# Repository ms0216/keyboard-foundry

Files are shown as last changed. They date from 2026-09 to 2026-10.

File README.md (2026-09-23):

# keyboard foundry

自作キーボードを**現物になる前に機械で確かめながら**作るための作業場。
KLE の配列 1 本から、プレート（STL）・キーマトリクスの基板（KiCad・JLCPCB の規則入り）・
ZMK のシールドを作り、それらが食い違わないことを検査する。

HHKB 分割機（`../2608042258_HHKB_devided`）の開発で積み上げた道具・検査・知識・作法を
抜き出したもの。**核の生成器は、HHKB の発注済みの基板を再現できる**
（キーまわりの全 140 部品の位置・向き・面・フットプリントと、全 244 パッドの結線が一致。
tests/test_regression_hhkb.py）。

## 構成

```
foundry/          共通の核（Python）
  layout.py         KLE → キーの実寸座標。島（分割の左右）に分ける
  matrix.py         キー → (row, col)。基板とファームが同じものを読む
  project.py        機種（projects/<機種>/spec.py + layout.json）を読む
  mech.py           MX・スタビ・ホットスワップの規格値
  plate.py          プレート（build123d）
  pcb.py            未配線の基板（KiCad の Python）。スイッチ・ダイオード・スタビ・穴・JLC 規則
  zmk.py            ZMK シールドの雛形と行列表
  fab_fields.py     発注道具（Fabrication Toolkit）が読む LCSC・面・除外を板に焼く
  drc.py            DRC を指紋つきで記録（警告を隠さない）
  render_pcb.py     基板を絵にする（変わっていなければ描かない・動いた部品を拡大）
  verify.py         寸法・水密・干渉（結果の記憶つき）・図
  inspect_mesh.py / slice_check.py   印刷できるか（近似と、OrcaSlicer で実際にスライス）
  gate.py           発注の門（open-gaps の「せき止めているもの」）
  parts.py          HHKB で確かめた部品と選定理由
  pinmap.py         ピン名 → パッド番号（データシートで裏付け）
  mutate.py         定数を壊して検査が気づくかを測る
  jlcpcb_lookup.py  JLCPCB の API（区分・在庫・単価）
firmware/ zephyr/ ZMK モジュール（乾電池の残量計・打ち止めで停止・状態 LED）
config/ build.yaml ZMK の設定（機種を作ると足される）
lib/              フットプリント（kiswitch の MX ホットスワップ・スタビ、XIAO）
projects/<機種>/  spec.py・layout.json・docs/（台帳）・pcb/
tests/            検査。fixtures/ に HHKB の配列と発注済みの基板から抜き出した事実
tools/kb          機種ごとの操作の入口 / tools/new_project.py
docs/method/      失敗から出た規則
docs/knowledge/   部品・電源・基板・筐体・ZMK・アンテナ・測り方
docs/templates/   台帳の雛形
.claude/          基板が変わったら絵を出して「見ろ」と言う hook
```

## 始め方

```sh
python3.13 -m venv .venv && .venv/bin/pip install -r requirements-dev.txt
.venv/bin/pytest tests -q                              # 全部緑であること

.venv/bin/python3 tools/new_project.py mykb path/to/kle.json
tools/kb mykb plate        # build/mykb/plate_*.stl / .png
tools/kb mykb pcb          # projects/mykb/pcb/unrouted/*.kicad_pcb（KiCad 10 が要る）
```

次にやることは CLAUDE.md の「新しい機種を始める」。

## 要るもの

| 道具 | 何に | 場所の指定 |
|---|---|---|
| Python 3.13 + requirements-dev.txt | 核・検査 | — |
| KiCad 10（同梱の Python と kicad-cli） | 基板の生成・DRC・絵 | `KICAD_PYTHON` `KICAD_CLI` `KICAD_FOOTPRINTS` |
| pdftoppm（poppler） | 基板の絵 | PATH |
| OrcaSlicer | スライスの確認 | `ORCA_SLICER` |
| GitHub Actions | ZMK のビルド（手元に SDK は要らない） | — |

## まだ核に入っていないもの（HHKB を参照実装として読む）

| もの | 理由 | HHKB の場所 |
|---|---|---|
| ケース・組み立て検査（留め方・挿入経路・干渉） | 機種の意匠そのもの。2 台目で共通部分を抜き出す | tools/gen_case.py・gen_assembly.py・envelopes.py |
| MCU 子基板・電源回路・回路図と ERC | 構成が機種ごとに違う（pcb_extra.py で足す） | tools/gen_daughterboard.py・circuit.py・gen_sch.py |
| 配線の仕上げ（GND ビア・手配線の再現） | 配線の品質は手作業から来ていた | tools/finalize_pcb.py・gnd_fanout.py・export_matrix_routing.py |
| .blend での確認 | ケースと一緒に | tools/export_assembly.py・blend_assembly.py |

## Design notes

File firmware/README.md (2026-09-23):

# ZMK モジュール（foundry）

リポジトリ自身が ZMK のモジュール（`zephyr/module.yml`）。ZMK 公式の再利用ワークフローが
`zephyr/module.yml` を見つけると自動で読み込む（別リポジトリは要らない）。

| 機能 | Kconfig | 使い方 |
|---|---|---|
| 乾電池の残量計 | `FOUNDRY_BATTERY_ALKALINE`（DT にノードがあれば自動で y） | シールドに `compatible = "foundry,battery-alkaline"` のノードを置き `chosen { zmk,battery = &vbatt; }` |
| 打ち止めで自分から止まる | `FOUNDRY_LOW_BATTERY_SOFT_OFF`（上と `ZMK_PM_SOFT_OFF` で自動） | `.conf` に `CONFIG_ZMK_PM_SOFT_OFF=y` |
| XIAO の RGB LED で状態表示 | `FOUNDRY_STATUS_LED`（既定 n） | `.conf` に `=y`。led0/1/2 のエイリアスが要る |

## 出どころ

HHKB 分割機（`../2608042258_HHKB_devided`・GitHub ms0216/hhkb-split）で書いて
CI でビルドしたもの。**foundry に移すにあたって名前だけ変えた**（`hhkb,` → `foundry,`・
`HHKB_` → `FOUNDRY_`）。**名前を変えてからはまだビルドしていない**——最初の機種の
シールドを build.yaml に足した push で CI がビルドする。そこまでは「未ビルド」。

ソースの注記にある `open-gaps #N`・`docs/hardware/…`・`tools/circuit.py`・`Task C4/C5`
は HHKB のリポジトリの記録を指す（経緯を消さないために残した）。

## 実機での確認状況（HHKB 時点）

- 残量計・打ち止め停止: CI でビルド成功・**実機での使い切り試験は未実施**（HHKB Task C4/C5）
- 状態 LED: CI でビルド成功・実機で点灯確認は利用者側の残タスク

## 乾電池 2 本・XIAO nRF52840 の場合のシールドの書き方（HHKB の実物）

```dts
/ {
	vbatt: vbatt {
		compatible = "foundry,battery-alkaline";
		io-channels = <&adc 0>;          /* D0/AIN0。分圧はスイッチの後ろ・ショットキーの手前 */
		output-ohms = <1000000>;
		full-ohms = <2000000>;
		empty-millivolts = <2400>;       /* 回路が動かなくなる電圧（機種ごとに計算する） */
		full-millivolts = <3300>;        /* 新品アルカリの開路電圧 1.65V × 2 */
		/delete-property/ power-gpios;   /* 板の vbatt と合体する。P0.14 を毎回叩いて 10ms 待っていた */
	};
	chosen { zmk,battery = &vbatt; };
};
```

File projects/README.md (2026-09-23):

# 機種

1 機種 1 ディレクトリ。`.venv/bin/python3 tools/new_project.py <名前> <KLE の JSON>` で作る。
中身は spec.py・layout.json・docs/（台帳）・pcb/。手順は CLAUDE.md「新しい機種を始める」。

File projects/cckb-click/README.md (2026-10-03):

# cckb-click

CCKB（HHKB 英語配列・62 キー・19.05 ピッチ・XIAO nRF52840）を、**薄い表面実装のタクトスイッチ**と
**枠の下から入れる軸の無いキーキャップ**で作り直す機種。目標の厚さは約 8.1 mm（CCKB は 14.2）。
方式は Salicylic_acid3 さんの ClickBoard（出どころと条件は [LICENSE](LICENSE)。**非営利に限る**）。

`projects/cckb/`（発注できる状態の CCKB）には手を入れない。だめなら CCKB に戻れる。

## いまの段: 基板・枠・キャップ・ファームまで設計した（独立した監査の前）

**いまの状態は [docs/status.md](docs/status.md)。**残っているものは [docs/open-gaps.md](docs/open-gaps.md) の冒頭。

```
tools/kb cckb-click pcb                                            # 未配線の板
"$KICAD_PYTHON" projects/cckb-click/tools/route_click.py           # 配線（Freerouting 2.3.0 と java が要る）
tools/kb cckb-click fab-fields && tools/kb cckb-click drc          # LCSC の番号・DRC
.venv/bin/python3 projects/cckb-click/click_case.py                # 枠・キャップの STL・断面図・.blend を build/cckb-click/ に
.venv/bin/python3 projects/cckb-click/tools/slice_main.py          # 刷る 4 枚をスライスして G-code を検査
.venv/bin/python3 projects/cckb-click/click_stiffness.py           # たわみの見積もり
.venv/bin/python3 projects/cckb-click/tools/parts_check.py         # 部品の在庫・単価（JLC の API）
.venv/bin/pytest tests/test_cckb_click.py tests/test_cckb_click_pcb.py tests/test_cckb_click_board.py tests/test_cckb_click_case.py -q
tools/kb cckb-click gate                                           # 発注の門（いまは閉）
```

| 読むもの | 何 |
|---|---|
| [docs/status.md](docs/status.md) | **いまの状態**・CCKB との比較・利用者が決めること |
| [docs/open-gaps.md](docs/open-gaps.md) | 発注を止めているもの・実物が来るまで分からないこと |
| [docs/decisions/](docs/decisions/) | 決定の記録（スイッチ・構造・刷り方・試し刷りの結果・基板と枠） |
| [docs/shopping-list.md](docs/shopping-list.md)・[docs/order-steps.md](docs/order-steps.md) | 買う物・基板の頼み方 |
| [docs/printing-guide.md](docs/printing-guide.md)・[docs/assembly-guide.md](docs/assembly-guide.md) | 刷り方・組み立て |
| [docs/coupon-test.md](docs/coupon-test.md) | 試し刷りの手順と結果（2026-10-03 に利用者が刷った） |
| print/ | 精度優先の刷り方のプリセット |
| [docs/provisional-values.md](docs/provisional-values.md) | まだ実測していない値（`[暫定]`） |
| spec.py | 寸法と部品。値ごとに出どころ |

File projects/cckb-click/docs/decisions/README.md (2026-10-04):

# 決定の記録

1 件 1 ファイル `YYYY-MM-DD-slug.md`。雛形は docs/templates/decision.md。
覆す前に読む。前提が動いたら読み直す。

| 日付 | 何 |
|---|---|
| 2026-10-03 | [スイッチは Alps SKRAAWE010](2026-10-03-switch.md) |
| 2026-10-03 | [構造: 積み上げ・キャップと枠の形・刷る向き](2026-10-03-structure.md) |
| 2026-10-03 | [ライセンス: 形は CC BY-NC 4.0・名前は借りない](2026-10-03-license.md) |
| 2026-10-03 | [刷り方: 精度を最優先にした設定・ノズル・最小の一式](2026-10-03-print-recipe.md) |
| 2026-10-03 | [試し刷りの結果: 案 B・穴 17.05・つばのキャップ・0.4 ノズル](2026-10-03-coupon-result.md) |
| 2026-10-03 | [基板と枠: 足跡・回路・留め方・枠の分け方・角・電池・底・たわみ](2026-10-03-board-and-case.md) |
| 2026-10-04 | [1 回目の監査の直し: 電池の位置・載せないコンデンサのランド・予備のねじ穴・ねじ穴を 0.1 外へ・戻りの道](2026-10-04-audit-1.md) |
| 2026-10-04 | [電源スイッチを内側へ・電池の蓋（差し込み式）・蓋のねじ穴を取っておく](2026-10-04-switch-cover.md)（**位置と蓋は、下の knob-out-pilot で置き換えた**） |
| 2026-10-04 | [試し刷り v2: ねじの下穴・電源スイッチの位置・蓋の留め方を刷って決め直す（何を試すことにしたか。結果は次の行）](2026-10-04-coupon-v2.md) |
| 2026-10-04 | [電源スイッチを 0.75 外へ（JLC の「2.5 mm」は満たさない）・下穴 φ1.6・蓋は考え直し](2026-10-04-knob-out-pilot.md)（**蓋は、下の cover-latch で決めた**） |
| 2026-10-04 | [電池の蓋は、基板の下から M2×4 のねじ 2 本で留める（基板は変えない）](2026-10-04-cover-screw.md)（**道具が要るので退けた。下の cover-latch で置き換えた**） |
| 2026-10-04 | [電池の蓋は、道具なしで上から落とし込む形にする（電池が押す向きと、外れる向きを分ける。基板は変えない）](2026-10-04-cover-latch.md) |

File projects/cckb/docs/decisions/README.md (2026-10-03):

# 決定の記録

1 件 1 ファイル `YYYY-MM-DD-slug.md`。雛形は docs/templates/decision.md。
覆す前に読む。前提が動いたら読み直す。

- 2026-09-23-choc-stabilizer.md — Choc スタビ（2u）の寸法は、製造図と Keebio の開口の 2 出典が一致した値を使う
- 2026-09-24-interface.md — 基板・プレート・ケースの境界を凍結する（角・ネジ・電源スイッチ・スタビの逃げ・継ぎ目・高さ）。電源スイッチの節は power-switch.md で置き換えた
- 2026-09-24-case.md — ケース・キーキャップ・試し刷りの小片を立体にする（ケースの段）。電源スイッチの切り欠き・窪みは power-switch.md で無くなった
- 2026-09-24-audit-fixes.md — 独立監査（A〜F）と 2 回目の監査の所見を発注前に基板・ケース・手順に入れる（裁定 R1〜R7・S1〜S3）
- 2026-09-24-power-switch.md — 電源スイッチを秋月の SS-12D00G3（表・レバーが上・右のふたの穴から爪で）に置き換えた
- 2026-09-25-choc-v2.md — Choc V2（静音）に替える枝 `cckb-v2`。核・プレート・基板・ケース・キャップ・スタビの穴（§10）
- 2026-09-26-plateless.md — スイッチのプレートを使わずに組む（`spec.PLATE = False`）。戻せるように形・コード・検査は残し、両方の形を毎回検査する
- 2026-09-28-keycap-skin.md — キャップの天板を場所ごとの厚さに（ステムの上は膜）。**2026-10-03 利用者の決定: 既定の膜 1.0・上面 14.2**（2026-09-28 の膜 0.6・13.8 は、見積りで縁を押すとつばの上の輪 0.2 が割れるので既定にしない）。coupon_skin で 0.8 が割れなければ 0.8（14.0）に下げてよい

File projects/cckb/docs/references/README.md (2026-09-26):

# 出典として保存したもの

| ファイル | 出所 | ライセンス |
|---|---|---|
| `kiswitch-SW_Kailh_Choc_V2.kicad_mod` | [kiswitch/kiswitch](https://github.com/kiswitch/kiswitch) `Switch_Keyboard_Kailh.pretty`（2026-09-25 取得・無改変。lib の `SW_Kailh_Choc_V2_Common` の元） | MIT ／ CC-BY-SA 4.0 |
| `Salicylic-Choc_v2_PCBMountStab_2u.kicad_mod`・`Salicylic-Stab_Hole_Choc_v2_PCBMount_2u.kicad_mod` | [Salicylic-acid3/KiCAD_FootPrint](https://github.com/Salicylic-acid3/KiCAD_FootPrint) commit 9ade20b（2026-09-25 取得・無改変。V2 のスタビの基板の穴とプレートの開口の出典の 1 つ） | MIT（Copyright 2020 Salicylic_acid3） |
| `Kailh-PG1350-Stab-Cutout.kicad_mod` | [keebio/Keebio-Parts.pretty](https://github.com/keebio/Keebio-Parts.pretty)（2026-09-23 取得・無改変） | MIT（Copyright Keebio） |

Kailh 系の Choc スタビの製造図（AliExpress の商品画像）は、再配布してよいか分からないため
ここには置かない。URL と読んだ値は `../decisions/2026-09-23-choc-stabilizer.md` にある。

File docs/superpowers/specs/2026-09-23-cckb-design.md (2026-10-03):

# CCKB（Completely Compact KeyBoard）設計書

2026-09-23 利用者と合意。**HHKB 英語配列に準拠し、出張先や会議室へ持ち運ぶための、薄く軽い一体型キーボード。**
HHKB（Professional HYBRID Type-S・294×120×40mm・540g）は机に据えて使い、CCKB は鞄に入れて持ち出す。
使うのは出張・会議のときだけ（毎日一日中ではない）。印刷は Bambu Lab A1 mini（D12）。

完了とは**発注できる状態**（下の §9）。発注・印刷・購入は利用者が判断する。

---

## 1. 要求

### 守るもの（検査にする。設計の都合で崩すと検査が落ちる）

| 項目 | 値 | 照合する外の事実 |
|---|---|---|
| キー配置 | HHKB 英語配列の全キーの中心位置（スペースを除く） | `../2608042258_HHKB_devided/layout/hhkb_original.json`（QMK と Wikimedia の KLE 図で裏付け済み。60 キー） |
| キーピッチ | 19.05mm | HHKB 公称 |
| 行ずれ | HHKB と同一 | 同上 |
| 最下段の空き | 左 1.5u・右 2.5u（左右非対称。KLE で確認） | 同上 |
| スペースの範囲 | 4.0〜10.0u を 3 キーで隙間なく覆う | 同上 |

### 妥協したもの（受け入れた差）

| 差 | 理由 |
|---|---|
| スペース 6u → **2.25u＋1.5u＋2.25u**。既定は 3 つともスペース、真ん中は後でキーマップで変えられる | 低背の 6u キャップ・スタビがどの系列にも無い（調査 2026-09-23）。キーキャップは自分で刷る（D14）。真ん中と右の境（7.75u）は右の親指の位置（N の下）に当たるので、まず全部スペースで使って癖を見る |
| 段ごとのキー高さ・打鍵面の傾き 7.3° を再現しない | 低背スイッチでは作れない。ほぼ平ら |
| 静電容量無接点 → Kailh Choc V1 | 薄さ |
| 単3×2 → CR1632 | 薄さ・軽さ。LiPo は利用者が不採用（発火・劣化） |
| ゴム足なし | 利用者の決定（コンパクト性）。代わりに底面と面一の滑り止め |

### 目標（検査で数値を出して報告する。上限を決めるのは利用者）

- 外形 約 292×100mm・厚さ 約 12mm（キーキャップ上面まで）
- 重さ 約 300〜430g（スイッチ・キャップの単重が未公表。部品が届いたら量る）

---

## 2. 決定と根拠

| # | 決めたこと | 根拠（外の事実） | 退けた案 |
|---|---|---|---|
| D1 | **一体型** | 分割の親側をボタン電池で動かすと、内部抵抗が 25Ω を超えたところで起動に 2.6〜2.7V が要る領域（HHKB task-c4-c5 ② 実測）に入り、復帰が確率的になる。CR2450 では容量の約 4 割（Energizer データシートの IR 曲線）。片側不在で 3.7mA（HHKB task-c3 §5-4 実測） | 分割＋合体（+20〜25g・親側の電池 約 6 ヶ月）。**この結論は「親側が走査し続ける ZMK の仕様」と「起動電圧の実測」に乗っている。どちらかが変われば読み直す** |
| D2 | **Kailh Choc V2（PG1353・静音 PG1353S も同じ足跡）・19.05mm ピッチ**（`cckb-v2` の枝。main は V1 のまま） | 利用者が会議・出張用に静音を買う見込みで、静音は V2 にしか無い。十字の軸で自作キーキャップの嵌め合いが作りやすい。決め方と差は decisions/2026-09-25-choc-v2.md（全高 8.6・プレート 1.2・位置決めは丸 φ2.1・スタビは基板にねじ留め） | Choc V1（main の枝）・Gateron KS-33。V1（PG1350）は全高 8.0 で薄いが静音が無い |
| D3 | **スイッチを直接はんだ付け** | どのみち手はんだ（Choc ソケットは JLCPCB・LCSC とも在庫 0、2026-09-23 API。持ち込み実装は $85＋通関＋送料）。直接なら 約 1.2mm 薄く・約 9g 軽く、ソケットの −10℃・2V・100 回の制約が消え、プレート・スイッチ・基板が一体になる | ホットスワップ（差額は部品代 約 ¥1,300） |
| D4 | **CR1632 を 1 個**（**発注前の起動試験 §10a に合格することが条件**） | φ16.0×3.2mm・1.8g・130mAh（Energizer データシート）。ホルダごと右の角（47.6×19.05mm）に前後 1.5mm ずつ余って収まり、手前の縁に制約を作らない。入手性は CR2032 と同等（ダイソー公式の商品ページに CR1632。コンビニ各社も扱う。二次情報）。使える時間は保守側（0.20mA）で 約 480 時間＝週 7.5 時間なら 約 1.2 年 | CR2450（手前に 5.45mm はみ出し 奥行 +5.8mm）、CR2032（はみ出し 0.95mm 奥行 +1.3mm・設計の制約が 1 つ増える）、2 個並列（どちらの在庫品ホルダも角の横幅に 2 個並ばない：1632 用 28.7×2、2032 用 25.1×2 > 47.6）。**CR1632 の内部抵抗は新品で約 25Ω（CR2032 は約 10Ω）なので起動の余裕を測ってから確定する。不合格なら CR2032 に戻す** |
| D5 | **XIAO nRF52840 ＋ 74LVC595 ×2** | HHKB で実機確認済みの構成。技適 211-220207 | — |
| D6 | **XIAO（左）と電池（右）は最下段の空いた角の表側に置く。電池は角の上面をまるごと 1 枚にしたふたから替える** | 角にはキーが無いので高さを使える。電池ホルダ（高さ 5.4mm 級）を基板の裏に付けると、裏の空き（約 1.5mm）を超えて本体が厚くなる。ゴム足が無いので出っ張りを隠せない。ふたの縁はキーキャップとの隙間とケース外周の角に重ね、新しい線を増やさない | 裏ぶた（厚くなる）、角の上面の小窓（継ぎ目が増える） |
| D7 | 名前 **CCKB**（シールド名 `cckb`） | 利用者の命名（Completely Compact KeyBoard）。HHKB へのリスペクト。他社の商標は刷らない | tabi |
| D8 | **JLCPCB の実装は裏の片面だけ。表側（XIAO・電池ホルダ）は利用者が手はんだ**。**電源スイッチも手はんだ**（2026-09-24 の監査で裏の MK-12C02-G025 を手はんだにした〔つまみが外形から出るので JLC の規則に合わない・audit-fixes.md §R2〕。同日、表のスルーホールの **SS-12D00G3**〔秋月・LCSC に無い〕に置き換え・projects/cckb/docs/decisions/2026-09-24-power-switch.md） | 両面実装は工程が 2 回で追加の段取り費。ホルダは 2 端子・大きいパッドで手はんだが容易 | 両面実装 |
| D9 | **電源スイッチはふたを開けずに爪で操作**（当時は側面から。2026-09-24 に利用者の決定で、表の右の角の SS-12D00G3 を右のふたの穴から爪で動かす形に置き換え・decisions/2026-09-24-power-switch.md） | 出張先で毎回切る。ふたを開けずに爪で動かせること | 側面から（前の MK-12C02-G025） |
| D10 | **底面は面一の滑り止め**（浅いくぼみに薄いシートを貼り、四隅の 4 点で当てる） | ゴム足なしで、滑り・傷・がたつきを防ぐ。厚さ 0 | 何も付けない |
| D11 | ~~**プレートは PLA 1.2mm を自分で刷る**~~ → **2026-09-26（`cckb-v2`）: プレートを使わない**（`spec.PLATE = False`・戻せるように形とコードと検査は残す） | **2026-09-26 の決定**: プレートが要ったのは V1 のスタビがプレート留めだったから。V2 のねじ留めのスタビ（遊舎工房 A050001-01-1）は基板に留まり、販売者は「構造的にスイッチプレートレスでも使用できます」。外すと約 19g・刷る時間 2h28m 減り、スペースの欠け・別に刷る枠・O15 が消える。打鍵感・傾きは未評価（open-gaps P16）・ナットの回り止めが無くなる（P15）。決定記録 projects/cckb/docs/decisions/2026-09-26-plateless.md。**以下は 2026-09-23 の理由**: 利用者の決定（直しやすさ・軽さ）。比重が FR4 の約 2/3 で約 13g 軽い見込み（計算）。厚さは層（0.2mm×6）で決まり揃いやすい。HHKB 分割機も PLA のプレートでスタビの開口を実測で決めた（HHKB #30）。スイッチを基板にはんだ付けするので、プレートは 62 か所で基板に留まる | FR4（JLCPCB。厚さ ±10%） |
| D12 | **印刷は A1 mini。印刷する部品はすべて平面で 168.4mm 角以内** | 利用者の決定。A1 mini は 180×180mm、スライサーの自動配置（CLI・検査で使う）の実効が約 168.4mm 角（HHKB の実測 2026-08-23）。手で端に置けば 177.6mm まで刷れた（同 08-24）が、検査で確かめられる側に揃える | 手置き前提の 177.6mm |
| D13 | **基板（1 枚）を背骨にし、印刷部品は分割してそれぞれ基板に留める** | 本体は約 288mm で A1 mini に入らない。基板は JLCPCB で 1 枚で作れる。プレートはキーの境目（スイッチ・スタビの穴を切らない所）で 2 つに分け、はんだ付けしたスイッチで基板に留まる（**2026-09-26 からプレートは使わない・D11**）。ケースは分割した部品をそれぞれ基板に留め、部品どうしの継ぎ目に力をかけない。**継ぎ目の位置は計画 2 で図を描いて利用者と決める** | 部品どうしを接着・嵌合で繋ぐ |
| D14 | **キーキャップは自分で刷る** | 利用者の決定。約 1mm 薄くできる見込み（未測定）。スタビの軸（Kailh の製造図で支点の間隔 24.0mm）を必ず設計に入れられる | Chosfox CFX（約 3.8mm・スタビ適合は二次情報 1 件のみ） |

---

## 3. 部品

| 部品 | 品番 | 数 | 入手・付け方 |
|---|---|---|---|
| スイッチ | Kailh Choc V2 PG1353（静音 PG1353S を買う見込み。軸色は利用者が選ぶ） | 62 | 共立電子（シリコンハウス）か遊舎工房・手はんだ |
| キーキャップ | 自分で刷る（無刻印。2.25u はスタビの軸を ±12.0mm に持つ） | 下 | 利用者が印刷（Choc の軸の嵌め合いは試し刷りで合わせる） |
| スタビライザー | Choc V2 用 2U スクリュータイプ（遊舎工房 A050001-01-1・基板にねじ留め）。2026-09-26 に利用者がこれに決めた（プレート留めの品には替えない。決定記録 2026-09-25-choc-v2 §10-9）。プレートに掛からないので、プレートを使わない（D11） | 4（Enter・左 Shift・スペース左右） | 遊舎工房 |
| マイコン | Seeed XIAO nRF52840 | 1 | 手はんだ（表側・左の角） |
| 電池 | CR1632 | 1 | コンビニ・100 円ショップ |
| 電池ホルダ | **BS-16-B4AK003**（MYOUNG） | 1 | 手はんだ（表側・右の角）。国内 eleshop ¥220／JLCPCB C964732（在庫 1,688・09-23）で同じ品番。寸法は図面 MY-CP-0085（全長 27・幅 16・高さ 5.5・ランド外外 28）。決定記録 2026-09-24 |
| JLCPCB 実装（裏の片面） | BAT46W（C54110）×62＋電源のショットキー 1（既定 BAT46W C54110・2026-09-24 の 2 回目の監査で B5819W から替えた。利用者が発注前に決める）・SN74LVC595APWR（C52287685）×2・分圧 1MΩ×2・パスコン | | 発注直前に `tools/kb cckb parts` で在庫を取り直す |
| 電源スイッチ | **SS-12D00G3**（秋月 115707。2026-09-24 に MK-12C02-G025 から置き換え・decisions/2026-09-24-power-switch.md） | 1 | 利用者が秋月で買って表面（レバーが上）に手はんだ |
| プレート | **2026-09-26 から使わない（D11）**。戻すなら PLA 1.2mm（静音 V2 の爪の隙 1.35 に入る厚さ。V1 の枝では Choc スタビが 1.2mm を要求）・2 枚＋スペースの枠 2 | 0（戻すなら 2＋枠 2） | 戻すなら利用者が印刷（D11・D13） |
| ケース | PLA（熱に強い樹脂にするかは計画 2 で比べる） | トレイ 2（継ぎ目 案 C）・角のふた 2。どれも 168.4mm 角以内（2026-09-24） | 利用者が A1 mini で印刷（D12・D13） |
| ネジ・ナット・インサート | M2×6 皿（DIN 965・頭 φ3.8）11・M2 六角ナット（ISO 4032）9・M2 熱圧入インサート（外径 3.2・長さ 3.0）2 | | 利用者が買う（decisions/2026-09-24-case.md） |
| 滑り止め | 薄いシリコンシート。厚さ 0.5（[暫定]）・16×8 を 4 枚（くぼみ 0.4。2026-09-24 に 16×10 から・`case_spec.ANTISLIP_PAD`） | 4 | 貼る |

キャップの内訳（62 キー）: 1u ×51・1.5u ×4（Tab・Del・Meta×2）＋スペース中央 1・1.75u ×2（Ctrl・右 Shift）・2.25u ×2（Enter・左 Shift）＋スペース左右 2。

---

## 4. 回路

```
CR1632 → 電源スイッチ → [分圧 1MΩ+1MΩ → XIAO の ADC] → ショットキー D_PWR（既定 BAT46W）→ XIAO 3V3
                                                             （BAT 端子には繋がない）
行 5 本 ── XIAO 直結（入力・プルダウン）
列 15 本 ── 74LVC595 ×2（SPI: SCK=D8・MOSI=D10・CS=D7。D9 は MISO に確保）
キーごとに BAT46W（col2row）
```

- GPIO は 11 本中 9 本（行 5・SPI 3・ADC 1）
- 行列は 5×15。キーの割り当ては `foundry/matrix.py`（physical）を初期値にする
- 電源スイッチは必須（鞄の中でキーが押されて起きるのを止める）
- ショットキーは USB 給電中に一次電池を充電しないため（Energizer: 逆充電は 1µA まで）。
  B5819W は低い逆電圧の逆漏れに保証が無く、USB を挿したままスイッチ ON だと電池へ数 µA が向かいうる（監査 A-1）。
  ~~替えられる品が無い~~（1 回目の比べ方は誤り）→ **既定を BAT46W に替えた**: 25℃ では逆漏れの保証値 0.3µA が分圧の吸う
  0.93µA より小さく電池へ入らない（決定記録 2026-09-24-audit-fixes §S2・open-gaps O12）。高温では保証が無いので
  「**USB を挿す前に電源スイッチを OFF**」は残す
- 直付けなのでソケットの「2V 以上」の制約は無い。打ち止めはマイコンの下限（レール 1.8V）と起動の実測で決める

## 5. 機構

> **2026-09-24 に境界を決めた（projects/cckb/docs/decisions/2026-09-24-interface.md）。**
> 下の「上枠」は**トレイ（底＋外壁）＋角のふた**に変えた（上枠の前後の辺を基板に留める場所が無い。
> 2026-09-24 に利用者がこのままと決めた・open-gaps O8）。基板は 1.6mm（O3）、取付 10（O4）、電源スイッチ SS-12D00G3（表・右の角・ふたの穴から爪で操作。
> 2026-09-24 に MK-12C02-G025 から置き換え・decisions/2026-09-24-power-switch.md）。
> 高さ・外形の数値は決定記録の §2-5 と spec.py が正本。

### 積み重ね（下から）

1. 底板（PLA）。四隅に面一の滑り止め
2. 基板（**1.2 か 1.6mm。§8 の検査で決める**。全体の背骨なので 1.6mm が有力）。裏の部品とスイッチの足で下に約 1.5mm
3. ~~プレート（PLA 1.2mm・2 分割）。基板上面からプレート上面まで 2.2mm（Choc 規格）~~ **2026-09-26（`cckb-v2`）: プレートは使わない**（D11）。
   スイッチは基板の穴（中心の突起・位置決めの突起）とはんだだけで立つ。戻すなら基板上面からプレート上面まで 2.2mm
4. スイッチ・キーキャップ

**高さ（机から・`interface.z()`。2026-10-03）**: 床 1.2 ＋ 基板の下の空き 1.8 ＋ 基板 1.6（上面 4.6）＋ Choc V2 のステム 8.6（13.2）
＋ キャップの膜 1.0 = **14.2**。V2 にして 14.4（天板 1.2）になったのを、キャップの天板を場所ごとの厚さにして
ステムの上を膜にした（2026-09-28 は膜 0.6 = 13.8。見積りでつばの上の輪 0.2 が縁の押しに割れるので、**2026-10-03 利用者の決定で既定を膜 1.0**。
projects/cckb/docs/decisions/2026-09-28-keycap-skin.md §8。試し刷り `coupon_skin` で 0.8 が割れなければ 14.0 に下げてよい・open-gaps P17）。
縁（トレイの壁・角のふたの上面）は 11.6、押し切ったキャップの上面は 11.15

~~**プレート・スイッチ・基板ははんだで一体になる。**これを上枠と底板で挟む。~~ **スイッチ・スタビ・基板がはんだとねじで一体になる。**
これをトレイ（底＋外壁）に上から落とし、下からのネジで基板の上面のナットへ留める（上枠と底板は 2026-09-24 にトレイ＋角のふたへ変えた）。

### 角（この設計の中心）

| | 左の角 | 右の角 |
|---|---|---|
| 大きさ（最下段の空き） | 1.5u×1u ＝ 28.6×19.05mm | 2.5u×1u ＝ 47.6×19.05mm |
| 置くもの（基板の表側） | XIAO（21×17.8mm）。USB-C は左側面へ | CR1632 とホルダ |
| 上面 | 上枠と同じ平らな面 | 角の上面をまるごと 1 枚のふた（ネジ 1 本か、落ちない爪） |

- 電源スイッチは側面（位置は作図で決める）
- 上枠は角を覆うので、プレートと基板の一体物は**下から入れる**（上枠 → 一体物 → 底板の順にネジで留める）
- XIAO のアンテナは USB と反対の端（内側を向く）。アンテナ直下の銅を抜く（docs/knowledge/rf-antenna.md）

## 6. ファーム（ZMK）

- シールド `cckb`・ボード `xiao_ble//zmk`・CI で .uf2 を作る
- キーマップ: HHKB の既定（ベース面・Fn 面）。スペース 3 つとも `&kp SPACE`。`&bootloader`・`&bt BT_CLR` を置く
- 電池残量: `firmware/` の残量計（foundry,battery-alkaline）をそのまま使う。中身は電圧の窓を % にする線形の写像で化学に依らないので、窓を CR1632 の値にするだけ
- 打ち止め: §10a の起動試験の結果から決める（`low_battery_off`）
- 設定は HHKB の定石（docs/knowledge/zmk-and-xiao.md）: スリープ 30 分・Apple §58.6 適合の接続間隔など

## 7. 核（foundry/）の改修

いまの核は MX 専用（mech.py の開口 14.0・SWITCH_FP・Cherry スタビ・pcb.py の Value "CPG151101S11-2"・DIODE_OFFSET）。

- spec.py に **`SWITCH = "mx_hotswap" | "choc_v1"`** を足し、スイッチの種類ごとの規格値（開口・フットプリント・スタビの形と間隔・ダイオード位置・部品番号）を mech.py の表にまとめる
- 既定値で埋めない（`REQUIRED` に入れる）。HHKB の fixture spec には `"mx_hotswap"` を書く
- Choc の直付けフットプリントは kiswitch（perigoso）の上流から取り、**端子の位置と向きを Kailh の図面 CPG135001D01 と突き合わせる検査**（kiswitch と Keebio は KiCad 座標で (0, −5.9)・(5, −3.8)、中心穴 φ3.45、ボス φ1.9 を ±5.5）を置く
- **HHKB の再現検査（tests/test_regression_hhkb.py）を通す**
- 生成器は寸法を持たない（寸法は spec.py と mech.py）

## 8. 決まっていないこと（作図・計算で決める。決まったら §2 に移す）

> **O1〜O6 は 2026-09-24 までに全部決着した**（projects/cckb/docs/open-gaps.md の「まだ決めていない判断」・決定記録 2026-09-24-interface.md）。下の表は当時の物。

| # | 何 | 決め方 | 変わったら利用者に相談する条件 |
|---|---|---|---|
| O1 | BS-16-B4AK003 の寸法と、右の角の断面（ホルダ＋電池＋ふた＋出し入れの経路） | データシートを取り直し、平面図と断面図を描く | ふたを付けると厚さが増えるとき |
| O2 | Choc スタビがプレートの下にどれだけ出るか（支点の間隔 24.0mm と開口の輪郭は、製造図と Keebio の 2 出典で確定） | 製造図を読み込み、組み立てモデルに入れる。部品が届いたら試し刷りの小片にはめて押す | 基板の下の空き 1.5mm を超えるとき（その場合はスタビの真下だけ底に穴。厚さは変えない） |
| O3 | 基板の厚さ 1.2 / 1.6mm | 打鍵荷重でのたわみを、ネジ位置を入れて見積もる | — |
| O4 | ネジの位置と数 | 5 条件（縁・開口・部品・コートヤード・配線）を同時に満たす | — |
| O5 | XIAO の USB-C に市販のケーブルが届くか・電源スイッチの位置 | 組み立てモデルにケーブルと指の届く範囲を入れて検査する | — |
| O6 | 滑り止めのくぼみの深さと、底板の残りの肉厚 | 断面図 | 底板が 1.2mm を割るとき |

## 9. 完了条件（発注できる状態）

1. **§10a の起動試験に合格**（不合格なら D4 を CR2032 に替えて作図をやり直す）
2. 基板の発注データ: 配線済み・**DRC の違反と警告を全部数えて記録**・LCSC 番号・実装面（裏のみ）・CPL（Fabrication Toolkit に通して出力を読む）
3. ケース（トレイ＋角のふた。当時は上枠・角のふた・底板）・キーキャップの STL（プレートは 2026-09-26 から使わない・D11）を **OrcaSlicer の A1 mini 設定で実際にスライス**したもの（`tools/kb cckb slice --printer a1mini`）
4. ファームの .uf2（GitHub Actions でビルド成功。実機は未確認と明記）
5. 利用者が買う部品の一覧（型番・店・数・概算）
6. 組み立て手順書（2026-09-26 からプレート無し: スタビ → スイッチを 1 個ずつ「足 1 本 → 平らか見る → 2 本目」。プレートを戻すときの順も書く）
7. 試作の試験手順（§10b）
8. `tools/kb cckb gate` が通る。`.venv/bin/pytest tests -q` が全部緑（KiCad の要る検査も `REQUIRE_KICAD=1` で）

## 10. 実機で測ること

### 10a. 発注前（基板の発注をせき止める）: CR1632 で起動できるか

> **2026-09-25 に置き換えた**（下の取り消し線が当初の案）: 分からないのは XIAO＋ZMK の起動に要る電圧なので、
> **可変電源＋直列抵抗（0〜100Ω）で V_boot(R) を直接測り**、電池（電圧と内部抵抗・温度）とダイオード（Vf の保証値）は
> データシートで紙の上に載せる。新品の CR1632 で 1 回だけ突き合わせる。冷蔵・ダイオード 2 種の実測はやめた。
> 手順と合否は projects/cckb/docs/task-10a-coin-cell-startup.md。

~~HHKB の試作で使った XIAO・CR1632（ダイソー 2 個 110 円）・抵抗で、ブレッドボードで測る。手順書にする。~~

- ~~一体型用のファーム（CI でビルド）を焼く~~
- ~~電池に直列抵抗 0・25・50・75Ω を入れ、末期と低温を模擬する~~
- ~~常温と、冷蔵庫で 2h 冷やした電池で、スリープからの復帰を各 10 回~~
- ~~合否の基準は手順書で先に決める（HHKB の「起動の限界」の測り方に倣う）~~

### 10b. 発注後（試作）

- 平均電流（接続中・打鍵中・スリープ）→ 電池寿命の見積もりを実測で置き換える
- 全キーの疎通とゴースト（同時押し）
- RSSI（XIAO 単体と組み込み後の差。docs/knowledge/rf-antenna.md の手順）
- 重さ・寸法を量り §1 の目標と比べる

## 11. 検査の計画（作るもの）

| 検査 | 見るもの | 故意に壊して落ちることを確かめる |
|---|---|---|
| 配列の不変条件 | 全キー中心が HHKB の KLE と一致（スペースは範囲を覆う）・ピッチ・最下段の空き | キーを 1 つずらす |
| Choc の規格 | フットプリントの端子・穴がデータシートと一致・プレート開口 13.8 | 値を 0.1 ずらす |
| 行列とファーム | 基板のネットとシールドの行列表が、**物理位置**と一致 | 2 キー入れ替える |
| 結線 | 宣言 → パッド → ネットを端から端まで。ネットの無いパッド 0 | 1 本外す |
| 実装面 | JLCPCB に出す部品がすべて裏面、表側は XIAO・ホルダ・電源スイッチ（手はんだ）だけ | 1 個を表に置く |
| 組み立て | 全部品（ケーブル・電池を含む）の干渉 0・電池をふたから入れて出せる・USB が挿さる・電源スイッチに指が届く・ネジにドライバーが届く | 電池を 1mm 大きくする |
| 印刷 | 肉厚 ≧1.2・水密・**全部品が平面で 168.4mm 角以内**・A1 mini 設定でスライス成功 | 壁を 0.8 にする・部品を 170mm にする |
| 発注の門 | open-gaps の「せき止めているもの」が 0 | 行を 1 つ足す |

## 12. 配線の方針

- キーの行列は**道具が決まった形で引く**（行＝裏面の横、列＝表面の縦。スイッチ → ダイオードの L 字）。道具は写すだけにし、配線を加工する判定を書かない
- XIAO・595・電源まわりは Freerouting 2.3.0（手元に jar あり。**Java（OpenJDK）を Homebrew で入れる**）
- 2 層・両面 GND ベタ。塗った後の面積で健全性を見る。アンテナ直下の禁止域は塗られた後のベタで確かめる
- DRC 0 は配線が良いことを意味しない。層ごとの長さ・ビア数・GND の島・遠回りの比を数字で出し、絵で見る

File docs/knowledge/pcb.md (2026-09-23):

# 基板（KiCad 10・JLCPCB）

foundry が自動でやるのは**キーマトリクスの未配線の板まで**（`tools/kb <機種> pcb`）。
そこから先（MCU・電源・配線・GND・発注）は機種ごとに違うので、HHKB の手順と罠を
ここに残す。参照実装は HHKB の `tools/{gen_pcb,finalize_pcb,gnd_fanout,autoroute,
gen_daughterboard,export_matrix_routing}.py` と `docs/hardware/pcb-routing-handover.md`。

## 流れ

```
spec.py + layout.json
   └ tools/kb x pcb          → projects/x/pcb/unrouted/x_<部品>.kicad_pcb（キー・ダイオード・スタビ・穴・規則）
       └ pcb_extra.py の place()  で MCU・コネクタ・電源を足す
   └ KiCad で配線（HHKB は最終的に手で引いた。自動配線は下の注意）
   └ 配線した板を projects/x/pcb/x_<部品>.kicad_pcb に置く（ここからは板が正本）
   └ GND のビア（fanout → fence → ring → stitch → islands の順）
   └ tools/kb x fab-fields   → LCSC・面・BOM 除外を焼く
   └ tools/kb x drc          → 記録（指紋つき）。警告も数える
   └ tools/kb x render       → **絵を見る**（hook が毎回出す）
   └ fab-checklist.md を上から
```

## 規則（foundry が板と .kicad_pro の両方に書く）

- **KiCad 既定の規則で DRC 0 でも JLC で作れるとは限らない。**線幅・間隔 0.127、
  ビア φ0.45/0.2 以上、アニュラ 0.13、穴間 0.45、外形まで 0.3、シルク 0.15
- **kicad-cli の DRC は隣の `.kicad_pro` から規則を読む。**板だけを別の場所で回すと
  別物に見える。規則を直したらプロジェクトファイルも同期する（pcb.py がやる）
- 自動配線器はネットクラスしか見ない。実際に引く寸法（0.2 / ビア 0.6/0.3）を明示する。
  **ネットクラスは Recompute しないと割り当てが効かない**
- 電源の太さ: 0.5mm ピッチの FFC はパッド幅 0.30・隙間 0.20。0.3mm の線は**隣のパッドの間を
  抜けられない**（パッドの幅と隙間を取り違えた）→ 0.2
- ビア φ0.5/0.3 はアニュラ 0.10 で規則割れ → φ0.6/0.3
- **NPTH の縁から外形まで 1.0mm 以上**（pcb.py が生成時に止める）。スペースのスタビを
  素の向きで置くと 0.381mm（外形公差 ±0.2 で 0.18mm の橋）→ ワイヤ奥（180°）で 2.14mm
- Kailh ホットスワップは内部の穴間が 0.4398（JLC 0.45）。キーの数だけ `hole_to_hole` 警告が出る。
  部品の寸法なので直せず、**穴は残す**（5 ピン用を 3 ピン用にはできるが逆はできない）。
  JLC は製造前に連絡してくる（HHKB #50）
- シルク最小 0.15（KiCad 標準 0.12 はかすれる）。**全部品を置いてから太らせる**。
  生成器が 2 本あると片方だけ直りがち
- 他社の商標を板に刷らない（HHKB は "SSKB"）。左右・機種の識別は必ず刷る

## 層と GND

- **層は実際の配線を数えてから決める。**HHKB は 4 層で始め、信号が 2 層に収まっていた
  （決定記録が実態に追いつかず、根拠として残った）→ 2 層・両面 GND ベタ
- 部品は片面（裏）に集める。JLC の片面実装は安く、Economic PCBA は片面限定
- GND ベタは**配線を載せたあとに塗り直す**（`ZONE_FILLER.Fill`）。「足した」と「塗られた」は別
- 健全性は**面積**で見る。KiCad は切り離された島を黙って消すので、多角形の数は 1 のまま
  面積だけ半分になる。浮いた GND の銅は 2.4GHz でアンテナになりうる → 繋ぐか消すかで 0 にする
- ビアの順: **fanout（全 GND パッド）→ fence（長い配線の脇・最も効く）→ ring（禁止域の縁）
  → stitch（格子）→ islands（離島を繋ぎ戻す）**。格子を先に打つとフェンスの場所を取られる
- SMD の GND パッドは**同じ層のスタブ→ビア**で繋ぐ。ベタが偶然被っているだけの接続に頼らない
- アンテナの下は [rf-antenna.md](rf-antenna.md)
- 取付穴は GND に繋がない（樹脂ケースでは意味が無い）

## 配置

- 部品は**段と段の間の帯**（9.25mm × 全幅）に置く。帯の中心はソケットの占有が非対称
  （−2.6〜+7.2mm）なぶんずらす
- 部品は原点ではなく**コートヤードの中心**で帯に合わせる（FFC は原点が 0.95mm ずれていた）
- 取付穴は **5 条件を同時に**: 縁から 1.0 以上・キーとプレート開口・部品・コートヤード・配線
  （別々に確かめて 3 往復した）。穴の目的関数に後で引く配線を入れる
- 名札（リファレンス）はキーの枠を避ける向きに回す（消さない）
- 板のテキスト（キー名）は部品を動かしても付いてこない
- 裏面にコネクタを置くとピンの並びが鏡像になる。**コネクタは面だけでなく口の向きと
  口から口までの経路を追う**（口の向きが `Flip()` の副作用で誰も決めないまま決まっていた）
- ケースの幅を変えると、内壁基準で置いたコネクタが動いて凍結した配線が切れる（9 ネット）

## 配線

- 決まりきった局所配線（スイッチ→ダイオードの L 字、行のバス）は自分で引いてよい。
  それ以外を手書きのルータでやらない（衝突判定が無く任意のネットを短絡させた）
- Freerouting（2.3.0・`-de dsn -do ses -mp N`・OpenJDK）: 決めた配線は `(type protect)` で渡す。
  **効くのは via_costs**（0 は逆効果・2 が良かった）。`autoroute_settings` を DSN に書くと
  壊れる。クリアランスの余裕 20µm（15 は丸めで違反・25 は未配線）。ログの違反数ではなく
  KiCad の DRC で判定。SES 取り込みは既存の配線を消す
- HHKB の最終形は**利用者が KiCad で手で引いたものを JSON に写して再現する**方式
  （`export_matrix_routing.py`）。**配線を加工する判定を書くと壊れる**——KiCad は端点どうしの
  接触しか数えないが、電気は線の途中でも繋がる。道具は写すだけにする
- CCKB（2026-09-24）で分かったこと（`projects/cckb/tools/route_pcb.py`・`docs/pcb-routing-handover.md`）:
  - Freerouting 2.3.0 は **`(autoroute_settings)` があるとネットを 1 本も見ない**ことがある（HHKB の子基板と
    CCKB の本体の 2 回）。ログの「0 unrouted items」「no SMD pins」が合図
  - 自分で引いた線を `fix` で渡しても接続と見ない。**線は protect、ネットは「駆動側」と「最寄りのパッド」
    の 2 ピンに絞る**と、最後の 1 本だけを引かせられる
  - DSN からパッドを消すと、そこを線が通る（短絡）。消すなら禁止域で覆う
  - 外形・切り抜きはネットクラスの間隔でしか避けない（JLC の 0.3 を割る）→ 縁に配線禁止の帯
  - 同じ入力なら同じ結果だが、小さな変化で未配線が 0 ↔ 2 に揺れる → 余裕を決まった順に試して記録
  - **KiCad 10 は読み込み時に線のネットを繋がりから付け直す**。「ネット名を書き換えて DRC が気づくか」
    という壊し方は効かない（線を太らせる・動かす）
  - ビアを置く自前の判定は、**穴の中（切り抜きの真ん中）・長いスタブ・同じネットのビアどうしの穴間**を
    落としやすい（3 つとも踏んだ）。外形は多角形の内外で、穴間はネットに関係なく見る
- **DRC 0 は配線が良いことを意味しない。**層ごとの本数と長さ・ビア数・GND の島・遠回りの比
  （> 3 に注意）を数字で出し、絵で見る

## 回路図と結線

- 順序は **回路図 → ERC → アートワーク → DRC**。そのうえで回路図と板の netlist を突き合わせる
- **ピン名とパッド番号は別物**（foundry/pinmap.py）。引けなければ落とす。握り潰すと
  ネットの無いパッドが DRC 0・未配線 0 のまま残る（HHKB で 595 が丸ごと消えていた）
- 回路図は宣言（データ）から生成し、電気的種別を付ける（無いと ERC は飾り）。
  kiutils 1.4.8 の書く回路図は KiCad 10 で読めない
- テストポイントは部品を足さず、既存ビアのテンティングを外すか配線上にマスクの窓を開ける。
  部品本体からこて先 0.6mm・隣の銅 0.5mm は除外。GND を隣に

## 発注（Fabrication Toolkit）

- 実際に発注する道具を本番の板に通して出力を読む（fab-checklist §0b）
- **実装面はパッドの層で決める**（`IsFlipped` は置いた面。ソケットは F.Cu に置いてパッドが B.Cu）。
  `pad.GetLayerName()` は裏のパッドでも F.Cu を返す → `IsOnLayer(B_Cu)`
- CPL の回転は KiCad と JLC で一致しない。`-t` を付けないと TSSOP の補正が入らない。
  配置プレビューの「+」は Pin 1 ではなく**アノード**（SOD-123）
- 2 層の板に内層のガーバーを混ぜると 4 層で作られる
- 子基板だけ先行発注すると $25〜35・2〜3 週。手戻りを小さな板に閉じ込めるなら界面を凍結して検査で守る

## KiCad の Python・ファイル

- pcbnew は KiCad 同梱の Python（3.9）にしか無い。数値は pcbnew に依存しないモジュールに置き、
  検査は venv から S 式のテキストとして読む（tests/test_meta.py が依存を見張る）
- `Flip()` は `board.Add` の後で（前だと segfault）
- `.kicad_pcb` は保存のたびに UUID と並び順が変わる → **バイト列の sha256 で比べない。**
  配置・結線・外形だけの指紋（foundry/boardhash.py）
- KiCad 10 はネットを `(net "COL0")` と名前で書く。番号前提の正規表現は 0 件でも黙って通る
- パッドを正規表現の窓で探すと、ネットの無いパッド（NPTH）から**隣のパッドのネットへ滑る**
  → 括弧の対応で切り出す（foundry/board_dump.py）
- KiCad は見つからない 3D モデルを**警告なしに飛ばす**。STEP に出た数を数える。
  モデルの在処は `KICAD10_3DMODEL_DIR` / `KICAD6_3RD_PARTY`。CI の KiCad は手元と同じ版に
  （9.0 は 10 の板を読めず終了コード 3。stderr を捨てていて気づかなかった）
- 1:1 印刷は `kicad-cli pcb export pdf --layers Edge.Cuts,...`。実寸は Edge.Cuts だけで測る
  （F.Fab の文字で外形が大きく見える）。画像化は pdf → `pdftoppm`（qlmanage は縦横比が壊れる）
- 裏面の極性は頭の中で鏡像変換しない。ネット名をシルクに焼いて同じ絵で読む

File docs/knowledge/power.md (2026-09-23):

# 電源と回路（乾電池・XIAO nRF52840）

HHKB 分割機で実測・データシートで確かめたこと。出典は HHKB の
`docs/hardware/electrical-design.md`・`decisions/2026-08-16-*.md`・`task-c4-c5-power.md`。

## 電源経路

```
電池 +  →  スライドスイッチ  →  [分圧 1MΩ+1MΩ → D0/AIN0]  →  ショットキー B5819W  →  XIAO 3V3
```

- **BAT 端子に繋がない**（LiPo 充電回路直結。USB を挿すと一次電池を充電・液漏れ・破裂）
- ショットキー 1 個で逆流防止と USB 接続時の自動切り離しを兼ねる。USB と電池を同時に
  繋いで +0.8µA（放電向き）。逆漏れの最悪は**消耗した電池**のとき
- 分圧は**スイッチの後ろ・ショットキーの手前**。USB 給電中も電池そのものが読める。
  3V3 側のコンデンサの電荷は分圧側へ流れない
- 理想ダイオード（P-MOSFET・LM66100）は**成立しなかった**: 「電位差ほぼ 0 でも逆流 0」は
  ショットキーにしかできない（LM66100 の遮断保証は逆流 0.5A から）。**この結論は
  「VBUS を渡せない」という構造に乗っていた——構造が変わったら読み直す**（#32 は前提が
  消えたのに 5 日間止めていた。再評価したら追加部品ゼロで成立した）
- 電池の + を基板へ往復させない（リード線なら直結）

## 打ち止め電圧

**打ち止め = max(動き続ける下限 + Vf, 起動できる限界 + 余裕)。**

| 下限 | 値 |
|---|---|
| nRF52840 | 1.7V（+ 余裕 0.1）＝ レール 1.80V（HHKB ではこれが律速） |
| 74LVC595 | 1.10V（74HC595 なら 2.0V で規格外） |
| マトリクス | BAT46W 0.30V ÷ 0.3（VIH = 0.7VDD）＝ 1.17V |
| ホットスワップソケット | 2.0V DC（**未検証の制約**） |

- **起動できる電圧は、動き続けられる電圧より高い。**維持 1.95V に対し起動は直列 10Ω で
  2.15〜2.25V、25Ω で 2.42〜2.70V（確率的）。**スリープ復帰も起動と同じ手順**
- 冷えるとアルカリの内部抵抗は 2〜3 倍になり「寒い朝だけ点かない」。冷蔵庫で 2h 冷やして測れる
- 打ち止め近くでは静かに止まらない: レール 1.86V で CPU は動くが無線がリンクを張れず、
  走査と広告で 2.7mA（6 倍）を食い続ける → **自分から soft off する**（firmware/）
- nRF52840 はレール 1.7V 未満でブラウンアウトを繰り返し、NVMC の書き込み（VDD ≧1.7V が
  条件）でペアリング情報が壊れうる
- リチウム一次（FR6/L91）2 本は 3.6V で nRF の推奨上限ちょうど → 禁止と説明書に書く

## バルクコンデンサ（要るかの判定順）

1. **まず C を考えずに I·R を計算する。**余裕に収まれば容量は 0 でよい
2. 収まらないときだけ C = バースト長 ÷ R を考える

実測: BLE の最大 10.22mA（広告＋スキャンが重なる分割セントラル。広告だけだと 8.02mA）×
打ち止め付近の内部抵抗 9.2Ω = 94mV（余裕 300mV）。1ns 分解能・60 万点で µs 級の尖り 0 個
→ **100µF は削除した。**載せていたときは深いスリープ（約 2µA）中に電荷が抜けず、
電源を切って入れてもリセットされない不具合（53 秒）を作っていた。バルクが効くのは
CR2032 のような高抵抗・低電流のときだけ。バルクとパスコンは兼ねられない
（100µF/1206 の自己共振は約 0.5MHz、0.1µF/0805 は約 19MHz）。

## パスコン

**効くのは直線距離ではなく、IC → パスコン → GND → IC と戻るループの配線長**（インダクタンス）。
電流は全供給元からループ L に反比例して分流する（直近の C_U1 と FFC 越しで 58:1）。
**負荷の直近にいないパスコンは誤差にしかならない**（HHKB で 2 個削除）。検査は配線後の
銅箔の経路長で行い、GND 側の戻り（ビアの数）も数える。モジュール（XIAO）は内部に
持っているので外付けは重複。LDO には出力容量の上限もある。

## キースキャン

- **行×列マトリクス＋キーごとに 1 ダイオード、行は MCU 直結の入力、列だけをシフトレジスタで**
  （ZMK 公式の推奨）。行が直結なら割り込みで起きられ、常時スキャンが要らない
- チャーリープレックスは**成り立たない**: VIH 0.7VDD・VIL 0.3VDD では本物のキーとゴーストの
  Vf の条件が両立しない（HHKB で基板発注前に破棄）
- 595 の MR（10 番）は VCC、OE（13 番）は GND。浮かせない。数珠つなぎは Q7'（9）→ DS（14）
- **595 を 1 個惜しんで論理配置を歪めない**（90mm の配線が 4 段を横断した。1 個約 30 円）
- 同時押しの逆漏れ: BAT46W で 60℃・同じ行 5 個以上は余裕を割る（25℃ なら 9 個でも可）
- 行列の目安: 押している間だけ 1 キー 0.14〜0.21mA（列 High → スイッチ → ダイオード →
  行のプルダウン）。待機 0

## 電流の目安（左＝分割セントラル・2000mAh 換算）

電流 ≒ 0.090 + 2.591 ÷ 分割間隔[ms] + 2.725 ÷ (ホスト間隔[ms] × (latency+1)) [mA]
（5 構成の予測がすべて実測と 0.01mA 以内）。スリープ中 2〜3µA。30 分でスリープなら
約 16 ヶ月、スリープ無しで約 5 ヶ月。**寿命を決めるのはセントラル側。**詳細は
[zmk-and-xiao.md](zmk-and-xiao.md)。

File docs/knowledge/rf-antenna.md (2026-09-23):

# アンテナ（XIAO nRF52840）

HHKB open-gaps #23（2026-08-23 決着）・`decisions/2026-08-16-*antenna*`・`task-c3-ble-split.md`。

## 事実

- XIAO のアンテナは **USB と反対の端**の 3.5×1.5mm のチップ（TX と印字された側の縁から 7.0mm・
  中心から 1.9mm ずれている）。USB を奥面に出すとアンテナは必ず内側を向く
- Seeed の量産設計は、アンテナの縁から 1.30mm（外形から 3.14mm）だけ 4 層とも銅を抜いている。
  一般論の「全層 5〜10mm」はそれより緩い側。整合は直列 4.7nH＋シャント 0.5pF
- **外付けの GND 面が覆いかぶさるのは別の物理。**測って決める
- ピンソケットで XIAO を浮かせると、アンテナと地板の距離が変わる（浮き 0 → 7.22mm / 2.0 → 5.24 /
  10.5 → 0.72mm）。**ソケット構成の数字でアンテナを判定しない**
- 単3電池の至近（1.0mm）は論外。実測では横 5mm でも RSSI は変わらなかった → 要件 5mm
- 送信電力で塞がれたアンテナは直らない（+4dB に対し 20〜30dB）
- 受信感度 −96dBm（保守値 −90）。0.3m で余裕 60dB、2m で 44dB

## 基板の作法

- 禁止域は**塗られた後のベタ**で確かめる（ルールエリアを置いただけでは足りない）
- アンテナ真下の配線は遠い方の層へ。0 本を目指す
- 禁止域の縁に φ0.6 の GND ビアを 1.2mm 間隔で**4 辺とも**（「2 辺以上」と緩く書いた前科）
- 禁止域の位置が本物と合うか検査する（3.9mm 外して 450mm² の銅を捨てていた）
- RF は銅の実外形で測る（保守側に太らせた箱で測って余裕を 3 分の 1 に見積もった）

## 発注前に ¥0 で測る方法（HHKB で実施）

**知りたいのが「差」なら、差を作る物（金属）で模擬できる。**アルミ箔（表皮深さ 1.5µm）と
厚紙のスペーサで地板を模し、nRF Connect の RSSI で比べる。わざと実物より悪く作れば上限になる。

1. 距離 30cm に印、向き・高さ固定、スマホは台に置く、周りの金属と USB ケーブルの取り回しを固定
2. **基準（XIAO 単体）を 2 分見て、ふらつき幅を物差しにする**（HHKB は 7dB）。
   直近 30 秒で最大も最小も更新されなければ打ち切る
3. **同じ日・同じ場所で 1 変数ずつ足す**（日を分けた比較は無効）
4. 判定: 差がふらつき以内 → 問題なし / 〜10dB → 進む / 10〜20dB → 検討 / **20dB 以上 → 改版**
5. 長さを半分・実物・倍にして共振を見る（2.4GHz の λ/4 ≒ 31mm）。GND に繋ぐリード線は
   前後で導通を確かめる

HHKB の結果: 単体 −66〜−73dBm / GND 線 40・80・160mm で +3/+3/+1dB（共振なし）/
アルミ箔を数 mm で −7dB・約 2cm で −4dB / 電池 +1dB / 全部で **−7dB** → 発注した。
手を鍵盤に乗せて試す（人体は 2.4GHz を吸う）。アルミ缶で包むと劣化する。
使用距離は設計側が仮定しない（利用者が決める）。

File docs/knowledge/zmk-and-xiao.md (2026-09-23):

# ZMK と XIAO nRF52840

HHKB の `docs/hardware/task-c1〜c4-c5*.md`・`xiao-flash-recovery.md`・`config/` で確かめたこと。

## ビルド

- **手元に Zephyr SDK は無くてよい。**push → GitHub Actions（ZMK 公式の再利用ワークフロー）→
  Artifacts の `firmware` から `.uf2`。`config/` と `build.yaml` はリポジトリ直下（入れ子は
  "no west workspace found"）。build.yml は `paths:` で文書だけの push を除く——**足りないと
  変えたのに焼かれない**（HHKB で 2 週間ビルドされないまま放置された）
- ボードは `xiao_ble//zmk`（Zephyr 4.1 以降。`seeeduino_xiao_ble` でつまずいた）
- `Kconfig.shield` の `shields_list_contains` の引数がシールド名と違うと**黙って無視される**
  （`python -m foundry.check_zmk_config` が見る）
- リポジトリ自身を ZMK モジュールにできる（`zephyr/module.yml`）。モジュールから ZMK の
  ヘッダを使うには `zephyr_include_directories(${CMAKE_SOURCE_DIR}/include)`
  （`ZEPHYR_ZMK_MODULE_DIR` は空になる）
- 成果物 `<shield>-xiao_ble__zmk-zmk.uf2`。**BLE が入っているかは大きさで分かる**
  （左 約 470KB・ログ入り 約 570KB・115KB 級なら BLE が抜けている）
- 「CI でビルド成功」と「実機で確認」を分けて書く

## 書き込み・復旧

- RESET を素早く 2 回 → `XIAO-SENSE` ドライブ（通常版でもこの名前）
- macOS のエラー -36・`cp: Device not configured`・「ディスクの不正な取り出し」は正常
- **書き込みツールの「成功」を信用しない。**`CURRENT.UF2` を読み返す（UF2 は 512B ブロック・
  マジック 0x0A324655）。SoftDevice S140 7.3.0 が 0x1000〜0x27000
- SoftDevice が消えた XIAO の復旧: Adafruit_nRF52_Bootloader 0.11.0 の zip から SoftDevice
  だけを `adafruit-nrfutil dfu genpkg --dev-type 82 --sd-req 0xFFFE` → `dfu serial`。
  **`--singlebank` は付けない**（8% しか書けないのに「programmed」と言う）
- `settings_reset` を build.yaml に常に入れる。「一覧に出るのに繋がらない」は片方だけが相手を
  覚えている状態。**左・右・ホストの 3 者を全部消す**。焼いたら本来のファームを焼き直す
- 両方に左用を焼くと 2 台ともセントラルになる。マスキングテープで印を付ける
- キーマップに `&bootloader` と `&bt BT_CLR`（`dt-bindings/zmk/bt.h` が要る）を必ず置く
  （ケースを開けずに復旧できる）

## 設定の定石（HHKB の .conf）

| 設定 | 理由 |
|---|---|
| `CONFIG_ZMK_SLEEP=y`・`IDLE_SLEEP_TIMEOUT=1800000` | 既定は n。スリープ 2〜3µA。30 分で約 16 ヶ月、無しで約 5 ヶ月 |
| デバウンス 押し 3 / 離し 5ms | 同じ文字の重複は機械的バウンス（ゴーストなら違う文字が出る） |
| `BT_PERIPHERAL_PREF_MIN/MAX_INT=12`・`LATENCY=30`・`TIMEOUT=600` | **ZMK 既定（min 7.5ms）は Apple §58.6 違反で、macOS は要求ごと捨てる。**適合させて 0.63 → 0.43mA、遅延は増えない（latency は無料、間隔は有料） |
| `SPLIT_BLE_CENTRAL_BATTERY_LEVEL_FETCHING/PROXY` | 右の残量も左から見える |
| 595 の `spi-max-frequency = <4000000>` | 200kHz では数珠つなぎで速い打鍵を取りこぼす報告がある。試験も本番と同じ周波数で |
| 残量計は `foundry,battery-alkaline`（firmware/） | ZMK 標準はリチウム曲線で 3.45V 以下が 0%。乾電池では常に 0% |
| `/delete-property/ power-gpios;` | 板の vbatt と合体し、XIAO 内蔵分圧の P0.14 を毎回叩いて 10ms 待っていた |

- `Apple §58.6`: latency ≤ 30・timeout 6〜18 秒・Min ≥ 15ms かつ 15ms の倍数・
  timeout ＞ Max × (lat+1) × 3。**規則違反で「通った」設定は採らない**（OS 更新で黙って戻る）
- ZMK の分割セントラルは、ペリフェラルが揃うまでスキャンをやめない（片側不在で 3.7mA）。
  Kconfig の入口は無い
- 分割間隔を伸ばすと右手だけ遅れる（左右差）。ホスト間隔は両手に等しく乗る
- 送信電力は既定の 0dBm が正解（+8dBm は +0.10mA、技適の 6.0mW を公称で超える可能性）
- `ZMK_BLE` は `select BT_PERIPHERAL` で、ホスト側 BLE だけを止めることはできない

## キーマップ・行列

- キーマップを解釈するのはセントラルだけ（右に焼いたキーマップは使われない）
- `&bootloader` は押された側で動く。`&bt` は常に左で動く
- conditional-layers は修飾キーを扱えない → Fn+Ctrl は FN 面の Ctrl の位置に `&mo SYS`
- 分割は transform を 1 つ共有し、右は overlay で `col-offset`。row-gpios は左右の overlay に置ける
  （左右で FFC の向きが違うなら行の並びも違ってよい。ファームで吸収し、配線をひねらない）
- ZMK の `gpio_595`: 最下位バイトが鎖の先頭・MSB first。`&shifter 0` が QA、`&shifter 8` は 2 個目の QA。
  待機中は全列 High（何も押さず QA が 3.3V なら 595 まで届いている）。STCP が外れていても
  `spi_write_dt()` は成功を返す
- 押した直後の 1 回目の走査だけ全列 High になる（ISR から SPI を使えず -EWOULDBLOCK が捨てられる）。
  デバウンスが吸収する。症状が出たら `CONFIG_ZMK_KSCAN_MATRIX_POLLING=y`

## XIAO のピン

- ピン間隔 0.6 インチ（15.24mm）。ブレッドボードでは d 行と h 行（外形 17.8 とは違う）
- USB を奥に向けて上から: 左列 D0〜D6、右列 5V・GND・3V3・D10・D9・D8・D7（**D7 が最下端**）。
  ピン番号のシルクは裏面だけ
- SPI: SCK=D8（P1.13）/ MOSI=D10（P1.15）/ **D9 は pinctrl が MISO に確保**。CS は D7
  （ZMK 公式サンプルの D9 は pinctrl と衝突しうる）
- ADC は D0〜D5 だけ（P0.02/03/28/29/04/05）
- UART ログ: `chosen { zephyr,console = &uart0; }`・`&uart0 { status = "okay"; }`・
  `CONFIG_ZMK_LOG_LEVEL_DBG=y`。**overlay に `&uart0` を置くだけで +0.46mA。**
  `CONFIG_BT_CONN_LOG_LEVEL_DBG` は禁止（ログが溢れて BLE 接続まで壊れた）
- `CONFIG_ZMK_USB=y` のファームは USB を抜いても掴んだまま → 電流を測る前に電池を入れ直す
- macOS: `ioreg -p IOUSB -w0` で `!registered` なら「アクセサリの接続を許可」。
  長押しのアクセント候補は `defaults write -g ApplePressAndHoldEnabled -bool false`

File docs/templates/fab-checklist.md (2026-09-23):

# 発注の直前に見るもの（$NAME）

**ここに記録が無いと発注しない。書いたら消さない**（次の発注で同じ穴を踏まないため）。
`tools/kb $NAME gate` が open-gaps の「発注をせき止めているもの」を見る。
ここに書くのは、それ以外に**機械では確かめられず人が見るもの**。

## 発注履歴

| 日付 | 対象 | 実装枚数 | 表面処理 | 備考 |
|---|---|---|---|---|

## §0 発注フォームで選ぶもの（JLCPCB）

| 項目 | 値 | 根拠 |
|---|---|---|
| 層 / 厚さ / 銅 | 2 層 / 1.6mm / 1oz | 2 層で足りた（HHKB） |
| 表面処理 | 有鉛 HASL | ¥0（無鉛は +¥222） |
| Remove Order Number | Yes | |
| PCBA | Economic・実装面は裏 | Standard は部品から板端 2.5mm 以上・70×70 以上が条件 |
| Confirm Parts Placement | Yes | §1 を見るため |

## §0b 実際に発注する道具を本番の板に通した結果

自前の出力で直したつもりの誤りが、発注道具（Fabrication Toolkit）の出力では
直っていなかった（HHKB）。**実際に使う道具で出して、出力を読む。**

    tools/kb $NAME fab-fields
    "$KICAD_PYTHON" -m com_github_bennymeg_JLC-Plugin-for-KiCad.cli -p <板> -t -nI

| 見たもの | 期待 | 結果（日付） |
|---|---|---|
| BOM の LCSC Part # | 全行に番号 | |
| CPL の Layer | 裏実装の部品が bottom | |
| 手で挿す部品（XIAO など） | BOM・CPL に無い | |
| TSSOP の回転 | `-t` で補正が入っている | |

## §1 配置プレビューで向きを見る

KiCad と JLC ライブラリの回転は一致しない。プレビューの Bottom 表示は X だけ裏返る。
**「+」は Pin 1 ではなくアノード**だった（SOD-123・HHKB で確認）。判定は 3D 本体の
帯（カソード）で。同じフットプリントなら 1 個読めれば全部に同じ結論が使える。

| 部品 | 面 | KiCad の板 | JLC のプレビュー | 判定（日付） |
|---|---|---|---|---|

## §2 在庫（発注の直前に API で取り直す）

    tools/kb $NAME parts

| 確認日 | 結果 | 薄い部品と代替 |
|---|---|---|

## §3 ピン配置を独立した視点で確かめる（**3 つ済むまで「確認した」と書かない**）

同じ人が同じ表を読んだ 1 視点では、読み違いは全視点で同じ方向に外れる。
IC・MCU・基板間コネクタのピン誤りは 0Ω では救えない。コネクタは「面」だけでなく
**口の向きと口から口までの経路**を追う。

| 部品 | A データシート ↔ pinmap | B 商品写真の 1 番 ↔ 描画 | C KiCad GUI でクリック | D 1:1 印刷に実物を載せる |
|---|---|---|---|---|

## §4 リスクを承知して発注する記録

open-gaps の `### 承知して発注する #N` と対応させる。

## §5 通電前の導通試験（基板が届いたら）

GND↔GND・電源↔電源が導通、電源↔GND が非導通。**通るまで電源を入れない。**

## §6 独立監査（電気 / DFM / 機械 / 外部の事実）

| 見つかったもの | 基板に効くか | どうした |
|---|---|---|

**問題なしを確認したもの（母数）:** / **見ていないもの:**

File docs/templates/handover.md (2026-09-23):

# 引き継ぎ（$NAME）

> **YYYY-MM-DD 時点の要約。**（ここを最初に読む人が 30 秒で状況をつかめるように）

## いまの状態

| 板 / 部品 | 状態 | 何で確かめたか |
|---|---|---|

## 現行の手順

    tools/kb $NAME plate
    tools/kb $NAME pcb
    tools/kb $NAME zmk
    .venv/bin/pytest tests -q

## 機械で守っていること

| 検査 | 守るもの |
|---|---|

## やめた方式とその理由

## やってはいけないこと

## 次にやること（済んだものは取り消し線で残す）

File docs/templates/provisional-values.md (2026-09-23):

# まだ実測していない値（$NAME）

`spec.py` で `[暫定]` を付けた値の一覧。**tests/test_meta.py が名前と数値をコードと
突き合わせる**（文書を見て部品を買うので、ずれていると入らない物を買う。HHKB で
倍以上ずれていたことがある）。確定したら行を消し、コードのタグも外す（残ると落ちる）。

| 定数 | 現在値 | 何の値か | どうやって確かめるか | 外したときの影響 |
|---|---|---|---|---|
| `PLATE_MARGIN_X` | 4.125 | キー領域から外形まで（左右） | 実機・既製ケースの外形から | ケースの幅 |
| `PLATE_MARGIN_Y` | 6.375 | 同（前後） | 同上 | ケースの奥行・ネジの置き場 |

## 確定させる順番

1. 買う・刷る前に決まるもの（データシート・API で閉じるもの）
2. 部品が届いたら測るもの（ノギス。**定義と測定対象を一致させる**——「箱」と書いて
   測ったのが電極だった）
3. 組んでから測るもの

## 確定させたときの手順

1. spec.py の値を直し、`[暫定]` を外す
2. この表から行を消す（残ると検査が落ちる）
3. 根拠（測り方・日付・値）を docs/ のどこかに残す
4. `.venv/bin/pytest tests` と、形に関わるなら `tools/kb <機種> plate` / `pcb` を回す

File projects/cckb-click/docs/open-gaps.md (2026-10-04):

# 要求とまだ違うところ・まだ分からないこと（cckb-click）

**差があること自体は悪くない。悪いのは、差があるのに気づけないこと。**

`tools/kb cckb-click gate`（発注の門）が「★ 発注をせき止めているもの」の表を読み、取り消し線の無い行が残っていれば止める。
書き方の約束は docs/templates/open-gaps.md。

---

## いま残っているもの（2026-10-04 に棚卸し。**利用者が試し刷り v2 を刷って試した後**: 下穴 φ1.6・電源スイッチを 0.75 外へ（基板を直した）・**蓋は、道具なしで上から落とし込む形にした（まだ刷っていない。ねじで留める形は、道具が要るので退けた）**）

> **いちばん大事な 1 つ（P23）: 電源スイッチの本体は基板の縁から 1.75 mm で、JLC の実装の規約の「部品の本体と基板の縁は 2.5 mm 以上」を満たさない。**
> 利用者の決定（2026-10-04）: 規約より使いやすさ。JLC が載せないと言ったら、その 1 個だけ手はんだにする（7 か所・基板は変わらない）。
> 画面での確かめ方と、断られたときの手順は docs/order-steps.md の冒頭。

### 決まったこと（記録は docs/decisions/）

| 何 | 決定 |
|---|---|
| 機種 | `cckb-click`。projects/cckb/ とは別。CCKB には手を入れない（戻り先） |
| スイッチ | Alps SKRAAWE010（JLC C202383）。ランドは SKRACAE010 と同じ |
| 1 マスの形（2026-10-03 の試し刷り） | 案 B・穴 17.05 角（隙 0.20）・つばのキャップ F・0.4 ノズルの精度優先の刷り方 |
| 基板・枠・留め方・角・電池・底 | 決定記録 2026-10-03-board-and-case。いまの状態は docs/status.md |
| 1 回目の監査（2026-10-04・5 視点・致命 0）の直し | 決定記録 2026-10-04-audit-1: 電池の座る位置・載せないコンデンサのランド 2 つ・予備のねじ穴 2 つ・ねじ穴を 0.1 外へ・戻りの道ほか |
| 電源スイッチ・電池の蓋（2026-10-04・利用者） | 決定記録 2026-10-04-switch-cover: つまみを枠の外へ出さない（枠の切り欠きの中）・蓋のねじ穴 2 つを基板に取っておく（使わない）・電池は CR1632 のまま。~~本体を基板の縁から 2.5 内側へ・蓋は差し込み式~~（下の行で置き換えた） |
| 試し刷り v2 の結果（2026-10-04・利用者） | 決定記録 2026-10-04-knob-out-pilot: **電源スイッチは 0.75 外へ**（本体は縁から 1.75・つまみの先は基板の縁の 0.30 内・枠の外面の 0.60 内。**JLC の「2.5 mm 以上」は満たさない = 規約より使いやすさ**）・**下穴は φ1.6**・**蓋は 3 つとも使えない → 利用者が考え直す**（刷る物から外した） |
| 電池の蓋（2026-10-04・利用者） | ~~決定記録 2026-10-04-cover-screw: ねじで留める（基板の穴 H30・H31）~~ → 同じ日に置き換えた: 決定記録 2026-10-04-cover-latch: **道具なし・しっかり留まる・押しても振っても電池が出ない**。上から落とし込む蓋（電池の力は耳と溝で受ける・上へは棒の先と枠の歯で留める・開けるのは「押し込む ＋ 持ち上げる」）。基板は変えない（穴 H30・H31 は使わない）。枠の口は幅 19.0。蓋の試し刷りは docs/coupon-test.md 10 章 |
| ライセンス | 形は CC BY-NC 4.0・出どころと変えた所を LICENSE に・販売者の製品名を部品に付けない |

### ★ 発注をせき止めているもの

| # | 何 | 次の一手 |
|---|---|---|
| ~~#1~~ | ~~基板がまだ無い~~ ✅ 2026-10-03 設計した（板 `pcb/cckb-click_main.kicad_pcb`・DRC 違反 0・未配線 0・警告 0。外の事実 = kicad-cli の DRC と発注道具の出力。壊すと落ちる検査は tests/test_cckb_click_board.py） | 無し |
| ~~#30~~ | ~~直した板を、独立に見直していない~~ ✅ 2026-10-04 2 回目の監査（A+F+D と B+C+E・HEAD 8f90c8e・板 4dc68901…）に出した: **致命 0・重要 0・「これらの視点では発注してよい」**。指摘の軽微は下の「軽微・承知しているもの」と docs/order-steps.md・assembly-guide.md に記録 | 無し |
| #31 | **利用者が決める・見る**: (1) JLC への頼み方 = Economic か Standard か・表面処理（勧めは ENIG）。(2) **電源スイッチを JLC が載せるか**（本体が縁から 1.75 = 規約の 2.5 を満たさない: P23）を注文画面で見る。載せないと言われたら、BOM と CPL から SW_PWR を外して手はんだ（利用者が決めてある）。(3) 注文画面の配置プレビュー（部品の向き 5 か所）と、払った後の製造データの確認（位置決めの穴） | docs/order-steps.md の冒頭と §2-1・§3 |
| #32 | **CR1632 で起動できるか**（電気の設計は CCKB と同じなので、CCKB の #1 と同じ試験）。まだ測っていない。新品 3.0 V でも、レールは約 2.35 V の見積もり（内部抵抗 25 Ω・BAT46W。1 回目の監査 A 重要 1） | projects/cckb/docs/task-10a-coin-cell-startup.md を上から（買う物なし・約 1.5 時間）。結果は両方の機種に効く。**足りなければ、載せないコンデンサのランド C_BAT・C_3V3 に容量を足す**（板は変えずに済む） |
| ~~#33~~ | ~~**ねじ**: 樹脂に直に切る M2×4 が効くか（基板の穴の位置は発注後に直せない）~~ ✅ 2026-10-04 利用者が試し刷り v2 の A を刷って締めた: **下穴 φ1.5／1.6／1.7 は 3 つとも止まる（空回りしない）。φ1.6 は薄い壁でも問題なし**（φ1.5 は入れ始めにかなり力が要った・φ1.8 は空回りした）。→ **本番の下穴を φ1.6 にした。基板の穴の位置は変えなくてよい**（閉じる理由はここ: 樹脂に直に切る留め方が成り立つ）。本番の枠の下穴は、線で ふつうの壁 1.54・薄い壁 1.49〜1.50 = 利用者が締めた切れ端と同じ径（G-code で測った）。**分かっていないこと: 締め直した回数は聞いていない**（5 回もつ、とは言えない → P1 に残した） | 無し（残りは P1） |
| ~~#34~~ | ~~**電源スイッチのつまみ**の位置（基板で決まり、発注後に直せない）~~ ✅ 2026-10-04 利用者が試し刷り v2 の B を触って **(ii) 0.75 外**を選んだ → 基板を直した（本体は縁から 1.75・つまみの先は基板の縁の 0.30 内・枠の外面の 0.60 内。決定記録 2026-10-04-knob-out-pilot）。**代わりに JLC の「2.5 mm 以上」を満たさなくなった**（P23・#31）。直した板の見直しは #36。同じ試し刷りの**蓋は別の行（#34b）に分けた** | 無し |
| #34b | **電池の蓋: 利用者が「道具なしで開け閉めできて、しっかり留まる蓋。電池は、人が蓋をわざと外したときだけ出せる」と決めた（2026-10-04）。**上からまっすぐ落とし込む蓋を作り、独立の見直しを受けて直した（v2・決定記録 2026-10-04-cover-latch・絵 build/cckb-click/cover_latch.png）: 電池が手前へ押す力は、蓋の左右の耳（45° のくさび）が枠の溝で受ける（ばねを通らない）。上へは、蓋の手前の面の 2 本の棒の先が、枠の歯の下に直角の面で当たる。**立体と G-code で測った限り: 蓋を付けると電池は 10 の向きのどれにも出ない・蓋は棒を 2 本とも押し込まないと抜けない・棒 1 本を押しても片側が 1.1 浮くまで・基板は変えない。まだ刷っていない。****満たせていないこと: 爪 1 つ（2 本の棒にまたがる細い物）で、押しながら上へ擦れば開く・押す力は 2.2 N と小さい** = 「わざとでないと開かない」は、形だけでは言えていない | 利用者が蓋の試し刷り（`build/cckb-click/coupon_corner_plate_n04.gcode.3mf`・docs/coupon-test.md 10 章・蓋 3 つ）を刷って、擦る・片方だけ押す・振る・電池を押す・落とす・開け閉めを試す。**利用者が「この蓋でよい（3 つのうちどれか）」と言えば閉じる。**足りなければ、決定記録の「利用者の選べる道」（磁石か金属のばねを買う・硬貨で回す留め・形から考え直す）。細かい事実は P21 |
| ~~#36~~ | ~~**2026-10-04 に直した板（b442b865…）を、独立に見直していない。**前の板（fe90b1e6…・3 回目の監査で致命 0・重要 0）との違い: 電源スイッチを 0.75 外へ（部品で動いたのはこれだけ）・角の中の線 8 本とGND のビア（6 個消えて 7 個足した）・角の外は VBAT_SW の長い線の右の端が 0.75 延びただけ・ベタの塗りの違いは角の外で 0。枠は切り欠きの形・入の印の場所・下穴 φ1.6。DRC は違反 0・未配線 0・警告 0~~ ✅ 2026-10-04 4 回目の監査（前の板 fe90b1e6… との差分・HEAD 5f8cf06・板 b442b865…）に出した: **致命 0・重要 1・軽微 5・「差分については発注してよい」**。重要 1 件は記録の誤り（つまみの出の公差 ± 0.1 → 図面の未注の公差 ± 0.2。直した: P23・D4・決定記録 2026-10-04-knob-out-pilot・docs/order-steps.md の冒頭）。軽微は下の「軽微・承知しているもの（4 回目の監査）」。**線 9 本が変わった（角の中 8 本＋長い VBAT_SW。その右の端が x 288.125 → 288.875 に動いた）。差は x ≥ 287.6・y 127.9〜143.2 に収まる**（「角の外は 1 本だけ」は正確でなかった）。 | 無し |
| ~~#35~~ | ~~2026-10-04 に直した板（fe90b1e6…）を、独立に見直していない~~ ✅ 2026-10-04 3 回目の監査（前の板 4dc68901… との差分）に出した: **基板は致命 0・重要 0**。変えたのは右手前の角だけ: 電源スイッチを 1.75 内側へ・C_BAT を 1.0 左へ・蓋のねじ穴 2 つ・電池の＋（VBAT_IN）を決まった形に・VBAT_SW の右の端・電池クリップのコートヤード。**角の中では GND の縫いのビアを置き直した**（8 個消えて 9 個足した。新しい 1 個は (261.7, 144.815)）。**角の外には、無視できる違いが 2 つ**（ビア 1 個が 1 nm 動いた・ベタの塗りの差 2.6e-5 mm² 以下）。線・部品は前の板と同じ。重要 1 件は刷る蓋のばね（ひずみの式が効いていない長さを使っていた）→ 直した（決定記録 2026-10-04-switch-cover「3 回目の監査と直し」・板は変えていない）。軽微は下の「軽微・承知しているもの（3 回目の監査）」 | 無し |

### 物を買う・刷るまで進まないもの

**本番の枠とキャップを刷ると分かること（基板が無くても刷れる）**

| # | 何 | 要るもの |
|---|---|---|
| #10b | 押す面の高さ（浮き 0.2 は触っていない）・幅の広いキーのぐらつき・長い枠の反り・62 個のキャップが全部自分の重さで動くか | 枠 2 枚とキャップ 62 個を刷る（docs/printing-guide.md） |
| P1 | **枠の下穴 φ1.6 で、何回締め直せるか。**径は試し刷り v2 で決めた（#33 済み。壁の外の肉 1.6・内 0.8・幅の広いキーの脇の H16・H17・H18 は斜め内向きに 0.59。ねじの外径の外に残る壁は 0.6／0.39）。**利用者が締め直した回数を聞いていない。**試したのは、ふつうの M2×4 の小ねじ（買う物の表のスリムヘッドではない。ねじ山は同じ） | **利用者に聞く**（v2 の A で何回締め直したか）。本番の枠でも、ねじを 1 本入れて確かめる。分解のたびに締め直すので、5 回は試す（docs/coupon-test.md 6 章の見方）。きつければ φ1.6〜1.7 のドリル |
| P2 | **電池を指で引き出せるか**（蓋を外した状態。電池は止めに当たる所に座る: 手前の縁が枠の外面から 1.71 奥。切り欠き〔奥行き 4.5〕から電池の上面が 2.79 見える）。**2026-10-04 の角の試し刷りでは楽に出し入れできた。ただし試し刷りには電池を押さえるクリップのばねが無い**（利用者の指摘）= 本物の固さは分かっていない | **基板が来たら、本物のクリップでもう一度。**出せなければ電池の口（奥行き `FINGER_NOTCH_DEPTH`）を広げて右の枠と蓋を刷り直す（基板は変わらない）。**蓋を付けているときは、先に裏のねじ 2 本と蓋を外す** |
| P21 | **電池の蓋は、道具なしの落とし込み式（v2・2026-10-05・刷る物: `cover_battery.stl` = 予備を含めて 2 個。まだ刷っていない）。**形: 手前の板（下の帯・上の帯・その間に棒 2 本）＋ 上の板 ＋ 左右の足 ＋ 耳の付け根の柱 ＋ 左右の耳（奥の面につぶれる筋）。枠の口は幅 19.0・左右に溝・手前の角に歯 2 つ。**分かっていないこと・弱い所**: (1) **爪 1 つで開く**（2 本の棒にまたがって 0.43 押し込み、上へ。2.2 N）。端を 1 つずつ、2 回に分けても開く（棒 1 本を押すと、その側が 1.1 浮いて、そのままになりうる）。形では防げなかった理由は決定記録。(2) **落下で棒が一瞬引っ込むか**: 1500 G・半波 0.5 ms（仮定）で、棒の揺れ 0.51 に対して外れ始め 0.96 = 余裕 1.9 倍（蓋が奥へ寄り切っていれば 1.5 倍・棒が 0.15 薄く刷れれば 1.4／1.1 倍）。(3) **蓋の胴の強さ**: 同じ仮定で電池が押す 26.5 N に、手前の縁の引っ張り 23.7 MPa（強さ 35）= 余裕 1.5 倍。上の板を 0.7 より厚くできない（クリップの上の隙 0.2）。(4) 歯と棒の上下の隙（0.2／0.3／0.4 を振った）が、1 層目の太りでどう出るか・つぶれる筋の固さ（0.40／0.50／0.60）。(5) 本物のクリップ・電池で、足と電池の隙 0.2・上の板とクリップの隙 0.2 が足りるか（**試し刷りの当て板にはクリップの板の代わりが無い**）。(6) 枠の歯（右は高さ 2.6・左は 1.2）が、こじる力で折れないか。(7) 蓋は外れる小さな部品（0.2 g）= 無くしうる（つなぎ留める穴は作れなかった。予備を一緒に刷る）。履歴: 差し込み式の v1 と v2 の 3 つは、刷って 4 つとも使えなかった。ねじで留める蓋は、刷る前に退けた（道具が要る）。落とし込み式の最初の形（e4b7cdd）は、独立の見直しで 6 つの指摘を受けて直した | 蓋の試し刷り（docs/coupon-test.md 10 章）で (1)〜(4)(6) を見る。(5) は基板が届いてから本物で見る（当たるなら蓋だけ刷り直す） |
| P3b | **予備のねじ 2 本**（手前の継ぎ目の両側 H28・H29。基板の穴と枠の下穴はある）を締めるか | 組んで、継ぎ目が浮く・段が付くなら締める（M2×4 を 2 本足す） |
| P3 | **左右の枠の継ぎ目**: 継ぎ目の列（8・U・J/H・N・真ん中と右のスペース）のキャップは、左の枠のリブと右の枠の穴の両方に触る。枠は基板のねじ（穴の遊び 片側 0.1）でしか位置が決まらない → 最悪 0.2 ずれて、隙 0.2 を食う | 刷って組む。挟まるなら `FRAME_SEAM_GAP` を広げるか、継ぎ目の列だけ穴を 0.1 広げる（枠は刷り直せる） |
| P5 | 継ぎ目の溝（幅 2.0）の真下に物がある所が 26 か所。刷る向きで溝をまたぐ小さな橋になる: 柱 17 本（奥行き 0.3。試し刷りにもあった形）・**奥の壁のねじの所 9 か所（奥行き 0.5。試し刷りには無かった）** | 刷って、垂れが柱の先（基板に着く面）に出ていないか見る |
| P6 | 中の押さえ（基板の穴 8 個・枠の足）は**既定では使わない**。枠の真ん中が基板から浮く（がたが増える）かは刷らないと分からない | 浮くなら `HOLDDOWN_FEET = True` で刷り直す（支え材が要る。掛かりは 1.4 しか無い） |
| ~~P8~~ | ~~電源スイッチのつまみの出（枠の外面から 0.4）で、爪で動かせるか・鞄で引っ掛からないか~~ ✅ 2026-10-04 前提が消えた: つまみは枠の外へ出さない（決定記録 2026-10-04-switch-cover）。爪で動かせるかは #34 と P22 | 無し |

**基板が届くまで分からないこと**

| # | 何 | なぜ今は分からないか | 基板が来たらすること |
|---|---|---|---|
| #2 | リフローのあと、スイッチがキャップに押し込まれていないか | はんだの厚さ・スイッチの浮き・ステムの高さの個体差（3.4 ± 0.2）は実物にしか無い | 62 個のステムの高さを測る。キャップを載せて全キーが OFF か。足りなければキャップを刷り直す |
| #3 | 音と感触 | 仕様書に操作音の規格値が無い | 実物で。合わなければ SKRACAE010（同じランド。ステムが 0.1 高い → #15） |
| #4 | 枠・基板のたわみによる誤入力 | **計算した**（決定記録 2026-10-03-board-and-case §2-2: 柱の間でリブを 10 N で押して 0.086・余裕 0.1。打鍵の 3 N なら 0.026。**10 N の余裕は 0.014 しか無い**）。**0.086 は、リブの両端が柱で固く止まっている場合の値。**端が回る（柱が浮いている・ねじが効いていない）場合は 4 倍の約 0.34（1 回目の監査 E 軽微 3: 端の条件で 0.086〜0.34）。材料の値は一般値・枠の反りと柱の当たりは実物にしか無い | 全キーを強く押して、隣が反応しないか。枠のリブを指で押して反応しないか |
| #5 | 幅の広いキーの端を押したときの反応 | クリックの出方は実物 | 端を押す。だめなら左右の空きランドにスイッチを手はんだ（C202383 を余分に買う） |
| #6 | チャタリング | 仕様書は跳ね 10 ms 以下。販売者は「打鍵方法によっては出る」 | ZMK のデバウンス（いま 押す 5・離す 10 ms）を実機で決め直す。2 度打ちが出たら離す側を上げる・遅く感じたら押す側を下げる |
| #7 | 低い電圧・小さい電流での接触 | 定格の下限 1 V・10 µA に対して、計算では打ち止め 2.0 V でも約 109 µA（検査に入れた）。**走査は短いパルス**で、定格は直流の値 | 電池が減った状態（可変電源 2.0 V）で全キーが入るか |
| #8 | 長押し（修飾キー）。仕様書 C8「長時間 ON にしない」 | 寿命・戻りの話 | Shift / Ctrl / Fn を数時間押したあとの戻り |
| #15 | SKRACAE010 に替える場合、ステムが 0.1 高い | 品番の違い | 替えるときに押す面を上げて刷り直す（基板は同じ） |
| P22 | **本物の電源スイッチを、枠の切り欠きから指で動かせるか**（動かす力 150 ± 100 gf・行程 1.6 ± 0.2。試し刷りのつまみは樹脂の小片で、固さが違う。位置と切り欠きは、利用者が試し刷り v2 の (ii) で触って選んだ物） | 本物の部品は基板にしか無い | 組んで、上からと横から動かす。固くて動かせなければ切り欠きを広げて右の枠を刷り直す（基板は変わらない）。**鞄の中で勝手に切り替わらないかも見る**（先は枠の外面の 0.60 内。前の位置は 1.35 内だった） |
| P7 | 電源スイッチの入の向き（つまみを奥 = 入、は図面の回路図の読み） | 図面に「どちらが入」の表は無い | テスターで。逆なら枠の印の側を変えて右の枠を刷り直す（基板は変わらない） |
| P9 | 電波（アンテナのまわり）。禁止域は CCKB と同じ決め方だが、すぐ上に枠の屋根（PLA）・右に Alt のスイッチ（金属）・左下に何も無い。**厚さ 8.1 mm の機種なので、アンテナは机の 2.1 mm 上**（底のシート 0.5 ＋ 基板 1.6） | 実機か、アルミ箔の模擬（docs/knowledge/rf-antenna.md） | 接続が切れないか・RSSI。**同じ日に 1 つずつ変えて比べる**（1 回目の監査 D 軽微 5）: 木の机 → **金属の机（スチールの天板）** → 机との間に**アルミ箔**を敷く（金属の机の模擬）。底のシートに金属・カーボン・アルミ蒸着の物を使わない（docs/shopping-list.md） |
| P10 | 電池の −が裸の銅（HASL か ENIG）に当たって、接触が安定するか | 実物 | 電池を入れて電圧を測る。揺すって切れないか |
| P17 | **スリープの電流**。SPI の MISO（D9・基板では空き）にプルダウンを付けた（overlay の末尾。1 回目の監査 A 軽微 1）。浮いた入力が電流を食っていたかは、測らないと分からない | 実機 | スリープに入れて電流を測る（docs/knowledge/measurement.md の順。HHKB の実測は 2〜3 µA）。プルダウンを外した overlay と比べる |
| P18 | **USB を挿している間、電池へ逆に流れないか**（1 回目の監査 D 軽微 6）。USB で動くと XIAO が 3V3 を 3.3 V にする。電池（3.0 V 以下）との間は D_PWR（BAT46W）が逆向きに止める。**逆方向の漏れの大きさは、この作業ではデータシートで確かめていない**（ショットキーは漏れが大きく、温度で増える部類） | 実物 | USB を挿し、電源スイッチ入・電池を入れた状態で、TP_VSW と GND の間の電圧が電池の電圧のまま上がらないこと。電池の +の線に電流計を入れて、流れ込む向きの電流を測って控える（一次電池は充電してはいけない） |

**設計に残っている差**

| # | 何 | 状態 |
|---|---|---|
| #9 | 1u の縁を押して遠い側のつばだけで回ると、押す面の傾きが 3.2°（スイッチの仕様は 3° 以内） | 設計では消していない。検査が数字を見張る。実物で #5 と一緒に見る |
| P4 | **595 のまわりの GND**（1 回目の監査 D 軽微 1 で直した）。(1) 表: 595 の本体の下の帯に線を通さず、ビア 4 本を先に打つ → ビアから銅の上でいちばん遠い所は 13.3 mm（前は 17.2。**板の全部を同じ上限 15 で見張るようにした**）。(2) 裏: パスコンの GND から 595 の GND（8 番）までを GND の線で引いた。道のりは U1 19.7・U2 22.3 mm（前は 23.7・31.6）。**まっすぐなら 11.1 mm で、2 倍は残っている**: 595 の Q0（15 番）の線が、VCC（16 番）と GND（8 番）の間で裏のベタを切る（ピンの並びで決まる） | 検査が上限 25 で見張る。SPI・595 どうし・電源の枝は、**監査した板（4dc68901…）で Freerouting が引いた線を置き直す**ようにした（pcb/freerouted.json・2026-10-04。板を直すたびに形が変わらない。検査 `frozen_problems`）。もっと詰めるなら、595 のまわりを全部決まった形で引く |
| P11 | アンテナの禁止域の縁の GND のビア: 奥 4/7・右 10/11・**手前 0/7・左 0/11**（手前は基板の縁・左は XIAO の下で、打てない） | CCKB と同じ並び。記録だけ |
| P12 | 行（XIAO → バス）は裏の左の縁を最大 80 mm 上がる。隣どうし 0.6 おきに 3 本並ぶ | 走査の遅い信号。記録だけ |
| P23 | **電源スイッチの本体は基板の縁から 1.75 mm = JLC の実装の規約「部品の本体と基板の縁は 2.5 mm 以上」を満たさない**（利用者の決定 2026-10-04: 規約より使いやすさ。試し刷り v2 で (ii) を選んだ）。Economic の注意書き「線と部品は縁から 0.3 mm 以上」は、**名目でちょうど 0.30 = 「以上」の下限で、余裕は無い**（ランドは 1.70）。**図面はつまみの出に個別の公差を書いていない。未注の公差は ± 0.2**（前の記録の ± 0.1 は誤り。図面を自分で読んだ）。最悪の場合は、基板の縁に対して 0.30 − 0.20 − 0.075（突起 φ0.75 の穴での遊び）= +0.025（細い突起 φ0.65 なら −0.025）= 先は実質、基板の名目の縁に届きうる。枠の外面に対しては ≒ +0.10〜+0.13 で、枠の外へは出ない。置くずれ・外形の公差 ± 0.2 は見ていない。**JLC が載せるかどうかは、注文してみるまで分からない** | **JLC に載せてもらう形のまま頼む。**注文画面と、注文の後の確認で断られたら、BOM と CPL から SW_PWR の行を消して頼み直し、届いてから手はんだ（端子 3 ＋ 枠 4 = 7 か所・C431540 を 1 個買う・**基板は変わらない**）。手順は docs/order-steps.md の冒頭。内へ戻す（2.5）と規約は満たすが、利用者が「奥すぎる」と言った位置に戻る。**選択肢（まだ決めていない）: 0.2 だけ内へ戻す（つまみの先は基板の縁の 0.50 内）と余裕は戻るが、触って選んだ位置から離れる**。**届いたら、つまみの先の傷と動きを見る**（JLC のルーターが触れた跡がないか） |
| P24 | **蓋のねじ穴 H30・H31 は、いまは使っていない**（基板の穴だけ。蓋を落とし込み式に変えた: 2026-10-04）。基板は発注用に固めてあるので、穴は残る。電池を抜き差しする道の下にあり、電池クリップのコートヤードの口の側の両脇を欠いて置いてある。蓋の足が穴の上に載るだけで、穴には何も入れない。底のシートは、ここに穴を開けずに塞ぐ。裏は「頭の下の銅の禁止」のまま。**欠いたコートヤードの所は、KiCad がもう重なりを言わない**（そこにある物: クリップの板の口の側の端と、電池の道と、蓋の足） | **欠いた所に将来、基板の部品を置くなら、自分で検査を書く**（蓋の足が来る）。穴にねじを入れない（入れると電池の道を塞ぎ、蓋の足にも当たる） |
| P25 | **電池を手前へ止める物は、蓋だけ。**クリップ MY-1632-03-R は電池を上からばねの指 2 本で押さえるだけで、図面 MY-CP-0247 に手前の止めも保持力の値も無い（図面を読んだ 2026-10-04・利用者の指摘）。これまでの記録の「蓋は無くても使える（電池はクリップが持つ）」は、**振る・落とすで電池が抜けないことを確かめずに書いていた**。蓋は飾りではなく電池の止め = **必須の部品**。**いまの蓋（落とし込み式）は、この力を、ばねを通さずに枠の樹脂で受ける形にした**（決定記録 2026-10-04-cover-latch）: 蓋を付けると、電池は手前へ 0.23 で蓋の足に当たって止まる（−の裸の銅 φ7 からは外れない）。1500 G（仮定）で電池 1.8 g が押す力は 26.5 N。この力で蓋の胴は横向きの梁として曲がり、手前の縁の引っ張りは 23.7 MPa（強さ 35 = 余裕 1.5 倍。計算） | 蓋を必須の部品として扱う（刷る物・組み立ての手順）。蓋の試し刷りで、電池の代わりを蓋の方へ強く押して見る。基板が届いたら、蓋なし・蓋ありで振って電池が動くか・途切れるかを見る。電池と金具を替える検討（CR2032）でも同じ条件を入れる |
| P13 | 底のシートを貼ると、基板の裏のシルク（キーの名前）は見えなくなる | 貼る前に写真を撮る |

**検査が見ていない値**

| # | 残っているもの | なぜ残すか |
|---|---|---|
| #18 | `CAP_TOP_CHAMFER`・`CAP_BOTTOM_CHAMFER`・`TAB_LEN`・`POST_W`・`POST_L`・`FOOT_REACH`・`COUPON_BASE_T`・`COUPON_MARK_CHAMFER` | 触って決める値・試し刷りだけの値（2026-10-03 に定数を 10% ずらして測った） |
| P14 | **基板と枠の段で足した定数は、定数を壊す検査（foundry.mutate）にかけていない**（1 回目の監査の直し・電源スイッチと蓋で足した定数も同じ） | 時間。壊すと落ちる検査は検査ごとに書いた（足跡・CPL・禁止域・ビア・干渉・電池・USB・電池の縁から銅まで・シルクの図形・戻りの道・ねじの肉）。次の監査の前に mutate を回すとよい |

**道具に残っている差**

| # | 何 | 状態 |
|---|---|---|
| #22 | `foundry/slice_check.py`（`tools/kb <機種> slice`）は設定の継承をたどらない | cckb-click は tools/slice_precise.py・tools/slice_main.py を使う。foundry は直していない |
| P15 | 配線の道具は CCKB の projects/cckb/tools/route_pcb.py を読み込んで使う（ベタ・縫いのビア・置けるかの判定）。核（foundry/）へは移していない | CCKB の側を変えない約束のため。2 機種で共通になった部分なので、CCKB を触ってよくなったら foundry へ移す |
| P16 | tests/test_cckb_click_case.py は約 8 分かかる（62 個 × 5 通りの干渉を立体で見る） | `-m "not slow"` で飛ぶ。発注前と CI では回す |
| P19 | **ファームは CI でビルドしていない**（push していない。1 回目の監査 A 軽微 3）。overlay に足した SPI の pinctrl の上書きは、手元ではビルドで確かめられない（`foundry.check_zmk_config` と、ボードの pinctrl の写しとの突き合わせだけ） | push すると GitHub Actions が `cckb_click` をビルドする。**赤なら overlay の末尾の節を見る** |
| P20 | **config/west.yml は ZMK の main を追う**（版を固定していない。1 回目の監査 A 軽微 2）。CCKB と共用のファイルなので、ここでは固定しなかった | 電池電圧の式（ドライバ・overlay・基板の分圧）は検査が突き合わせる。ZMK が Zephyr を上げたら、写し（foundry/upstream/）を取り直す。固定するかは 2 機種まとめて決める |

### まだ決めていない判断（利用者）

| # | 決めること | いつ決まるか |
|---|---|---|
| D1 | **底のシートの材料**（厚さ 0.5 を仮定）。候補と注意は docs/shopping-list.md | 買う前 |
| D2 | **基板の表面処理**（HASL か ENIG か）。**勧めは ENIG**（電池の −が当たる裸の銅。1 回目の監査 C 重要 3）。Economic で選べる色は画面で見る | 発注のとき（docs/order-steps.md §2-1） |
| ~~D5~~ | ~~**電源スイッチの位置**: (i) 本体は縁から 2.5 か、(ii) 0.75 外か~~ ✅ 2026-10-04 利用者が **(ii)** を選んだ（JLC の「2.5 以上」より使いやすさ）。基板を直した（#36 で見直す） | 済み |
| D4 | **JLC の実装を Economic にするか Standard にするか**（リフローの温度の余裕と費用。差は 約 ＋$20〜$28。利用者は安い側に傾いている・まだ決めていない）。**電源スイッチは、まず JLC に載せてもらう形で頼み、断られたら手はんだ**（決めてある: P23）。Standard なら 2.5 mm を割っていても載るのかは**確かめていない**。**JLC の実装の FAQ（その 2）Q14（原文を読んだ 2026-10-04）: Economic は基板を「面付けして一度に流すので、実装の後に切り離す」（ルーターの公差は約 0.2 mm）。だから「縁から 0.3 mm を超える」。これは面付けする場合の話で、この板（286 × 96・面付けの上限 250 × 250 を超える）が 1 枚で流れて外形を実装の前に切るのか、実装の後に切るのかは、FAQ に書かれていない = 未確認（利用者の指摘: 普通は外形は実装の前に切る）。実装の後に切る場合に限り、つまみの先は名目でちょうど 0.300 なので、最悪の場合はルーターがつまみに触れうる。届いたら、つまみの先の傷と動きを見る** | 発注のとき（docs/order-steps.md §2-1 の表） |
| ~~D6~~ | ~~**電池の蓋をどうするか**（付けない／作り直す／ねじで留める）~~ ✅ 2026-10-04 利用者が「ねじで留める」と決め（決定記録 2026-10-04-cover-screw）、そのあと同じ日に「道具が要るのは使えない → 道具なしで、しっかり留まる蓋」と決め直した（決定記録 2026-10-04-cover-latch）。残るのは、試し刷りを触って「この蓋でよい」を利用者が言うこと（#34b） | — |
| ~~O15~~ | ~~**蓋のねじ穴（H30・H31）を使うか**~~ ✅ 2026-10-04 一度「使う」と決めたが、蓋を道具なしの形に変えたので**使わない**（穴は基板に残る。P24） | — |
| O11 | **595 の末端を XIAO に戻すか**（CCKB の O11 と同じ。U2 の QH'〔9 番〕と XIAO の D9 はどちらも空き。繋げば、数珠つなぎが生きているかを自分で検査できる）。**足していない**（合意の外。足すと D9 のプルダウン〔P17〕は要らなくなる） | 利用者が決める。足すなら回路・配線・overlay を直す（**発注前にしか足せない**）。要らなければ何もしない |
| O14 | **載せないコンデンサのランド C_BAT・C_3V3 に部品を載せるか**（CCKB の O14 に当たる。こちらはランドを置いた）。C_BAT は背 2.8 まで（1206 でも可）・C_3V3 は**背 1.45 まで**（キャップの下。0805 の 22〜47 µF） | #32 の結果で。載せるのが正しいとは限らない（docs/knowledge/power.md: HHKB では 100 µF で 53 秒リセットできなかった）。品番は載せると決めたときに |
| D3 | 予備のスイッチを何個買うか（空きランドに足すなら最大 22 個） | 発注のとき |
| #17 | 幅の広いキーの空きランドにスイッチを足すか | #5 の結果 |

### 見直してもらった所（#36・2026-10-04 に 0.75 外へ動かした板 b442b865…。4 回目の監査で済み: 致命 0・重要 1〔記録の誤り・直した〕）

| 視点 | 何を |
|---|---|
| 基板（発注） | 電源スイッチの本体と縁 1.75・つまみの先が縁の 0.30 内・ランドが縁から 1.70（JLC の「2.5 mm」を満たさないこと・Economic の「0.3 mm」）・CPL の SW_PWR の位置と向き・手はんだに替えるときに消す行。足跡のコートヤードの右の端は基板の縁の 0.005 内（ほぼ同じ線。つまみの先 ＋ 余裕） |
| 基板（電気） | VBAT_IN の最後の区間・VBAT_SW の縦の区間（x 138.875）と C_BAT の枝・スイッチの枠のランド 4 つの GND のビア・角の GND の縫いのビア（6 個消えて 7 個足した）・ビアと基板の縁の間 |
| 前の板との違い | 変わったのは線 9 本（角の中 8 本＋長い VBAT_SW の右の端 0.75）で、差は x ≥ 287.6・y 127.9〜143.2 に収まる、という突き合わせ（線・ビア・部品・ルール領域・ベタ）が正しいか。pcb/freerouted.json は変えていない |
| 枠 | 切り欠きの新しい形（外へ広がる・内側の上の縁を斜めに）の強さの見積もり（厳しい見方で 20.4 MPa・上限 38。断面を立体から測る式）・入の印の場所・下穴 φ1.6 と薄い壁（線で 1.50）を補正しない判断・つまみの先と枠の外面 0.60 |
| 記録 | 「JLC の 2.5 mm を満たさない」が、発注の手順・状態・決定記録に同じ数で書いてあるか。締め直しの回数を「分かっていない」と書いているか。蓋を刷る物から外したのに、古い蓋の記述が生きた文として残っていないか |

### 見直してもらった所（#35・2026-10-04 に直した角 = **前の板 fe90b1e6…**。3 回目の監査で済み: 基板は致命 0・重要 0／枠・蓋は重要 1 → 直した）

| 視点 | 何を |
|---|---|
| 基板（発注） | 電源スイッチの本体と縁 2.50・つまみが縁の内側・CPL の位置と向き（SW_PWR）・蓋のねじ穴 2 つ（非めっき・縁から 1.0・電池クリップのコートヤードを欠いたこと）・JLC が穴を嫌わないか |
| 基板（電気） | VBAT_IN の決まった形（裏を電池の下・ビア 2 個）・VBAT_SW の右の端と C_BAT の枝・右の角の GND のビア（スイッチの枠のランド 4 つ・C_BAT）・蓋のねじ穴の頭の円と裏の線 |
| 配線の置き直し | pcb/freerouted.json（線 100・ビア 17）が、前の板の SPI・595 どうし・電源の枝と同じか。`route_click.py --freeroute` の道（引き直して書き直す）は、**書き足しただけで回していない** |
| 枠・蓋 | 切り欠きのまわりの強さ（式で置いた断面）・蓋の腕のひずみの式と許容 1.0 % の出どころ・蓋を刷る向き・ひさしと溝が、上面を下にして刷れるか → **ひずみの式が腕の全長を使っていた（正しくは 1.64 %）。直した** |
| 試し刷り | 角の試し刷りが、本物と同じ所に物を置いているか・手順で見落としている所 |

### 軽微・承知しているもの（2 回目の監査 2026-10-04）

| 何 | 扱い |
|---|---|
| シルクが、テントしたビアの上を 46 か所またぐ | 見た目だけ。直さない |
| 厚くした壁が下穴の壁と面一（キャップの胴との隙 0.20） | ねじの試し刷りと本番の枠で、キャップが擦れないか見る |
| アンテナの空けた所のビアの柵が 2 辺だけ | 任意で GND ビアを 3〜4 個足せる（y≈147.3・x 27.5〜31）。RF の測定 P9 に任せる |
| パッドの無い小さな GND の島 2 つ・XIAO の裏の列のパッドの間の幅 0.34 の GND の指 3 本 | 害は無い |
| C_3V3 は高さ制限 1.45 のため実質 0805 だけ。C_BAT と C_3V3 は電源を切ったあとゆっくり放電する（HHKB の「53 秒リセットできない」と同じ型） | 部品を選ぶ前に O14 を読む |

### 軽微・承知しているもの（4 回目の監査 2026-10-04・差分。基板は変えない）

| 何 | 扱い |
|---|---|
| 「角の外は 1 本だけ」は正確でない: 変わった線は 9 本（角の中 8 本＋長い VBAT_SW。右の端が x 288.125 → 288.875）。差は x ≥ 287.6・y 127.9〜143.2 に収まる | 記録を直した（#36・状態・決定記録） |
| ねじの先と下穴の底: 名目で掛かり 2.4・底まで 0.4。ねじが +0.24 長く・基板が 1.44 厚いと 0.00（底に当たる） | P1「本番の枠で 1 本締めて見る」のまま |
| GND のビア (294.375, 141.625) が、スイッチの枠のランドの端から 0.20（同じ網・マスクで覆う）。手はんだのときに、はんだがそこへ吸われうる | 承知。手はんだは少なめのはんだで |
| 手はんだのこて先: MSK12C02 の図面 7.1 は 350 ℃以下・3 秒以内 | order-steps の手はんだの手順に書いた |
| つまみの出の公差は ± 0.2（± 0.1 ではない）。最悪の場合の余裕・ルーター切りのこと | P23・D4・order-steps の冒頭 |

### 軽微・承知しているもの（3 回目の監査 2026-10-04・差分。基板は変えない）

| 何 | 扱い |
|---|---|
| 角の中の GND の縫いのビアは置き直してある（8 個消えて 9 個足した）。角の外にも無視できる違いが 2 つ（ビア 1 個が 1 nm・ベタの塗りの差 2.6e-5 mm² 以下） | 「角のほかは前の板と同じ」は、線と部品の話。#35 の行に書き直した |
| 電池クリップのコートヤードを欠いた所は、KiCad がもう重なりを見ない（そこにある物: クリップの板の口の側の丸い端〔基板の 3.75 上〕・電池の道・**蓋の足**〔基板の上面から上の板まで。クリップの板の手前で終わる〕） | 将来そこに基板の部品を置くなら、自分で検査を書く（P24） |
| 蓋のねじ穴 H30・H31 は使っていない（蓋は道具なしの落とし込み式。穴は基板に残り、底のシートが塞ぐ） | ねじを入れない（電池の道を塞ぐ・蓋の足に当たる）。P24 |
| ~~蓋に 45.7° の下向きの面（山の斜面。直す前 1.68 mm²・いま 0.89 mm²）~~（前の差し込み式の蓋の話。その形はもう無い） | — |
| ~~電源スイッチの本体から縁まで名目でちょうど 2.500・つまみの先は縁の 1.05 内側~~（前の板の話。**いまは 1.75・0.30**: P23） | JLC に断られたら手はんだ（docs/order-steps.md の冒頭・§3） |

### 閉じたもの（試し刷りの段）

| # | 何 |
|---|---|
| ~~#10~~ | ~~この方式が刷れるか~~ ✅ 2026-10-03 利用者が刷った（docs/coupon-test.md の記入表） |
| ~~#11~~ | ~~角の部品の外形を置いた試し刷り~~ ✅ 組み立てのモデルで干渉を見た（tests/test_cckb_click_case.py）。実物の嵌め合いは P2・P22（2026-10-04 に、右手前の角の試し刷りと v2 を利用者が刷った） |
| ~~#12~~ ~~#13~~ ~~#14~~ ~~#20~~ ~~#21~~ ~~#23~~ | ✅ 2026-10-03 試し刷りの結果で閉じた（決定記録 2026-10-03-coupon-result） |
| ~~#16~~ | ~~枠を何枚に分けるか・基板との留め方・底~~ ✅ 決定記録 2026-10-03-board-and-case |
| ~~#19~~ | ~~`PLATE_MARGIN_X` ほか基板の段で決める値~~ ✅ 決めた（spec.py） |

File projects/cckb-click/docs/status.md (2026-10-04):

# cckb-click のいまの状態（2026-10-04）

**結論: 2026-10-04 に利用者が試し刷り v2 を刷って試し、3 つ決まった（決定記録 2026-10-04-knob-out-pilot）。
(1) ねじの下穴は φ1.6（基板の穴は変えない）。(2) 電源スイッチは 0.75 外へ = 基板を直した。(3) 電池の蓋は 3 つとも使えず → ねじで留める蓋を作ったが、利用者が「道具が要る蓋は使えない」と退けた → **道具なしで上から落とし込む蓋を作り、独立の見直しを受けて直した（v2・2026-10-05）。基板は変えていない**（決定記録 2026-10-04-cover-latch・絵 build/cckb-click/cover_latch.png。電池が押す力は耳と溝が受け、上へは 2 本の棒の先と枠の歯が留める。立体と G-code では成り立つ・**まだ刷っていない。計算は前の 4 つの蓋で外れた** → 蓋 3 つを並べた試し刷りで決める）。**この蓋は爪 1 つで開き、押す力も 2.2 N と小さい = 利用者の条件「わざと外したときだけ」は、形だけでは満たし切れていない**（open-gaps #34b）。
基板は右手前の角だけ引き直した（変わった線は 9 本 = 角の中 8 本＋長い VBAT_SW の右の端 0.75。差は x ≥ 287.6・y 127.9〜143.2 に収まる）。DRC は違反 0・未配線 0・警告 0。発注はまだ止めている。**

**正直に書いておくこと: 電源スイッチの本体は基板の縁から 1.75 mm で、JLC の実装の規約「部品の本体と基板の縁は 2.5 mm 以上」を満たさない**
（利用者の決定: 規約より使いやすさ）。JLC が載せないと言ったら、その 1 個だけ手はんだにする（7 か所・基板は変わらない。docs/order-steps.md の冒頭）。

止めているのは 3 つ: 頼み方を決めて画面で確かめる（#31。電源スイッチを JLC が載せるかも）・CR1632 での起動の試験（#32）・電池の蓋（#34b。道具なしの落とし込み式 v2。基板は変えない。蓋の試し刷り〔蓋 3 つ〕を刷って、擦る・振る・落とすを試し、利用者が「この蓋でよい」と言えば閉じる。足りなければ、ばねを樹脂でなくする道を選ぶ）。
ねじ（#33）・つまみの位置（#34）・直した板（b442b865…）の独立した見直し（#36）は閉じた。

**4 回目の監査（2026-10-04・前の板 fe90b1e6… との差分・HEAD 5f8cf06）の結果: 致命 0・重要 1・軽微 5・「差分については発注してよい」。**重要 1 件は記録の誤り: つまみの出の公差は ± 0.1 ではなく、図面の未注の公差の ± 0.2（図面を自分で読んだ）。最悪の場合、つまみの先は基板の名目の縁に届きうる（余裕 +0.025〜−0.025）。枠の外面には出ない（≒ +0.10〜+0.13）。JLC の FAQ Q14 は「面付けした基板は実装の後にルーターで切り離す（公差約 0.2）」と書く。この板は面付けの上限を超えるので当てはまるかは未確認（普通は外形は実装の前に切る）。当てはまる場合に限り、最悪はルーターがつまみに触れうる。**届いたら、つまみの先の傷と動きを見る。**軽微 5 件は open-gaps「軽微・承知しているもの（4 回目の監査）」。
`projects/cckb/`（発注できる状態の CCKB）には手を入れていない。

**2026-10-04 の 2 回目の直し（試し刷り v2 の結果）**（絵は build/cckb-click/knob075_before_F／B.png と knob075_after_F／B.png・main_corner.png・assembly_main/corner_top／front.png）

| 何 | 前（板 fe90b1e6…・3 回目の監査の板） | いま（板 b442b865…） |
|---|---|---|
| 電源スイッチの本体の縁から基板の縁まで | 2.50（JLC の規約 2.5 以上を満たす） | **1.75（満たさない）** |
| つまみの先 | 基板の縁の 1.05 内・枠の外面の 1.35 内（利用者: 奥すぎる） | **基板の縁の 0.30 内・枠の外面の 0.60 内**（入・切とも。外へ出る物は無い） |
| つまみの切り欠き | 幅 10・外の角を 1.0 落とす | **内側で幅 10・外面で 14.8（片側 2.4 ずつ広がる）・内側の上の縁を 2.0 斜めに**（利用者が v2 の (ii) で触った形） |
| 指先の代わりの球（半径 7.5・仮定）が、つまみの先より奥へ入る量 | −0.22（新しい切り欠きでも −0.03） | **+0.16** |
| 切り欠きの内側の縁を 10 N で押したときの応力（厳しい見方・上限 38 MPa） | 7.3 MPa | **20.4 MPa**（厚い屋根の全幅で見ると 3.5） |
| 入の向き・枠の入の印 | つまみを奥 = 入 | **同じ**（印は斜面のすぐ内の平らな上面へ。高さ y は同じ） |
| ねじの下穴 | φ1.8（空回りした） | **φ1.6**（22 個とも。線が空ける径: ふつうの壁 1.54・薄い壁 1.49〜1.50 = 利用者が締めた切れ端と同じ） |
| 電池の蓋 | 差し込み式（刷る物） | 差し込み式は使えなかった → ねじ 2 本で留める蓋（道具が要るので退けた）→ **道具なしで上から落とし込む蓋**（基板は同じ b442b865…・穴 H30・H31 は使わない・枠の口を幅 19.0 に。下の §2・§4） |
| JLC の頼み方 | Economic／Standard | 同じ ＋ **電源スイッチを断られたら手はんだ** |
| 配線（角の外） | — | 変わった線は 9 本（角の中 8 本＋長い VBAT_SW の右の端 0.75）。差は x ≥ 287.6・y 127.9〜143.2 に収まる（線・ビア・部品・ルール領域・ベタを前の板と突き合わせた） |
| 厚さ・外形 | 8.1・291.75 × 101.25 | 同じ |

以下の「3 回目の監査」「2026-10-04 に角で変えたこと」は、**前の板（fe90b1e6…）までの経緯**。

**3 回目の監査（2026-10-04・前の板との差分）の結果**

| 何 | 結果 |
|---|---|
| 基板（板 fe90b1e6…） | **致命 0・重要 0。板は変えていない**（sha256 は同じ）。発注の門の #35 は済み |
| 電池の蓋（刷る物） | **重要 1 → 直した**: ばねのひずみの式が腕の全長 5.5 を使っていたが、壁の下面が最後まで当たるのは山の付け根の側の端（付け根から 4.0）で、正しくは 1.64 %（許容 1.0 %）。山を腕の先の 0.8 に縮め、腕を 6.3 に延ばして、効く長さ 5.5・ひずみ 0.87 %・引き抜く力 約 1.6 N（腕 1 本 0.43 N）。ひずみは枠と蓋の立体から測って出すようにした。**（この蓋は刷って使えず、ねじで留める形に変えた。ばねの計算・検査・絵 cover_spring.png は消した）** |
| 軽微（記録だけ） | 角の中の GND のビアの置き直し・欠いたコートヤードの所は KiCad が見ない・蓋のねじ穴のねじは電池の道を塞ぐ・蓋の 45.7° の面・スイッチの縁 2.500（open-gaps「軽微・承知しているもの（3 回目の監査）」） |

**2026-10-04 の 1 回目の直しで角で変えたこと**（絵は build/cckb-click/switchcover_before_*.png と switchcover_after_*.png。**「直した後」の列は板 fe90b1e6… の値。スイッチの位置と蓋は、上の 2 回目の直しで変わった**）

| 何 | 前（板 4dc68901…） | 直した後（板 fe90b1e6…） |
|---|---|---|
| 電源スイッチの本体の縁から基板の縁まで | 0.75 | **2.50**（JLC の規約 2.5 以上） |
| つまみの先 | 枠の外面から 0.40 外・基板の縁から 0.70 外 | **枠の外面の 1.35 内側・基板の縁の 1.05 内側**（入・切とも） |
| つまみの動かし方 | 外へ出た先を押す | 枠の右の壁の切り欠き（幅 10・上まで抜き）に爪を入れる |
| 電池の口 | 開いたまま | 差し込み式の蓋（枠だけで留まる・道具なし・無くても使える） |
| 蓋のねじ穴 | 無い | 2 つ（H30・H31。使わない。取っておく） |
| 電池の＋の線（VBAT_IN） | Freerouting が引いた | 決まった形（直角の 8 区間・ビア 2 個） |
| SPI・595 どうし・電源の枝 | Freerouting が引いた（引くたびに変わる） | 監査した板の線を置き直す（線 100・ビア 17。変わらない） |
| JLC の頼み方の選択肢 | Economic／電源スイッチだけ手はんだ／Standard | Economic／Standard（手はんだの案は要らなくなった） |
| 厚さ・外形 | 8.1・291.75 × 101.25 | 同じ |

**1 回目の監査で直したこと**（決定記録 2026-10-04-audit-1。絵は build/cckb-click/audit/ の before_* と after_*）。そのあと 2 回目の監査（板 4dc68901…）は致命 0・重要 0 だった

| 何 | 前 | いま |
|---|---|---|
| 止めに当てた電池の缶の縁から、表の銅まで | 0（真上） | 0.72（表の銅を置かない範囲を奥へ 1.26 広げた） |
| 電池の側・レールの側に容量を足す場所 | 無い | 載せないコンデンサのランド 2 つ（C_BAT・C_3V3。JLC は載せない） |
| 手前の継ぎ目のそばのねじ | 14.3・21.4 mm 先 | 予備の穴 2 つ（継ぎ目から 6.5） |
| ねじの下穴のまわりの樹脂のいちばん薄い所 | 0.49 | 0.70（幅の広いキーの脇の 3 本は 0.49 のまま） |
| パスコンから 595 の GND までの戻り | 31.6 mm（U2） | 22.3 mm（GND の線で引いた。まっすぐなら 11.1） |
| 表の GND でビアからいちばん遠い所 | 17.2 mm | 13.3 mm |
| 電池電圧の線と行の線の間 | 0.76 mm | 1.8 mm |
| ねじが割れないかを先に見る手段 | 無い | ねじの試し刷り `coupon_screw_plate.stl` |

## 1. CCKB と比べて

| | cckb-click | CCKB（cckb-v2・プレート無し） |
|---|---|---|
| 厚さ（机からキャップの上面） | **8.1 mm**（底のシート 0.5・基板 1.6・枠の上面まで 5.0・キャップの出 1.0） | 14.2 mm |
| 重さ | **約 192 g**（下の表） | 刷る物だけで約 95 g（基板・スイッチ・ねじを足した合計は CCKB の側に記録が無い。**比べられるのは刷る物だけ**） |
| 刷る物 | 4 枚（枠 2・キャップ 2）＋ 電池の蓋 2 個・約 73 g・約 7h58m | 13 個・約 95 g・約 12h13m |
| キー | 62（配列は同じ layout.json） | 62 |
| 回路 | 同じ（XIAO nRF52840・74LVC595 ×2・BAT46W・CR1632） | — |

**重さの内訳（click_case.py の計算。量っていない）**

| 物 | 重さ | 出どころ |
|---|---|---|
| 枠 2 枚 | 28.5 g | スライスした材料の量 × 1.24 |
| キャップ 62 個 | 44.4 g | 同じ |
| 基板 | 86.4 g | 体積 × FR-4 の比重 1.85（銅・はんだ・穴は入れていない） |
| スイッチ 62 個 | 7.4 g | 1 個 0.12 g と**置いた**（仕様書に重さが無い） |
| XIAO・電池・クリップ・ダイオードほか | 6.0 g | XIAO 3.0・CR1632 1.8（Energizer のデータシート）・ほか |
| ねじ 20 本 | 1.8 g | 1 本 0.09 g と**置いた** |
| 電池の蓋 | 0.2 g | 立体の体積 × 1.24（刷る板は、予備を含めて 2 個で 0.40 cm³ = 約 0.5 g） |
| 底のシート | 17.1 g | 厚さ 0.5・比重 1.2 と**置いた**（材料は利用者がまだ決めていない） |
| **合計** | **約 192 g** | |

## 2. 出来た物

| 何 | どこ | 何で確かめたか |
|---|---|---|
| 基板 | `projects/cckb-click/pcb/cckb-click_main.kicad_pcb`（291.15 × 100.65・2 層）。sha256 は下の §3 | kicad-cli の DRC **違反 0・未配線 0・警告 0**（下限をこの板のビア φ0.6・穴 0.3 に上げた上で）。発注道具（Fabrication Toolkit）の出力: BOM 7 行・CPL 133 行（全部表）。JLC の部品データで置き直して板のパッドと合う（電池クリップは外形で向きも見る） |
| 足跡 | lib/keyswitch.pretty/SW_Alps_SKRA_6.2x6.2・lib/cckb-click.pretty/（電池クリップ・電源スイッチ・M2 の穴・載せないコンデンサのランド） | Alps の図面・各データシートの寸法と、EasyEDA の部品データ（tests/fixtures/easyeda/footprints_click.json） |
| 枠 2 枚・キャップ 62 個 | `projects/cckb-click/click_case.py` → build/cckb-click/*.stl | 組み立ての立体で干渉 0（置く・押し切る・傾ける）・下から入れられる・サポート無しで刷れる・A1 mini に置ける。4 枚をスライスし、枠の下穴 22 個の径を G-code で測った（docs/printing-guide.md） |
| 電池の蓋 | `click_case.cover_solid` → build/cckb-click/cover_battery.stl（予備を含めて 2 個）・絵 **cover_latch.png** | **道具なし・上から落とし込む（v2）**（決定記録 2026-10-04-cover-latch）。電池が手前へ押す力は、蓋の左右の耳（45° のくさび）が枠の溝で受ける。上へは、手前の面の 2 本の棒の先が枠の歯の下に直角の面で当たる。耳の裏のつぶれる筋が、がたつきを取る。開けるには、棒を 2 本とも爪で押し込みながら持ち上げる。立体: 当たらない・面一・蓋を付けると電池は 10 の向きのどれにも出ない・棒 1 本を押しても片側が上がるのは 1.13（上限 1.5）・掛かりを立体で測る・蓋の胴の応力を立体の断面から。G-code: 切れ目と、棒の先の下の隙に線が通っていない。**刷っていない。爪 1 つで開く・押す力 2.2 N・落下の余裕 1.9 倍・胴の強さの余裕 1.5 倍**（open-gaps P21）。前の差し込み式（v1 と v2 の 3 つ）は使えなかった・ねじで留める形は退けた |
| ねじの試し刷り | 同じ → build/cckb-click/coupon_screw_plate.stl・絵 coupon_screw.png | **済み**（2026-10-04: φ1.8 では空回り）。いま出る STL は、本番の枠と同じ下穴 φ1.6 |
| 角の試し刷り = **蓋の試し刷り** | 同じ → build/cckb-click/coupon_corner_plate.stl・**coupon_corner_plate_n04.gcode.3mf**・絵 coupon_corner.png・**coupon_cover_howto.png**・slice_cover.png | 前の形は**済み**（2026-10-04: つまみは奥すぎる・蓋は留まらない）。**いま出るのは、新しい口と、落とし込み式の蓋 3 つ**（歯との上下の隙 0.2／0.3／0.4・つぶれる筋 0.40／0.50／0.60。docs/coupon-test.md 10 章・約 41 分・**まだ刷っていない**）。スライスして、蓋の切れ目に線が通っていないことを見た（`tools/slice_cover.py`） |
| 試し刷り v2 | `projects/cckb-click/click_coupon_v2.py` → build/cckb-click/coupon_v2_plate.stl・絵 coupon_v2_howto.png | **済み**（2026-10-04 に利用者が刷った: 下穴は φ1.6・スイッチは (ii)・蓋は 3 つとも使えない。docs/coupon-test.md 8 章「結果」）。**いま出るのは A（ねじ）と B（つまみ）の 8 個だけ**: 蓋 3 つ（C）の形は、蓋をねじで留める形に変えたときに消した。刷った板の G-code は build/cckb-click/coupon_v2_plate_n04.gcode.3mf に残っている（`tools/slice_v2.py` を回すと上書きされる） |
| 組み立ての絵 | build/cckb-click/main_sections.png（断面 6 枚）・main_top.png・main_tilt.png・**main_corner.png（右手前の角）**・assembly_main/cckb-click.blend（Blender で回せる。蓋も入っている）・`_assembled.png`・`_exploded.png`・**corner_top.png・corner_front.png（角を上と手前から）**・基板の角の前と後 **knob075_before／after_F・B.png**・**cover_latch.png（電池の蓋のしくみ・開け方・閉め方・電池の替え方）** | 自分で見た |
| たわみ | `projects/cckb-click/click_stiffness.py` → build/cckb-click/main_stiffness.png | 断面は作った枠を切って測る（検査）。材料の値は一般値 |
| ファーム | config/boards/shields/cckb_click/・build.yaml | `foundry.check_zmk_config` が「問題なし」。overlay に SPI の MISO のプルダウンを足した（ボードの pinctrl の写しと突き合わせ）。**CI でのビルドは push していないので未確認**（open-gaps P19） |
| 文書 | docs/shopping-list.md・order-steps.md・assembly-guide.md・printing-guide.md・coupon-test.md・decisions/2026-10-03-board-and-case.md・2026-10-04-audit-1.md・2026-10-04-switch-cover.md・2026-10-04-knob-out-pilot.md・**2026-10-04-cover-latch.md** | — |

build/ は git に入れていない。無ければ `click_case.py`・`click_stiffness.py`・`tools/kb cckb-click render` で出る。

## 3. 基板

| | |
|---|---|
| スイッチ | Alps SKRAAWE010 ×62（表）。幅の広いキー 11 個には左右に空きランド 22 個（並列。載せない） |
| 行列 | CCKB と同じ（行 5 = XIAO・列 15 = 595 ×2）。ダイオードは表・キーごと |
| 配線 | 行（表）・列（裏）・595 からの束・電池からの電源・**電池の＋**・電池電圧の線・パスコンの GND の戻り・C_3V3 への線は**決まった形**で引く（click_routes.py）。残り（SPI・595 どうし・電源の枝）は、**監査した板（4dc68901…）で Freerouting 2.3.0 が引いた線を置き直す**（pcb/freerouted.json。板を直しても形が変わらない。検査が板と突き合わせる） |
| GND | 両面ベタ。GND のビア 812 本。ビアから銅の上でいちばん遠い所: 表 13.3 mm・裏 14.2 mm（595 のいるキーの中も同じ上限 15 の内） |
| 載せないランド | C_BAT（VBAT_SW–GND・右の角・電源スイッチの左・背 2.8 まで）・C_3V3（V3V3–GND・Z のキーの中・背 1.45 まで）。1206 と 0805 の両方が載る。JLC は実装しない |
| 電池 | CR1632。クリップ MY-1632-03-R（背 4.0）を右手前の角に。−は基板の裸の銅 |
| 電源スイッチ | MSK12C02。右手前の角・**本体は基板の縁から 1.75**（JLC の規約の 2.5 を満たさない）・つまみは右向きで、先は基板の縁の 0.30 内側（枠の切り欠きの中・枠の外面の 0.60 内）。JLC に載せてもらう形で頼み、断られたら手はんだ |
| 留め穴 | 外周 20（M2・枠に下からねじ。基板の縁から 2.1）＋ 手前の継ぎ目の両側の予備 2 ＋ 中 8（既定では使わない）＋ **電池の口の中の 2（H30・H31。使っていない: 蓋をねじで留める形のために開けた穴）** |
| sha256 | `b442b865a9694e513339d6b2835cdb42e41a503cb5e2302871f9a265e981ad3e`（2026-10-04 に電源スイッチを 0.75 外へ動かした後。**4 回目の監査で見た板**〔致命 0・重要 1・直した〕。3 回目の監査の板は fe90b1e6…・2 回目は 4dc68901…・1 回目は f44c5825…） |

## 4. 枠とキャップ

- **枠**は 291.75 × 101.25 × 5.0。A1 mini に入らないので左（156.4）と右（140.0）に分ける。継ぎ目はキーの縁に沿った階段。継ぎ目のリブは左が持つ
- **留め方**: 基板の下から M2×4 の低頭ねじ 20 本を、枠の壁の下穴 **φ1.6** に直にねじ込む。ナットもインサートも無い。左右の枠は基板が繋ぐ。
  下穴のまわりの樹脂は内側 0.8・外側 1.6（幅の広いキーの脇の 3 本は斜めに 0.59）。**利用者が試し刷り v2 で締めて、空回りしないことを見た径**（ふつうの M2×4 の小ねじで。
  締め直せる回数は分かっていない: open-gaps P1）
- **キャップ**は枠の下から入れ、基板をかぶせる（試し刷りで決めた形: 穴 17.05 角・つば・隙 0.20）
- **電池の交換**: 枠は分解しない・道具は要らない。**蓋を開ける**（手前の面の 2 本の棒を、爪で 2 本いっしょに押し込みながら、上へ持ち上げる）→ 右手前の壁の口から、爪を掛けて電池を手前へ滑らせて出す。入れるときは口から押し込み、蓋を上から押して閉める。
  電池は止めに当たる所に座る（手前の縁が枠の外面から 1.71 奥。切り欠きから上面が 2.79 見える）
- **電池の蓋**: **道具なし・上から落とし込む（v2）**。蓋の左右の耳（45° のくさび）が、口の左右の壁の溝に入り、電池が手前へ押す力を受ける。蓋の手前の面の 2 本の棒の先が、
  口の手前の角の歯（枠）の下に入って、上へ抜けない。上面は枠と面一・手前の面は外面の 0.25 内。枠の口は幅 19.0（歯の間 17.0）。**基板は変えない**（穴 H30・H31 は使わない）
  （決定記録 2026-10-04-cover-latch）。**電池を手前へ止める物は蓋だけ = 蓋は必ず付ける**（open-gaps P25）。**爪 1 つで開く造り**（形では防げなかった: open-gaps P21）。まだ刷っていない
- **電源スイッチ**: つまみは枠の外へ出ない（先は枠の外面の 0.60 内）。右の壁の切り欠き（内側で幅 10・外面で 14.8・上まで抜き・内側の上の縁は斜め）から、
  指か爪で奥（入）・手前（切）へ 1.6 mm 動かす。切り欠きの内側は、屋根を厚くして塞いである（斜めに落とした後、内側の面で厚さ 1.2）。枠の上面の丸い印が入の側
- **USB**: **左手前の角**（口は左の縁を向く）。XIAO の上は枠の屋根（下面 3.7）。プラグの形を立体で当てて干渉 0
- **底**: 基板の下面に厚さ 0.5 のシートを貼る（ねじの頭の所は穴。使っていない穴 H30・H31 の所は塞ぐ）。材料は利用者が決める
- **たわみ**: 柱の間でリブを打鍵の力（3 N）で押して 0.026 mm・強く 10 N で 0.086 mm（誤入力までの余裕 0.1）。10 N の余裕は薄い。
  **0.086 は両端が固く止まっている場合。**端が回る場合は 4 倍の約 0.34（端の条件で 0.086〜0.34。実物でしか分からない: open-gaps #4）

## 5. 機械で確かめたこと／確かめていないこと

**確かめた**（それぞれ、故意に壊すと落ちることを見た）

- 足跡のパッドが図面・JLC の部品データと合う。CPL の向きと位置（133 個）
- DRC・未配線・JLC の最小の寸法・アンテナとねじの頭と電池の禁止域・GND のビアまでの距離
- 回路が CCKB と同じ網になっている・最小の電流（打ち止め 2.0 V で約 109 µA ＞ 定格 10 µA）
- 枠・キャップ・部品・スイッチ・ねじ・電池・USB プラグの干渉（62 キー × 置く／押し切る／傾ける）。載せないコンデンサのランドは、載せてよいいちばん大きな部品で
- 電源スイッチ: つまみの先が基板の縁の 0.30 以上内側（名目。**図面の公差 ± 0.2 を入れると最悪で +0.025〜−0.025**）・枠の外面から出ない・本体と縁が記録の 1.75（板の突起の穴から。**最初の位置〔つまみが枠の外へ 0.40〕・0.1 外・前の位置、のどれでも落ちる**）・
  入の向き（端子の網）・爪の入る場所（つまみの脇 3.0 幅・上と横へ開いた立体）に枠も部品も無い・指先の代わりの球がつまみの先より奥へ入る（+0.16）・
  切り欠きの内側の縁の強さ（断面を枠の立体から測る）・入の印が平らな上面にある
- ねじの下穴: 22 個とも φ1.6（枠の立体）・刷る線が空ける径が、利用者が締めた切れ端と同じ（本番の枠の G-code）
- 電池の蓋（落とし込み式 v2）: 枠・電池・クリップ（図面から作った形）・基板・部品・シート・ねじ・近くのキャップに当たらない・面一・足が基板に着く・
  電池は手前へ 0.23 で蓋の足に止まる（棒を切り取った蓋でも）・蓋を付けると電池は 10 の向きのどれにも出ない・棒を押し込まない蓋は平行にも回しても出てこない・
  棒を 2 本とも 0.85 押し込むと上へ抜ける・**棒 1 本だけでは抜けず、片側が上がるのは 1.5 まで**・掛かりと胴の応力を立体で測る・ベッドの面の縁の面取り・つぶれる筋・手前の面をベッドにサポート無し。壊すと落ちることも見た。蓋の切れ目は G-code で見た
- 蓋のねじ穴（H30・H31。使っていない）: 板にある・頭の円に裏の銅が無い・表は電池の道の中。SPI・電源の枝が、監査した板の線と同じ
- 電池の缶の縁から表の銅まで・シルクの図形とマスクの開口・パスコンの戻りの道のり・電池電圧の線と行の線の間・ねじの下穴のまわりの肉・電池クリップの向き（CPL）
- キャップを下から入れられる・電池を出せる・サポート無しで刷れる・ねじの周りの肉
- ZMK の設定の整合（check_zmk_config）

**全検査（2026-10-04・電源スイッチを 0.75 外へ・下穴 φ1.6 の後・`REQUIRE_KICAD=1 .venv/bin/pytest tests -q`）**: **701 passed・failed 0・飛ばし 0**（23 分 19 秒）。
CCKB と HHKB の検査もこの中で緑。警告 54 件は前からある CCKB のケースの物（数は同じ）。`foundry.check_zmk_config` は「問題なし」（ファームは触っていない）。
1 回目に回した全検査は 700 passed・failed 1（自分で足した検査の、体積の見積もりの上限が外れていた: 切り欠きのまわりの枠の体積 308 mm³ に「200 未満」と書いた。直して回し直したのが上の数）。
**蓋を落とし込み式 v2 にした後（2026-10-05）に回したのは、全検査ではない**: `.venv/bin/pytest tests -q -k click`（遅い検査も）**241 passed**・`tests/test_meta.py tests/test_gate.py tests/test_regression_hhkb.py` **114 passed**。基板は触っていない（sha256 b442b865… のまま）。
本番の 4 枚のスライス（`tools/slice_main.py`。右の枠の口を変えた後にもう一度）は「OK 問題 0 件」（下穴 22 個の径も）。蓋と蓋の試し刷りのスライス（`tools/slice_cover.py`）も「OK 問題 0 件」。発注の門は「閉 — #31・#32・#34b」（#36 は 4 回目の監査で閉じた）（`tools/kb cckb-click gate`）。

**確かめていない**

- 定数を壊す検査（foundry.mutate）は、基板と枠の段で足した定数には回していない（open-gaps P14）
- **JLC が電源スイッチを載せるか**（本体と縁 1.75。注文してみるまで分からない）
- ねじを何回締め直せるか（利用者が締め直した回数を聞いていない）・スリムヘッドのねじでの手応え・本番の枠に実際にねじを入れること
- **電池の蓋を刷っていない**: 押し下げるだけで留まるか・擦る／振る／落とすで外れないか・爪で開けられるか・棒が何回もつか・枠の歯が折れないか・筋の固さ。**爪 1 つで開く造りが、利用者の条件に足りるか**。落下の計算は、棒を 1 本の振り子と見た近似。本物のクリップ・電池との隙は、基板が届いてから
- `route_click.py --freeroute`（Freerouting で引き直して freerouted.json を書き直す道）は、書き足しただけで回していない
- ZMK の実際のビルド（push していない）
- Bambu Studio の画面・JLC の注文画面
- 実物でしか分からないこと全部（下の §7）

## 6. 利用者が決めること

| # | 何 | いつ |
|---|---|---|
| D1 | 底のシートの材料（厚さ 0.5 を仮定。docs/shopping-list.md に候補） | 買う前 |
| D2 | 基板の表面処理: HASL か ENIG か（電池の −が当たる面・スイッチの座り）。**勧めは ENIG** | 発注のとき |
| D4 | **JLC の実装を Economic にするか Standard にするか**（docs/order-steps.md §2-1 の表。リフローの温度の余裕と費用。差は 約 ＋$20〜$28） | 発注のとき |
| #34b | **電池の蓋: 蓋の試し刷り（docs/coupon-test.md 10 章・約 41 分・蓋 3 つ）を刷って、擦る・片方だけ押す・振る・電池を押す・落とす・開け閉めを試し、「この蓋でよい（3 つのうちどれか）」か「この留め方では足りない」を言う。**基板は変えない。足りなければ、磁石か金属のばねを買う・硬貨で回す留め・形から考え直す、のどれかを選ぶ | **発注の前** |
| P1 | **試し刷り v2 で、ねじを何回締め直したか**を教えてください（記録が無い） | いつでも |
| #31 | **注文画面で、電源スイッチ（SW_PWR）が載るかを見る。**断られたら BOM と CPL から外して手はんだ（決めてある。docs/order-steps.md の冒頭） | 発注のとき |
| ~~O15~~ | ~~蓋のねじ穴を使うか~~ ✅ 使う（2026-10-04） | — |
| O14 | 載せないコンデンサのランドに部品を足すか | #32 の結果で |
| D3 | 予備のスイッチを何個買うか（空きランドに足すなら最大 22 個） | 発注のとき |
| — | M2×4 の低頭ねじ（頭 φ4.0 × 0.5 以下）を買う。**頭の厚い普通のねじは底から出る** | 組む前 |
| — | 本番の枠とキャップを刷るか（基板が無くても刷れる。docs/printing-guide.md） | いつでも |
| — | CR1632 の起動の試験（#32。買う物なし・約 1.5 時間。CCKB と共通） | 発注の前 |

## 7. 基板が届くまで分からないこと（主な物。全部は open-gaps.md）

- リフローのあと、スイッチのステムの高さ（3.4 ± 0.2）のばらつきで、キャップに押されっぱなしのキーが出ないか（#2）
- 音と感触（#3）・チャタリング（#6。いま 押す 5 ms・離す 10 ms）・幅の広いキーの端を押したときの反応（#5）
- 枠の下穴（φ1.6）で、ねじを何回締め直せるか（P1）・左右の枠の継ぎ目で、キャップが挟まらないか（P3）
- 電池を指で出せるか（P2）・電池の −が裸の銅で安定して触れるか（P10）・**蓋が本物の電池クリップ・電池に当たらずに入るか**（P21）
- 電源スイッチの入の向き（P7）・本物のつまみを切り欠きから指で動かせるか・鞄の中で勝手に切り替わらないか（P22）
- 電波（P9。アンテナのすぐ上に枠の屋根がある）
- スリープの電流（P17）・USB を挿している間の電池への逆流（P18）・金属の机の上での電波（P9）

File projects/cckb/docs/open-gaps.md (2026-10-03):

# 実機・要求とまだ違うところ（cckb）

**差があること自体は悪くない。悪いのは、差があるのに気づけないこと。**

ここは「まだ解けていないもの」「受け入れた差」の台帳。`python -m foundry.gate cckb`
（発注の門）が下の「★ 発注をせき止めているもの」の表を読み、取り消し線の無い行が
残っていれば止める。

**書き方の約束**（HHKB で実際に起きたことが理由）:

- 節を直したら**同じ変更で一覧も直す**。一覧を見る人と節を書く人は別人になる
  （解決済みが 4 日間「未解決」で残った）。行の頭だけ「済」にして次の一手を古いまま
  残さない（2 週間残った）
- 閉じるときは**行を消さずに取り消し線**を引き、何で確かめたか（外の事実か・自分の
  生成物か）と「故意に壊して検査が落ちることを確かめた」を書く。次の一手は「無し」
- 見出しは目次のアンカーなので書き換えない。決着は見出しの直下に `> **✅ 日付 …**`
- 番号は発見順。衝突したら改番して、その旨を書く
- 「構造上できない」で閉じるときは、**その構造**を書く（前提が動いたら再評価できるように。
  HHKB #32 は前提が消えたのに 5 日間「不成立」として人を止めた）
- 解けないと結論したあとで先へ進むなら `### 承知して発注する #N` を立て、誰が・いつ・
  駄目だったとき何を作り直すかを書く。**最初に書くものではない**

---

## いま残っているもの（2026-09-24 に棚卸し）

### ★ 発注をせき止めているもの

| # | 何 | 次の一手 |
|---|---|---|
| #1 | CR1632 で起動・スリープ復帰できるか（設計書 D4。新品で内部抵抗 約 26Ω） | 利用者が task-10a-coin-cell-startup.md を実施（2026-09-25 に作り直した: 可変電源＋直列抵抗で XIAO の起動に要る電圧 V_boot(R) を測り、電池とダイオードはデータシートで紙の上に載せる。新品の電池で 1 回だけ突き合わせる。買う物なし・約 1.5 時間）。合格は手順書 §6 の (a) 21℃ の新品と (b) −10℃ の新品。不合格なら D4 を CR2032 に替える |
| ~~#2~~ | ~~右の角の断面（ホルダ BS-16-B4AK003＋電池＋ふた）と左の角（XIAO・USB）~~ | 無し。2026-09-24 に境界を決めた（decisions/2026-09-24-interface.md）。平面図・断面図 `build/cckb/interface_corner_left.png`・`interface_corner_right.png` を描いて見た。外の事実: ホルダ・電源スイッチはデータシート、XIAO は公式 STEP を検査が毎回測る。`tests/test_cckb_interface.py::test_the_corner_parts_fit_their_corners` が角の部品・壁・ふた・隣のキャップ・USB の口を見る（故意に壊す 10 通りで落ちることを確認: `test_the_corner_check_notices_a_break`） |
| ~~#3~~ | ~~ケース（**トレイ**・角のふた 2・滑り止め）と組み立て検査・スライス~~ | 無し。2026-09-24 ケースの段（decisions/2026-09-24-case.md）: 全 17 STL を A1 mini の設定でスライス 17/17 成功（統合の後に出し直して再確認）。組み立て（**発注する配線済みの板 pcb/cckb_main.kicad_pcb**〔外形と逃げ穴は Edge.Cuts・穴はパッド・XIAO／ホルダ／電源スイッチは板のフットプリントの位置〕＋買う物＋USB プラグ・机）で B-rep の干渉 0・入れる経路・留め方・肉厚・継ぎ目を tests/test_cckb_case.py が見る（各々を故意に壊して落ちることを確認）。統合で出た 2 つの赤（トレイの柱と裏の部品・電源スイッチの二重）は組み立てモデルの誤り（穴 H_LID を部品に数えた・電源スイッチをコートヤードの箱と図面の形で二重に置いた）で、ケースも基板も動かしていない（.superpowers/sdd/cckb-autonomy/integration-report.md）。嵌め合いの実物での確かめは P8 |
| #4 | 基板の完成（XIAO・595・電源の配置、配線、GND、発注データ） | **2026-09-24 配線・独立監査（A〜F）・監査の直し（裁定 R1〜R7）まで済み。発注前の人の確認が残る。**板 `pcb/cckb_main.kicad_pcb`（`projects/cckb/tools/route_pcb.py` が未配線の板から作る）: DRC 違反 0・未配線 0・警告 5（当時。silk_edge_clearance 3・npth_inside_courtyard 2 は理由つき。いまは下の置き換えで警告 3）。監査の直し（決定記録 `decisions/2026-09-24-audit-fixes.md`）: パッドの中の縫いのビアを根本から無くした（R1）・**電源スイッチは手はんだ**に（R2。BOM 5 行・CPL 69 行）・XIAO の裏の露出パッド 8 個の下の表の銅を 0 に（R3）・H3 のインサートの下の表の銅を 0 に（R6）。**2 回目の監査（裁定 S1〜S3）**: 金属が当たる 10 か所（ナット 9・H3 のインサート）全部に禁止域 `METAL_KEEPOUT`（CS を H5・H6 のナットの下から外した。配線は CS の 1 本だけを置き直し、ほかの網は前の板と同じ）・D_PWR の既定を BAT46W に（S2・**O12 の利用者の判断**）・手はんだの部品のパッドからペーストを外した・XIAO のパッド内ビア φ0.8。Fabrication Toolkit（`-t`）の CPL を JLC の部品データで置き直して板のパッドと比べる検査（69 個・0.09mm 以内）。**2026-09-24 電源スイッチを SS-12D00G3（表・スルーホール）に置き換え**（決定記録 `decisions/2026-09-24-power-switch.md`）: SW_PWR と BT1 を動かし、網 VBAT_IN・VBAT_SW の右の角だけ引き直した（ほかの 88 網は前の板と同じ）。位置決めの穴が無くなり npth_inside_courtyard を下げるのをやめた → DRC 違反 0・未配線 0・**警告 3**（silk_edge_clearance 3）。BOM 4 行・CPL 69 行は同じ。**残り**: fab-checklist §1（JLC の配置プレビューで U1/U2 の 1 番・ダイオードの帯）と §3（ピン配置を独立した 3 視点で）。判断は O11（A-4 を足すか）と O12（D_PWR の品番）——どちらも既定があり、門ではない（order-steps・status と同じ閉じ方）。引き継ぎ `docs/pcb-routing-handover.md` |
| ~~#5~~ | ~~ファームを CI でビルドできない（GitHub のリモートが未設定）~~ | 無し。2026-09-23 に公開リポジトリ ms0216/keyboard-foundry を作り、CI で cckb の .uf2（423KB）のビルドに成功（外の事実: GitHub Actions の実行結果） |
| ~~#6~~ | ~~**Choc V2（`cckb-v2` の枝）の見本で、基板に効く所を確かめる**（決定記録 2026-09-25-choc-v2 §10-5・§10-9）: 静音・標準の下面の突起が位置決めの丸穴 φ2.1 に入るか（V13）・スタビの箱が箱の穴（6.0 × 8.0・x の隙は片側 0.1）に入り、爪が基板 1.6（最大 1.76）に掛かるか（V3）・スタビのナットの胴がねじの穴 φ3.0 に、爪が φ4.0 に入るか（**きつい側に開けた。入らなければ手でリーマ・やすりで広げる。穴の中心から 2.6 は GND のベタのほかに銅が無い**）。スタビのねじ・爪の長円 16 個が JLC の長円の比を満たさない（V2 監査 C 重要 1）・スタビに関わる監査の所見（C 軽微 1・2・E 重要 1〜3・E 軽微 2・C 軽微 4 のスタビのコートヤード） → **2026-09-26 閉じた**: 利用者がいまのねじ留め（遊舎工房 A050001-01-1）に決め、販売者の足跡（実物の実測）を正にして丸 φ3.0 / φ4.0 を支点 ±11.9 に（§10-9。板 5f02d2b0・DRC 違反 0・未配線 0・警告 0）。外の事実: 販売者の足跡のファイル（docs/references/）と販売者の回答（足跡は実測・図は参考程度）。発注する板を決めた数と比べる検査 `tests/test_cckb_pcb.py::test_the_stab_holes_are_what_we_decided`、壊す 7 通りで落ちることを確認（`test_the_stab_hole_check_notices_a_break`）。例外 `HELD_STAB_SLOTS` を消し、長円は板・ドリルのファイルとも 0（前の長円に戻すと 16 件で落ちる）~~ | **2026-09-26 取り下げた（利用者の決定）**: 見本を基板の発注の前に買う理由が無くなった。スタビの穴は販売者の足跡（実物の実測・§10-9）、スイッチの穴は Kailh の推奨の足跡（図面 CPG135301D01・静音 CPG1353S01D0x）で決まっていて、どちらも外の事実。見本が役に立つのは刷る物（キャップの受け口・小片）を合わせることだけで、**基板の後に買ってよい**。測る項目（下面の突起が φ2.1 に入るか V13・スタビの箱と爪が穴に入るか V3・ナットの胴と爪の輪の径）は **P13** に移した。穴はきつい側に開けてあり、入らなければ手で広げる（手順書 手順 5）。門は `tools/kb cckb gate` で #1・#4 だけになったことを確かめた。取り下げる前の次の一手: スイッチ・スタビの見本（本番の品番）を基板を頼む前に買って測る |

### 物を買う・刷るまで進まないもの

（P8〜P10 はケースの段が P5〜P7 として提案した物。基板の段が先に P5〜P7 を使っていたので統合で改番した。.superpowers/sdd/cckb-autonomy/stage4-report.md の P5〜P7 はここの P8〜P10）

| # | 何 | 要るもの |
|---|---|---|
| P1 | **（V1 のスタビ。`cckb-v2` の枝ではスタビがねじ留めに替わり、この行は P13 に置き換わる）** Choc スタビの開口の嵌め合い（試し刷りの小片ではめて押す）。あわせてプレートの下に出る量（O2 の前提「ハウジングの上面はプレートの上面より下がらない」）を測る。プレートは Keebio の輪郭（幅の隙間 0）を片側 0.15（`STAB_KERF`・Cherry で測った値）広げて開けている。Choc では未実測 | Choc スタビの実物と、スタビ 1 組ぶんの試し刷りの小片 |
| P2 | 利用者の USB-C ケーブルが挿しきれるか（`USB_SHELL_EXPOSED`・`USB_PLUG_BODY_*` は HHKB の実測を借りた [暫定]） | 使うケーブルをノギスで測る（樹脂の幅・厚さ、挿しきったときに見える金属） |
| P3 | アンテナの禁止域（外 5.0・幅 ±6.0 は [暫定]）と、左のふたのネジ H3（チップから 6.6） | 試作で RSSI（rf-antenna.md の手順） |
| P4 | 電源スイッチ SS-12D00G3 のレバーに**右のふたの穴（6.4 × 2.4）から爪がかかるか**、レバーが両端まで穴の縁に擦れずに動くか（2026-09-24 に置き換え。穴の両端の爪の場所 `PSW_SLOT_NAIL` 1.0・爪のかかり `PSW_NAIL_REACH` 0.5・`NAIL_T` 1.0 は [暫定]。検査は爪を厚さ 1.0 の箱として見ていて、爪の先の曲がりは入っていない）。刻印「ON ↑」（深さ 0.4・`PSW_MARK_SIZE` 5.0）が 1 層目で潰れず読めるか。前の P4（MK-12C02-G025 の指の窪み）は部品ごと無くなった | 部品を付けた基板とケースの試し刷り（`lid_R` は約 16 分） |
| P5 | 電源スイッチ SS-12D00G3 の入の向き。図面の側面図はレバーを片側に描き、回路図は共通と**同じ側**の足を繋いで描く → レバーの側の足が繋がると読み、奥の足（パッド 1）を VBAT_SW にして**レバーを奥へ押すと入**・右のふたに「ON ↑」を彫った（`spec.PSW_ON`）。図の読みで実物は未確認。前の P5（MK-12C02-G025 の ③ の側）は部品ごと置き換えた（2026-09-24） | 部品が届いたらテスターで（order-steps §1 の 3・assembly-guide 手順 4）。逆なら `PSW_ON` を反対にしてふたを刷り直す（**板は変わらない**。足が対称で、レバーの側の足が繋がる性質は付ける向きによらない） |
| P6 | XIAO の手前の列 D0〜D6 のパッド内ビア（2026-09-24 に φ0.6/0.3 → φ0.7/0.3 → **φ0.8/0.3**。アニュラ 0.15 は JLC の部品の穴の下限 0.18 を割っていた・監査 C 軽微 3。2 回目の監査 C 軽微 2 で JLC の推奨 0.25 まで広げた。段階 1 の「穴なし」から変えた。手前は基板の縁で、XIAO の下は表の銅を禁止しているので表で外へ出る道が無い）。はんだがビアに吸われて痩せないか（監査 B-3） | 試作の手はんだで見る。付け方は assembly-guide.md 手順 2（キャステレーションの側からこてを当て、先にビアの上にはんだを少し流す）。痩せたら足す |
| P7 | アンテナの禁止域の縁の GND ビアは右 9/11・手前 4/7・奥 1/7・左 0/11（2 回目の監査 D 軽微 1 でも同じ数・同じ勧め。2 回目の直しでも変わっていない。rf-antenna.md の「4 辺とも」を満たさない。2026-09-24 の直しで奥 2 → 1・右 10 → 9: XIAO の裏の露出パッド NFC の禁止域と H3 のインサートの禁止域が奥の辺の置き場を塞いだ）。左の辺は XIAO 自身の下（表の銅を禁止）、奥と手前は XIAO のパッドの列が塞ぐ。監査 D 軽微 3 は「**発注前に ¥0 のアルミ箔の測定**（rf-antenna.md。M2 ネジ 1 本と奥・左に GND の無い状態を作る）」を強く勧める。SPI の CS・SCK が禁止域の奥の辺に沿って約 12mm 走る（監査 D 軽微 2）のも同じ測定で「走査中」と「放置中」を比べる。**4 回目の監査 D 軽微 1**: 奥の辺の 5.0mm は H3（φ2.2・中心がアンテナのチップから 9.3mm）が塞ぎ、穴は禁止域に 0.8 入る。鋼の M2 ネジと真鍮のインサートが基板に垂直に立つので、**M2 ネジとインサート 1 組を H3 に付けた状態**も 1 つの条件として測る（ネジ 6.5 前後は λ/4 = 31mm より十分短いが、測っていない）。20dB 以上悪くなったら H3 を +x へ 1〜2mm ずらすことを考える。**V2 監査 D 軽微 1（2026-09-26）**: VBAT_SW の裏の線が禁止域の奥の辺から 2.45mm の所を並走する。測る条件に「**左 Shift のスタビをねじで留めた状態**」（金属のねじ・ナットが禁止域の近く）と「**走査中**（キーを押し続ける）と**放置中**」を足す | **発注前に利用者がアルミ箔で 1 回測る**（20dB 以上悪ければ改版）。試作で RSSI（P3 と同じ手順） |
| P8 | 嵌め合い: キャップの脚（`STEM_POST_FIT`）・スイッチの開口・スタビの開口・ナットの六角の穴（**この 3 つはプレートの物。2026-09-26 からプレートを使わないので、戻すときだけ**）・インサートの下穴（`INSERT_HOLE_D`）・インサートの外径（`INSERT_OD`〔暫定〕。基板の H3 の禁止域 半径 1.9 がこれに乗る。**買うインサートは外径 3.8 以下**・3 回目の監査 軽微 4）・電池のふたのネジを捕まえる膜（`CAPTIVE_HOLE_D`）。値は provisional-values-case.md | 小片（build/cckb/coupon_*.stl。プレートの小片 3 つは build/cckb/plate_optional/）を刷り実物をはめる（docs/printing-and-assembly.md §1） |
| P9 | 電池がホルダの中で座る高さ（`CELL_Z_IN_HOLDER` 1.3 [暫定]。ふたとの隙 1.3）と、Choc スタビの軸がキャップの脚（Choc の穴 2 つ）を受ける形か | ホルダ・電池・スタビが届いたら |
| P10 | 長いトレイ（154mm・床 1.2。2026-09-24 に 1.6 から）の反りと、底を指で押したときのたわみ（梁の見積もりで 10N で 1.95mm。1.6 のとき 0.82。決定記録 2026-09-24-interface.md §2-5-1） | トレイを刷って定規を当てる。柱の間の床を指で押して、柔らかすぎないか |
| P11 | **（V1 のスタビ。`cckb-v2` の枝ではスタビがねじ留めに替わり、この行は P13 に置き換わる）** Choc スタビのワイヤがプレートの上か下か（監査 E 軽微 2）。組み立てモデルにワイヤが無い（母数の外）。下なら基板とプレートの隙 1.0 を通り、基板の逃げ穴（ハウジング＋0.5）にワイヤの通り道が無い | P1 と同じ実物で見る。下なら逃げ穴を広げる（**基板の変更なので発注前**。スタビの実物が発注前に届かなければ、上と読んで発注する——Choc のスタビはワイヤがプレートの上に出る形と理解しているが一次資料で未確認） |
| P12 | 届いた基板の外形（幅・奥行き）。JLC の外形公差 ±0.2 に対し、トレイの壁との隙を片側 0.5 にした（2026-09-24・裁定 R5） | 基板が届いたらノギスで測る（printing-and-assembly.md §2） |
| P13 | **V2（`cckb-v2`）の見本と試し刷りで測ること**（決定記録 §10-5 の V2・V4・V6・V9〜V12。**2026-09-26 に #6 の項目〔V3・V13・ナットの胴 φ2.78・爪の輪 φ3.5 が穴に入るか〕をここへ移した。基板の後でよい**。**プレートを使わない〔2026-09-26・decisions/2026-09-26-plateless.md〕ので、V4〔爪の隙とプレート 1.2〕・V9〔羽の奥の縁〕・V10〔枠の留まり方〕はプレートを戻すときだけ**）: スタビの支点 23.8（足跡の実測。24.0 は図の参照・§10-9）・静音の爪の隙 1.35 とプレート 1.2・下面の 0.30 の突起・スタビの羽の奥の縁 10.72 と爪の隙・静音の爪が ±x の辺か（別に刷るスペースの枠の留まり方）・キャップの筒（腕の先 0.675・窪みの深さ・つば φ7.9）・スタビの受け口（2026-09-26 に台 φ5.1 で 2.0 掴む形に。`coupon_stab_return` で軸がキャップと一緒に戻るか・台が箱の口 5.5〔縮尺の読み〕に当たらないか。**戻らなければまず十字の穴の幅を締める**: `coupon_stem` のスタビの板 3 枚〔幅 1.31 / 1.36 / 1.41〕・2 回目の V2 監査 E-3）・スタビのねじの頭（**読みが 2 つ: φ3.7 × 1.5〔監査 E 重要 2〕と φ3.85 × 1.6〔2 回目の V2 監査 E-6〕**。大きい方で床の止まり穴を φ4.85 に。ノギスで測って `spec.STAB_SCREW_HEAD_D`・`_H` を直す）・位置決めの丸穴 φ2.1 に下面の突起が入るか（V13） | 見本・`coupon_switch`・`coupon_stab`・`coupon_stem`・`coupon_stab_return`（printing-and-assembly §1） |
| P14 | **GND のベタの細い帯の先が GND のビアから遠い**（2026-09-26 の 2 回目の V2 監査 D-1・D-2。決定記録 2026-09-25-choc-v2 §10-10）。D-1（裏・ROW4 と手前の縁の間）はビア 5 本で道のり 33.3 → 3.1 に直した。**D-2（表・左 Shift の左の箱の穴を VBAT_SW が U 字に囲む所）は 12.3 → 10.3 までしか縮まない**: U の左の腕（VBAT_SW と箱の穴の間 1.006）と上の腕（0.8）にビアが入らず、腕の中の塗り（幅 0.25〜0.46・長さ 約 9 と 7）が棒で残る。**監査の外で測った物**: 裏の本土の中の信号の束の間の帯（CAD で x 約 +86・y 約 −10 が 26.6、x 約 +63・y 約 −12 が 17.0、x 約 +52・y 約 −10 の島が 12.9）。どれも 2.4GHz の λ/4（FR4 で約 17）に近い長さの物がある。**V1 の板（`main`）にも D-1 と同じ帯がある**（道のり 33.2・触っていない） | 腕・帯の塗りを消す（ベタに「塗らない」領域を置く。**基板の変更なので発注前**・利用者が決める）か、そのまま試作で RSSI を測る（P3・P7 と同じ手順）。V1 で発注するなら D-1 と同じビアを `main` にも |
| P15 | **プレートを使わないので、キーの下の M2 ナット 9 個に回り止めが無い**（2026-09-26・decisions/2026-09-26-plateless.md。前はプレートの六角の穴が回り止め）。下からネジを締める・緩めるとき、上からピンセットかナット回し（4mm）で押さえる。空きは組み立てモデルで測った: ナットの中心からスイッチの胴まで 3.79〜6.62・つば（基板の上 2.2〜）まで 3.26〜6.09・スタビの箱まで 7.33 以上（外接円 2.31。`assembly.nut_access`・検査 `test_the_nuts_can_be_held_from_above_without_the_plate`、取付を 1.5 寄せると落ちる）。外すときはナットの上のキャップ 7 個（Tab・左 Ctrl・左 Meta・スペースの真ん中・右のスペース・右 Shift・Del）を抜く | **利用者の決定（2026-09-26）: このまま（上から押さえる）**。ナットを外すのは分解（スイッチの交換・掃除・修理）のときだけで、電池の交換（右のふたのネジ）・ファームの書き換え（Fn+Ctrl+6）・左のふたでは外さないため。組み立てで（手順書 手順 8 の 4）押さえられない・締めても回るなら Claude に言う（ナットを基板に接着する・小さな六角の座を刷る・プレートを戻す） |
| P16 | **[暫定] プレート無しで、はんだ付けした Choc V2 が傾かず・ぐらつかず、打鍵感が許せるか**（2026-09-26・decisions/2026-09-26-plateless.md。評価していない。スイッチを基板に留めるのは足 2 本のはんだと中心の突起 φ4.80〔穴 φ5.05〕・位置決めの突起〔丸穴 φ2.1〕だけ） | 組み立ての後（手順 7 のキーの試験のとき）: (1) 各キーのキャップの四隅・両端を押して、傾く・カタつくキーが無いか。スペース・Enter・左 Shift（スタビのキー）は両端も (2) 上から見てキャップの列が揃っているか (3) **刷ったプレートを 1 枚（`plate_optional/plate_main_L.stl` の一部でよい）と比べる**: 同じスイッチを挿して、縁を押したときの揺れ・音を比べる。許せなければプレートを戻す（手順書「プレートを戻すとき」） |
| P17 | **[暫定] キャップの膜を 1.0 から 0.8 に下げられるか**（2026-09-28・**2026-10-03 利用者の決定で既定を 1.0 に**・decisions/2026-09-28-keycap-skin.md §8）。天板は場所ごとの厚さで、ステムの上は膜。押し切りでつばに 0.1 以上残すため、つばの上の輪は膜より 0.4 薄い: 膜 0.6 → 輪 **1 層 0.2**・0.8 → 0.4・**1.0（いま・上面 14.2）→ 0.6**。**見積り（§4-2・円板の有限要素）では縁の真ん中に 3 N で輪に 118 / 43 / 22 MPa**（PLA の引張強さ 約 39。前の天板 1.2 は 10）。縁に爪をかけてこじって抜くのも同じ形。だから既定は 1.0。**1.0 も刷って確かめてはいない**（見積りだけ） | **`coupon_skin`**（本番の 1u を膜 0.6 / 0.8 / 1.0 で 3 個・切り欠き 1〜3 本・A1 mini で 12 分）: 静音のスイッチに挿して、縁に爪をかけて 10 回抜き差し・縁の真ん中を強く押す（10 回）。**1.0（3 本）が割れない・白くならないことを見る。0.8（2 本）も割れなければ `spec.KEYCAP_TOP_T` を 0.8 に下げてよい**（上面 14.0。1 つの定数。`tests/test_cckb_case.py` の場所ごとの厚さの期待値も直す）。**利用者が決める**: 下げるか |

### まだ決めていない判断

| # | 決めること | いつ決まるか |
|---|---|---|
| ~~O2~~ | ~~Choc スタビがプレートの下にどれだけ出るか~~ | 2026-09-24 決着: 下端は最も低くて床の上 1.3（ハウジング 4.30 の上面がプレートの上面より下がらない）。二次資料の最大でも 0.9。床に穴は要らない。基板の逃げ穴は輪郭＋0.5（`STAB_RELIEF_MARGIN`）。検査 `test_the_stab_relief_contains_the_housing`（余裕 0.1 に壊すと落ちる）・`test_the_z_stack_holds`。実物での確かめは P1 |
| ~~O3~~ | ~~基板の厚さ 1.2 / 1.6mm~~ | 2026-09-24 決着: **1.6**。全体の厚さは同じ（足で決まる）、たわみ 10N で 0.136 対 0.322（決定記録 §2-4）。`test_the_pcb_thickness_is_stiff_enough` |
| ~~O4~~ | ~~ネジの位置と数~~ | 2026-09-24 決着: 10 か所（`spec.MOUNTS`）。5 条件を**いま生成した基板**のパッド・コートヤードと突き合わせる `test_every_mount_meets_the_five_conditions`（8 通りの置き間違いで落ちることを確認） |
| ~~O5~~ | ~~XIAO の USB-C に市販のケーブルが届くか・電源スイッチの位置~~ | 2026-09-24 決着: 口は外面から 0.3 内（HHKB 実測の見える金属 1.0 以内）・プラグの樹脂の下端は机から 4.37。電源スイッチは右の側面、つまみの先は外面と面一で深さ 1.0 の窪み（[暫定]）**→ 2026-09-24 に SS-12D00G3（表・右のふたの穴から爪で）へ置き換え（decisions/2026-09-24-power-switch.md）。窪みは無くなった**。実物のケーブルでの確かめは P2 |
| ~~O6~~ | ~~滑り止めのくぼみの深さと、底板の残りの肉厚~~ | 2026-09-24 決着: 床 1.6・くぼみ 0.4・残り 1.2・シート 0.5（[暫定]・型番を決めて測る）。**同日 O10 で置き換え**: 床 1.2・くぼみの所だけ上面 1.6 の島（くぼみの下 1.2）・くぼみ 16×8 を裏に出る物の下から外した位置へ |
| ~~O7~~ | ~~スタビのキー（Enter・左 Shift・左右のスペース 2.25u の 4 つ）のダイオード位置~~。**2026-09-24 決着**: spec.DIODE_OVERRIDE で中心穴の下へ横置き（逃げ穴から 0.405）。検査 `test_the_stab_relief_clears_the_diodes`（0.3 以上・生成した板で。前の位置に戻すと落ちる `test_the_relief_check_notices_the_old_diode_place`）。以下は当時の記録: **2026-09-24: 逃げ穴（輪郭＋0.5）の内縁は x 8.35 で、いまのダイオードのコートヤード 8.75 と重なる**（`test_the_stab_relief_clears_the_diodes` が strict xfail で見張る。直ったら XPASS で落ちるので印を外す）。いまの (7.6, −1.0) は逃げ穴の無い基板で DRC 0 を取っただけで、パッドが x 8.2・コートヤードが 8.75 まで来て、逃げ穴の始まる x 8.85 まで約 0.65mm しかない。列 0 と列 14 の配線も逃げ穴を避けて回す必要がある（左 Shift の左の逃げ穴 x −133.44 が列 0 のキー x −133.35〜−126.21 の並びに、Enter の右 x 133.44 が列 14 の 128.59〜133.35 に重なる。キー領域の中心が原点） | 計画 3 で逃げ穴を入れて DRC をやり直す。必要ならスタビのキーだけ別の位置にする |
| ~~O8~~ | ~~**ケースの形（利用者に確認）**: 設計書の「上枠＋底板」を「トレイ＋角のふた」に変えた（上枠の前後の辺を基板に留める場所が無い）。戻すなら前後に 5〜6mm 深くなる~~ | 無し。**2026-09-24 利用者が決めた: トレイ＋角のふた（案 A）のまま**（決定記録 2026-09-24-interface.md §5-1）。プレートの縁を隠したくなったら、あとで案 C（トレイの壁に嵌める飾りの縁。基板にネジで留めない）を足せる——壁の上に載るだけなので**基板は変わらない** |
| O9 | **トレイの継ぎ目（利用者に確認）**: 案 C（奥 7|8・手前スペースの隙間）を既定に。A・B も図にある。決まったら spec.py の `CASE_SEAM` のコメント「案 C・利用者に確認中」を決着に書き換える（最終レビュー M11） | `build/cckb/interface_seams.png` |
| O11 | **595 の末端を XIAO に戻すか（利用者に確認・発注前にしか足せない）**: U2 の QH'（9 番）と XIAO の D9（MISO に確保済み）はどちらも空き。繋げば SPI で送った値が戻ってくるかを読んで、数珠つなぎが生きているかを自分で検査できる（監査 A-4）。回路と板（1 本の配線）とファームの足し算で、合意の外なので足していない | 利用者が決める。足すなら circuit.py（U2 の Q7S → "MISO"・XIAO の D9）・配線し直し・overlay の miso。**要らなければ何もしない**（HHKB と同じ構成） |
| ~~O12~~ | ~~**電源のショットキー D_PWR の品番（利用者に確認・発注前に）**: 既定は **BAT46W C54110**（キーと同じ品。USB 給電中にスイッチ ON でも 25℃ では保証値で電池へ逆流しない・Vf の保証値 ≦0.45V）。戻すなら **B5819W C8598**（Basic。低い電流の Vf・低い逆電圧の IR とも保証が無く、典型で 25℃ でも電池へ約 +3〜4µA）。板は同じ D_SOD-123 で変わらない（2 回目の監査 A2-1・裁定 S2。比べた表は決定記録 2026-09-24-audit-fixes §S2）~~ | 無し。**2026-09-25 決着: BAT46W（C54110）のまま**（利用者の指示）。保証値で決まる: Vf ≦0.45V@10mA（B5819W は 1A の 0.6V しか保証が無く、低い電流の値が無い）・逆漏れ ≦0.3µA@1.5V（25℃）。外の事実: JSCJ のデータシートの保証値（出典は task-10a の出典）。起動の余裕は task-10a §6 がこの保証値で紙の上に載せる。**前の「task-10a を両方のダイオードで測る」は置き換えた**（実物を測っても典型値しか分からない。shopping-list §4）。板・BOM は変わらない |
| O13 | **電源スイッチのレバーの先がふたの上面から出うる（公差の最悪で +0.36）**（2026-09-24・電源スイッチの置き換えで分かった。2026-09-24 の監査 audit-psw.md 重要 1 で最悪値に基板の厚さの公差が抜けていたと判明・0.2 → 0.36 に訂正）。依頼の積み上げ（先 11.1）は、台座の下へ折り返した枠の爪（図面に寸法が無い。図の縮尺と写真で 0.30〜0.39・`spec.PSW_TAB` 0.4 [暫定]）で本体が浮く分を見ていなかった。名目では先 11.5・ふたの上面 11.6 の **0.1 下**。本体 ±0.1・レバー ±0.2 に加え、**基板は床のボスに下面で載り、ふたは名目の厚さ 1.6 で刷った固定の立体なので、基板が厚いほどレバーの先はふたに対して相対的に上がる**（JLC の 1.6mm 板の公差 ±10% = ±0.16・<https://jlcpcb.com/capabilities/pcb-capabilities>）。3 つを積むと最悪 11.04〜11.96（ふたの上面 11.6 から −0.56〜+0.36）。選択肢: (a) このまま（名目で 0.1 下・最悪 0.36 出る。爪は楽）(b) 縁 `RIM_ABOVE_PCB` を 7.0 → 7.5（全体の厚さ 13.8 はキャップで決まるので変わらない。キャップが縁から出る量が 2.2 → 1.7・トレイとふたの刷り直し）(c) 届いたレバーの先をニッパーで 0.3〜0.5 切る（手間・部品の改造）(d) ふたの穴のまわりに土手（ふたは上面をベッドにして刷るので、土手があると平らに置けない） | 利用者が決める。**まず届いた 1 個と基板の厚さを測る**（order-steps §1 の 3。板に押し付けて**基板の上面からレバーの先まで 7.0 −（測った基板の厚さ − 1.6）未満なら出ない**。基板厚が公称 1.6 どおりなら 7.0 未満）。基板は変わらない（ケースか部品の話） |
| O14 | **電池の側にバルクコンデンサを後から足す場所（未実装の 1206 のフットプリント）を板に置くか（利用者の判断・発注前にしか足せない）**（4 回目の監査 D 軽微 4）。板の上の電源の容量は C_U1・C_U2（0.1µF）と XIAO の中だけで、#1（CR1632 で起動・スリープから戻れるか）が「ぎりぎり」だったとき板に打てる手が無い。置くなら VBAT_SW–GND（D_PWR の手前）。ただし載せるのが正しいとは限らない（docs/knowledge/power.md: HHKB では 100µF で 53 秒リセットできなかった） | **利用者が task-10a の結果を見て決める**。「短い」の定義は task-10a §6: 21℃ で起動が成り立つ使った量 q_max が **96mAh 未満**（設計書 D4 の「保守側 0.20mA で約 480 時間」＝ 96mAh を起動が削る）。96mAh 以上なら何もしない。短ければ発注の前にフットプリントを足すか決める（板の変更＝配置・配線・DRC・再現検査のやり直し）。合意の外の追加なので、決まるまで実装しない |
| O15 | **（2026-09-26 からプレートを使わないので、前半〔スペースの枠〕はプレートを戻すときだけ決める。後半〔キャップの天板 0.8〕はいまも決められる）** **V2 のスペースの枠（別に刷る 2 つ）をやめて一枚のプレートにするか**（`cckb-v2`）。一枚にするにはケースの手前の面を約 1.0〜1.1 前へ出す（奥行き 99.45 → 約 100.5・キャップと壁の隙が手前だけ 1.3 → 2.4）。~~**キャップの天板を 0.8 にするか**（全体 −0.4・約 −11.5g・押し切りと縁の差 0.25 → 0.65。刷ったたわみは未確認）~~ **→ 2026-09-28 利用者が決めた: 天板は場所ごとの厚さ・ステムの上だけ膜 0.6（上面 13.8）→ 2026-10-03 利用者が決めた: 既定の膜は 1.0（上面 14.2。0.6 は見積りで輪が割れる）。`coupon_skin` で 0.8 が割れなければ 0.8（14.0）に下げてよい。P17・decisions/2026-09-28-keycap-skin.md §8** | 利用者（見た目・大きさ）。何も言わなければ枠のまま（決定記録 2026-09-25-choc-v2 §10-6・§10-7） |
| ~~O10~~ | ~~**厚さ 14.2mm（目標 約 12）**: 床 1.6＋下の空き 1.8＋基板 1.6＋スイッチ 8.0＋キャップ 1.2~~ | 無し。**2026-09-24 利用者が決めた: 足は切らない（手間）。床を 1.6 → 1.2 にし、滑り止めの所だけ 1.6 の島 → 13.8mm**。基板は不変（sha256 05c75c25…9d20）。ネジの沈めは先の出から導くようにした（`SCREW_PAST_NUT`）。床のたわみは 2.37 倍（決定記録 2026-09-24-interface.md §2-5-1。机の上では机が受けるので打鍵には効かない。底を指で押すと柔らかい → P10）。検査: `test_the_z_stack_holds`（厚さ 13.8 以下・床 1.2・島・ネジ。床 1.6 に戻すと落ちる）・`test_the_floor_is_1_2_with_1_6_islands_at_the_pads`（島を消すと落ちる）・`test_the_antislip_islands_keep_clear_of_the_back_of_the_board`（前の四隅に戻すと落ちる） |

### 受け入れた差（塞がない。忘れないために残す）

| # | 何 | なぜ |
|---|---|---|
| A1 | **USB を挿したままスイッチ ON だと、ショットキー D_PWR の逆漏れが電池の側へ流れる**（監査 A-1・2 回目 A2-1）。逆電圧 3.3 − Vbat ＝ 0.1〜1.4V。電池に入る正味 ＝ 逆漏れ − 分圧が吸う電流（Vbat/2.04MΩ ＝ 0.93〜1.57µA）。**BAT46W（C54110・O12 で決定）**: 25℃ の保証値 0.3µA@1.5V で正味 0（電池へ入らない）。40℃ 以上は保証が無い（Diodes の同品の Tj 60℃ の保証値 5µA では正味 +4µA まで）。B5819W（C8598）に戻した場合: 保証が無く、典型で 25℃ でも +3〜4µA（Energizer の逆充電の上限 1µA） | ~~JLC に在庫があるダイオード 8 品番をデータシートで比べ、IR が最悪でも 1µA 未満（25℃・40℃）で Vf が B5819W 以下の品は無かった~~ **← この比べ方は誤り（分圧の電流を引いていない・最大値と典型値を比べた）。正しい表は決定記録 2026-09-24-audit-fixes §S2、品番は O12 で利用者が決める。**高温では BAT46W でも保証が無いので手順は残す: スイッチは電池と回路の間にあり、**OFF なら電池は完全に切り離される**ので、手順で避ける: 「**USB を挿す前に電源スイッチを OFF**」を手順書・説明書に太字（assembly-guide.md「使い方」・task-10a）。~~task-10a で「USB を挿してスイッチ ON のときの電池の電流の向きと大きさ」を 1 回測る~~ **← 置き換えた（2026-09-25）**: 起動試験はダイオードを使わなくなった。逆漏れは試作で基板の D_PWR で 1 回測る（BAT46W は 25℃ なら保証値で電池へ入らない） |
| A2 | スイッチ OFF で USB を挿すと、ショットキー D_PWR の逆漏れが分圧（2MΩ）に入って VBAT_SW が数 V まで浮き、電池が「ある」ように表示される（監査 A-3・F-3） | 害は無い（電池は切り離されている。USB 給電中はファームが打ち止めの判定を飛ばす）。手順書に一言（assembly-guide.md「使い方」）。firmware/src/low_battery_off.c のコメントを直した |
| A3 | パスコン C_U1/C_U2 の GND の戻りが 595 の 8 番まで 13.8mm で、裏の GND ベタでは別の島（表のベタを回る）（監査 D 軽微 1・2 回目の監査 D 軽微 2 でも同じ所見。板は変えていない） | 595 の VCC（16 番）と GND（8 番）は TSSOP の対角にあり、C の 1 個では両方に近づけない。裏で直接結ぶ線はコレクタの扇（列 8 本）を横切る。4MHz の SPI で列 1 本（数十 pF）を切り替える程度の電流で、監査 D も「動かなくなるほどではない」。試作で列の波形を見るときに一緒に見る。**4 回目の監査 D 軽微 2 で測り直した**: C_U1 の GND は表の主な島へ、U1 の 8 番は表の別の島（300mm²）と裏の小さい島を経由し、戻りは約 25mm（V3V3 の側は 2.2mm）。次に板を作り直すなら、C_U1.2 のビアと U1.8 のビアを同じ表の島に落とすか、U1.8 のそばに主な島へのビアを 1 本足す。**V2 監査 D 軽微 2・3（2026-09-26・板 dae52e33。いまの板 6b886491 は信号の配線を同じまま持ってきた）**: U1 の戻りは約 25mm ではなく **30.1mm**（U2 は 13.5mm に良くなった）。SPI_SCK と U1_U2（U1 の QH' → U2 の SER）が約 117mm 並走する（V1 は 4.5〜7mm。手元の数え方〔同じ層・平行・中心線の間 1.0 以下〕で 110.7mm）。クロストークの見積もり約 10mV で動作には効かない見込み。**試作で列の波形と一緒に U2 の 14 番（SER）の波形も見る** |
| A4 | 74LVC595 の C52287685 は LCSC にデータシートの登録が無い（監査 B-2） | ピン名・1 番の位置は EasyEDA の記号とフットプリントで TI SN74LVC595A と一致（監査 B）。在庫が減ったら代替 C426713（Nexperia・1 番の位置とパッドの並びが同じ・`tests/fixtures/easyeda` に入れた）に BOM だけ替える |
| A5 | 電池ホルダ BT1 の ＋／− のシルクがホルダの本体の縁の下に半分隠れる（監査 B-5） | 付ける前には見えるので向きの確認に使える。＋（パッド 1）が +x は図面と一致 |
| A6 | DRC の警告 silk_edge_clearance 3 件（D15・D55 の名札が外形に、H9 の名札が逃げ穴に近い・監査 C 軽微 4） | 刷っても欠けるだけ。キーのダイオードの名札は核（foundry.pcb）が置くので、1 機種のために核の置き方を変えない。**数を固定して検査する**（2 回目の監査 C 軽微 3: silk_edge_clearance ＝ 3・silk_overlap/silk_over_copper ＝ 0。写しで縁に文字を足すと落ちる `test_the_warning_count_notices_a_label_on_the_edge`） |
| A8 | 「USB を挿す前に電源スイッチを OFF」は利用者の記憶だけに頼る（見張りが無い・2 回目の監査 A2-3） | スイッチ OFF でも逆漏れで VBAT_SW が浮くので、ファームで ON/OFF を見分けるのは難しい。BAT46W（O12 で決定）なら 25℃ で守らなくても電池へ入らない。~~B5819W に戻す（O12）なら、ケースの USB の口の近くに「OFF」の刻印を足すかを一緒に決める~~（O12 は 2026-09-25 に BAT46W で決まったので要らない） |
| A9 | XIAO の D7（CS）のランドの奥の端と、XIAO の裏の NFC2 のランドの間は 0.43（置くずれで縮む・2 回目の監査 D 軽微 3） | 表の銅は無い（D7 のランドは XIAO の外形の中にも入る）。手順書（assembly-guide.md 手順 2）に「奥の列のランドの内側の端には、はんだを先に盛らない」。触れても CS が NFC の端子に繋がるだけで、F4（NFC のピンを GPIO に）が次の手 |
| A7 | 595 の GND（8・13 番）はベタへ直結（サーマルにしたのは 0805 の 3 個と手はんだの BT1・XIAO だけ・spec.THERMAL_PADS） | TSSOP の足は 2 端子の部品のように立ち上がらない。GND の戻りを細くしない（監査 C 軽微 2 のうち 595 の分） |
| A13 | 電池の電圧を読む VBAT_SENSE（1MΩ＋1MΩ の真ん中・約 500kΩ）の線が 23.7mm あり、19.9mm は下に板の GND が無い（XIAO の下を裏で通る。4 回目の監査 D 軽微 3）。高インピーダンスの区間が長い側にある | 並んで走る線は無い（一番近い別の網は VBAT_SW で 1.09mm）。読みの誤差は 1% の桁と見込む（測っていない）。手はんだの D0 のフラックスが 500kΩ の点の近くに残らないよう、組み立て手順 2 に「IPA で拭く」を足した。試作でテスターの値とファームの値を 1 回比べる。**V2 の板（2026-09-26 に測り直した）**: 長さ 23.6mm・下（反対の層）に GND の塗りが無い 18.3mm（V1 と同じ）。ADC の取り込み 40µs で 800kΩ まで許す（Nordic の nRF52840 の仕様書の SAADC）ので約 500kΩ は範囲内（V2 監査 D 軽微 4）。次に板を作り直すなら R_HI/R_LO を D0 の近く（XIAO の下の裏）へ |
| A14 | XIAO のフットプリントの説明文（`lib/xiao.pretty/XIAO_nRF52840_SMD.kicad_mod` の descr と、板に焼かれた同じ文）のビア径が古い: 「φ0.7/0.3（アニュラ 0.2）」。実物は φ0.8/0.3・アニュラ 0.25（板を KiCad で読んだ・ドリルのファイルも T2 0.300 ×7。lib/README.md:126 は正しい。4 回目の監査 B 軽微 1） | 製造には効かない（銅・穴は正しい）。lib の descr を直すと未配線の板と配線済みの板の文字列が変わり、`route.json` の鮮度も取り直しになる。**発注する板のファイルを変えない**ため、**次に板を作り直すときに直す** |
| A15 | **KiCad の規則が JLC より緩い所が 2 つ**（V2 監査 C 軽微 4・2026-09-26）: (1) `.kicad_pro` の min_hole_clearance 0.25 は、JLC の PTH と線 0.28 より緩い（KiCad の規則は 1 つの値で NPTH〔JLC 0.2〕も見るので 0.28 にするとベタまで違反になる・foundry/pcb_rules.py のコメント）。(2) missing_courtyard を ignore にしているので、コートヤードの無いスタビの足跡（`Stab_Kailh_Choc_V2_Screw_2u`）が重なりの検査から外れている | (1) 監査が板を KiCad で読んで PTH と線の最短 0.65 を確かめた（いまの板 6b886491 は信号の配線を前の板から持ってきた）。(2) **2026-09-26 スタビの足跡にコートヤードを付けた**（本体の全長 18.75 ＋ 0.25・§10-9。DRC 違反 0）。missing_courtyard の ignore は残る（ほかの足跡） |
| A10 | 2 回目の直しで配置を作り直したとき、SW30・SW42・SW43・SW54・SW58・SW60 とそのダイオードが前の板から 49〜50nm 動き、前の板から写した線の端がパッドの中心から 50nm 外れている（3 回目の監査 軽微 3）。`route_pcb.py --reroute` の「89 網は同じ」の確かめは線とビアしか比べず、部品の位置を見ていない | 50nm（0.00005mm）は DRC（違反 0・未配線 0）にも製造（JLC の最小の線幅 0.1mm の 1/2000）にも効かない。直すのは検査の道具（route_pcb の同一性の確かめに部品の位置か「線の端がパッドの中心に乗る」を足す）で、文書・検査の直しではなく、足すと板を作り直すことになる。**次に route_pcb を触るときに足す**（丸めの揺らぎがあることを知っておく）。3 回目の監査は「任意」とした **2026-09-24 の電源スイッチの置き換えで原因が分かった**: Freerouting の SES を取り込むと部品が丸めの分（1〜50nm）動く。`route_pcb.py` が取り込みの後で部品を元の位置に戻すようにした（126 個を戻した）ので、配線済みの板の部品の位置は未配線の板と同じ（`test_the_committed_geometry_is_what_the_generator_makes_now` が見る）。前の板から写した線の端の 50nm はそのまま（DRC にも製造にも効かない） |
| A11 | 電源スイッチの枠の爪の平面位置が、パッド 1（VBAT_SW）・3（切のとき VBAT_IN）の φ1.6 の銅から名目 0.35（本体の公差 ±0.2 で 0.15 まで減る）しか離れていない（監査 audit-psw.md 軽微 2）。`PSW_TAB_KEEPOUT` は F.Cu のベタと線だけを止めていて、パッドの銅は範囲に入っている | 金属の枠が爪 2 つでパッド 1・3 の両方に触れると、切のときに VBAT_IN と VBAT_SW が繋がり**OFF が効かなくなる**（短絡・発熱にはならない。レジストの上に立つので起きる見込みは低い）。組み立ての確かめ（手順 5「切で鳴らない」・手順 12）に「切で奥の足と真ん中の足も鳴らない」を含めることで足りるとみなす。**板は変えない**（パッドを長円にする直しは任意・次に板を作り直すときの候補） |
| A12 | 電源スイッチ周りの引き直しで、GND の縫いビアが 0.75 間隔の対で 3 か所（計 6 本）増えた（監査 audit-psw.md 軽微 3。CAD (121.189 / 126.189 / 131.189, −27.642・−29.142)、前からある (120.442 / 125.442 / 130.442) の隣） | 穴と穴の縁の間 0.447 は同じ網なので DRC・JLC の規則に触れない。害は無い（余計な穴が増えただけ）。**次に配線を引き直すとき、縫いの間隔を見直すなら**直す。板は変えない |

### ファーム（CI でビルド成功・実機未確認）

| # | 何 | 状態 |
|---|---|---|
| F1 | USB を挿しているあいだは、キーで BLE に戻せない（sys 層に `&out OUT_BLE` が無い。ZMK は USB が使えるときは USB を優先。HHKB 分割機から持ってきた性質・監査 F-1） | 未。キー配置は利用者の好みなので足していない。足すなら sys 層の空き（Fn+Ctrl+9 など）に `&out OUT_BLE` か `&out OUT_TOG`。ファームだけの変更で発注の後でよい |
| F2 | 打ち止め `empty-millivolts = 2400` は仮の値で、回路（レールの下限 ＋ D_PWR の Vf。O12 で品番が決まる）と突き合わせる検査が無い（監査 F-2） | 未。task-10a §8（任意・発注を止めない）で、§6 の表の使える量 q_max の V_rest から値を決め、同じ配線で止まるかを確かめたあと、tests/test_cckb.py に HHKB の tools/test_firmware.py と同じ形の検査を足す |
| F4 | NFC のピン（P0.09/P0.10）を GPIO にする `&uicr { nfct-pins-as-gpios; };`（監査 D 重要 1 の「保険」の提案。Zephyr の xiao_ble は設定していない） | 足していない: 裁定 R3 で XIAO の裏の NFC1/NFC2 の下の表の銅を 0 にしたので、触れる相手が無い（`test_nothing_on_top_under_the_xiao`）。UICR の書き換えは UF2 のブートローダー越しに効くかを確かめていない。NFC を使わないと決めたままなら、試作で CS の波形に異常があったときの次の手 |
| ~~F5~~ | ~~打ち止めの判定がアイドル中に**古い 1 回の測定を 2 回と数える**（4 回目の監査 F 重要 1）。ZMK はアイドル・スリープで電池の測定を止める（ZMK app/src/battery.c の battery_event_listener が `ZMK_ACTIVITY_IDLE`・`SLEEP` で `k_timer_stop`。main af96766 で確認）のに、`low_battery_off.c` はドライバのキャッシュを読むだけだった。task-10a（キーが無い）では起動の瞬間の 1 回を 65 秒後と 125 秒後に 2 回数えていた~~ | 無し。2026-09-25 に直した: 判定のたびに `sensor_sample_fetch_chan` で測ってから読む（ZMK の測定と同じ低優先の work queue なので取り合わない）。検査 `tests/test_firmware.py::test_low_battery_off_counts_only_fresh_samples` は `low_battery_off.c` を**ホストの代役の Zephyr/ZMK**（`tests/fixtures/zmk_host`）でコンパイルして場面ごとに回す（古い低い読み 1 回では止まらない・本当に尽きたら 2 回目で止まる・USB 中は数えない）。直す前のファイルでは「古い低い読み」の場面で soft off し、測り直しの行を消すと落ちる（`test_the_fresh_sample_check_notices_the_cached_read`）。代役は自分の生成物なので、ZMK 側の事実（アイドルで測定が止まる・同じ work queue）は上の ZMK のソースで確かめた。実機での確かめは task-10a。**HHKB 分割機（`../2608042258_HHKB_devided`）は自分の写し `firmware/src/low_battery_off.c` を持っていて同じ誤りがある**（このリポジトリの直しは HHKB のビルドに入らない）。HHKB に持ち帰るのは HHKB の作業 |
| F6 | ZMK が固定されていない（`config/west.yml` の `revision: main`・`.github/workflows/build.yml` の再利用ワークフロー `@main`。4 回目の監査 F 軽微 2）。task-10a で確かめたファームと、あとで push して焼くファームで ZMK の中身が違いうる。F5 のように ZMK の内部の動き（battery.c のタイマー）に頼るコードがある | 未。**task-10a に焼くファームを CI で作ったら、その実行が取った ZMK のコミットを控え、`revision:` をそのコミットにする**（更新は意図して行う）。いま固定しないのは、固定したコミットでビルドが通ることを CI で見てからにするため。HHKB も同じなので核の方針として記録する |
| F7 | 電池の % は CR1632 では使っている間ずっと 6〜7 割に見える見込み（`cckb.overlay` の full 3200・線形の写像。二酸化マンガンリチウムは平らな電圧で過ごし終わりに急に落ちる。図の読みで測っていない・4 回目の監査 F 軽微 3） | 表示だけ（打ち止めは mV で判定）。assembly-guide「使い方」に「% は目安にならない」と書いた。task-10a の実電池の突き合わせで新品の開路電圧を記録したら、full-millivolts を寄せるかを決める（休んでいる電圧はデータシートで 2.94V・task-10a §6） |
| F8 | **状態の LED は使わない**（`CONFIG_FOUNDRY_STATUS_LED` は既定 n のまま。XIAO は左のふたの下で見えない。4 回目の監査 F 軽微 5） | 決定として記録。電池の前触れはホストの % だけで、打ち止めでは黙って止まる（assembly-guide「使い方」） |
| F3 | sys 層の Fn+Ctrl+6 = `&bootloader`・Fn+Ctrl+7 = `&sys_reset` は分割機の左右の名残（監査 F-4） | 残す（Esc・5 と同じ動きで害は無い。HHKB 分割機の keymap と同じ並びを保つ）。理由を cckb.keymap のコメントに書いた |

---

<!-- 項目の雛形（コピーして使う）

## #N (YYYY-MM-DD) 題

**きっかけ**（誰の指摘・どの検査・どの測定）

### 事実（測った）

| | 値 | 出所（実測 / データシート / API / 二次） |
|---|---|---|

### 原因 ／ なぜ検査が気づけなかったか

### 選択肢（決めるのは利用者）

| 案 | 中身 | 代償 |
|---|---|---|

### 決めたこと（誰が・いつ）／やったこと

### 確かめたこと（故意に壊して落ちることを確認: 検査名）

### 触った先（コード / 検査 / 生成物 / 記録 — 消した名前で grep 0 件）

### この節を消してよいのは

-->

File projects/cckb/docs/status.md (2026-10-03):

# CCKB のいまの状態（2026-09-25）

**結論: 基板・ケース・ファームは「発注できる状態」まで出来た。発注を止めているのは利用者にしか出来ない 2 つ
——CR1632 の起動試験（#1）と、人の目での確認（#4）——と、決めてほしい 2 つ（O11・O13。決めなければ既定で進む）。
2026-09-25 に起動試験を作り直した（可変電源で XIAO の起動に要る電圧を測り、電池とダイオードはデータシートで。買う物なし）。
2026-09-24 に電源スイッチを秋月の SS-12D00G3（表・レバーが上・右のふたの穴から爪で）に替えた（決定記録
[decisions/2026-09-24-power-switch.md](decisions/2026-09-24-power-switch.md)。絵 `build/cckb/psw_section.png`・`psw_corner_iso.png`）。**

## 0. `cckb-v2` の枝（Choc V2 静音）の状態（2026-09-26）

**結論: 核・基板（DRC 違反 0・未配線 0）・ケース・キャップ・小片まで V2 にした。2026-09-26 夜に**スイッチのプレートを使わない**ことにした
（ねじ留めのスタビは基板に留まる・約 19g 軽い・戻せるように全部残す・[decisions/2026-09-26-plateless.md](decisions/2026-09-26-plateless.md)）。
発注を止めているのは V1 と同じ #1・#4 だけ**（V2 の見本の #6 は取り下げた: 穴は販売者の実測と Kailh の推奨の足跡で決まっていて、見本は基板の後でよい）。
main は V1 の完成した設計のまま（利用者が比べて選ぶ）。
決定記録 [decisions/2026-09-25-choc-v2.md](decisions/2026-09-25-choc-v2.md) §10。

| 何 | 結果 | 証拠 |
|---|---|---|
| **プレートを使わない（2026-09-26 夜・利用者の決定）** | `spec.PLATE = False`。プレート 2 枚・枠・プレートの小片 3 つは `build/cckb/plate_optional/` に出る（刷る物の外）。**組み立ての干渉・押し切り・経路・留め方を、プレート無しとプレートありの両方で毎回検査**（両方とも干渉 0・経路 0）。刷る 13 個を A1 mini でスライス 13/13（本番 12h53m・81.6 cm³・約 101g。プレートありより −19.0g・−2h28m）。`plate_optional/` の 6 個も 6/6。**基板は変わらない**（sha256 abcd20ff… を前後で比べた）。ナットの回り止めが無くなった（上から押さえる・P15）。打鍵感・傾きは未評価（P16） | 決定記録 2026-09-26-plateless・`build/cckb/section_mount_h0.png`・`assembly_exploded.png` |
| 全検査 | **461 passed・飛ばし 0**（`REQUIRE_KICAD=1`・7 分 14 秒。組み立ての検査をプレート無し・ありの両方で回すようにした後） | 2026-09-26 夜（プレートを使わない変更の後） |
| **2 回目の V2 監査（5 視点・致命 0・重要 0）の軽微の直し（2026-09-26 夜）** | 基板は GND のビア 6・R_LO の名札・スタビの裏のコートヤード・穴と銅 0.28 だけ（網の差は GND のビアだけ）: **板 abcd20ff・DRC 違反 0・未配線 0・警告 0**。裏の GND の帯の先からビアまで 33.3 → 3.1、表の島 12.3 → 10.3（3 以下はビアでは届かない・open-gaps P14）。**同じ帯が V1（main）の板にもある**。ねじの頭の止まり穴 φ4.85・支え 4 本・`coupon_stem` のスタビの板を幅 3 通りに・手順書・order-steps を V2 に・ZMK の検査に xiao_serial。19 STL を A1 mini・K1 Max でスライス 19/19 | 決定記録 §10-10・`build/cckb/pcb_gnd_strip_D1_before_after.png`・`pcb_gnd_island_D2_before_after.png`・`pcb_silk_R_LO_before_after.png` |
| **スタビの穴（2026-09-26 夕・利用者と決めた）** | 販売者の足跡（実物の実測）を正に: 支点 ±11.9・**ねじ 丸 φ3.0・爪 丸 φ4.0**・箱の穴 6.0 × 8.0。きつい側に開け、穴の中心から 2.6 は GND のベタのほかに銅なし（後から広げられる）。長円 0・例外 `HELD_STAB_SLOTS` を消した。**板 5f02d2b0・DRC 違反 0・未配線 0・警告 0**。行のバスは禁止域の下（キー中心の 8.95 下）。左 Shift の左で塞がった 3 本と COL14 を決まった形で。プレートは販売者の値に戻した（+0.1 を消した）。キャップの受け口を 2.0 掴む形に・`coupon_stab_return`・ねじの頭の止まり穴 | 決定記録 §10-9・`build/cckb/pcb_stab_holes_*_before_after.png` |
| V2 監査（5 視点）の直し | 位置決めの長円 62 を丸 φ2.1 に（JLC の「長円の長さ ≧ 幅 × 2」。板 6b886491・DRC 違反 0・未配線 0・警告 0）・名札・I2C を切る（ecc3ca9）・手順書。スタビに関わる所見は 2026-09-26 夕に直した（上の行） | 決定記録 §10-8・`build/cckb/pcb_v2_locator_round_*.png` |
| プレートの欠け（**プレートを戻すときだけ**） | スペース 2 キーのスイッチの周りの枠を**別に刷る**（`plate_frames_main.stl`）。羽の奥の端 10.85 → 10.72（1 段奥の開口との帯 1.075 → 1.205）。幅 1.2 未満の帯 0・板の無いスイッチ 0 | `tests/test_cckb.py`（直す前の板で落ちることを確認）・`build/cckb/v2_plate_bites.png`（前）・`v2_plate_bites_after.png`（後） |
| ケース | 床の止まり穴 256（足・突起・スタビの箱）。滑り止め 12×6 に・支え 6 本を動かした。**18 個の STL を A1 mini でスライス 18/18 成功**（2026-09-26 午後にトレイ 2 枚を出し直して 2/2） | 組み立ての干渉 0・経路 0（`projects/cckb/assembly.py`） |
| キャップ | 静音の十字に挿す筒（φ5.5・十字の穴 4.15 × 1.40）・スタビの受け口。**2026-10-03 利用者の決定: ステムの上の膜は既定 1.0 → 厚さ 14.2**（天板 1.2 のときは 14.4。つばの上の輪 0.6〔3 層〕・ほかは一様に 1.0。押し切りでハウジング・つばに 0.25・スタビの箱に 0.55 残る・62 個で約 37g・A1 mini で 5h04m）。2026-09-28 の膜 0.6（13.8）は、見積りで縁を押すと輪 0.2 が割れる（3 N で 118 MPa。膜 1.0 は 22）ので既定にしない。**`coupon_skin`（膜 0.6 / 0.8 / 1.0）で 0.8 が割れなければ 0.8（14.0）に下げてよい（P17）**。組み立ての干渉 0（プレート無し・ありの両方）・A1 mini でスライス 14/14 | `build/cckb/keycap_skin_before_after.png`・`section_keycap_socket*.png`・`section_keycap_rim_pressed.png`・`section_stab_across*.png`・決定記録 2026-09-28-keycap-skin |
| 発注の門 | **閉 — #1・#4**（#6 は 2026-09-26 夜に取り下げた） | `tools/kb cckb gate`（2026-09-26 夜） |

**利用者にしか決められないこと**: スイッチの種類（静音タクタイル Whale / 静音リニア Islet。[shopping-list.md](shopping-list.md)）。
キャップの膜を既定の 1.0（14.2）から 0.8（14.0）に下げるか（P17。`coupon_skin` を刷って 0.8 が割れなければ下げられる。2026-10-03 に既定を 1.0 に決めた）。
見本は基板の後でよい。O15 のスペースの枠はプレートを戻すときだけ。組んだら打鍵感・傾きを見て、プレートを戻すかを決める（P16）。
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

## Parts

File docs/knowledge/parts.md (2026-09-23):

# 部品（HHKB 分割機で確かめたもの）

**使う前に「効いた条件」が自分の機種でも同じかを読む。**HHKB の前提は
「乾電池（アルカリ）2 本・打ち止めでレール 1.8V・XIAO nRF52840・MX ホットスワップ」。
在庫と単価は 2026-08 時点——**発注前に `tools/kb <機種> parts` で取り直す。**
番号と選定理由の正本は [foundry/parts.py](../../foundry/parts.py)。

凡例: 【一般】キーボード一般 / 【XIAO】XIAO・ZMK / 【電池】乾電池駆動に効く

## 選び方（全部の部品に共通）

1. **効く条件を先に全部並べる。**動作電圧の下限・動作点での保証値・フットプリントが
   帯に入るか・在庫と代替・段取り費。1 軸（Basic か・安いか）で選ばない
2. **データシートの数字は最悪条件の値**（1A・40V など）で、動作点の値ではない。
   動作点で保証しているかを見る。曲線の外を推定して断定しない
3. JLCPCB は **Extended 1 種類につき段取り費 $3**（Preferred は $0）。HHKB では部品代の
   4 割がこれだった。**効くのは段取り費で、単価ではない。**基板は 5 枚単位
4. 実験用に別品番を買わない。**本番の品番を決めてから買う**
5. 型番で買う（「単3×2 の箱」と書いて横並び型を買った）

## 半導体

| 部品 | 番号 | 効いた条件 | 罠 |
|---|---|---|---|
| シフトレジスタ SN74LVC595APWR（TSSOP-16）【電池】 | C52287685（代替 C426713 Nexperia） | 1.1〜3.6V。1.8V で ±4mA・104MHz | **74HC595 は下限 2.0V で打ち止めに規格外。**SOIC-16（Basic の C5947）はコートヤード 10.49 で段の間の帯 9.25 に入らない |
| マトリクスのダイオード BAT46W（SOD-123）【一般】 | C54110 | VF ≦0.25V@0.1mA と IR ≦0.3µA@1.5V を**動作点で両方保証**する唯一の品（29 件＋系列を比較） | 1N4148W（Basic・C81598）は 1mA 未満の VF が無規定。BAT48ZFILM-FS は中身が SD103AW。60℃ で 5 個以上の同時押しは余裕を割る |
| 電源経路のショットキー B5819W（SOD-123）【電池】 | C8598（Basic） | Vf が打ち止めを決める（BATT_V_MIN = 1.7 + 0.1 + Vf）。候補を Vf で比べた | 低電流の Vf は無規定 → 保守値 0.4。ブレッドボードは同定格の 1N5819（SB240LES は Vf が低く出て楽観的） |

## 受動部品・機構

| 部品 | 番号 | メモ |
|---|---|---|
| パスコン 0.1µF X7R 0805 | C49678（Basic） | IC の直近にだけ。効くのは往復ループの配線長（[power.md](power.md)） |
| 分圧 1MΩ 1% 0805 | C17514（Basic） | 1MΩ+1MΩ で 1.5µA |
| MX ホットスワップ Kailh CPG151101S11-2 | C49352235 | **最低使用電圧 2V DC（錫めっき）——レールの下限を決めていたのはマイコンではなくソケット。**最初に書いた C5184526 は在庫 0。板の下へ 1.80mm。金めっき品は JLC に無い |
| FFC コネクタ Hirose FH12-12S-0.5SH(55) | C88360 | 下接点。**在庫が最も薄く代替なし**（1 日 48 個ずつ減った）。(54) は製造中止。安価品はランドが違う |
| FFC ケーブル 12 芯 0.5mm | uxcell 等 | **A タイプ（同面）/ B タイプ（逆面）は経路の接点面で決める。ねじっても代わりにならない。幅方向に曲げられない** |
| スライドスイッチ SS12D01G4-G | 秋月 112723（¥30） | ツマミ 4.0mm・30mΩ。銀めっき（金は特注）。微小電流では硫化膜が溜まる → **リード線で繋いで交換可能に** |
| 電池箱 単3×2 **たて一列** BH-325-1A150 | 秋月 110201（¥60） | 109×16.6×16.8。リード線は**両端**から 1 本ずつ。検索語は「たて一列」 |
| M2 熱圧入インサート | 外径 3.2・長さ ≦5.0 | ボスの肉が薄いと割れる（[case-and-print.md](case-and-print.md)） |

## スイッチ・スタビ・キーキャップ【一般】

- **MX の見分けは高さ**（MX 約 14mm・低背約 8.8mm）。「MX 互換」はステム形状と端子位置の
  別々の意味で使われる（Choc V2 は十字ステムだが刺さらない）。3 ピンも 5 ピンも可
- スタビ（Cherry・PCB マウント）: **2 / 2.25 / 2.5 / 2.75u は同じ 2u 部品**（支点 ±11.938、
  穴 φ3.048 / φ3.988）。**3u は国内で買えなかった**（遊舎・TALP・Amazon・海外 4 店）→
  配列を決める前に入手性を確かめる。スペースのスタビは**ワイヤ奥（180°）**
- キーキャップの高さは**プロファイル名ではなく SKU に書かれた高さ**で判断する
  （TALP の「XDA」は約 8.5mm で通説と 0.6mm 違った）。SP 直販で 1 個単位の実測サンプル可

## XIAO nRF52840【XIAO】

- 技適 211-220207。GPIO は D0〜D10 の 11 本、**ADC は D0〜D5 だけ**
- **BAT 端子に乾電池を繋がない**（LiPo 充電回路直結。USB を挿すと一次電池を充電する）。
  電池は **スイッチ → ショットキー → 3V3 ピン**
- 基板上の RGB LED は 1 パッケージ（赤 P0.26 / 緑 P0.30 / 青 P0.06・共通アノード）。
  赤＋緑で橙に見える
- 3V3 に 2.2µF×5 を内蔵（Seeed の KiCad ソースを機械で数えた）。LDO の C_OUT 規定は 0.1〜10µF
- 2022-09 以降ヘッダは付属しない。ピンソケットで浮かせるとアンテナが地板に近づく（[rf-antenna.md](rf-antenna.md)）
- 60% 配列の本体基板には置く場所が無く、子基板＋FFC にして USB-C を奥へ出した（HHKB の構成）

## 秋月で買えないもの

FFC 12 芯 0.5mm・M2 熱圧入インサート・MX キーキャップ・スイッチ・スタビ・2mm 厚のゴム足。

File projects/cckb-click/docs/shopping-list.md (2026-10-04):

# 買う物（cckb-click）

**結論: 基板と一緒に JLC に載せてもらう部品は約 $45（部品 $30 ＋ 段取り $15）。自分で買うのは XIAO・電池・ねじ 20 本・底のシート。**
基板そのものの値段と送料は、注文画面で出る（ここには書いていない。推測で書かない）。

在庫・区分・単価は 2026-10-03 に JLC の API で取った。**発注の直前に取り直す**:

    .venv/bin/python3 projects/cckb-click/tools/parts_check.py     # 在庫・単価・Economic で載るか

## 1. JLC が基板に載せる部品（注文画面で BOM と CPL を上げる。自分では買わない）

実装は最小 2 枚。下の数は 2 枚ぶん。

| 部品 | 品番（LCSC） | 区分 | 1 枚 | 2 枚ぶんの値段 | 在庫 | 載る種類 |
|---|---|---|---|---|---|---|
| スイッチ Alps SKRAAWE010 | C202383 | Extended | 62 | $0.1997 × 124 = $24.76 | 2,832 | Economic and Standard |
| ダイオード BAT46W（キー 62 ＋ 電源 1） | C54110 | Extended | 63 | $0.0291 × 126 = $3.67 | 41,293 | 同じ |
| シフトレジスタ SN74LVC595APWR | C52287685 | Extended | 2 | $0.2488 × 4 = $1.00 | **787（薄い）** | 同じ |
| 電池クリップ MY-1632-03-R | C20606805 | Extended | 1 | $0.1893 × 2 = $0.38 | 3,072 | 同じ |
| 電源スイッチ MSK12C02 | C431540 | Extended | 1 | $0.0566 × 2 = $0.11 | 193,097 | 同じ |
| コンデンサ 0.1 µF 0805 | C49678 | Basic | 2 | $0.08 | 多い | 同じ |
| 抵抗 1 MΩ 0805 | C17514 | Basic | 2 | $0.02 | 多い | 同じ |
| 部品の合計 | | | 133 個 | **$30.02** | | |
| 段取り（Extended 5 種 × $3） | | | | **$15.00** | | |

実装の費用（setup・ステンシル・はんだ付け）は別に掛かる。**Economic か Standard かで 約 $26〜$46 ＋ α**
（docs/order-steps.md §2-1 の表。利用者が決める）。**電源スイッチは JLC に載せてもらう形で頼むが、本体が基板の縁から 1.75 mm で、JLC の「2.5 mm 以上」を
満たさない**（利用者の決定 2026-10-04）。**断られたら**、MSK12C02（LCSC C431540）を 1〜2 個、自分で買って手はんだする（docs/order-steps.md の冒頭。断られてから買えばよい）。

- スイッチは在庫 2,832。124 個使う。**空きランド（22 か所）に足すぶんを一緒に買うかは利用者の判断**（open-gaps D3。あとから LCSC でも買える）
- 595 の在庫が 10 を割ったら、CCKB と同じ代わりの品（projects/cckb/docs/order-steps.md）を見る

## 2. 自分で買う物

| 物 | 型番・寸法 | 数 | どこに使う | 値段 |
|---|---|---|---|---|
| Seeed Studio XIAO nRF52840 | 102010448（技適 211-220207。**Sense ではない方**でよい） | 1 | 左の角。表に平らにはんだ付け | 調べていない（CCKB の買い物リストと同じ品） |
| コイン電池 CR1632 | 3 V・φ16.0 × 3.2 | 1〜 | 右の角。手前の口から入れる | 同上 |
| **スリムヘッド小ねじ M2 × 4**（超極低頭） | 頭 φ4.0・頭の高さ 0.5（MISUMI の規格表の値）。鉄でもステンレスでも | **20**（予備のねじ穴 2 つと、蓋の試し刷りの 1 本と、無くす分を足して 30） | 枠と基板（20）。基板の下から。**電池の蓋は道具なしの形に変えたので、ねじは要らない**（決定記録 2026-10-04-cover-latch）。ねじの試し刷り（open-gaps #33・済み）は、**ふつうの M2×4 の小ねじ**で試した（下穴 φ1.6 で止まる）。スリムヘッドでの手応えは、本番の枠で確かめる（P1） | 調べていない |
| 底のシート | **厚さ 0.5**・290 × 100 以上・片面が粘着 | 1 | 基板の下面に貼る | 調べていない |

**ねじは型番で買う。**「M2 × 4 の低頭」には頭の高さ 0.8〜1.3 の物もある。頭が 0.5 を超えると、シートから出て机に当たる。

### 底のシート（利用者が決める。open-gaps D1）

基板の下面は部品が無く平らで、出るのはねじの頭 0.5 だけ。シートは (1) 机を傷つけない (2) 滑らない (3) 基板の裏の銅を守る、のために貼る。

| 候補 | 良い所 | 気をつける所 |
|---|---|---|
| 塩ビ・PET の粘着シート 0.5 ＋ 四隅に薄い滑り止め | ガスを出しにくい | 滑り止めの厚さだけ厚くなる |
| ウレタン・EVA の薄いシート 0.5 | 滑らない・やわらかい | 厚さがつぶれる |
| ゴム（天然・合成）のシート | 滑らない | **Alps の仕様書 D3**: 「硫化ガス・酸化ガスを出す材料（ゴム・接着剤など）と一緒に使わない。接点が腐食・接触抵抗が上がる」。硫黄で加硫したゴムは避ける |
| シリコーンゴム | 滑らない | 仕様書 B1 は接触不良の原因に「シロキサン」を挙げている。避けた方が無難 |
| **金属の板・カーボン・アルミを蒸着したシート** | — | **使わない。**アンテナ（XIAO の右）が机の 2.1 mm 上にあり、すぐ下に電気を通す面があると電波が届かなくなる（1 回目の監査 D 軽微 5）。裏の銅にも触れうる |

シートには、ねじの頭の所（20 か所。予備のねじを使うなら手前の真ん中の 2 か所も）に φ5 の穴を開ける。位置は build/cckb-click/main_top.png の下の図の黄色（ねじ）。**右手前の電池の左右にある基板の穴 2 つ（使っていない）の所には開けない**（シートで塞ぐ）。 **厚さが 0.5 でなければ、全体の厚さがその分変わる**（8.1 = 0.5 ＋ 1.6 ＋ 6.0）。

## 3. 刷る物（フィラメント）

Bambu PLA Basic。量と時間は docs/printing-guide.md。電池の蓋も同じフィラメントで刷る（約 0.2 g。予備を 1 つ）。買う物は無い。

## 4. いまは買わない物（要ると決まったら品番を決める）

| 物 | いつ要るか | 条件 |
|---|---|---|
| 電池の側のコンデンサ（C_BAT のランドに手はんだ） | CR1632 の起動の試験（open-gaps #32）で足りなかったとき | 1206 か 0805・**背 2.8 mm まで**・耐圧 6.3 V 以上 |
| レールの側のコンデンサ（C_3V3 のランドに手はんだ） | 同じ | 1206 か 0805・**背 1.45 mm まで**（キャップの下。0805 の 22〜47 µF。背 1.6 の 1206 は当たる）・耐圧 6.3 V 以上 |

品番は、載せると決めたときに `.venv/bin/python3 -m foundry.jlcpcb_lookup` で在庫と背を見て決める（先に買わない）。

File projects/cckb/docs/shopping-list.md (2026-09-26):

# 買う物の一覧（CCKB・`cckb-v2` の枝・Choc V2 静音・プレート無し・1 台ぶん）

**結論: Amazon の 1 つのカート・遊舎工房 1 箱（スタビ）・大阪日本橋のシリコンハウス（電池ホルダ・電源スイッチ）の 3 か所で揃う。
スイッチは静音タクタイル（Whale）に決めた（2026-09-26・利用者。HHKB の打鍵感に近い「押し始めの山」と 45g。合計 ¥16,748）。
静音リニアは比べた記録として残す:**

| スイッチ | どこで | 合計（送料込み・PLA を除く） |
|---|---|---|
| **静音タクタイル**（遊舎工房の「Kailh Choc V2 Silent Tactile 45gf」＝Deep Sea Silent Mini **Whale**。図面 CPG1353S01D02-01 と同じ値） | **Amazon**（出荷元 Amazon・販売元 遊舎工房）でカートに入る | **¥16,748** |
| **静音リニア**（Kailh Deep Sea Silent mini **Islet**・43gf。図面 CPG1353S01D01-01 と同じ値） | **遊舎工房**だけ（Amazon の同じページのもう 1 つの品は「Silent Pink Linear 35gf」で、Islet ではない） | **¥16,118** |

値段と在庫は **2026-09-26 に各店の商品ページで見た値**（遊舎工房は `/products/<id>.js`、Amazon は商品ページの価格・在庫・出荷元・お届け日、
共立エレショップは商品ページ）。在庫は日々動くので、買う直前にページを見る（日本橋の店頭の在庫は電話で聞く）。

**スイッチのプレートは使わない**（2026-09-26・[decisions/2026-09-26-plateless.md](decisions/2026-09-26-plateless.md)）ので、プレートに関わる物は買わない
（プレートの小片 `coupon_switch`・`coupon_nut` に使っていたスイッチ・ナットも要らない）。PLA も約 19g 減る。

**見本を先に買わなくてよい**（2026-09-26 に open-gaps #6 を取り下げた）。スイッチとスタビの穴は販売者の実測と Kailh の推奨の足跡で決まっていて、
見本は刷る物（キャップの受け口・小片）を合わせるためにしか要らない。**本番の品を 1 度に買い、届いた物で小片を合わせればよい**。

**起動試験（#1）には何も買わない**（[task-10a-coin-cell-startup.md](task-10a-coin-cell-startup.md) §3）。

**買う順番**: 日本橋（電源スイッチ）を先に。届いたら電源スイッチの入の向きと高さ（P5・O13）を確かめてから JLCPCB に基板を頼む
（[order-steps.md](order-steps.md)）。Amazon と遊舎工房はいつ頼んでもよい（基板の変更に効く物は無い）。

---

## まとめ（どこで何を買うか・送料の合計）

| 店 | 買う物 | 静音タクタイル（Whale）なら | 静音リニア（Islet）なら | 送料 | 届き方 |
|---|---|---|---|---|---|
| **Amazon.co.jp**（1 つのカート） | XIAO nRF52840・CR1632 ×5・M2 ナット・滑り止めシート・M2 皿ネジ・M2 インサート（＋ Whale 35 個入 ×2） | **¥14,030**（Whale ¥6,930 を含む） | **¥7,100** | **¥0** | 出荷元 Amazon の 6 品は 1 箱（9/28〜9/30）。インサートだけ出品者の別の箱（10/5 ごろ） |
| **遊舎工房**（<https://shop.yushakobo.jp/>） | スタビ ×5（＋ Islet 35 個入 ×2） | ¥1,650 | ¥7,950（Islet ¥6,300 を含む） | ¥550（均一） | 1 箱（入金から 7 日以内に発送） |
| **日本橋 シリコンハウス**（共立電子） | 電池ホルダ BS-16-B4AK003 ×2・電源スイッチ SS12D00G3 ×3 | ¥518 | ¥518 | なし（店頭） | 店頭の在庫は電話で聞く |
| **合計** | | **¥16,748** | **¥16,118** | 込み | |
| （手持ちが無ければ）PLA | Amazon のカートに足す | ＋¥1,676 | ＋¥1,676 | ¥0 | Amazon の箱 |
| JLCPCB（基板＋裏の部品の実装） | 下の §6 | 見積もり画面で | | | |

- **Amazon を最優先にした**: 遊舎工房の Whale は Amazon でも同じ値段 ¥3,465（出荷元 Amazon・販売元 遊舎工房・残り 16 点）で、送料 ¥0 のカートに入る。
  **スタビ（A050001-01-1）は Amazon に見つからなかった**ので遊舎工房は避けられない。Islet も遊舎工房だけ
- 静音タクタイルでも、Whale を遊舎工房でスタビと一緒に買ってよい（同じ ¥3,465・送料は同じ ¥550 のまま）。そのときの合計も ¥16,748
- 電池ホルダ・電源スイッチは Amazon に同じ物が見つからない（前の調べ・下の表）。店頭に無ければ共立エレショップの通販
  （ネコポス全国一律 ¥310・¥7,500 以上で無料）

---

## 1. Amazon.co.jp（1 つのカートに入れる）

URL は `https://www.amazon.co.jp/dp/<ASIN>`。**出荷元 Amazon の品は 1 つの箱**で、ページの表示「Amazon が発送する注文で ¥3,500 以上なら無料配送」を超える。

| 物 | 商品名・ASIN | 単価（税込） | 数 | 小計 | 在庫（2026-09-26） | 出荷元 ／ 販売元 | お届け（ページの表示） |
|---|---|---|---|---|---|---|---|
| **（静音タクタイルにするなら）スイッチ** | **Kailh Choc V2 35個入り ロープロファイルスイッチ (Silent Tactile 45gf)**・[B0F6K9DGX6](https://www.amazon.co.jp/dp/B0F6K9DGX6)（**バリエーション「Silent Tactile 45gf」を選ぶ**。もう 1 つの「Silent Pink Linear 35gf」〔B0F6K71YK5〕は Islet ではない） | ¥3,465 | **2**（70 個） | ¥6,930 | 残り 16 点 | Amazon ／ 遊舎工房 | 9/28 |
| マイコン | **Seeed Studio XIAO nRF52840**・[B09T9VVQG7](https://www.amazon.co.jp/dp/B09T9VVQG7)。**サイズは「BLE」を選ぶ**（同じページに Sense がある） | ¥2,480 | 1 | ¥2,480 | 在庫あり | Amazon ／ Leverage- | |
| コイン電池 | **パナソニック CR1632 5 個**（ブリスター）・[B0836FPZ8V](https://www.amazon.co.jp/dp/B0836FPZ8V) | ¥878 | 1（5 個） | ¥878 | 在庫あり | Amazon ／ スグツク通販 | |
| 六角ナット | **winova M2 六角ナット 304 ステンレス 20 個**（ピッチ 0.4・高さ 1.6・二面幅 4）・[B0FLDVH4QQ](https://www.amazon.co.jp/dp/B0FLDVH4QQ) | ¥429 | 1（20 個） | ¥429 | 在庫あり | Amazon ／ winova | |
| 滑り止め | **透明シリコーンゴムシート 500×500×0.5mm**・[B09X6DY2VP](https://www.amazon.co.jp/dp/B09X6DY2VP)（**サイズ「500X500x0.5mm」を選ぶ**） | ¥540 | 1 | ¥540 | 残り 11 点 | Amazon ／ 小春日和子 | 9/28 |
| 皿ネジ | **TRUSCO 皿頭小ねじ ステンレス 全ネジ M2×6 20 本入 Y826-0206**・[B0BSL94DFP](https://www.amazon.co.jp/dp/B0BSL94DFP) | ¥610 | 1（20 本） | ¥610 | 残り 3 点 | **Amazon** ／ BT TOOL STORE（09-25 は出品者の発送だった） | 9/30 |
| 熱圧入インサート | **TULDYS 真鍮インサート M2・長さ 3mm・外径 3.2mm 50 個**・[B0FKGYVZSJ](https://www.amazon.co.jp/dp/B0FKGYVZSJ)（**バリエーション「Length 3mm, M2(OD3.2mm) 50Pcs」を選ぶ**） | ¥2,163 | 1（50 個） | ¥2,163 | 在庫あり | 出品者（Waleni）**別の箱**・送料無料 | 10/5 |
| PLA（手持ちが無ければ） | **ELEGOO PLA 1.75mm 1kg**・[B0BM4DQHQH](https://www.amazon.co.jp/dp/B0BM4DQHQH)（色は自由） | ¥1,676 | 1 | （¥1,676） | 在庫あり | Amazon ／ ELEGOO | |
| **計** | | | | **¥14,030**（Islet にするなら Whale を外して **¥7,100**。PLA は別） | | | |

要る数と使う所:

| 物 | 要る数 | 買う数 | 使う所 |
|---|---|---|---|
| スイッチ | 62 | 70 | 62 ＋ 試し刷りの小片 `coupon_stem`・`coupon_stab_return` に 2 個（挿すだけで壊さない。後で本番に使える）・残りは予備 |
| XIAO | 1 | 1 | 起動試験は HHKB で使った XIAO を使う |
| CR1632 | 1 | 5 | 残りは予備 |
| M2 ナット | 9 | 20 | キーの下の取付 9 か所（プレートが無いので、締めるときに上から押さえる・手順書 手順 8） |
| 滑り止め | 12×6mm を 4 枚 | 1 枚 | 底の四隅のくぼみ（深さ 0.4） |
| M2×6 皿 | 11 | 20 | 下から 10 本（ナット 9・左のふたのインサート 1）、上から 1 本（右のふた＝電池のふた） |
| インサート | 2 | 50 | 右の柱 1・左のふた 1。試し刷り `coupon_insert` に 3 個 |

確かめたこと（ページの記載。**実物は届いたらノギスで測る**）:

- **静音タクタイル（Amazon）**: ページの題「Kailh Choc V2 35個入り ロープロファイルスイッチ (Silent Tactile 45gf)」・ブランド／メーカー 遊舎工房・
  「ピン数: 3 ピン」「ファクトリールブ: 有り」。**ページに Whale の名前・型番（A0200ED・CPG…）は無い**。遊舎工房の Whale の商品ページ
  （[10520](https://shop.yushakobo.jp/products/10520)・A0200ED-01-35・¥3,465・押下 45±10gf・触感 55±10gf・全行程 2.8±0.25・3pin）と、
  販売元・値段・荷重・入数が同じなので同じ品と読んだ（**未確認**。届いたら袋の表示を見る）。
  利用者が決めた図面 **CPG1353S01D02-01**（静音 茶・45 / 55gf・2.8±0.25）と Whale のページの値は同じ
- **XIAO**: 型番 **102010448-FA**。**Plus・Sense・Sense Plus を買わない**（基板は無印の裏の露出パッド 8 個に合わせて、その下の表の銅を抜いてある）。
  ピンヘッダは使わない（平らに直付けする）
- **皿ネジ**: ページの仕様は「頭部径 4・頭部厚さ 1.2」。設計は DIN 965 の頭 φ3.8 で、座ぐり φ4.2 の内側に収まる（沈みが少し浅くなるだけ。
  `coupon_insert` で 1 本締めて見る）
- **インサート**: 設計値は外径 3.2・長さ 3.0（[暫定]）。**外径は 3.8 を超えないこと**（左のふたの下の基板の銅の抜きが半径 1.9・open-gaps P8）
- **ナット**: ページの寸法（高さ 1.6・二面幅 4）は ISO 4032 の M2 と同じ
- **滑り止め**: 厚さ 0.5 は [暫定]。届いたら厚さを測る

## 2. 日本橋の回り方（送料なし）

### 2-1. シリコンハウス（共立電子産業）

- 住所 大阪市浪速区日本橋 5-8-26・**TEL 06-6644-4446**・月〜土 10:30〜19:30／日・祝 10:00〜19:00
  （[店舗・事業所案内](https://silicon.kyohritsu.com/storeoffice.html)）
- 電話では「共立エレショップの商品コード **N77312**・**M8J31N** は店頭にありますか」と聞く。
  共立エレショップの会員なら、通販で注文して**シリコンハウスで受け取れば送料 ¥0**（[店頭受け取り](https://eleshop.jp/shop/pages/StorePickup.aspx)）

| 物 | 商品名・コード | 単価（税込・通販の値） | 数 | 小計 | 通販の在庫（2026-09-26） |
|---|---|---|---|---|---|
| 電池ホルダ | **コイン形電池 CR1632 用電池ホルダー 表面実装タイプ BS-16-B4AK003**・[N77312](https://eleshop.jp/shop/g/gN77312/) | ¥220 | **2**（1 個は予備） | ¥440 | 19 |
| 電源スイッチ | **基板用小型スライドスイッチ SS12D00G3**・[M8J31N](https://eleshop.jp/shop/g/gM8J31N/) | ¥26 | **3**（予備 2。はんだ付けの失敗と、届いたら 1 個を測る〔爪の出 O13・入の向き P5〕のに使う） | ¥78 | 234 |
| **計** | | | | **¥518** | |

- **電源スイッチは基板を設計した品（秋月電子 115707・XIAMEN JINBEILI 製）とメーカーが違う**（共立のページは「中国製」）。共立のページの図面で
  本体 8.5×3.7×3.5・レバー 1.5 角×3.0・足 2.5 間隔を読み、秋月の図面と同じ値だった（2026-09-25）。**買ったら 1 個をノギスで測る**。
  違ったら秋月の [115707](https://akizukidenshi.com/catalog/g/g115707/)
- 千石電商 大阪日本橋店（日本橋 4-6-13・TEL 06-6649-2001）に XIAO（[EEHD-5X8K](https://www.sengoku.co.jp/mod/sgk_cart/detail.php?code=EEHD-5X8K)・¥1,800）が
  店頭にあれば Amazon より ¥680 安い（大阪の在庫は電話で聞く）。あれば Amazon のカートから XIAO を外す

## 3. 遊舎工房（<https://shop.yushakobo.jp/>・送料 ¥550 均一）

送料は「特定商取引法に基づく表記」の「【日本国内発送】送料 550 円」（2026-09-26 に見た）。

| 物 | 商品名・SKU | 単価（税込） | 数 | 小計 | 在庫（2026-09-26） |
|---|---|---|---|---|---|
| **スタビ** | **Choc v2用スタビライザー 2U（スクリュータイプ）**・SKU **A050001-01-1**・[13985](https://shop.yushakobo.jp/products/13985) | ¥330 | **5**（4 ＋ 予備 1） | ¥1,650 | あり（数は非公開） |
| **（静音リニアにするなら）スイッチ** | **Kailh Deep Sea Silent mini Islet**（43±10gf・2.8±0.25）・SKU **A0200F6-01-35**（35 個入）・[11937](https://shop.yushakobo.jp/products/11937) | ¥3,150 | **2**（70 個） | ¥6,300 | あり |
| （参考）静音タクタイル Whale | Kailh Deep Sea Mini Whale・SKU A0200ED-01-35・[10520](https://shop.yushakobo.jp/products/10520) | ¥3,465 | — | — | あり（Amazon で買うならここでは買わない） |
| 送料 | | | | ¥550 | |
| **計** | | | | **¥2,200**（Islet なら **¥8,500**） | |

- **スタビは 5 本**: 4 本（Enter・左 Shift・スペースの左と右）＋予備 1。予備の理由: ねじと爪で基板に留める作りで、爪の穴・ねじの穴はきつい側に開けてあり
  （手で広げることがある）、試し刷りの小片 `coupon_stab_return` にも 1 本留める（外せば本番に使える）。¥330 で、壊したときに送料 ¥550 をもう 1 回払わなくて済む
- **Islet のページに型番（CPG…）は無い**。値（43gf・2.8±0.25）が静音 赤の図 CPG1353S01D01-01 と同じ。**同じ品かは確かめていない**（届いたら測る・決定記録 2026-09-25-choc-v2 §10-5）
- 静音タクタイルとリニアで基板・ケース・キャップは同じ（同じ足跡・全行程 2.8）。選ぶのは好み（打鍵感）だけ

---

## 4. 起動試験のダイオード: 足つきの BAT46・1N5819 で代えられるか → 代えられない（置き換えた・記録として残す）

> **2026-09-25 に置き換えた**: 起動試験はダイオードを使わなくなった（task-10a §2）。下の比べ方は「実物を 1 個測っても
> 典型値しか分からない」ことの記録として残す。D_PWR の品番（BAT46W）は保証値で決めた（open-gaps O12）。

足つき（ブレッドボードにそのまま挿せる）の BAT46（DO-35）と 1N5819（DO-41）で、基板の BAT46W・B5819W（JSCJ・SOD-123）の
代わりになるなら、LCSC の注文も変換基板も要らなくなる。起動試験が測るのは**順電圧（0.2〜10mA）と、低い逆電圧の漏れ電流**なので、
その範囲のデータシートの値を比べた。**どちらも代わりにならない**（当時は LCSC の SOD-123 を買うことにした。上の §3-2 で置き換えた）。

| 比べるもの | 基板の品（JSCJ） | 足つき | 同じか |
|---|---|---|---|
| **BAT46W ↔ BAT46**: 順電圧の保証値 | ≦0.25V @0.1mA・≦0.45V @10mA・≦1V @250mA | ST BAT46: 同じ 3 点で同じ値 | 同じ |
| 逆電流の保証値（1.5V・25℃） | ≦0.3µA | ≦0.5µA | 違う（足つきが緩い） |
| **順電圧の典型（25℃）** | 1mA 約 0.21V・**10mA 約 0.30V**（JSCJ の Forward Characteristics） | 1mA 約 0.26V・**10mA 約 0.40V**（ST Fig. 1-1） | **10mA で約 0.1V 違う** |
| 逆電流の典型（25℃・10V） | 約 0.4µA | 約 0.3µA（ST Fig. 2） | 近い |
| **B5819W ↔ 1N5819**: 保証値 | ≦0.6V @1A・≦1mA @40V だけ | Vishay 1N5819: ≦0.6V @1A・≦1mA @40V だけ | 同じ（ただし 1A の値で、試験の範囲は保証なし） |
| 順電圧の典型（25℃） | 曲線は 0.1A（約 0.3V）から上しか描いていない | 10mA 約 0.2V まで描いてある | **比べられない**（基板の品の低い電流の値が無い） |
| 接合容量の典型（4V・ダイの大きさの目安） | 約 60pF（JSCJ の曲線） | 約 100pF（Vishay Fig. 6。表の典型は 110pF） | **約 2 倍違う ＝ ダイが違う** |

- BAT46 はメーカーが違い（ST と JSCJ）、順電圧の典型が 10mA で約 0.1V 違う。起動の余裕はこの 0.1V で変わるので、足つきで測った
  結果を基板の品に当てはめられない
- 1N5819 はダイの大きさが約 2 倍違い（容量から）、基板の品は試験の電流の範囲の値がそもそも無い。低い電流の順電圧と漏れ電流は
  ダイの大きさで変わるので、足つきで測っても基板の品の値にはならない。**店で売っている 1N5819 のメーカーも分からない**
- 出典（2026-09-25 に取得・pdftotext と、描いた曲線を目で読んだ）: JSCJ BAT46W <https://datasheet.lcsc.com/datasheet/pdf/f97c8b3ccdb24c5ba21cb2c31ad9c922.pdf>・
  JSCJ B5819W <https://datasheet.lcsc.com/datasheet/pdf/4ac2c059be7c462694ab0715ce987a85.pdf>・
  ST BAT46（DO-35・Ed. 2B） <https://datasheet.octopart.com/BAT46-STMicroelectronics-datasheet-7839727.pdf>・
  Vishay 1N5817/18/19（DO-41・Rev. 01-Jul-2020） <https://www.vishay.com/docs/88525/1n5817.pdf>

**このため当時の task-10a の「1N5819 で B5819W の代わりにしてよい」を取り消した**（その task-10a も 2026-09-25 に作り直した）。

（この節は main の V1 の一覧から写した記録。いまの起動試験はダイオードを使わない。）

---

## 5. PLA フィラメント

スライサー（OrcaSlicer・A1 mini 0.4・Generic PLA・0.20mm Standard）の見積もり（2026-09-26 にプレート無しで出し直した。
`tools/kb cckb slice --printer a1mini` の `filament used [cm3]` を足した。重さは PLA の比重 1.24 で換算）:

| 刷る物 | 体積 | 重さ（換算） | 時間 |
|---|---|---|---|
| 本番 6 個（トレイ 2・キャップ 2 枚・ふた 2） | 81.6 cm³ | 約 101g | 約 12h53m |
| 試し刷りの小片 3 個（`coupon_stem`・`coupon_stab_return`・`coupon_insert`） | 7.6 cm³ | 約 9g | 約 1h22m |
| **合計** | **89.1 cm³** | **約 110g** | 約 14h15m |
| （プレートを戻すなら）プレート 2 枚＋枠・プレートの小片 3 個 | ＋15.3・＋2.9 cm³ | ＋約 19g・＋約 3.5g | ＋2h28m・＋29 分 |

**PLA は 1kg のリール 1 本で足りる**。手持ちがあれば買わない。色は自由（キャップだけ別の色にしてもよい）。

## 6. JLCPCB に頼む物（基板＋裏の部品の実装）

JLCPCB が**基板を作り、裏に 4 種 69 個の部品を付けて**送ってくる。利用者は部品を別に買わない。

| 部品 | LCSC | 区分 | 1 枚に付く数 | 在庫（2026-09-25・API） | 単価（2 枚実装で買う数の段） |
|---|---|---|---|---|---|
| BAT46W（キーのダイオード 62 ＋ 電源の D_PWR 1） | C54110 | Extended | 63 | 45,751 | $0.0291（1〜199 個） |
| SN74LVC595APWR（列を動かす IC） | C52287685 | Extended | 2 | **1,446**（薄い。代替 C426713 在庫 3,534・$0.4165） | $0.2486（1〜49 個。50 個以上は $0.1964） |
| 0.1µF 0805 | C49678 | Basic | 2 | 18,218,286 | $0.0192（1〜199 個） |
| 1MΩ 0805 1% | C17514 | Basic | 2 | 2,498,583 | $0.0043（1〜999 個） |

- **代金は JLCPCB の見積もり画面でしか正確に出ない**（基板の大きさ 286.35×95.85mm で、100×100 の安い枠に入らない。
  組立費・ステンシル・送料は公開の表から自分では出していない）。出し方は [order-steps.md](order-steps.md) §2
- 自分で出せるのは部品代の下限だけ: 1 枚あたり 約 $2.38（上の単価×数。前は 595 を 50 個以上の段 $0.1967 で数えて $2.28 と
  書いていた・4 回目の監査 B 軽微 2）。**2 枚実装すると 約 $4.8 ＋ Extended の段取り費 $3×2 種 ＝ 約 $10.8**。JLCPCB は部品を余分に買わせることがあるので、これより高くなる
- D_PWR は BAT46W に決まった（O12・2026-09-25。B5819W C8598 に替えても段取り費・部品代はほぼ同じだったので、値段は決め手でない）

キーキャップは刷るので買わない（62 個・無刻印）。

---

## 買わなくなったもの（`cckb-v2`・プレート無し）

| 前の一覧 | いま | 理由 |
|---|---|---|
| Choc V1 のスイッチ（A0200KL-*）・Choc V1 のスタビ（A0500ST-00-1・プレート留め） | 買わない | この枝は Choc V2（静音）とねじ留めのスタビ。V1 の一覧は main の同じファイル |
| スイッチ・スタビの見本（1pcs ×3・スタビ 1）を基板の前に | 買わない（本番の品を 1 度に買う） | open-gaps #6 を 2026-09-26 に取り下げた。見本は刷る物を合わせるだけで、本番の品でできる |
| プレートの小片 `coupon_switch` に使うスイッチ・`coupon_nut` に使うナット | 要らない | プレートを使わない（2026-09-26） |
| PLA のプレートの分（約 19g） | 要らない | 同上 |

## 未確認の一覧（買うとき・届いたときに見る）

| 何が | どう確かめる |
|---|---|
| Amazon の「Silent Tactile 45gf」が遊舎工房の Whale（A0200ED）と同じ品か | 届いたら袋の表示・荷重。違えば遊舎工房の Whale を買う |
| Whale・Islet が図面 CPG1353S01D02-01 / D01-01 と同じ品か（ページに型番が無い） | 届いたらノギスで（決定記録 2026-09-25-choc-v2 §10-5・open-gaps P13） |
| シリコンハウスの店頭に N77312（電池ホルダ）・M8J31N（電源スイッチ）があるか | 電話 06-6644-4446。無ければ共立エレショップの通販 |
| 共立の SS12D00G3（M8J31N）の実物の寸法 | 買ったら 1 個をノギスで。違ったら秋月 115707 |
| TRUSCO 皿ネジの頭が φ4.0 でも座ぐりに収まるか | 試し刷り `coupon_insert` で 1 本締める |
| 滑り止めシート・インサートの実際の寸法（[暫定]） | 届いたらノギス（[provisional-values-case.md](provisional-values-case.md)） |
| Amazon の皿ネジ（残り 3 点）・Whale（残り 16 点）の在庫 | 注文の直前にページで |

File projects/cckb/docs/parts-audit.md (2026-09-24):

# 部品ごとの「効く条件」と、何で確かめたか（cckb）

**外** = データシート・API・実測で確かめた / **未** = まだ。「たぶん大丈夫」は未。
**自分の生成物（コード・コメント）どうしの一致は「外」ではない。**

選ぶ前に効く条件を全部並べてから候補を比べる。1 つの軸（Basic か・安いか）だけで
選ばない（HHKB でショットキーとシフトレジスタを選び直した）。foundry/parts.py に
HHKB で確かめた部品と理由がある——**理由の前提が自分の機種でも成り立つか**を読む。

## 結論（2026-09-24・基板の段）

JLC が裏に実装するのは 4 種 69 個（BAT46W 63〔キー 62・電源の D_PWR 1〕・74LVC595 2・0.1µF 2・1MΩ 2）。**D_PWR は 2026-09-24 の 2 回目の監査で既定を B5819W から BAT46W に替えた**（§3。2026-09-25 に BAT46W で決まった・open-gaps O12）。
**Extended は 2 種（74LVC595・BAT46W）で段取り費 $6。**表の XIAO とホルダ、スイッチ 62 個、
**表の電源スイッチ SS-12D00G3（秋月電子・スルーホール・2026-09-24 に置き換え・§4）**は利用者が手はんだ（BOM・CPL から外してある。
`tools/kb cckb fab-fields` が焼き、tests/test_cckb_pcb.py::test_jlc_parts_are_all_on_the_bottom が見る）。
CPL の座標と回転は、JLC の部品データ（EasyEDA の原点とパッド）で置き直して板のパッドと比べる
（`test_jlc_places_every_part_of_the_cpl_on_its_pads`・69 個とも 0.09mm 以内）。

在庫と単価（JLCPCB API・`tools/kb cckb parts`・2026-09-24 00:5x 取得）:

| 種類 | LCSC | 区分 | 在庫 | 単価 | 5 枚に要る数 |
|---|---|---|---|---|---|
| SN74LVC595APWR | C52287685 | Extended | 1,446 | $0.1967（50 個以上の段。10 個なら 1〜49 個の段 $0.2486・2026-09-25） | 10 |
| BAT46W | C54110 | Extended | 45,963 | $0.0292 | 310 |
| B5819W（D_PWR の候補だった・O12 で退けた） | C8598 | Basic | 471,222（2026-09-24） | $0.028 | 5 |
| 0.1µF 0805 X7R | C49678 | Basic | 18,425,015 | $0.0192 | 10 |
| 1MΩ 0805 1% | C17514 | Basic | 2,518,356 | $0.0043 | 10 |
| BS-16-B4AK003（手はんだ・利用者が買う） | C964732 | Extended | 1,688（2026-09-25 に 1,588） | $0.2278（70 個以上の段。1〜9 個は $0.4078・2026-09-25） | 1〜5 |

**薄いもの:** 74LVC595 の 1,446（要 10）。代替 **C426713**（Nexperia 74LVC595APW,118・在庫 3,534・
$0.4165・同じ TSSOP-16・同じピン配置〔74LVC595A 系の共通〕）。C548834 は在庫 0。
電源スイッチは LCSC に無い秋月電子の品（§4）。**発注の直前に取り直す。**

## 1. 74LVC595（SN74LVC595APWR / C52287685）

| 効く条件 | 確かめたか | 値 |
|---|---|---|
| 動作電圧の下限（電池の打ち止めで動くか） | HHKB で外（foundry/parts.py: 1.1〜3.6V）。**この段では TI の表を読み直していない** | CR1632 → D_PWR の後ろのレールは 3.2−0.4 = 2.8V から打ち止め（overlay の仮 2.4V → 約 2.0V）まで。下限が 1.1 でも 1.65 でも内側。74HC595（2.0V〜）は下限ぎりぎりで採らない |
| 動作点での保証値 | HHKB で外（1.8V で ±4mA） | 列は行のプルダウンへ 0.2mA 級を流すだけ |
| フットプリントと帯 | 外（KiCad 標準 TSSOP-16_4.4x5mm・板の上で） | コートヤード 7.7×5.5 が段 2|3 の帯の空き 7.05（行 2 のバスと段 3 の端子 1 の間）に入る。板で DRC 0 |
| ピン配置 | 外（SCASE93A Table 4-1）↔ pinmap.py | QA=15・QB..QH=1..7・QH'=9・SRCLR=10・SRCLK=11・RCLK=12・OE=13・SER=14。tests/test_cckb_pcb.py が overlay の &shifter n と板の Q を突き合わせる |
| 在庫・代替 | 外（API） | 上の表 |

選んだ理由: HHKB で実機確認済み（D5）。比べた: 74HC595（下限 2.0V）・Nexperia C426713（倍の単価・予備）。

## 2. BAT46W（C54110）

| 効く条件 | 確かめたか | 値 |
|---|---|---|
| 行が High と読めるか（VF ≦ 0.3×レール − 列の降下） | 外（CJ データシート: VF ≦0.25V @0.1mA） | レール ≧ (0.25＋0.2)/0.3 = 1.5V。CR1632 の打ち止めレールより低い |
| ゴースト（IR） | 外（IR ≦0.3µA @1.5V） | HHKB の比較（29 件＋系列）で両方を動作点で保証する唯一 |
| 高さ（裏・床まで 1.8） | 外（SOD-123 A 最大 1.25） | 決定記録 §2-5 |
| 在庫 | 外（API） | 45,963 |

## 3. 電源のショットキー D_PWR: BAT46W（C54110・2026-09-25 に決定）／ B5819W（C8598・退けた）

> **2026-09-24 の 2 回目の監査 A2-1**: 下の表の「JLC の 8 品番を比べて…両方満たす品は無かった」は、分圧が吸う電流を
> 引かず、BAT46W の最大値と B5819W の典型値を比べた誤り。正しい物差し（電池に入る正味 ＝ 逆漏れ − Vbat/2.04MΩ、
> Vf は保証値どうし）の表は決定記録 2026-09-24-audit-fixes §S2。**既定を BAT46W C54110 に替えた**（25℃ の保証値で
> 電池へ入らない・Vf の保証値 ≦0.45V@10mA は B5819W の ≦0.6V@1A より低い）。**2026-09-25 に BAT46W で決まった**（open-gaps O12）。
> 下の表は B5819W の記録として残す。

| 効く条件 | 確かめたか | 値 |
|---|---|---|
| 逆流ゼロ（USB 給電中に一次電池を充電しない） | 外（ショットキーの構造・HHKB 実測 +0.8µA は放電向き・**アルカリ新品**） | 理想ダイオード（LM66100 等）は電位差ほぼ 0 で逆流を止められない（power.md）。**消耗した CR1632 ＋ USB ＋ スイッチ ON では逆電圧 1.4V で典型 約 5µA（25℃）が電池へ向かいうる**（監査 A-1）。JLC の 8 品番を比べて、IR（最悪 1µA 未満・25/40℃）と Vf（B5819W 以下）を両方満たす品は無かった → 部品は替えず「USB を挿す前に OFF」（決定記録 2026-09-24-audit-fixes §R4・open-gaps 受け入れた差 A1） |
| Vf（打ち止めを決める） | 外（BAT46W は ≦0.45V@10mA の保証値。B5819W は低電流の Vf が無規定） | 起動試験 task-10a §6 が**保証値 0.45V（−10℃ は推定 0.49V）**で紙の上に載せる（~~両方のダイオードで実測~~ ← 2026-09-25 に置き換えた。実物を測っても典型値しか分からない） |
| 区分 | 外（API） | Basic（段取り費 0） |
| 極性 | 外（KiCad D_SOD-123: パッド 1 = カソード）↔ 板 | tests/test_cckb_pcb.py::test_the_power_path_has_the_right_polarity（カソード = XIAO の 3V3、壊すと落ちる） |

## 4. 電源スイッチ SS-12D00G3（秋月電子 115707・LCSC に無い）

> **2026-09-24: 利用者の決定で MK-12C02-G025（LCSC C778186・裏・横向きのつまみ）から置き換えた。**
> 表・スルーホール・レバーが上で、右のふたの穴から爪で動かす。選んだ理由は決定記録
> [decisions/2026-09-24-power-switch.md](decisions/2026-09-24-power-switch.md)。利用者が手はんだ（BOM・CPL に無い）。

図面は秋月の PDF（<https://akizukidenshi.com/goodsaffix/AKIZUKI-SS-12D00G3.pdf>）の 5 ページ目
（DRWG. NO SS12D00GXX-A03・2020-06-15）、1〜4 ページ目が仕様書 JBL-SS/SK-2010。

| 効く条件 | 図面・仕様書（外） | 板・ケース | 確かめ |
|---|---|---|---|
| 定格・寿命 | DC 30V 0.3A・接触抵抗 100mΩ 以下・10,000 回・ノンショーティング・1P2T | 電池 3V・数 mA | 外 |
| 使う温度 | 図面 −20〜+70℃、仕様書 6.9 は −20〜+60℃（**狭い方の 60℃ を採る**） | 室内・鞄 | 外 |
| 足と穴 | 足 0.5×0.3 を 2.5 間隔で 3 本・台座の下面から 3.9±0.2。推奨 3-φ0.8 | 穴 φ0.8・ランド φ1.6・パッド 2 が真ん中 | `test_the_power_switch_pads_hold_the_terminals_of_the_drawing`（パッドを 0.5 ずらすと落ちる） |
| 共通の足 | 回路図で真ん中 | 真ん中 = VBAT_IN（ホルダの＋から真っすぐ） | `test_the_power_path_has_the_right_polarity` |
| 入の向き | 側面図はレバーを片側に描き、回路図は共通と**同じ側**の足を繋ぐ | 奥の足（パッド 1）= VBAT_SW → **レバーを奥へ押すと入**・ふたに「ON ↑」 | 図の読み（**未**: 実物をテスターで。assembly-guide 手順 4）。板の上の向きは `test_the_on_side_of_the_power_switch_is_the_marked_side`（入れ替えると落ちる） |
| 高さ | 本体 3.5±0.1・レバー X = 3.0（一般公差 ±0.2）。**台座の下へ折り返した枠の爪 4 つが下に出る**（寸法の記載なし。図面の縮尺で 0.30〜0.39〔2026-09-24 の監査 audit-psw.md 軽微 1 で 0.37 は読み違いと訂正〕・秋月の写真で 0.36）→ 本体は爪で浮く | `spec.PSW_TAB` 0.4 [暫定]。レバーの先は名目 11.5（ふたの上面 11.6 の 0.1 下）、公差（本体 ±0.1・レバー ±0.2・基板の厚さ ±0.16）で 11.04〜11.96＝ふたの上面から −0.56〜+0.36（`interface.psw_tip_range`） | 未（届いたらノギス。open-gaps O13） |
| 足の出 | 3.9 − 0.4 − 1.6 = 基板の下に 1.9（最悪 2.3） | 下の空き 1.8 → **はんだの後で 1.0 に切る** | 組み立ての干渉（切らない足は床に当たる・`test_the_power_switch_pins_must_be_trimmed`） |
| 手はんだ | 仕様書 6.3: 320±5℃・2±1 秒 | assembly-guide 手順 4 | — |
| 枠（金属） | 端子と枠の間は 100MΩ 以上（仕様書 4.2） | 爪の下（本体の両端）に表の銅を置かない（`PSW_TAB_KEEPOUT`） | `test_nothing_on_top_under_the_power_switch_frame_tabs` |
| 買える所・在庫 | 秋月 ¥20・通販在庫 38,944（2026-09-24 に商品ページで見た）。**2026-09-25: 共立（シリコンハウス・M8J31N ¥26）の同じ型番をメーカー違いで使う**——共立のページの図面で本体 8.5×3.7×3.5・レバー 1.5 角×3.0・足 0.5×0.3 の 2.5 間隔を読み、秋月の図面と同じ（全体の高さは図がかすれて読めない）。実物を測って違えば秋月で買う（shopping-list §2-1） | 3 個買う | 外（図面どうし。実物は未） |

## 5. 電池ホルダ BS-16-B4AK003（C964732）

ランド 3.75×4.5 外外 28.0 は図面 MY-CP-0085 と EasyEDA（BAT-SMD_BS-16-B4AK005、同じ形の兄弟品番）で一致。
**＋はパッド 1**（図面の＋の印の側・EasyEDA のシルクの＋）。板では＋が外側（x 136.8）で、右隣の電源スイッチの
真ん中の足へ表で真っすぐ 4.4。検査 `test_the_holder_pads_are_the_drawing_land`。

## 6. XIAO nRF52840（表・平ら・手はんだ）

公式 STEP（lib/xiao.3dshapes・無改変）を測った: 裏のパッド 14 個は幅 1.524・縁から内へ 2.03＋半円 0.762、
キャステレーション φ0.635 は縁の上、ピン中心は長手で基板の中心から USB 側へ −0.064（spec.XIAO_PIN_SHIFT）。
裏にはほかに**露出パッドが 8 つ**（SWDIO・SWCLK・EN・GND・VBAT・GND・NFC1・NFC2。名前と位置は Seeed 公式の
KiCad ライブラリ XIAO-nRF52840-SMD のパッド 15〜22 と記号のピン名、形は STEP の下面の面。`spec.XIAO_BOTTOM_PADS`）。
**前は 6 つと数えていて**、アンテナ側の NFC の 2 つが抜け、NFC2 の真下に D7 のパッド・GND のビア・GND ベタがあった
（監査 D 重要 1）→ **8 つそれぞれ＋0.3 の下は表の銅を禁止**（ルール領域 XIAO_UNDERSIDE）。露出した金属はほかに **USB-C のシールドの足のめっきの長穴 4 個**（GND・はんだ付き。Seeed の裏面の図面 Dimensioning.dxf の LONGP100・`spec.XIAO_BOTTOM_SLOTS`。2 回目の監査 D 軽微 4）があり、検査は 8＋4 ＝ 12 個を名指しで見る。
フットプリント lib/xiao.pretty/XIAO_nRF52840_SMD はパッドを縁から内 **2.2**（Seeed 公式のランド 2.18 に揃えた。
前は 2.85）・外 0.6。検査 `test_the_xiao_pads_cover_the_castellations_of_the_official_step`（STEP を毎回測る）・
`test_the_xiao_bottom_pads_are_the_official_ones`（STEP の面を毎回数えて 8・Seeed のパッドと 1 対 1）・
`test_nothing_on_top_under_the_xiao`（8 つを名指し）。
**手前の列 D0〜D6 はパッドの外寄りに φ0.8/0.3 のパッド内ビア**（段階 1 の「穴なし」から変えた。2026-09-24 に
φ0.6 → 0.7 → 0.8〔2 回目の監査 C 軽微 2・アニュラ 0.25 ＝ JLC の推奨〕。φ0.6 → 0.7 の理由: アニュラ 0.15 は JLC の部品の穴の下限 0.18 を割る・監査 C 軽微 3。手前は基板の縁で、XIAO の下は
表の銅が禁止なので、表では外へ出る道が無い）。はんだが少しビアへ吸われる（付け方は assembly-guide.md 手順 2）。

## 7. 0.1µF（C49678）・1MΩ（C17514）

Basic・在庫十分。パスコンは各 595 の VCC（16 番）の隣（パッドの端どうし 0.95）。分圧 1MΩ+1MΩ は
スイッチの後ろ・ショットキーの手前（1.5µA）。

## まだ確かめていないもの

- ~~D_PWR の低電流 Vf（起動試験 task-10a で BAT46W・B5819W の両方を測る）~~ 置き換えた（2026-09-25）: 保証値で見る。基板の実物の値は試作で測る
- 電源スイッチ SS-12D00G3 の入の向き（実物・テスター）と爪の出 `PSW_TAB`（ノギス・open-gaps O13）
- XIAO のパッド内ビアではんだが痩せないか（試作で見る。痩せたら足す）

## 閉じ方の内訳

| 項目 | どう閉じたか |
|---|---|
| 74LVC595 のピン | 外（TI 表）↔ pinmap ↔ overlay ↔ 板（検査） |
| ホルダ・スイッチのパッド | 外（図面・LCSC のフットプリント）↔ 板（検査） |
| XIAO のパッド | 外（公式 STEP を毎回測る）↔ 板（検査） |
| 在庫 | 外（API・2026-09-24） |

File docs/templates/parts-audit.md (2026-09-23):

# 部品ごとの「効く条件」と、何で確かめたか（$NAME）

**外** = データシート・API・実測で確かめた / **未** = まだ。「たぶん大丈夫」は未。
**自分の生成物（コード・コメント）どうしの一致は「外」ではない。**

選ぶ前に効く条件を全部並べてから候補を比べる。1 つの軸（Basic か・安いか）だけで
選ばない（HHKB でショットキーとシフトレジスタを選び直した）。foundry/parts.py に
HHKB で確かめた部品と理由がある——**理由の前提が自分の機種でも成り立つか**を読む。

## 1. 品名（LCSC 番号 / 店の番号）

| 効く条件 | 確かめたか | 値 |
|---|---|---|
| 動作電圧の下限（電池の打ち止めで動くか） | | |
| 動作点での保証値（最悪条件の値ではなく） | | |
| フットプリントと帯の幅 | | |
| 在庫・代替 | | |

選んだ理由 / 比べた候補 / 予備（戻すときに変える定数）:

## まだ確かめていないもの

## 閉じ方の内訳

| 項目 | どう閉じたか |
|---|---|

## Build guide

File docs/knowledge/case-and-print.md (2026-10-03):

# 筐体と 3D プリント

foundry が自動で作るのは**プレートまで**（`tools/kb <機種> plate`）。ケースは機種ごとの
意匠そのものなので、HHKB の `tools/{gen_case,gen_assembly,envelopes,interface}.py` を
参照実装として読む（2 台目を作るときに共通部分を foundry へ抜き出す）。

## プリンタ

| | K1 Max | A1 mini |
|---|---|---|
| ベッド | 300³ | 180³（**CLI の自動配置は実効 168.4mm 角**。GUI で端に置けば 177.6 を実機で完走） |
| 前提 | PLA・0.4 ノズル・0.2 層・耐熱約 60℃・オーバーハング 45° | 同左・印刷時間は K1 Max の 2.4〜4.3 倍 |

- **スライサーに通したものだけを「刷れる」と言う**（`tools/kb <機種> slice`）。
  生成器より古い STL は刷れると言わない（廃止した部品の STL を 8 か月「刷れます」と言い続けた）
- 印刷を渡すときは**回した検査／回していない検査**を書き、刷るかの判断を返す
- 試し刷りは変わった帯だけを切り出す。検査用の出力は `_` 始まりにして本番と混ぜない
- 入らない部品の打ち手: 大きいプリンタ / 分割して接合 / 外注 / 余白を詰める（実機に無い分割面だけ）

## スライサーを CLI で回すとき（cckb-click で分かったこと・2026-10-03）

- **CLI は設定の継承（inherits）をたどらない。**Bambu の設定をそのまま渡すと OrcaSlicer の既定値（外周 60 mm/s・ノズル 200℃・
  ベッド 35℃）で切られる。親をたどって 1 枚にしてから渡し、**G-code の末尾の設定の欄と突き合わせる**
  （projects/cckb-click/tools/slice_precise.py。foundry/slice_check.py はまだ直していない）
- CLI の自動配置は物を**回すことがある**（180°）。向きで決まる設定（継ぎ目を奥に）を見るときは、自分で真ん中へ動かして自動配置を切る
- Bambu Studio の CLI も同じ引数で動く。利用者が刷るスライサーで確かめる
- **継ぎ目（外周の線の始まり）は、角の丸い形ではスライサーの設定だけでは置き場所を選べない**（丸みの始まりに出る）。
  滑る面にこぶを出したくない形には、辺の真ん中に小さな溝（幅 2.0・深さ 0.5）を掘り、継ぎ目を「そろえる」にすると溝の入隅に出る。
  1.2 × 0.3 の溝は 0.4 ノズルでは選ばれなかった
- 精度が要る小物: 層 0.1・外周の順は内→外→内（3 本以上）・ブリム無し・1 層目の太りは形の面取りで逃がす・測る所（外寸 10 と内寸 10）を一緒に刷る

## 寸法の作法

- **肉厚はノズル径の倍数**（1.2 / 2.4）。**0.4 未満は「無い」と同じ。**.blend や STL は厚さ 0 に
  近い膜も面として描くので、**見える＝刷れるではない**。「ある」と言う前に、部品を名指しして
  断面を描き厚みを測る（0.2 の膜を壁と誤認し上シェルを無駄に刷らせた）
- 嵌合の隙間: 印刷どうし 0.2（両側合計）、プレートの切り欠き 0.1（片側）。**未実測なら先に公差の
  クーポン**（丸穴と角穴の両方。角は隅に材料が寄ってきつくなる）
- **傾けて載せる板は、平面図の奥行が cos(傾き) 倍に縮む**（＋板厚×sin）。平らな寸法と平面図の
  寸法を別の名前で持つ（取り違えを 3 度踏んだ）
- MX: プレート厚 1.5・プレート上面からソケット下端まで 9.8mm（Topre より 5mm 以上厚い）
- スタビの開口は swillkb のパスを多角形オフセットで広げる。**スイッチの開口は広げない**（プレート保持）
- M2 熱圧入インサート（外径 3.2）: ボス φ5.6 だと肉 0.46 で割れる → 壁と一体の角柱に。
  下穴はインサートより 1.0〜1.5 深く。外面に露出させない。PLA に M2 を直接ねじ込むと舐める
- ネジはキャップの縁より外に置き、**ドライバーが届くか**を検査する（キャップ 18mm 角は開口より 4mm 大きい）
- ホットスワップ基板は**固定が要る**（スイッチを抜く力がソケットのはんだに剥離力としてかかる）
- ゴム足は座ぐりより厚くないと接地しない。0.6mm 違うと傾きが 0.41° ずれる
- フィレットは「通った」のに体積が黙って欠けることがある → 前後で体積と max Z を比べる。面取りが安定
- USB メスは壁のすぐ内側に（奥にあるとプラグが届かない）。**穴を広げずにメスを壁へ寄せる**
- 樹脂のケースは電波を妨げない。導電性フィラメントでは刷らない

## 組み立ての検査（HHKB の gen_assembly が参照実装）

- **全部品（利用者が挿すケーブルも）を組み立てモデルに入れる。**入っていない部品は検査していない
- 部品ごとに**留め方（HELD_BY）と入れる経路（INSERT_PATH）を宣言**し、実形状でたどる。
  **留まるかと入れられるか・外せるかを同じ検査で見る**（電池蓋を 3 回作り直した）
- **面の取り合いは体積では見えない**（窪みと座ぐり）。矩形の重なりで別に数える
- 予約の箱と実形状は別の質問。箱×実物の組を外すなら「箱 ⊇ 実物」の検査を必ず置く
- 許容値が要るように見えたら、モデルが実物と違う（HHKB は 6 件とも許容 0 で解いた）
- 干渉は B-rep の総当たり＋結果の記憶（鍵は 2 立体の形のハッシュ・foundry/verify.py）
- 水平に噛む機構（庇・舌・溝）は、外形を共有する落とし込み蓋には原理的に入らない
- 組んだ瞬間だけでなく、持ち上げる・裏返す・打鍵するときも見る（ナットが落ちた）
- 利用者は文章より **.blend と断面図**で設計を理解した。生成したら自分でも断面を見る

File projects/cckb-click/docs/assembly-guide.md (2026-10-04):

# 組み立て（cckb-click）

**結論: はんだ付けは XIAO の 14 か所だけ（JLC が電源スイッチを載せなかったときは、それも 7 か所）。あとは、枠を裏返してキャップ 62 個を落とし、
基板をかぶせて、ねじ 20 本。最後に電池を入れて、蓋を上から押し込む（道具は要らない。**蓋は必ず付ける**: 電池を手前へ止める物は蓋だけ）。**
絵: build/cckb-click/assembly_main/cckb-click_exploded.png（分解図）・main_sections.png（断面）・main_top.png（上から）・
main_corner.png（右手前の角: 電源スイッチの切り欠きと電池の口と蓋）・**cover_latch.png（電池の蓋のしくみ・開け方・閉め方・電池の替え方）**・
assembly_main/corner_top.png・corner_front.png（角を上と手前から）。
回して見るなら build/cckb-click/assembly_main/cckb-click.blend（「分解」は目のアイコンで出す）。

## 要る物

基板（JLC が部品を載せた物）・XIAO nRF52840・CR1632・枠 2 枚（左・右）・キャップ 62 個（1u 51・1.5u 5・1.75u 2・2.25u 4）・電池の蓋・
スリムヘッド M2×4 ×20・底のシート・はんだごて・精密ドライバー（＋ No.0〜1）・テスター。
**JLC が電源スイッチを載せなかったとき**（基板の縁に近いので、ありうる: docs/order-steps.md の冒頭）は、MSK12C02（LCSC C431540）を 1 個。

## 手順

### 1. 基板だけで確かめる（枠を付ける前）

1. 目で見る: スイッチ 62 個が浮いていない・傾いていない。ダイオードの帯が全部左。電池クリップの口が手前。**右の縁に電源スイッチが載っているか。**
   **載っていなければ手ではんだ付けする**: MSK12C02 の裏の突起 2 つを基板の穴に落とす（つまみが**基板の外向き = 右**）。ランドには、はんだがもう載っている。
   枠の金具のランド 4 か所（四隅）を先に 1 か所ずつ溶かして押さえ、それから左の端子 3 か所。足すはんだは少しでよい。つまみの樹脂にこてを当てない。
2. テスターで、電池クリップ（＋）と真ん中の裸の銅（−）の間が**繋がっていない**こと（電源スイッチのどちらの位置でも）。
3. **XIAO をはんだ付けする。**左手前の角。USB の口が左の縁。パッド 14 個の上に XIAO を平らに置き、ずれないようにテープで仮留めして、
   対角の 2 か所 → 残り。こて先はパッドの外へ出た所（0.6）に当てる。**XIAO の下にはんだを流し込まない**（裏に露出したパッドがある）。
4. USB を挿して、ファームを書く（`.uf2` をドラッグ。GitHub Actions の `cckb_click`）。
5. **キーを 1 個ずつ指で直に押して、全部入るか**（ステムを爪で押す）。入らないキーはランドのはんだを見る。
6. 電源スイッチの向きを確かめる（open-gaps P7）: USB を抜き、電池を入れ（手順 4-1 の向き）、つまみを**奥**へ寄せて、試験用のランド TP_VSW
   （左 Shift の手前・XIAO の右上にある φ1.0 の丸い銅）と GND の間が約 3 V。手前へ寄せて 0 V。逆なら Claude に言う（枠の印を直す）。
7. 62 個のステムの高さをノギスの段で測って、いちばん高い物と低い物を控える（open-gaps #2。3.2〜3.6 のはず）。

### 2. 枠を裏返してキャップを入れる

1. 左右の枠を、上面を下にして机に並べる（柱が上）。継ぎ目を合わせる（左の枠が継ぎ目のリブを持っている）。
2. キャップを**上面を下にして**穴に落とす。キャップの奥の縁の小さな溝と、穴の奥の壁の溝を同じ側に。幅の広いキーは穴の幅で分かる。
   継ぎ目の列（右の枠の左端の穴）は、左の枠を寄せてから入れる。
3. 全部が穴の底（四隅のくぼみ）まで落ちているか、指でなでる。

### 3. 基板をかぶせて、ねじを締める

1. 基板を、部品を下にして枠にかぶせる。XIAO は左手前（裏返しているので、見た目は右手前）。USB の口・電源スイッチのつまみ・電池の口が、枠の切り欠きに来る。
2. **ねじ 20 本を、基板の側から、外周の穴に。**まず四隅と継ぎ目の両側を軽く、それから全部を軽く、最後に本締め。
   **締めすぎない**——樹脂に直に切っている（下穴 φ1.6・掛かり 2.4 mm）。止まったら、そこから 1/8 回転まで。空回りしたら、その穴はもう効かない（open-gaps P1）。
   **入れ始めは少し固い**（試し刷りで利用者が確かめた径。φ1.5 ほど固くはない）。まっすぐ立てて、押しながら回す。左右の壁の 3 本（幅の広いキーの脇）は、刷る線の径が 0.04 小さいので、ほかより少しきつい見込み（試し刷りでは問題なかった）。
   **締め始めに、枠が基板から少し浮くことがある**（ねじが樹脂に山を切りながら入る）。**基板を枠へ強く押し付けながら締めない**
   （1 回目の監査 E 軽微 4）。枠は机に置いたまま、基板を載せただけで回す。浮いた所は、全部のねじを軽く入れてから順に本締めすると座る。
   **この書き方は実物で確かめていない**——ねじの試し刷り（docs/coupon-test.md）で、当て板が浮くか・締めると座るかを先に見る。
   キー領域の中の穴 8 個（柱の脇）には**ねじを入れない**（既定では枠に受けが無い）。
   **手前の真ん中の 2 つ（継ぎ目の両側）は予備の穴**（枠に下穴はある）。まず入れずに組み、継ぎ目が浮く・段が付くなら 2 本足す（open-gaps P3b）。
   **右手前の電池の口の中の 2 つ（電池の左右）には、ねじを入れない**（使っていない穴。前に、蓋をねじで留める形のために開けた。入れると電池の道を塞ぐ）。
3. 表に返して、全部のキーが、押すと沈んで離すと戻るか。引っ掛かるキーは、枠を外してキャップの縁のバリを見る。

### 4. 電池・底のシート

1. **電池を入れる。**右手前の、手前の壁の口から。**＋（平らで広い面・刻印のある側）を上**にして、クリップの下へ滑り込ませ、奥の止めに当たるまで。
2. **蓋を付ける**（絵: build/cckb-click/cover_latch.png）。蓋を、上の板（広い平らな面）を上・細い棒 2 本のある面を手前にして、口の真上に置き、
   **まっすぐ下へ押す**（少し固い: 耳の裏の細い筋が、がたつきを取る）。上面が枠と揃って、パチッと 2 回（左右）鳴れば入っている。
   上の縁を、左の端と右の端で、爪で上へこじって、どちらも浮かないことを確かめる。
   **蓋は必ず付ける**（クリップは電池を上から押さえているだけで、手前への止めが無い。蓋が無いと、振る・落とすで電池が口から抜けうる: open-gaps P25）。
   **初めて本物の基板で付けるときに見る**: 蓋が途中で引っ掛からないか・上の板がクリップに当たって浮かないか（立体では、足と電池の隙 0.2・上の板とクリップの隙 0.2。
   本物では見ていない: open-gaps P21）。引っ掛かったら無理に押し込まず、知らせる（蓋だけ刷り直す）。
3. 底のシートを基板の下面に貼る（ねじの頭の所に φ5 の穴。**電池の左右の、使っていない穴 2 つの所には開けない** = シートで塞ぐ）。**貼る前に、基板の裏の写真を撮る**（キーの名前のシルクが隠れる）。
   シートを貼ると、ねじを外すにはシートの穴から。

## 電源スイッチ

右の縁の、枠の切り欠きの中（つまみは枠の外へ出ていない: 先は枠の外面の 0.6 mm 内）。切り欠きは外へ広がっていて、内側の上の縁は斜め。
**指の腹か爪を、切り欠きに上か横から入れて、つまみを奥へ寄せると入・手前へ寄せると切**（枠の上面の小さな丸い印が、入の側。印は斜めの面のすぐ内側）。動く幅は 1.6 mm。
切り欠きの内側の縁（斜面の下の薄い所）を、指で強く押し込まない。

## 電池を替える（枠は分解しない・道具は要らない）

絵: build/cckb-click/cover_latch.png。

1. 電源スイッチを切る（つまみを手前へ）。
2. **蓋を開ける**: 右手前の角の、手前の面に、細い棒が 2 本、上下に並んでいる。**爪の先で、2 本いっしょに**押し込む（真ん中で 0.4 mm ほど・軽い力）。
   **押したまま、爪を上へずらす** → 蓋が上へ出てくる。つまんで抜く。（1 本だけ押しても開かない: 片側が 1 mm ほど浮くだけ。浮いたら、上から押して戻す。）
3. 口から、電池の上面（見えている 3 mm ほど）を爪で**押し下げながら手前へ**引く。出にくければ、つまようじを電池の縁に掛けて手前へ。
4. 新しい電池を ＋を上にして、止めに当たるまで押し込む。
5. **蓋を閉める**: 上の板を上・棒を手前にして、まっすぐ下へ押す。上面が枠と揃い、上へ引いても抜けないことを確かめる。

蓋の棒は樹脂のばねで、開けるたびに少し撓む（何回もつかは、蓋の試し刷りで 20 回まで見る: docs/coupon-test.md 10 章）。戻りが悪くなったら・折れたら・
がたつくようになったら（耳の裏の筋は、抜き差しでつぶれていく）、蓋だけ刷り直す（枠も基板も触らない）。**蓋は小さい（0.2 g）。予備が 1 つ、一緒に刷ってある。**
**持ち運ぶ前に、蓋の左右の端が浮いていないかを見る**（この蓋は、角のある物が手前の面を下から上へ強く擦ると、開きうる: open-gaps P21）。

**出せなかったら**（open-gaps P2）: 知らせる。右の枠の口を広げて刷り直す（基板は変わらない）。

## 分解する

底のシートの穴からねじ 20 本を外す → 全体を裏返して（枠を下に）基板を持ち上げる → キャップは枠に残る。
USB のケーブルは先に抜く。**蓋と電池も先に外す**（蓋は枠の歯に掛かっている。付けたままだと、基板を持ち上げるときに蓋が枠に残り、電池が落ちる）。

**キャップを 1 個だけ替えるときも、この全部の分解が要る**（キャップは枠の下からしか入らない。上へは抜けない造り）。
ねじを樹脂に切り直す回数には限りがある（**何回もつかは、まだ分かっていない**: 試し刷りで締め直した回数を聞いていない。open-gaps P1）。替えたいキャップはまとめて替える。
ねじを戻すときは、最初の 1〜2 回転を**手で逆に回して、山が落ちる所を探してから**締める（新しい山を切り直さない）。

## コンデンサを足す（CR1632 で起動しない・電池が早く減るとき・open-gaps #32・O14）

基板に、部品の載っていないランドが 2 つある（はんだも載っていない）。**足すかは起動の試験の結果で決める。**

| ランド | 場所 | 何に効くか | 載せてよい部品 |
|---|---|---|---|
| C_BAT | 右手前の角・電源スイッチの左 2 mm（シルクに名前） | 電池の側（スイッチを切ると電池から外れる） | 1206 か 0805・**背 2.8 mm まで** |
| C_3V3 | Z のキーの中・スイッチの左（シルクに名前が縦書き） | XIAO と 595 のレール | 1206 か 0805・**背 1.45 mm まで**（キャップの下。背の高い物はキャップに当たる） |

向きは無い（積層セラミック）。ランドに少しはんだを盛り、部品を置いて片側ずつ溶かす。GND の側（ベタに繋がる側）は熱が逃げるので長めに当てる。

## 幅の広いキーにスイッチを足す（端を押して反応しないとき・open-gaps #5）

真ん中のスイッチの左右に、同じランドが空いている（11 個のキーに 2 つずつ）。SKRAAWE010（C202383）を手はんだする。4 つのランドに少しはんだを盛り、
スイッチを置いて 1 か所ずつ溶かす。こては 350℃ 以下・3 秒以内（仕様書 10.1）。足したら、真ん中を押す力は 3 個ぶん（約 1.8 N）になる。
**ねじ H16〜H18 の隣（SWA16・SWA43・SWB29）に足すときは、はんだをランドの外の端まで盛らない。**枠の壁がランドの端から 0.11 mm しか離れていない。

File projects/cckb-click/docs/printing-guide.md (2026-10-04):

# 刷り方（cckb-click の本番: 枠 2 枚・キャップ 62 個・電池の蓋）

**結論: 本番は 5 枚のプレート（枠 2・キャップ 2・電池の蓋 2 個）で約 7 時間 58 分・PLA 約 73 g。設定は試し刷りと同じ（0.4 ノズル・層 0.1・精度優先）。サポートもブリムも要らない。
電池の蓋は、道具なしで上から落とし込む形に変えた（2026-10-04）。先に、蓋の試し刷り（約 41 分・蓋 3 つ・下の 0 章）を刷って、留まるか・擦っても振っても外れないか・開けられるかを見る。**
基板が無くても刷れる。刷ると open-gaps の #10b・P1・P3・P5・P6 が分かる。

**2026-10-04 に形が変わった**（利用者が試し刷り v2 を刷って決めた。決定記録 2026-10-04-knob-out-pilot）: ねじの下穴 φ1.8 → **φ1.6**（22 個とも）・
電源スイッチのつまみの切り欠きが、**0.75 外へ寄った位置で、外へ広がる形**（利用者が (ii) で触った形）。**前に刷った枠があれば、右も左も刷り直す**（下穴が違う）。
**同じ日にもう 1 つ変わった**（決定記録 2026-10-04-cover-latch）: **右の枠の電池の口**が、幅 19.0 で上から下まで抜いた溝・左右に溝（蓋の耳が入る）・手前の左右の角に小さな歯（蓋の棒の先が下に入る）になった。左の枠は変わらない。

## 0. 試し刷り

**これから刷る物（蓋の試し刷り）**

| ファイル（build/cckb-click/） | 何 | 時間・材料 |
|---|---|---|
| **`coupon_corner_plate_n04.gcode.3mf`**（docs/coupon-test.md 10 章） | 本番の枠の右手前の角 ＋ 当て板 ＋ **落とし込み式の蓋 3 つ**（歯との上下の隙と、つぶれる筋の違い）＋ 電池とつまみの代わり。7 個 | 造形 34 分 59 秒（準備込み 41 分 27 秒）・4.26 cm³（約 5.3 g）・56 層 |

しくみは `build/cckb-click/cover_latch.png`・組み方と手で見る所は `build/cckb-click/coupon_cover_howto.png`。要る物は M2×4 のねじ 1 本と、つまようじと、ペンか USB の端子（擦る）。

**済んだ物（刷り直さなくてよい）**

| ファイル（build/cckb-click/） | 何 | 結果（2026-10-04・利用者） |
|---|---|---|
| `coupon_screw_plate.stl`（6 章） | 本番の枠から切り出した壁 2 つ ＋ 当て板 2 枚 | φ1.8 の下穴は空回りした |
| 前の `coupon_corner_plate.stl`（7 章） | 前の口の形の角 ＋ 差し込み式の蓋 | つまみは奥すぎ・蓋は留まらない・電池の代わりは楽に出し入れできる |
| `coupon_v2_plate_n04.gcode.3mf`（8 章） | 下穴 3 通り・電源スイッチの位置 2 つ・蓋 3 通り | **下穴は φ1.6・スイッチは (ii) 0.75 外・蓋は 3 つとも使えない** |
| （9 章: ねじで留める蓋の試し刷り） | — | **刷らなかった**（道具が要るので、蓋の形ごと退けた） |

結果の全文は docs/coupon-test.md の 6〜8 章。**STL はいまも出る**（本番の枠から切り出して作るので、いまの下穴・いまの切り欠き・いまの口の形で出る）。
v2 は、A（ねじ）と B（つまみ）だけが出る（蓋 3 つの形は消した）。

## 1. 刷る物（2026-10-05 に Bambu Studio 2.8.2 で実際にスライスした値。下穴 φ1.6・新しい切り欠きの形・新しい電池の口と蓋）

    .venv/bin/python3 projects/cckb-click/click_case.py              # STL と絵と .blend を build/cckb-click/ に
    .venv/bin/python3 projects/cckb-click/tools/slice_main.py         # 4 枚をスライスして G-code を検査（枠は下穴 22 個の径も測る）
    .venv/bin/python3 projects/cckb-click/tools/slice_cover.py        # 蓋の試し刷りと蓋をスライスして検査（蓋の切れ目に線が通っていないかも見る）→ .gcode.3mf

| ファイル（build/cckb-click/） | 何 | 大きさ | 造形（準備込み） | 材料 | 層 |
|---|---|---|---|---|---|
| `frame_left.stl` | 左の枠（継ぎ目のリブを持つ側） | 156.4 × 101.3 × 5.0 | 2h04m（2h10m） | 11.95 cm³・約 14.8 g | 49 |
| `frame_right.stl` | 右の枠（電池の口・電源スイッチのつまみの切り欠き） | 140.0 × 101.3 × 5.0 | 1h55m（2h01m） | 11.00 cm³・約 13.6 g | 49 |
| `caps_1u.stl` | 1u のキャップ 51 個 | 158.7 × 138.6 × 2.4 | 2h27m（2h34m） | 25.43 cm³・約 31.5 g | 23 |
| `caps_wide.stl` | 幅の広いキャップ 11 個（1.5u 5・1.75u 2・2.25u 4） | 140.0 × 58.0 × 2.4 | 52m（59m） | 10.43 cm³・約 12.9 g | 23 |
| `cover_battery.stl`（スライス済み: `cover_battery_n04.gcode.3mf`） | **電池の蓋 2 個**（道具なし・落とし込み式。**手前の面が下**。1 個は予備） | 22.1 × 14.0 × 4.4 | 7m（13m） | 0.40 cm³・約 0.5 g | 42 |
| **合計** | | | **約 7h58m（準備込み）** | **59.2 cm³・約 73 g** | |

`cap_1_0u.stl`・`cap_1_5u.stl`・`cap_1_75u.stl`・`cap_2_25u.stl` は 1 個ずつ（刷り直し用）。
**`cover_battery.stl`（電池の蓋）の形は、蓋の試し刷りの結果で決め直す**（いまは蓋 2 = 歯との隙 0.3・筋 0.50。`spec.COVER_MAIN`）。**無くしやすい小さな部品なので、予備を含めて 2 個並べてある**（`spec.COVER_SPARE`）。
蓋は小さいので、枠かキャップと同じプレートに置いて一緒に刷ってもよい（**向きは変えない**: 手前の面を下にしないと、棒が宙に浮く）。

**下穴の径（スライスした G-code で測った。線が空けている径）**

| 壁 | 個数 | 設計 | 線が空ける径 | 利用者が試し刷り v2 で締めた切れ端 |
|---|---|---|---|---|
| ふつうの壁（奥・手前・1u の脇） | 19 | φ1.6 | 1.54（1.537〜1.543） | 1.54（止まる） |
| 薄い壁（幅の広いキーの脇: H16・H17・H18） | 3 | φ1.6 | 1.49〜1.50 | 1.50（止まる・問題なし） |

薄い壁は 0.04〜0.05 きつい側に出るが、利用者が確かめた径と同じなので、径は変えていない。入れ始めが固かった φ1.5 は、線で 1.44／1.40。

## 2. 設定（試し刷りで利用者が確かめた物と同じ）

プリセットは `projects/cckb-click/print/cckb-click_precise_n04.json`。読み込み方は docs/coupon-test.md の「刷り方」と同じ
（ファイル → インポート → 設定をインポート → プロセスの一覧から `cckb-click precise 0.10 @A1M 0.4`）。

| 項目 | 値 |
|---|---|
| プリンタ・ノズル | A1 mini・0.4 |
| フィラメント | Bambu PLA Basic（乾かしてから） |
| プレート | Textured PEI・65℃ |
| 層の高さ／1 層目 | 0.1／0.2 |
| 線の幅（外周／1 層目） | 0.42／0.5 |
| 外周 | 3 本・内→外→内・Arachne |
| 外周の速さ・加速度 | 60 mm/s・2000 |
| 継ぎ目 | そろえる（Aligned）。形の側の溝（幅 2.0・深さ 0.5）に入る |
| 象の足の補正・X-Y 補正 | 0・0（試し刷りの 10 mm の塊がほぼ 10 mm だったので入れない） |
| 上・下の層／中 | 7・5／15% |
| ブリム・サポート・スカート | 無し |
| 刷る順 | 層ごと（全部一緒） |
| 置き方 | **回さない。**枠は上面が下（柱と壁が上を向く）。キャップは押す面が下。**蓋は手前の面が下**（細い棒 2 本がベッドに寝る）。STL がその向き |
| 送る画面 | 「ベッドレベリング」と「流量ダイナミクスのキャリブレーション」を入れる |

なぜこの値かは決定記録 2026-10-03-print-recipe。スライスのたびに、この表のうち 25 個を G-code の設定の欄と突き合わせている（tools/slice_main.py）。

## 3. 刷ったら見る所

| 見る所 | 何を | だめなら |
|---|---|---|
| キャップ 62 個 | 枠の下から入れて、自分の重さで動くか。引っ掛かる物は縁のバリを爪で取る | その 1 個だけ刷り直す（`cap_*.stl`） |
| 枠の継ぎ目 | 左右を突き合わせて、継ぎ目の列のキャップが挟まらないか（P3） | `FRAME_SEAM_GAP` を広げて刷り直す |
| 柱の先・奥の壁のねじの所 | 継ぎ目の溝をまたぐ小さな橋（26 か所）が垂れていないか（P5）。垂れは基板に着く面に出る | やすりで平らにする |
| ねじの下穴（φ1.6） | M2 のねじを 1 本入れてみる（P1。径は試し刷り v2 で利用者が決めた）。外周 20 ＋ 手前の真ん中の予備 2。**5 回締め直して、止まる手応えが残るか**（回数はまだ分かっていない） | きつくて入れ始められない → φ1.6〜1.7 のドリルを手で通す。空回り → Claude に言う（v2 では空回りしなかった径） |
| 枠の反り | 平らな所に置いて、角が浮かないか | ベッドの温度・置く向きを変えて刷り直す |
| 電池の口 | CR1632 が口を通るか（基板が無くても電池だけで試せる。口の幅は 19.0・手前の角の歯の間は 17.0）・**歯が欠けていないか** | 口の奥行き `FINGER_NOTCH_DEPTH`・歯の出 `COVER_TOOTH` を直して右の枠と蓋を刷り直す |
| 電池の蓋 | 棒 2 本が、まわりから離れているか（切れ目が埋まっていないか）・押し下げるだけで留まるか・上へこじって抜けないか（蓋の試し刷りで先に見る: docs/coupon-test.md 10 章） | 試し刷りで選んだ組に `COVER_MAIN` を合わせて、蓋だけ刷り直す（約 11 分） |
| 電源スイッチの切り欠き（右の壁） | 外へ広がった角が欠けていないか・内側の斜めの面が垂れていないか・切り欠きの中に糸が残っていないか。**内側の縁（斜面の下の、厚さ 1.2 の所）を指で強く押さない**（厳しい見方で、10 N で上限の半分強・20 N で上限を超える見積もり） | 糸はピンセットで取る。割れたら Claude に言う（斜めに落とす量を減らす） |

## 4. 回した検査／回していない検査

**回した**

- 形の検査（tests/test_cckb_click_case.py）: 1 マスの断面が試し刷りの枠と同じ・サポート無しで刷れる・左右とも A1 mini に置ける・
  置いたとき／押し切ったとき／傾けたときの干渉 0・キャップを下から入れられる・電池を出せる・USB を挿せる・ねじの周りの肉（22 か所を 10° おきに測る）・
  角の部品のパッドと枠の隙・ねじの試し刷りと角の試し刷りが本番の枠と同じ形・電源スイッチのつまみの先が基板の縁の 0.30 内／枠の外面の 0.60 内で、
  爪の入る場所が空いている・指先の代わりの球がつまみの先より奥へ入る・切り欠きの内側の縁の強さ（断面を立体から測る）・下穴が 22 個とも φ1.6。
  **電池の蓋**（落とし込み式 v2）: 枠・電池・クリップ（図面から作った形）・基板・部品・キャップに当たらない・面一・電池は手前へ 0.23 で蓋の足に止まる・
  蓋を付けると電池は 10 の向きのどれにも出ない・蓋は棒を 2 本とも押し込まないと上へ抜けない・棒 1 本を押しても片側が上がるのは 1.5 まで・回しても出ない・
  ベッドの面の縁の面取り・蓋の胴の応力（立体から測った断面）・手前の面をベッドにサポート無し。それぞれ故意に壊すと落ちる
- **本番の 4 枚を Bambu Studio 2.8.2 のコマンドでスライス**（2026-10-05・電池の口を落とし込み式の蓋の形に変えた後にもう一度。警告 0・設定 25 個が G-code と一致・**下穴 22 個の径を G-code で測った**: 上の表。
  測り方は、穴の中心を 0.1 ずらす・φ1.5 の幅で見る、で NG になることを見た）
- **蓋と、蓋の試し刷りを同じコマンドでスライス**（`tools/slice_cover.py`。警告 0・設定 25 個が一致・蓋の切れ目 3 本と、棒の先の下の隙 0.2 に、線が通っていない・棒の所に線がある・棒の厚さより上に棒が無い。見る点を 0.6 ずらすと NG になることを、回すたびに見ている。絵 slice_cover.png）

**回していない**

- Bambu Studio の**画面**からのスライス（確かめたのはコマンドから）
- OrcaSlicer での本番のスライス（試し刷りでは両方を回した。`tools/slice_main.py orca` で回せる）
- 形を変えた後の、ねじの試し刷り・v2 のスライスのやり直し（どれも済んだ試し刷り。STL は出し直した。v2 の STL は、A と B の 8 個だけになった）
- **蓋を実際に刷っていない**（留まるか・擦る／振る／落とすで外れないか・爪で開けられるか・棒が何回もつか: 蓋の試し刷りで見る）。**この蓋は爪 1 つで開く = 「わざとでないと開かない」は形だけでは言えていない**（open-gaps #34b）。本物の電池クリップ・電池との隙（基板が届いてから）
- **本番の枠に、実際にねじを入れていない**（径は試し刷りの切れ端で確かめた物と同じ、まで）
- 0.2 ノズル（`tools/slice_main.py n02`）
- 継ぎ目が滑る面に出ていないかの数え直し（試し刷りの 1 マスでは 0。本番の 62 マスでは数えていない。形は同じ関数で作っている）
- 実物の寸法・反り・糸引き（刷らないと分からない）

**刷るかどうかは利用者の判断。**

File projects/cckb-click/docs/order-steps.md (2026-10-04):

# 基板を JLCPCB に頼む手順（cckb-click）

**結論: 基板のデータは出来ている（DRC 違反 0・未配線 0・警告 0）。ただし発注の門は閉じている。残っているのは 4 つ:
頼み方を決めて画面で確かめる（#31）・CR1632 の起動試験（#32）・電池の蓋（#34b。道具なしで上から落とし込む形にした。基板は変えない → 蓋の試し刷りを触って、利用者が言う）・
2026-10-04 に直した板（電源スイッチを 0.75 外へ）の見直し（#36）。
ねじ（#33）と電源スイッチの位置（#34）は、利用者が試し刷り v2 を刷って決めた（下穴 φ1.6・スイッチは 0.75 外）。
全部閉じてから、ZIP・BOM・CPL を上げ、下の表のとおりに選び、配置のプレビューで部品の向きを見てから払う。**

    tools/kb cckb-click gate        # いまは「閉 — #31・#32・#34b・#36」

## ★ 先に読む: 電源スイッチは、JLC の「縁から 2.5 mm」を満たしていない

**利用者の決定（2026-10-04）: 規約より使いやすさ。**電源スイッチ MSK12C02（SW_PWR）を、指で届くように 0.75 外へ動かした
（試し刷り v2 で触って選んだ位置。決定記録 2026-10-04-knob-out-pilot）。

| 何 | いまの板 | JLC の決まり（2026-10-04 に読んだ） | 満たすか |
|---|---|---|---|
| 本体の縁 → 基板の縁 | **1.75 mm** | 実装の規約: 「部品の本体と基板の縁は 2.5 mm 以上」 | **満たさない** |
| つまみの先 → 基板の縁 | 0.30 mm 内側（名目でちょうど。入でも切でも同じ） | Economic の注意書き: 「線と部品は縁から 0.3 mm 以上」 | **名目で下限ちょうど。最悪の場合は割る**（下の「つまみの先の余裕」） |
| ランドの外の端 → 基板の縁 | 1.70 mm | 同上 | 満たす |
| 縁から外へ出る物 | 無い（つまみの先は枠の外面の 0.60 内） | — | — |

**つまみの先の余裕（4 回目の監査 2026-10-04）**

- 図面（MSK12C02・LCSC C431540・2024-12-14。自分で開いて読んだ）は、つまみの出 1.45・中心から先まで 2.85 に**個別の公差を書いていない**。表題欄の未注の公差は X.xx = ± 0.2（± 0.1 はつまみの幅 1.3・本体の幅 2.8・突起 φ0.75 だけ）。**前の記録の「± 0.1」は誤り**。
- 最悪の場合、基板の縁に対して 0.30 − 0.20 − 0.075（突起 φ0.75 と穴 φ0.9 の遊び）= **+0.025**（細い突起 φ0.65 なら −0.025）= 先は実質、基板の名目の縁まで届きうる。枠の外面に対しては ≒ +0.10〜+0.13（0.60 − 0.20 − 0.075〜0.125 − 0.1〔ねじ穴の遊び〕− 0.1〔刷りの誤差〕）で、枠の外へは出ない。
- JLC の実装の FAQ（その 2）Q14（原文を読んだ 2026-10-04）: Economic は基板を**面付けして一度に流すので、実装の後に**ルーターで切り離す（公差は約 0.2 mm）。だから「縁から 0.3 mm **を超える**」。**これは面付けする場合の話。**この板（286 × 96）は面付けの上限 250 × 250 を超えるので 1 枚で流れる見込みだが、1 枚の板の外形を実装の前に切るのか後に切るのかは FAQ に書かれていない = **未確認**（普通は外形は実装の前に切る）。実装の後に切る場合に限り、つまみの先は名目でちょうど 0.300 なので、最悪の場合、ルーターがつまみに触れうる。
- **届いたら、つまみの先の傷と動きを見る。**
- 利用者の選択肢（まだ決めていない）: スイッチを 0.2 内へ戻す（先は基板の縁の 0.50 内）と余裕は戻るが、触って選んだ位置から離れる。

**だから、JLC が「このスイッチは載せられない」と言うことがありうる。**そのときの手は決めてある（利用者）: **その 1 個だけ手はんだ**。基板は変わらない。

**どう進めるか**

1. **そのまま頼む**（BOM と CPL に SW_PWR を入れたまま。いまのファイルはこの形）。
2. **注文画面で見る**（JLC がどの段で言うかは、この作業では確かめられていない。見る所は 3 つ）:
   - BOM を上げた後の部品の一覧で、C431540（MSK12C02）が**選ばれた状態**か（外されている・警告の印が付いていないか）
   - 配置のプレビューで、SW_PWR が右の縁の近くに**置かれている**か（赤い印や「board edge」の注意が出ていないか）
   - 「Confirm Parts Placement」を **Yes** にしておく（§2 の表）。払った後、JLC の担当が「縁に近くて載せられない」と**メールか注文の頁で言ってくる**ことがある
3. **載せないと言われたら**（画面でも、後の連絡でも）: 下のとおりに SW_PWR を外して頼み直す（または、その 1 個を外すことに同意する）。

**SW_PWR を外すやり方（基板のデータは触らない）**

| ファイル | すること | 外した後の数 |
|---|---|---|
| `production/bom.csv` | `SW_PWR,SW_MSK12C02,1,MSK12C02,C431540` の行を消す | 6 行（7 → 6） |
| `production/positions.csv` | `SW_PWR,291.875,-138.1,90.0,top` の行を消す | 132 行（133 → 132） |
| ガーバー（ZIP） | **変えない**（ランドとペーストの穴はそのまま。ステンシルではんだだけ載って、リフローで平らに固まる） | — |

届いてから、MSK12C02（LCSC C431540）を 1 個、手ではんだ付けする: **端子 3 か所 ＋ 枠のランド 4 か所 = 7 か所**。本体の裏の突起 2 つを基板の穴に落とすと位置が決まる。
つまみは**基板の外向き（右）**。先に載っているはんだを溶かしながら押さえる（足すはんだは少しでよい）。**こて先は 350 ℃以下・1 回 3 秒以内**（MSK12C02 の図面 7.1）。部品は別に買う（docs/shopping-list.md。**断られてから**でよい: 安く、在庫も多い）。

**確かめていないこと**: Standard なら 2.5 mm を割っていても載るのか・JLC の画面のどこに何が出るのか・載せないと言われる確率。どれも注文してみるまで分からない。

## §1 頼む前に閉じるもの

| 順 | 何 | どうやって閉じるか |
|---|---|---|
| 1 | **独立した監査（#36）** | 2026-10-04 に電源スイッチを 0.75 外へ動かした板（b442b865…）は、**まだ見直していない**。前の板（fe90b1e6…）は 3 回目の監査で致命 0・重要 0 だった。違いは右手前の角だけ（open-gaps「見直してもらう所（#36）」）。差分の監査に出す |
| 2 | CR1632 で起動できるか（#32） | projects/cckb/docs/task-10a-coin-cell-startup.md（CCKB と同じ回路なので同じ試験。買う物なし）。結果で、載せないコンデンサのランド（C_BAT・C_3V3）に部品を足すかが決まる |
| 3 | **電池の蓋（#34b）** | 利用者が「道具なしで、しっかり留まる蓋」と決めた（2026-10-04・決定記録 2026-10-04-cover-latch。ねじで留める形は退けた）。上から落とし込む蓋を作った。**立体と G-code で測った限り、基板は変えなくてよい**（穴 H30・H31 は使わないが、残っていて害は無い）。蓋の試し刷り（docs/coupon-test.md 10 章・蓋 3 つ）を刷って触り、**利用者が「この蓋でよい」と言えば閉じる** |
| ~~3b~~ | ~~角の試し刷り（#34）~~ ✅ 済み | 2026-10-04 に利用者が刷った（v1 と v2）。つまみは (ii) 0.75 外に決めた → 基板を直した |
| ~~3c~~ | ~~ねじの試し刷り（#33）~~ ✅ 済み | 2026-10-04 に利用者が刷って締めた（v1 と v2）。下穴 φ1.6 に決めた（**基板の穴は変えない**）。締め直しの回数は聞いていない（open-gaps P1） |
| 4 | 在庫 | `.venv/bin/python3 projects/cckb-click/tools/parts_check.py` が「OK 問題 0 件」 |
| 5 | 利用者の決定 | §2-1 の表（実装の種類・表面処理）・予備のスイッチの数 |
| 6 | 人の確認（#31） | 上の「★ 先に読む」（電源スイッチを JLC が載せるか）と、下の §3 |

## §2 発注ファイルを出す

    tools/kb cckb-click pcb                                              # 未配線の板
    "$KICAD_PYTHON" projects/cckb-click/tools/route_click.py             # 配線（SPI・電源の枝は、監査した板の線 pcb/freerouted.json を置き直す。Freerouting は回さない）
    tools/kb cckb-click fab-fields                                       # LCSC の番号を板に焼く
    tools/kb cckb-click drc                                              # 違反 0・未配線 0・警告 0
    REQUIRE_KICAD=1 .venv/bin/pytest tests/test_cckb_click_board.py -q   # 板の検査（発注道具の出力まで）
    cd ~/Documents/KiCad/10.0/3rdparty/plugins
    "$KICAD_PYTHON" -m com_github_bennymeg_JLC-Plugin-for-KiCad.cli \
      -p "<リポジトリの絶対パス>/projects/cckb-click/pcb/cckb-click_main.kicad_pcb" -t -nI -nB

`$KICAD_PYTHON` は /Applications/KiCad/KiCad.app/Contents/Frameworks/Python.framework/Versions/3.9/bin/python3.9。
ファイルは `projects/cckb-click/pcb/production/` に出る（git に入れない。頼む直前に出し直す）。

| 上げるファイル | 中身（検査が毎回確かめる） |
|---|---|
| `production/cckb-click_main.zip` | ガーバー（銅 2 層・マスク・ペースト・シルク・外形・ドリル） |
| `production/bom.csv` | 7 行: C202383 ×62・C54110 ×63・C52287685 ×2・C49678 ×2・C17514 ×2・C20606805 ×1・C431540 ×1（電源スイッチを手はんだにするなら、最後の 1 行を消して 6 行） |
| `production/positions.csv` | **133 行・全部 top**。SW_PWR は (291.875, −138.1)・90°（手はんだにするなら消して 132 行） |

**入っていないのが正しい物**: XIAO（手はんだ）・幅の広いキーの空きランド 22 個（SWA*・SWB*）・試験用のランド TP_VSW・
載せないコンデンサのランド 2 個（C_BAT・C_3V3）・ねじの穴 32 個（外周 20・中 8・予備 2・蓋 2）。

### JLCPCB の注文画面で選ぶもの

| 項目 | 選ぶ値 | なぜ |
|---|---|---|
| Layers | 2 | |
| Dimensions | 自動で 291.15 × 100.65 mm と出るはず | 違ったら ZIP の外形を疑う |
| PCB Thickness | **1.6** | 高さの積み上げ（8.1）と、ねじ M2×4 の掛かりがこの厚さ |
| Surface Finish | **利用者が決める。勧めは ENIG**（平らで金。電池の −が当たる裸の銅が、錆びにくい面になる）。HASL は安いが、当たる面がはんだめっきの丸い山になる | open-gaps D2・P10。§2-1 |
| PCB Color | ENIG を選ぶなら、Economic で選べる色を画面で見る（監査は「1.6 mm の ENIG は Economic では緑だけ」と読んだ。**この作業では JLC の頁で確かめられなかった**: 能力の表は「Limited options」としか書いていない） | 色は機能に効かない |
| Outer Copper Weight | 1 oz | |
| Via Covering | Tented（既定） | |
| Remove Order Number | Yes | 番号を刷らせない |
| **PCB Assembly** | オン・**Top Side**・数量 2。**Economic か Standard かは利用者が決める（§2-1）** | 部品は全部表 |
| Tooling holes | Added by JLCPCB | 位置は JLC が決める。見られるのは**払った後**の製造データの確認（§3） |
| Confirm Production file / Confirm Parts Placement | **Yes**（両方） | §3 のため。Yes にしておくと、JLC の作った製造データ・配置をこちらが承認するまで製造が始まらない |
| 基板の洗浄 | **頼まない**（何も足さない） | JLC は洗わないはんだ（no-clean）を使い、既定では洗わない（規約）。タクトスイッチは洗浄液が中に入る |

### §2-1 利用者が決めること: 実装の種類（2026-10-04 に JLC の頁で調べた）

**何が問題か**（1 回目の監査 B 重要 1・2 / C 重要 1・2）

1. **電源スイッチ MSK12C02 が基板の縁に近い。**いまの板: 本体は縁から **1.75**・つまみの先は縁の 0.30 内側（検査 `psw_edge_problems` が板で見る）。
   JLC の規約「部品の本体と基板の縁は 2.5 mm 以上」は**満たさない**。Economic の注意書き「線と部品は縁から 0.3 mm 以上」は満たす（つまみの先で名目ちょうど）。
   **利用者の決定（2026-10-04）: 使いやすさを取る。断られたら手はんだ**（冒頭の「★ 先に読む」）。
   履歴: 最初の板は本体 0.75・つまみが縁から 0.70 外 → 2.50 内側へ直した（3 回目の監査の板）→ 刷って触ると奥すぎたので 1.75。
2. **Economic のリフローは 255 ± 5 ℃で、変えられない。**Standard は 240 ± 5 ℃。Alps の SKRAAWE010 の仕様書（p.6/12・10.2・10.3。
   <https://tech.alpsalpine.com/cms.media/SKRAAW_KRA_709_JA_83058db522.pdf>・2026-10-04 に読み直した）は、部品の表面温度の最高 260 ℃（3 秒以内）・230 ℃以上の時間 40 秒以内・全体で 3〜4 分以内・
   リフローは 2 回まで・「極力低温短時間で」・はんだ付けのあとに洗わない・クリームはんだの厚さ 0.15 mm と定める（余裕は Economic で 0〜10 ℃）。

**選べる組み合わせ**（値段は 2 枚ぶん・部品代 $30.02 は別・どちらも同じ）。**どちらの列でも、電源スイッチを JLC が断ったら「その 1 個だけ手はんだ」になる**
（冒頭の「★ 先に読む」。そのとき Extended の種類が 1 つ減る = A で −$3.07・はんだ付け 7 か所ぶん −$0.01。部品 $0.11 は自分で買う）

| | A: Economic | C: Standard |
|---|---|---|
| 電源スイッチ | JLC に載せてもらう形で頼む。**本体は縁から 1.75 = 規約の 2.5 を満たさない。断られたら手はんだ** | 同じ（Standard なら載るのかは**確かめていない**） |
| リフローの温度 | 255 ± 5 ℃（固定） | **240 ± 5 ℃** |
| 段取りの費用（setup） | $8.18 | $25.56（片面） |
| ステンシル | $1.53 | $8.21（片面） |
| 部品の種類ごとの費用 | Extended 5 種 × $3.07 = $15.35（Basic は無料） | 7 種（Basic も）× $1.53 = $10.71 |
| はんだ付け（1 か所 $0.0016） | 846 か所 = $1.35 | $1.35 |
| 梱包 | 無料 | $0.50 ＋ 面積ぶん |
| **実装の費用の小計** | **約 $26.4** | **約 $46.3 ＋ α** |
| A との差 | — | **約 ＋$20**。捨て基板（Edge Rails）を JLC が足す費用が別に掛かれば、さらに ＋$8.21（Panel fee。**掛かるかは未確認**） |
| 捨て基板・位置合わせの印（Edge Rails・Fiducials） | 要らない | **要る**（幅 5 mm 以上の捨て基板・φ1 の印を 3〜4 個）。この板には入れていない → 注文画面で JLC に足してもらう設定があるか、**画面で確かめる** |
| 最小の数 | 2 枚 | 2 枚 |
| 基板の大きさ・厚さ | 10×10〜470×500・0.8〜1.6 mm（この板は 291×101・1.6: 入る） | 70×70〜460×500・制限なし（入る） |
| 表面処理・色 | 「選べる物が限られる」 | 制限なし |
| 納期（実装） | 1〜3 日 | 4 日以上 |
| はんだの検査（SPI） | 無し | 有り |
| 仕様書の「230 ℃以上 40 秒以内」 | **未確認**（JLC の頁に 230 ℃以上の時間は載っていない） | 同じ |
| 捨て基板の取り外し | 要らない（付かない） | **既定では付いたまま届く。**外してもらうには注文のときに頼む・**追加費用**（額は注文画面にだけ出る） |

**Standard を選ぶときの注意**（2026-10-04 に JLC の頁で確かめた）

- **捨て基板（Edge Rails）は、既定では付いたまま届く。**外してもらうには注文のときに頼む必要があり、**追加の費用が掛かる**（額は注文画面にだけ出る。
  <https://jlcpcb.com/help/article/how-to-add-edge-rails-fiducials-for-pcb-assembly-order>）。手で折り取ると基板がたわむ。Alps の仕様書 E1-9 は、
  はんだ付けのあとの基板の割り工程でスイッチが変形するおそれを警告している。**Standard にするなら、JLC に捨て基板を外してもらう。**
- Panel fee $8.21 の条件は「panelized designs > 1」（<https://jlcpcb.com/help/article/pcb-assembly-price>）。捨て基板に掛かるとは書かれていない。
- 位置合わせの印（Fiducials）は、基板の縁から 3.35 mm 以上離す（上の捨て基板の頁）。
- 「基板 1 枚あたりの最小の実装費 $0.48（下回れば差額）」は、この板では約 $0.68 / 枚なので**掛からない**。

**決めるのは利用者**（2026-10-04 の時点で、利用者は安い側 = A に傾いている。**まだ決めていない**）。違いはリフローの温度の余裕と費用:
温度の余裕を取るなら C（約 ＋$20〜$28）・費用を抑えるなら A（Alps の仕様書の上限 260 ℃に対して 255 ± 5 ℃。余裕 0〜10 ℃）。

**出どころ**（2026-10-04 に読んだ。値段はドル）

- 能力の表（Economic と Standard の違い・温度・大きさ・数・納期）: <https://jlcpcb.com/capabilities/pcb-assembly-capabilities>
- 値段（setup・ステンシル・部品ごと・はんだ付け・梱包・Panel fee）: <https://jlcpcb.com/help/article/pcb-assembly-price>
- 「縁から 0.3 mm」: <https://jlcpcb.com/help/article/pcb-assembly-faqs-part-2>
- 「本体と縁 2.5 mm」「洗わない」: <https://jlcpcb.com/help/article/Terms-and-Conditions-of-JLCPCB-Assembly-Service>
- 捨て基板と印の寸法: <https://jlcpcb.com/help/article/how-to-add-edge-rails-fiducials-for-pcb-assembly-order>

**注文画面を開かないと分からなかったこと**

- Standard で、捨て基板と印を JLC に足してもらえるか・その費用・基板そのものの値段が変わるか（板が 10 mm 太る）
- Economic で選べる表面処理と色の一覧（頁は「Limited options」だけ）
- 基板そのものの値段・送料・合計（推測で書かない）
- はんだ付けの「か所」の数え方が、こちらの数（ペーストの載るパッド 423 個／枚）と同じか

## §3 人が見ること（#31）

機械で確かめたのは「発注道具が出した CPL の位置と回転で、JLC の部品データのパッドが板の同じ番号のパッドに 0.15 以内で載る」こと（133 個）。
**JLC の画面で実際にそう置かれるかは、人が見る。**

**見る時が 2 回ある。**(1) 払う前: 注文の途中の配置のプレビュー（部品の向き。下の表の 1〜5 行目）。(2) **払った後・製造の前**: JLC が足した
位置決めの穴は、JLC の作った製造データに入る。Confirm Production file を Yes にしておくと、その確認が来る（表の 6 行目）。
前の版はこれも「払う前」と書いていた（1 回目の監査 C 軽微 3）。**確認が来る順番そのものは、JLC の頁では確かめられなかった**（注文して分かる）。

| 見る所 | 正しい姿 | 違ったら |
|---|---|---|
| ダイオード 63 個の帯（カソードの印） | キーの 62 個は帯が**左**（スイッチの手前・横向き）。D_PWR（左 Shift の左上）も帯が左 | 払わずに Claude に言う |
| 595 ×2（左 Shift の中） | 1 番ピンの丸が**右上**（奥の列の右端） | 同上 |
| 電源スイッチ（右の縁の近く） | つまみが**基板の外向き（右）**。本体は基板の縁から 1.75 内側・**つまみの先も縁の内側**（縁まで 0.30。ほとんど縁に届いて見える）。**そもそも置かれているか**（冒頭の「★ 先に読む」） | 向きが違う → 払わずに Claude に言う。置かれていない・断られた → 冒頭の手順で SW_PWR を外す |
| 電池クリップ（右の手前） | 口（丸くえぐれた側）が**手前**・折り返しの止めが奥 | 同上 |
| スイッチ 62 個 | ランド 4 つの真ん中に、回っていない | 同上 |
| **（払った後）** JLC が足した位置決めの穴（隅に 2〜3 個） | 銅・部品・ねじの穴（32 個）に掛かっていない | 承認せずに、位置を変えてもらう |

**JLC に聞かれうること・断られうること**

| 何 | こうする |
|---|---|
| 電源スイッチ MSK12C02 が「基板の縁に近い」と言われたら | **そのとおり**（本体は縁から 1.75。規約の 2.5 を満たさないのは承知している）。縁から出る物は無い（つまみの先は縁の 0.30 内側）、載せられるなら載せてほしい、と答える。断られたら、その 1 個を実装から外して（BOM と CPL の SW_PWR の行を消す）、届いてから手はんだ（7 か所。C431540 を 1 個買う）。**基板は変わらない**（冒頭の「★ 先に読む」） |
| 基板の手前の縁の、電池の所の穴 2 つ（H30・H31。部品の無い φ2.2 の穴）を聞かれたら | そのとおり（何も載せない穴。いまは使っていない） |
| 「部品の無いランドがある」（C_BAT・C_3V3）と言われたら | そのとおり（載せない。あとから手で足す場所） |
| 電池クリップ MY-1632-03-R（背 4.0）を Economic で載せられないと言われたら | Standard にするか、手はんだ（＋のランド 2 か所） |
| スイッチのはんだの量（Alps の仕様書 10.3(8) はペーストの厚さ 0.15 を勧める。**JLC のステンシルの厚さは調べていない**） | 届いたら、スイッチの端子にはんだが上がっているかをルーペで見る。足りなければランドにはんだを足す |
| 空きランド（はんだの載らない 22 か所 × 4 パッド）と TP_VSW に「部品が無い」と言われたら | そのとおり（載せない） |

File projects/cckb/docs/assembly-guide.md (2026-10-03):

# 組み立て手順書（CCKB）

**結論: 刷る → 基板を確かめる → 表の XIAO・電池ホルダ・電源スイッチ（この順）をはんだ付け → スタビを基板にねじ留め →
スイッチ 62 個を 1 個ずつ「足 1 本 → 平らか見る → 2 本目」ではんだ付け → ファームを焼いてキーを全部試す → ケースに入れる、の順。
**スイッチのプレートは使わない**（2026-09-26・[decisions/2026-09-26-plateless.md](decisions/2026-09-26-plateless.md)。戻し方は末尾の「プレートを戻すとき」）。
いちばん大事な決まりは「USB を挿す前に電源スイッチを OFF」と「ナットを入れたら裏返さない」。**

- 刷り方（スライサーの設定・小片の選び方・刷る順）の正本は [printing-and-assembly.md](printing-and-assembly.md) §1〜§4。ここでは繰り返さない
- 買う物は [shopping-list.md](shopping-list.md)、基板の頼み方は [order-steps.md](order-steps.md)
- 絵は `build/` にある（git に入れていない。無ければ `.venv/bin/python3 projects/cckb/case.py`〔STL・プレートの絵〕、
  `.venv/bin/python3 projects/cckb/assembly.py`〔断面図・分解図〕、`tools/kb cckb render`〔基板の絵〕、
  `.venv/bin/python3 projects/cckb/tools/draw_psw.py`〔`psw_section.png`・`psw_corner_iso.png`〕で出る）。
  全体の分解図は `build/cckb/assembly_exploded.png`、回して見られる模型は `build/cckb/assembly/cckb.blend`（Blender）

**道具**: はんだごて（細い先と、インサート用に太い先）・はんだ・フラックス・はんだ吸い取り線・テスター（導通と µA）・
ノギス・精密ドライバー（**軸の太さ 3.0 以下**。下の座ぐり φ4.2 に入る）・マスキングテープ・ニッパー。

---

## 手順 0. 刷る（基板を待つあいだに）

1. **小片を先に刷る**（4 個・約 1 時間 28 分。V2 の `coupon_stem` は十字の穴の格子と筒の外径・スタビの受け口、`coupon_stab_return`・
   `coupon_skin`〔キャップの膜 0.6 / 0.8 / 1.0。縁に爪をかけて 10 回抜き差し・縁を強く押して割れないか。**本番の既定は 1.0（2026-10-03）**。0.8 が割れなければ 0.8 に下げてよい。見積りでは 0.6 は割れる・open-gaps P17〕・`coupon_insert`）。実物（スイッチ・スタビ・インサート・M2 ネジ）をはめて値を選び、
   `case_spec.py`／`spec.py` を直して `case.py` で出し直す → [printing-and-assembly.md](printing-and-assembly.md) §1
   - **確かめ**: どの値を選んだかを台帳 [provisional-values-case.md](provisional-values-case.md) に書き、選んだ定数の `[暫定]` を外す
   - **インサートの外径**を測る。3.2 と違えば `INSERT_OD` も直す（3.8 を超える品は使わない。基板の銅に触れる・open-gaps P8）
2. **キーキャップ → ふた**を刷る（§2 の順。プレートは刷らない）。**キャップ一式は膜 1.0（`spec.KEYCAP_TOP_T` の既定）。`coupon_skin` で 0.8 が割れなければ 0.8 に下げて出し直してから刷ってよい**
3. **トレイは基板が届いて外形を測ってから**刷る（1 枚 約 3 時間半〔3h29m・3h12m・2026-09-26 のスライス〕。幅 286.35・奥行き 95.85 から +0.2 を超えたら
   `CASE_PCB_GAP` を上げて出し直す・open-gaps P12）

## 手順 1. 届いた基板を確かめる（はんだ付けの前）

1. **見る**: 裏に JLC が付けた部品が 69 個（ダイオード 63・IC 2・コンデンサ 2・抵抗 2）。ダイオードの帯の向きが
   全部そろっているか。**基板を左右に裏返して**（手前の縁は手前のまま）裏を見て: キーのダイオード **62 個とも縦で帯が手前**、
   D_PWR（横）だけ帯が左（板のカソード〔パッド 1〕の位置を KiCad で読んだ・2026-09-26。V2 ではスタビのキーも他と同じ
   位置・向き〔V1 の横 4 個は無くなった〕。上下に裏返すと 62 個が奥に見える・V2 監査 E 軽微 1）
2. **導通を見る**（テスター。電池も XIAO もまだ無い状態で）:

   | 当てる所 | 期待 |
   |---|---|
   | GND どうし（電池ホルダの − のパッドと、XIAO の GND のパッド） | 鳴る |
   | 電池ホルダの ＋ のパッド と GND | **鳴らない** |
   | XIAO の 3V3 のパッド と GND | **鳴らない** |
   | 電源スイッチの真ん中の穴（パッド 2） と 電池ホルダの ＋ | 鳴る |

   「鳴らない」の所で一瞬鳴って止まるのは、コンデンサが充電される音で正常。鳴り続けたらショート。
   **通るまで先へ進まない**（[fab-checklist.md](fab-checklist.md) §5）。XIAO を付けた後（手順 2）にも 3V3 と GND をもう一度見る
3. **外形をノギスで**（手順 0 の 3）

## 手順 2. XIAO を表の左の角に平らに付ける（スイッチより先）

**スイッチより先**なのは、隣のキーのスイッチが無い方がこてが入るから（ケースに入れた後も、左のふたを外せばこては届く）。
プレートを戻すときは、奥の列のパッドの外端がプレートの開口の縁とほぼ同じ位置（0.035 内）なので、なおさらプレートより先。

絵: `build/pcb_view/cckb.pcb.cckb_main__U_MCU.png`（基板）・`build/cckb/section_left_corner_usb.png`（断面）

1. **手前の列 D0〜D6 のパッドには穴（パッド内ビア φ0.8/0.3）がある**。先にビアの上にはんだを少し流して穴を埋め、
   **はんだ吸い取り線で平らにする**（山のまま載せると手前の縁だけ浮く）
2. **奥の列（D7〜5V）のランドの内側の端には、はんだを先に盛らない**。D7 のランドの奥の端から 0.43 先に XIAO の裏の
   NFC2 のパッドがあり、触れると CS が NFC の端子に繋がる（open-gaps A9）
3. XIAO を載せる。**USB 側の端を基板の縁より外に出さない**（壁の内面まで 0.53）。キャステレーション（縁の半円の穴）の
   側からこてを当てて、四隅 → 残りの順に付ける
4. **フラックスを IPA（イソプロピルアルコール）で拭く**。特に D0 のまわり: D0 は電池の電圧を測る分圧（1MΩ＋1MΩ）の
   真ん中に繋がっていて、残ったフラックスの漏れが読みを狂わせうる（4 回目の監査 D 軽微 3）
5. **確かめ**: 横から見て浮いていない。隣どうしのパッドがはんだで繋がっていない（ルーペ）。XIAO の裏の露出パッド 8 個と
   USB のシールドの長穴 4 個の下には表の銅が無い（設計で確かめた）ので、はんだが回り込まなければショートしない

## 手順 3. 電池ホルダを表の右の角に付ける（電源スイッチより先）

絵: `build/pcb_view/cckb.pcb.cckb_main__BT1.png`・`build/cckb/section_right_corner_cell.png`

**電源スイッチより先**なのは、ホルダの ＋ のパッドの右端と電源スイッチの本体の間が 0.5 しかなく、スイッチを付けた後は
＋ のパッドの外側にこてを当てにくいから（2026-09-24 に電源スイッチをホルダの右へ置いた）。

1. **＋ の向き**: ホルダの ＋ のクリップが**外側（右・電源スイッチの側）**。基板のシルクの ＋ に合わせる（シルクはホルダの縁に
   半分隠れる・open-gaps A5。載せる前にシルクを見ておく）
2. 端子 2 つをはんだ付け（パッドが大きいので、こてを長めに当てる）。＋ のはんだは右の電源スイッチの 3 つの穴に流さない
3. **確かめ**: 電池はまだ入れない

## 手順 4. 電源スイッチ SS-12D00G3 を表の右の縁に差して、裏からはんだ付け → 足を切る

絵: `build/cckb/psw_section.png`（断面: スイッチ・基板・ふたの穴と高さ）・`build/cckb/psw_corner_iso.png`（右の角を斜めから）・
`build/pcb_view/cckb.pcb.cckb_main__SW_PWR.png`（基板）

1. **付ける前にテスターで入の向きを確かめる**: レバーを片側へ寄せ、真ん中の足と**レバーを寄せた側の端の足**が導通する
   こと（図面の側面図と回路図の読み。基板は「レバーを奥へ押すと入」で、ふたに ON ↑ を刻んである）。逆に繋がる
   （レバーと反対側の足が導通する）なら、**付けずに Claude に言う**（ふたの刻印の向き spec.PSW_ON を反対にして刷り直す）
2. 表から 3 本の足を穴（φ0.8）に差す（向きはどちらでもよい——足は対称で、「レバーの側の足が繋がる」のは向きによらない）。
   本体を指で基板に押し付け、**本体の下の爪 4 つが基板に当たるまで**差し込む（本体はその分 0.4 浮くのが正しい）
3. 裏返して 3 本をはんだ付け（仕様書 JBL-SS/SK-2010 の手はんだ: 320±5℃・2±1 秒。長く当てない）。1 本付けたら表から見て
   傾いていないか確かめ、傾いていたらその 1 本を温め直して押す
4. **足を切る**: ニッパーで、はんだの山の上から**基板の下面から 1.0 以下**に切る（足は切らないと基板の下に約 1.9〜2.3 出て、
   床まで 1.8 しかないので床に当たる・`spec.PSW_PIN_TRIM`）。**キーのスイッチの足（手順 6）は切らない**のと違うので注意
5. **確かめ（電池を入れる前に）**: 電池ホルダの ＋ と D_PWR の帯の無い側（アノード）の導通 → レバーが奥（入）で鳴る・
   手前（切）で鳴らない。表から見て、レバーの先が基板の上面から 6.9 前後（名目。ふたの上面より 0.1 下になる高さ）。
   **ノギスで基板の厚さと、基板の上面からレバーの先までを測り、7.0 − (測った基板の厚さ − 1.6) 未満ならふたの上面から
   出ない**（ケースに入れた後は右のふたが基板を覆うので、ここで測る。公差の最悪では 0.36 出うる・open-gaps O13）。
   **切のとき、電源スイッチの奥の足（パッド 1）と真ん中の足（パッド 2）も鳴らないこと**を確かめる（open-gaps A11。
   枠の爪が両方のパッドに触れると OFF が効かなくなる。触れていたら爪の下にレジストか薄いテープを挟む）

## 手順 5. スタビを基板にねじで留める（Choc V2・`cckb-v2` の枝）

絵: `build/cckb/section_stab_pivot.png`・`section_stab_across.png`・`section_stab_across_pressed.png`（押し切り）・`section_stab_space.png`（どれも `assembly.py` が毎回出す）

スタビは遊舎工房の「Choc v2用スタビライザー 2U（スクリュータイプ）」A050001-01-1 ×4（Enter・左 Shift・スペースの左と右）。
**プレートには掛からない**（販売者「構造的にスイッチプレートレスでも使用できます」）。基板（1.6）に裏からねじで留める（販売者の図の断面 A-A: 箱の中にナット）。

1. **スタビ 4 組を先に基板に差して仮留めする**（スイッチより先: スタビの箱は基板の表から差し、爪は基板の裏で開く。スイッチが載ると箱の周りに指が入らない）。**ねじは裏から回すので、基板をトレイに入れた後（手順 8）は回せない**——本締めは手順 6 の 8（スイッチをはんだ付けした後・トレイに入れる前）。基板の**表**から:
   - 箱（5.80 × 7.30）を大きな四角い穴（6.0 × 8.0）に、爪（φ3.5）を奥の丸い穴（φ4.0）に差す。**ワイヤは奥側**（4 組とも。スペースも）
   - 爪が基板の裏でパチンと開くまで押す（爪の隙は 1.65。基板は 1.6 だが JLC の公差で最大 1.76 → きつければ無理に押さない・§10-5 の V3）
   - **穴がきつくて入らないとき**: ねじの穴（φ3.0）・爪の穴（φ4.0）はわざと小さめ（きつい側）に開けてある。丸やすりか 3.2 / 4.2 のドリル・リーマで
     少しずつ広げる（穴の中心から 2.6 の中には信号の線が無いので、削っても切れない）。箱の穴（片側 0.1）がきつければ、縁を平やすりで 0.1〜0.2 削る
   - **箱の穴の四隅**: 基板の加工（ルータの刃 φ1.0）で内の角に R0.5 の丸みが残る。箱（5.80 × 7.30）の尖った角は、名目では丸みの中に 0.073 の隙で入るが、外形の公差で穴が小さめだと角が当たって箱が沈まない。**当たったら四隅を細い丸やすりで少しずつ削る**（角の銅は縁から 0.3 引いてあり、削っても信号に当たらない）
   - 裏返して、手前の小さい穴から付属のねじを**仮留め**する（軽く当たるまで。頭 φ3.7〜3.85 は基板の下面に着き 1.5〜1.6 出る。床には頭の下に止まり穴 φ4.85 がある）。
     **板の置き方**: 表を上にして、留めるスタビの所を机の縁から外へ出し、スタビの箱を指で押さえて下からドライバーを入れる
     （表を下にして置くなら、XIAO 4.47・ホルダ 5.5・スタビの軸 8.6 より高い台〔高さ 9 以上〕を 2 つ、スタビの左右の基板の下に置く）
   - **本締めはまだしない**: 締める前のスタビは、ナットの胴 φ2.78 とねじの穴 φ3.0 の隙で **±0.11**（箱と箱の穴で x ±0.1）動く。
     キャップのスタビの十字の穴の隙は片側 0.05〜0.075 しか無いので、手順 6 の後で 2.25u のキャップを挿してから締める
2. **確かめ**: 軸（十字）を指で押して、左右が一緒に沈み、戻る。ワイヤが基板に擦れない

## 手順 6. スイッチ 62 個を、1 個ずつ平らに座らせてはんだ付け（プレート無し）

プレートが無いので、**スイッチの向きと傾きを決めるのは基板の穴だけ**（中心の突起 φ4.80 が穴 φ5.05 に、位置決めの突起が丸穴 φ2.1 に入る。
足 2 本は穴 φ1.2）。はんだの 1 本目で傾きが固まるので、**1 本目の後に必ず見る**。

1. **1 個を基板の表から差す**。中心の突起・位置決めの突起・足 2 本が 4 つとも穴に入る向きは 1 つだけ（入らなければ向きが違う。押し込まない）。
   **スイッチの下面が基板に全面で着くまで**押す（ハウジングの下面と基板の間に隙が見えない）
2. **スイッチの上からマスキングテープを 1 本渡して基板に押さえ**（テープの両端を基板の表に貼る）、基板を立てるか裏返す。
   足が抜けず、下面が基板から浮かないように（テープが緩いと 1 本目のはんだで浮いたまま固まる）
3. **足を 1 本だけ**はんだ付けする。**足の先にはんだの玉を作らない**（下の 6）
4. **表に返して見る**: スイッチが基板に浮かずに座っているか（横から見て、ハウジングの下面の四隅に隙が無い）・
   **隣のスイッチと辺が平行か**（真上から見て、キーの列に沿って揃っているか。定規を列に当てるとよい）。
   傾いていたら、1 本目のはんだを温めながらスイッチを指で基板に押し付けて直す（押したままこてを離し、固まるまで 2〜3 秒待つ）
5. **2 本目の足**をはんだ付けし、テープをはがす。これで傾きが固まる。以後、1〜5 を 62 個くり返す
   （列ごとに全部差してテープで押さえ、1 本目だけを先に付けて列を見てから 2 本目、でもよい）
6. 足をはんだ付けするとき: **足の先にはんだの玉を作らない**（フィレットは足に沿わせる）: 足は基板の下に最大 1.76 出る。
   トレイの床の内側には、足・中心の突起・スタビの箱とねじの頭の真下に**深さ 0.4 の止まり穴**（264 個。位置決めの足の下は丸 φ2.9・ねじの頭の下は φ4.85）があり、最悪の足でも穴の底まで 0.44 残る。
   玉があると穴の縁に乗って基板が浮き、がたつく。**足は切らなくてよい**（`spec.UNDER_PCB`・`FLOOR_POCKET_DEPTH`）。
   **切りそろえない**（2026-09-24 利用者の決定・open-gaps O10。厚さは床を 1.2 にして縮めた。切ると下の空きの前提が変わる）
7. **確かめ**: 表から見て、どのスイッチも基板に浮かずに座っていて、列が揃っている。裏の足の先がとがっていない。
   **キャップを挿したら（手順 7）、各キーの四隅・両端を押して傾く・カタつくキーが無いかを見る**（プレート無しの打鍵感は評価していない・open-gaps P16）
8. **スタビのねじを本締めする**（まだ裏返せるうちに・トレイに入れる前）: 2.25u のキャップ（または `coupon_stab_return` のキャップ）を
   **挿す前に、スタビの両端の軸（十字）を指でいちばん上まで引き上げておく**（軸にはばねが無く、下がったままだとキャップの受け口が軸の途中までしか掛からない）。
   スイッチとスタビの両端の軸に挿し、キャップを軽く押さえたまま、裏から各スタビのねじを締める（キャップがスタビの位置を決める。裏返した板ならキャップが机に載って押さえになる）。
   **締めすぎない**: ねじの穴と箱の穴の間の基板の橋は 0.7（公差の最悪で約 0.45）しか無い。頭が基板に着いてから軽く 1/8 回転まで。
   締めたらキャップを外し、押して左右が一緒に沈み戻るかを見る

スイッチの端子 2 のはんだは**盛りすぎない**: 端子 2 のランドと、隣のダイオードのアノードのパッドの間は 0.555 しか無い
（同じネットなので繋がっても電気は同じだが、玉がダイオードに乗ると後で外せない・V2 監査 B 軽微 3）。

## 手順 7. ファームを焼いて、キーを全部試す（ケースに入れる前に）

**USB を挿す前に電源スイッチを OFF。**（理由は下の「使い方」）

1. ファーム `cckb-xiao_ble__zmk-zmk.uf2` を GitHub の Actions（Build ZMK firmware の最新の成功した実行 → Artifacts の
   `firmware`）から取る。**どのコミットの物かを控える**
2. 電源 OFF のまま USB-C を挿し、XIAO のリセットボタンを**2 回すばやく**押す → ドライブが見えたら .uf2 をコピー
   （書き込みの「成功」を信用しない。ドライブの `CURRENT.UF2` の大きさを見る・[docs/knowledge/zmk-and-xiao.md](../../../docs/knowledge/zmk-and-xiao.md)）
3. USB のまま、メモ帳などで**62 キーを 1 つずつ**押し、全部が 1 回ずつ出るか見る。キー配置は HHKB の既定
   （`config/boards/shields/cckb/cckb.keymap`）。スペース 3 つは全部スペース
4. **同時押し**: 行列の四角の 3 つの角のキー（例 W・E・S）を同時に押して、4 つ目の角（D）が出ないか（ゴースト。キーごとのダイオードで防いでいる）。
   組は行列から選んだ: W＝行 1・列 3、E＝行 1・列 4、S＝行 2・列 3、D＝行 2・列 4（`cckb-transform.dtsi` の RC）。
   **見た目で四角でも行列で四角とは限らない**（例えば A・S・W の 4 つ目の角は行 1・列 2 で、そこにキーが無い。
   ダイオードが逆でも何も出ないので試験にならない・4 回目の文書の監査 重要 1）。`tests/test_cckb.py` が組を行列と突き合わせる
5. USB を抜き、**電池（CR1632・＋が上）を入れて電源 ON**。パソコン／スマホの Bluetooth に `CCKB` が出てつながるか。
   数キー打つ
6. **確かめ**: 出ないキーがあれば、そのキーのはんだ（手順 6）と、同じ行／列の他のキーが効くかで原因を分ける。
   列 1 本がまとめて効かなければ 595（JLC が付けた IC）の周り、行 1 本なら XIAO のはんだ（手順 2）を疑う

## 手順 8. ケースに入れる

絵: `build/cckb/section_mount_h0.png`（ネジ・ナット・ボス）・`section_left_corner_h3.png`（左のふた）・
`section_right_corner_cell.png`（右のふた）・`section_seam_*.png`（継ぎ目）

1. 電池を外し、電源 OFF
2. **インサートを熱圧入**: `tray_R` のふたの柱の上から 1 個、`lid_L` のボスの下面から 1 個（こてで押し込み、面一で止める）。
   `lid_L` のインサートの下の基板には表の銅が無い（H3 の禁止域）
3. **右のふたのネジを先に通す**: `lid_R` の天板の側から M2×6 をねじ込み、ボスの下の膜を抜けるまで回す。以後このネジは
   ふたから落ちない
4. **ナット 9 個**を基板の上の 9 か所の穴（キーの下の取付。左の角の H3 はナットではなくふたのインサート）に載せ、
   **穴の上にマスキングテープを貼って押さえる**。テープは**要る**: 下からネジをかけ始めるとナット（約 0.15g）が押し上げられて浮き、
   ネジ山が掛からない。キャップの下に隠れるので貼ったままでよい。**プレートが無いのでナットの回り止めが無い**
   （前はプレートの六角の穴が回り止め）: 7 で締めるとき、**上からピンセットでナットの平らな面 2 つを挟む**か、4mm のナット回しを被せて押さえる
   （ナットの中心からスイッチの胴まで 3.79 以上・つばまで 3.26 以上。ナット回しは外径 6.5 以下が入る。open-gaps P15）。
   **ここから先は裏返さない**——ナットが落ちる
5. **トレイ**（左右）を机に並べ、基板の塊を**上から**まっすぐ落とす。XIAO の USB-C が、壁の上に開いた切り欠きに入る
6. **左のふた**を載せる（舌が USB-C の口の上を塞ぐ）
7. 机の端から少し出して持ち上げ（裏返さない）、**下から M2×6 皿 10 本**を締める（9 本はナットへ、H3 は左のふたの
   インサートへ）。ナットは**上から押さえながら**（4）。ネジが回ってもナットが一緒に回るなら押さえが足りない。
   **締めすぎない**（PLA の座が潰れる）。外すときも同じくナットを上から押さえる（ナットの上のキャップ 7 個——Tab・左 Ctrl・左 Meta・
   スペースの真ん中・右のスペース・右 Shift・Del——を先に抜く）
8. **電池**（CR1632・＋が上）をホルダの ＋ のクリップの下へ斜めに入れ、反対側を押し下げる
9. **右のふた**を真上から載せる。電源スイッチのレバーが、ふたの右端の四角い穴（6.4 × 2.4）に下から入る（レバーはどちらの端でも
   穴の中）。上からネジ（3 で通した物）を柱のインサートへ締める
10. **キーキャップ**を挿す。十字の筒をスイッチの十字に真上から（静音の V2 の窪み φ5.7 に入る）。2.25u はスタビの軸にも天板の下の細い台（φ5.1）の十字の穴が入る（軸を 2.0 掴む。押し切ると台はスタビの箱の上面の口に入る）。
    **斜めにこじらない**（筒の腕の先の肉は 0.675。抜くときは真上へ・§10-5 の V11）。**天板の縁に爪をかけて片側から抜かない**:
    ステムのまわりの輪（つばの上）は天板のいちばん薄い所（膜 1.0 で 0.6。2026-10-03）で、片側からこじるとその輪に曲げが集まる
    （決定記録 2026-09-28-keycap-skin §4・§8）。キーキャップ引き抜き工具（2 本の爪で両側から）でまっすぐ上へ
11. 底の 4 つのくぼみ（**12×6**。奥の 2 つは角から少し内側・最上段と 2 段目の間）に**滑り止め**を貼る
12. **確かめ**: ふたの穴に上から爪を差し込んで、電源スイッチのレバーを両端まで擦れずに動かせるか。レバーの先がふたの上面から
    出ていないか（**ふたの上面に定規を渡すか、ノギスのデプスを当てる**。基板の上面からの高さは手順 4 の 5 で測った・
    公差の最悪では 0.36 出うる・open-gaps O13）（open-gaps P4）。USB-C のケーブルが奥まで挿さるか（P2）。
    机の上でがたつかないか。重さと厚さを量って記録する（設計書 §10b）

**電池を替えるとき**: 電源スイッチを OFF → 右のふたのネジを緩める（ネジはふたに残る）→ ふたを真上に外す（レバーは穴の中を
縦に抜ける）→ 電池をクリップと反対の縁から起こして出す。

---

## 使い方（説明書に書くこと）

- **USB を挿す前に電源スイッチを OFF にする。**USB を挿したまま ON にすると、USB の 3.3V からショットキー（D_PWR）の
  逆向きの漏れ電流が電池の側へ流れる。D_PWR の BAT46W（C54110）なら 25℃ ではデータシートの保証値でも分圧が吸う方が多く
  電池には入らないが、40℃ を超えると保証が無い
  （Energizer の上限 1µA。決定記録 2026-09-24-audit-fixes §S2・open-gaps 受け入れた差 A1）。**OFF なら電池は回路から
  完全に切り離される**。ファームの書き込み・USB での打鍵も OFF のまま行う
- OFF で USB を挿しているあいだは、電池の残量が実際と違って表示されることがある（ショットキーの漏れが電池の電圧を測る
  分圧に入るため。害は無い・open-gaps A2）
- 電源スイッチは右のふたの穴のレバーを爪で**奥へ押すと入**（ふたの「ON ↑」の向き。部品が届いたら手順 4 の 1 で確かめる）
- **OFF にしたら数秒待ってから ON にする。**すぐに入れ直すと、XIAO の中のコンデンサに電気が残っていてリセットされず、
  「入れ直したのに点かない」に見える（HHKB 分割機で起きた・HHKB open-gaps #44。待つ時間は基板が届いたら測る）。
  電池が尽きて自分から止まったとき（打ち止め）と、スリープから戻らないときは、どちらも電源の入れ直しで戻す
- パソコンに出る電池の % は目安にならない。CR1632 は使っている間の大半を平らな電圧で過ごし、終わり近くで急に落ちるので、
  ほぼずっと 6〜7 割に見える見込み（放電曲線の図の読み・測っていない。4 回目の監査 F 軽微 3）。電池が尽きる前触れは
  ほかに無く（状態の LED は使っていない・open-gaps F8）、尽きると黙って止まる
- 鞄に入れるときは OFF（キーが押されて起きるのを止める）
- USB を挿しているあいだは、キーで Bluetooth に戻せない（USB を抜く。open-gaps F1）

---

## プレートを戻すとき

プレート（PLA 1.2・左右 2 枚＋スペースの枠 2 つ）は 2026-09-26 に使わないと決めた（ねじ留めのスタビは基板に留まる・
[decisions/2026-09-26-plateless.md](decisions/2026-09-26-plateless.md)）。**傾き・打鍵感が許せなければ（open-gaps P16）戻す。基板は同じ**。

1. `projects/cckb/spec.py` の **`PLATE = False` を `True`** にする
2. `.venv/bin/python3 projects/cckb/case.py` → `build/cckb/` に `plate_main_L.stl`・`plate_main_R.stl`・`plate_frames_main.stl` と
   プレートの小片 3 つ（`coupon_switch`・`coupon_stab`・`coupon_nut`）が出る（`plate_optional/` の物と同じ形）。
   `.venv/bin/python3 projects/cckb/assembly.py` と `.venv/bin/pytest tests -q` で、プレートを置いた組み立ての干渉・経路を見る
   （検査は使わない間もプレートありの形を毎回見ている）。`tools/kb cckb slice --printer a1mini` で刷る物に入ったことを確かめる
3. **刷る**: 小片 3 つ（約 29 分）で開口 13.95・スタビの羽の広げ・ナットの六角の穴 4.2 を選び、プレート 2 枚と枠（約 2h28m・15.3 cm³・約 19g）
4. **決めること（open-gaps O15 が戻ってくる）**: スペースの 2 キーは羽がプレートの手前の縁まで抜けて、スイッチの周りの板が切り離される。
   (a) 別に刷る枠 2 つで囲む（既定）か、(b) ケースの手前の面を約 1.0〜1.1 前へ出して一枚のプレートにするか（奥行き 99.45 → 約 100.5）。
   枠はスイッチのつばと爪に挟まるだけで、プレートにも基板にも留まらない（決定記録 2026-09-25-choc-v2 §10-6）
5. **組み立ての順が変わる**: 手順 5 のスタビの仮留めの後にプレートを載せる（スタビの本体は U 字の羽の穴を通る。羽の奥の縁と爪の間は図で 0.47・V9）。
   手順 6 は**62 個を全部プレートにはめてから**一度にはんだ付けする（1 個ずつ付けるとプレートの位置がずれて後のスイッチが入らない）。
   スペースの 2 個は先に枠をスイッチの胴にはめてから枠ごと（枠の開いた側が奥）。
   手順 8 の 4 のナットはプレートの六角の穴から落とす（回り止めが効くので上から押さえなくてよい。テープは要る）
6. 見本で確かめること（open-gaps P13 の V4・V9・V10、P8 のスイッチ・スタビの開口・ナットの六角の穴）が戻ってくる

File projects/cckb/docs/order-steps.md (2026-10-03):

# 基板を JLCPCB に頼む手順（CCKB）

**結論: 基板のデータは出来ている。頼む前に利用者がやることが 5 つ残っている（下の §1。2 の O12 は 2026-09-25 に決まり、4 の見本は 2026-09-26 に基板の後へ回した）。
全部済んだら、ZIP・BOM・CPL の 3 ファイルを JLCPCB に上げ、下の表のとおりに選び、配置のプレビューで
部品の向きを 4 か所見てから払う。**

- 発注の門: `tools/kb cckb gate` がいま「**閉 — #1・#4**」を出す（2026-09-26 に #6〔V2 の見本〕を取り下げて再び確かめた）。#1 と #4 を閉じると「開」になる
- 発注前の確認表の正本は [fab-checklist.md](fab-checklist.md)。この文書はそれを**上から順にやる手順**にしたもの
- 買う物は [shopping-list.md](shopping-list.md)、組み立ては [assembly-guide.md](assembly-guide.md)

---

## §1 頼む前に閉じるもの（この順で）

**先に日本橋の店頭（電源スイッチ）で部品を買う**（[shopping-list.md](shopping-list.md)）。下の 3 は届いた部品で確かめる。4（スイッチ・スタビの見本）は**基板を頼んだ後でよい**（2026-09-26）。1 は部品を待たずにできる（手持ちの物だけ）。

| 順 | 何（台帳の番号） | どうやって閉じるか | 駄目だったら | 決めないとどうなるか（既定） |
|---|---|---|---|---|
| 1 | **CR1632 で起動できるか**（open-gaps **#1**・門を止めている） | [task-10a-coin-cell-startup.md](task-10a-coin-cell-startup.md) を上から。可変電源から抵抗 0/25/50/75/100Ω を挟んで XIAO の 3V3 へ（ダイオードなし）、電圧を下げながら各段で入れ直し、5 回とも起動する最低の電圧を測る。新品の CR1632 で 1 回突き合わせる。電池とダイオード（BAT46W の保証値）は紙の上で載せる。合格の基準は手順書 §6 の (a) 21℃ の新品・(b) −10℃ の新品。結果の「使える量」で open-gaps **O14**（バルクコンデンサの場所を置くか。96mAh 未満なら決める）も決まる。所要 約 1.5 時間・買う物なし | CR2032 に替える判断を Claude に返す（ホルダ・右の角の設計をやり直す。基板も変わる） | 門が開かない（発注できない） |
| 2 | ~~**D_PWR の品番**（open-gaps **O12**）~~ **2026-09-25 に決まった: BAT46W（C54110）** | 何もしない。保証値で決まった（Vf ≦0.45V@10mA・25℃ では USB 給電中に電源 ON でも電池へ逆流しない）。比べた表は [decisions/2026-09-24-audit-fixes.md](decisions/2026-09-24-audit-fixes.md) §S2 | — | BAT46W で頼まれる。1 の判定はこの Vf の保証値で見る |
| 3 | **電源スイッチ SS-12D00G3 の入の向きと高さ**（open-gaps **P5**・**O13**） | 届いた 1 個で: (a) レバーを片側へ寄せ、テスターで真ん中の足と**レバーの側の端の足**が導通するか（図面の読み）。(b) **基板の厚さをノギスで測る**（公称 1.6）。足を基板の端材か厚紙（実測した厚さの物）に差し込んで押し付け、**板の上面からレバーの先まで**をノギスで測り、**7.0 −（測った基板の厚さ − 1.6）未満**か確かめる（基板厚が公称どおりなら名目 6.9 ＝ 爪 0.4 ＋ 本体 3.5 ＋ レバー 3.0 で 7.0 未満ならふたの上面から出ない） | (a) が逆なら、ふたの刻印の向き（`spec.PSW_ON`）を反対にする（**板は変わらない**。足が対称で、どちらの端の足を入にしても向きは同じ）。(b) が閾値以上なら O13 の選択肢を Claude に言う | (a) 図面の読みのまま刷られる。逆なら刻印と逆の向きが入になる（壊れない）。(b) レバーの先がふたの上面から最大 0.36 出る（本体・レバー・基板の厚さの公差を積んだ最悪） |
| 4 | ~~**スイッチ・スタビの見本で基板に効く所**（open-gaps **#6**）~~ **2026-09-26 取り下げた（基板の後でよい）** | スタビの穴は販売者の足跡（実物の実測）、スイッチの穴は Kailh の推奨の足跡で決まっている（外の事実）。穴はきつい側に開けてあり、入らなければ手で広げる（手順書 手順 5）。見本は刷る物（キャップの受け口・小片）を合わせるときに測る（open-gaps **P13**。前の (a) 下面の突起が φ2.1 に入るか・(b) 支点・箱・ナットの胴・爪の輪・ねじの頭はそこへ移した） | 支点・箱・胴・爪が穴より大きくて手で広げきれないとき（0.3 超）は Claude に言う | 足跡（販売者の実測）の値で頼まれる |
| 5 | **アンテナのまわりを ¥0 で 1 回測る**（open-gaps **P7**・強く勧める） | [docs/knowledge/rf-antenna.md](../../../docs/knowledge/rf-antenna.md) の手順。XIAO の手前と奥をアルミ箔で覆い、M2 ネジ 1 本とインサート 1 個を H3 の位置に置いて（4 回目の監査 D 軽微 1）、スマホの nRF Connect で RSSI を覆う前と比べる | 20dB 以上悪くなったら Claude に言う（基板の改版） | 試作で RSSI を見るまで分からない |
| 6 | **595 の末端を XIAO に戻すか**（open-gaps **O11**） | 要るか要らないかを決めるだけ。戻すと「SPI で送った値が戻ってくるか」をファームで確かめられる（数珠つなぎの断線を自分で見つけられる）。HHKB 分割機は戻していない | 「戻す」なら Claude に言う（回路 1 本・配線し直し・overlay。**発注前にしか足せない**） | **戻さない**（HHKB と同じ）。困るのは試作で列が効かないとき、原因を切り分ける道具が 1 つ少ないだけ |
| 7 | **人の確認**（open-gaps **#4**・門を止めている） | 下の §4 の「ピン配置を 3 つの目で」と、§3 の JLC の配置プレビュー | 違いが見つかったら払わずに Claude に言う | 門が開かない |

ケースの形（トレイ＋ふた・O8）は **2026-09-24 に利用者が決めた（このまま）**。基板の取付穴はこの形に乗っている。
プレートの縁を隠す飾りの縁（案 C）はあとから壁に嵌めるだけで基板は変わらないので、発注の前に決めなくてよい。
厚さ（O10）も決まった（床 1.2・V1 のとき 13.8mm。いまは Choc V2 ＋ キャップの膜 1.0 で 14.2mm。ケースだけで基板は変わらない）。継ぎ目（O9）はケースだけで、基板の後でよい。

1〜7（2・4 を除く）が済んだら:

    tools/kb cckb parts        # 在庫を取り直す（74LVC595 C52287685 は 1,446 で薄い。10 を割ったら代替 C426713 に BOM だけ替える）
    tools/kb cckb gate         # 「開」になること

open-gaps の #1・#4 は**行を消さずに取り消し線**を引き、何で確かめたかを書く（台帳の約束）。

## §2 発注ファイルを出し直して、JLCPCB に上げる

板 `projects/cckb/pcb/cckb_main.kicad_pcb` から、発注道具（Fabrication Toolkit）で出す。ファイルは
`projects/cckb/pcb/production/`（git に入れていないので、頼む直前に出し直す）:

    tools/kb cckb fab-fields
    cd ~/Documents/KiCad/10.0/3rdparty/plugins
    /Applications/KiCad/KiCad.app/Contents/Frameworks/Python.framework/Versions/3.9/bin/python3.9 \
      -m com_github_bennymeg_JLC-Plugin-for-KiCad.cli \
      -p "<リポジトリの絶対パス>/projects/cckb/pcb/cckb_main.kicad_pcb" -t -nI -nB

| 上げるファイル | 中身（2026-09-24 に読んだ） |
|---|---|
| `production/cckb_main.zip` | ガーバー 13 ファイル（銅 2 層・マスク・ペースト・シルク・外形・PTH/NPTH のドリルと図） |
| `production/bom.csv` | **4 行**: C49678×2・C54110×63（キー 62＋D_PWR）・C17514×2・C52287685×2 |
| `production/positions.csv` | **69 行・全部 bottom** |

出し直したら `bom.csv` が 4 行・`positions.csv` が 69 行（全部 bottom）であることを目で見る。
XIAO・電池ホルダ・キーのスイッチ・電源スイッチは**入っていないのが正しい**（手はんだ）。

### JLCPCB の注文画面で選ぶもの

<https://jlcpcb.com/> → 「Order now」→ ZIP を上げる。

| 項目 | 選ぶ値 | なぜ |
|---|---|---|
| Base Material | FR-4 | |
| Layers | **2** | 2 層で足りた |
| Dimensions | 自動で 286.35×95.85 mm と出るはず | 違ったら ZIP の外形を疑う |
| PCB Qty | 5（最小） | |
| PCB Thickness | **1.6** | 背骨。たわみ 10N で 0.136mm（O3） |
| PCB Color | 自由（緑がいちばん安く早いことが多い） | |
| Surface Finish | **HASL（with lead）** | 無鉛にする理由が無い（fab-checklist §0） |
| Outer Copper Weight | **1 oz** | |
| Via Covering | **Tented**（既定のまま） | 板の設定がテント。XIAO の手前の 7 穴は部品の穴なので、この選択は効かない |
| Remove Order Number | **Yes**（fab-checklist §0 のとおり） | 表に番号を刷らせない |
| **PCB Assembly** | **オン** | |
| PCBA Type | **Economic** | Standard は部品から板端 2.5mm 以上が条件で合わない |
| Assembly Side | **Bottom Side** | 部品は全部裏 |
| PCBA Qty | 2（最小。1 台なら 2 で足りる） | |
| Tooling holes | JLC に任せる（Added by JLCPCB） | Economic では位置決めの穴（φ1.152 の NPTH を対角の隅に 2〜3 個）が必須で、この板には無いので**JLC が必ず足す**（JLC の記事 How to add tooling holes）。左上・右上・右下の隅には空きがあるが、**左下（XIAO の角）は 20×20 の範囲に空きが無い**（4 回目の監査 C 軽微 1）→ 下の Confirm Production file で位置を見る |
| **Confirm Production file** | **Yes** | JLC が返す製造データで、足した位置決めの穴の位置を §3 で見るため |
| **Confirm Parts Placement** | **Yes** | §3 の向きを自分で見るため |

「Next」で BOM と CPL を上げる。**BOM の突き合わせ画面で 4 行とも部品が見つかり、在庫があること**を見る
（C52287685 が足りなければ、戻って BOM の番号を C426713 に替える。ピン配置と 1 番の位置は同じ・open-gaps A4）。

**ここで代金が出る**（基板・組立・部品・送料）。この文書では代金を出していない（JLC の見積もりは画面でしか正確に出ない）。
**見積もりに「Keyboard Design」の追加料金（$16.41＋$49.25/m²。5 枚なら約 $23）が乗ることがある**。JLC の追加料金の規定
（<https://jlcpcb.com/help/article/in-what-cases-will-there-be-charged-extra>。判定の基準は書かれていない）で、スタビの逃げ穴 8 個と
キーのスイッチ 62 個からキーボードと判定される見込みが高い。規定どおりの料金なので断る理由にならない（4 回目の監査 C 軽微 2）。
参考に、部品代と Extended の段取り費だけで 2 枚実装 約 $10.8（[shopping-list.md](shopping-list.md) §6）。

## §3 配置プレビューで見る 4 か所（払う前に）

プレビューは **Bottom 表示で左右が裏返る**。「+」の印は 1 番ではなく**アノード**（HHKB で確かめた）。
**判定は部品の 3D の本体の帯（カソード）と、IC の 1 番の丸で**。同じ形の部品は 1 個見れば全部同じ。

| 部品 | 板の上で（表から見て） | プレビューで見ること | 絵（板） |
|---|---|---|---|
| U1 SN74LVC595 | 1 番は**右上**（16 番は左上で C_U1 の隣） | 1 番の丸（または面取り）が、C_U1 から遠い側の角 | `build/pcb_view/cckb.pcb.cckb_main__C_U1.png` |
| U2 SN74LVC595 | 1 番は右上（16 番は左上で C_U2 の隣） | U1 と同じ | — |
| キーのダイオード（**62 個とも縦**。板の上で 90°。スタビのキー D42・D43・D58・D60 も同じ向き。例 D1） | 帯（カソード＝パッド 1・行の網）が**手前（−y）** | 帯が手前の側 | `build/pcb_view/cckb.pcb.cckb_main__SW54.png` |
| D_PWR（電源のショットキー。板の上で 180°） | 帯（カソード＝パッド 1・V3V3）が**右**（XIAO の 3V3 へ行く側） | 帯が右の側（プレビューは左右が裏返るので、画面では左に見えることがある——表から見た向きに直して判定する） | `build/pcb_view/cckb.pcb.cckb_main__D_PWR.png` |

**位置決めの穴**（Confirm Production file で JLC が返すデータ）: JLC が足した φ1.152 の穴が、線・部品・XIAO の下に
掛かっていないかを見る。**左下（XIAO の角）に来ていたら払わずに断り、別の隅を頼む**（空きがあるのは左上・右上・右下。
4 回目の監査 C 軽微 1。GND のベタに穴が 1 つ開くだけなら害は無い）。

**JLC の DFM が「穴と基板の縁（hole to board edge）」を出したとき**: スタビのねじの穴 φ3.0 と箱の穴（外形の内側の穴・Edge.Cuts）の間の基板の橋は 0.7 しか無い（決定記録 2026-09-25-choc-v2 §10-9。わざと決めた値・手順書で締めすぎない）。JLC がこれを見つけて「穴を動かす・小さくする」などの直しを提案しても、**中身を読んでから**決め、黙って受け入れない（穴の位置と径はスタビの実測に合わせてある。動かすとスタビが付かない）。分からなければ払わずに Claude に言う。

絵は `tools/kb cckb render` で出る（build/ は git に入れていない）。見た結果は [fab-checklist.md](fab-checklist.md) §1 の
「JLC のプレビュー」「判定」の欄に日付つきで書く。**1 か所でも逆なら払わずに JLC の画面で回転を直す**（直した角度も書く）。

## §4 ピン配置を 3 つの目で（open-gaps #4 の残り）

[fab-checklist.md](fab-checklist.md) §3 の表の B・C・D の欄を埋める。A（データシート ↔ 設計）は済んでいる。
**同じ人が同じ表を読み返すのは 1 つの目にしかならない**ので、見方を変える。

| 目 | やること | 対象 |
|---|---|---|
| B 商品写真 | LCSC・Amazon（XIAO）・共立エレショップ（電源スイッチ・ホルダ）の商品写真で 1 番（丸・帯・＋の印）の位置を見て、KiCad の板の絵（`build/pcb_view/…__U_MCU.png`・`__BT1.png`・`__SW_PWR.png`）と向きを合わせる | 74LVC595・XIAO・SS-12D00G3・BS-16-B4AK003 |
| C KiCad でクリック | KiCad で `cckb_main.kicad_pcb` を開き、パッドをクリックしてネット名を読む: U1 の 12 番＝CS、XIAO の D7＝CS、BT1 の＋（パッド 1）＝VBAT_IN、SW_PWR の 2（真ん中）＝VBAT_IN・1（奥）＝VBAT_SW・3（手前）＝無し | 同上 |
| D 1:1 の印刷 | KiCad から板を 1:1 で紙に印刷（「実際のサイズ」）し、届いた実物（XIAO・電池ホルダ・電源スイッチ）を載せて、足とパッドが重なり＋の向きが合うかを見る（電源スイッチは紙に足を差して 3 つの穴に合うか） | XIAO・BS-16-B4AK003・SS-12D00G3 |

3 つ済んだら open-gaps #4 に取り消し線を引き、`tools/kb cckb gate` が「開」になることを見る。

## §5 頼んだ後

- [fab-checklist.md](fab-checklist.md) の「発注履歴」に 1 行（日付・枚数・表面処理・D_PWR の品番・注文番号）
- 基板が届いたら: 外形をノギスで測る（幅 286.35・奥行き 95.85。±0.2 を超えたら Claude に言う・open-gaps P12）、
  通電の前に導通を見る（fab-checklist §5）。組み立ては [assembly-guide.md](assembly-guide.md)

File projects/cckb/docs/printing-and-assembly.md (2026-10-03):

# 刷り方（CCKB）

プリンタは **Bambu Lab A1 mini**（0.4 ノズル）、材料は **PLA**。STL は全部
`.venv/bin/python3 projects/cckb/case.py` が `build/cckb/` に出す。
**2026-09-26 からスイッチのプレートを使わない**（決定記録 [decisions/2026-09-26-plateless.md](decisions/2026-09-26-plateless.md)）。
プレート 2 枚・スペースの枠・プレートの小片 3 つ（`coupon_switch`・`coupon_stab`・`coupon_nut`）は刷らない。
`case.py` はそれらも毎回作り、刷る物の外の `build/cckb/plate_optional/` に出す（戻すときに使う・[assembly-guide.md](assembly-guide.md)「プレートを戻すとき」）。
**どの STL も刷る向きに回してある**ので、スライサーでは回さずに置くだけでよい。

設計の理由は `decisions/2026-09-24-case.md`、形の境界は `decisions/2026-09-24-interface.md`。

---

## 1. まず小片（クーポン）を刷る — 本番の前に

嵌め合いはまだ測っていない。**本番を刷る前に小片を刷り、実物をはめて選ぶ。**どの穴かは縁の
切り欠きの数で見分ける（1 本目 = 表の左の値）。選んだ値は `projects/cckb/case_spec.py`
（か `spec.py`）を直し、`case.py` で出し直してから本番を刷る。

| STL | 何を確かめる | 並んでいる値（切り欠き 1 本目から） | 実物 | 直す値 |
|---|---|---|---|---|
| （プレートを戻すときだけ）`plate_optional/coupon_switch.stl` | スイッチがプレートに「パチッ」とはまり、指で押しても抜けないか。**爪がどの辺に掛かるか**（±x と読んだ・決定記録 V10） | 開口 13.90 / 13.95 / 14.00 / 14.05 | 静音の Choc V2 1 個 | `mech.CHOC_V2.cutout`（核。いま 13.95） |
| （プレートを戻すときだけ）`plate_optional/coupon_stab.stl`（3 枚） | V2 のスタビ（ねじ留め・プレートには掛からない）の本体とワイヤが U 字の開口の縁に触れないか（上から被せて見る。奥の縁 10.72 と爪・V9） | 広げ 0.05 / 0.15 / 0.25 | Choc V2 スタビ 1 組 | `mech.STAB_KERF`（核。いま 0.15）・`CHOC_V2_STAB_PLATE_BACK` |
| `coupon_stem.stl`（7 枚） | 1 段目（格子 12 本）: 十字の筒が静音の V2 に真上から挿さり、逆さにしても落ちず、ぐらつかないか。2 段目の小さな天板 3 枚: 筒の外径が窪み φ5.7 に入るか・**天板の縁に爪をかけて 10 回抜き差しし、腕の先（肉 0.675）が割れないか**。スタビの板 3 枚（支点 23.8）: 届いたスタビの軸の両端に挿して、抜けずにがたつかない幅 | 格子: 十字の穴の幅 1.35 / 1.40 / 1.45 / 1.50（列・手前の切り欠き 1〜4 本）× 長さ 4.10 / 4.15 / 4.20（行・左の切り欠き 1〜3 本）。外径 5.3 / 5.4 / 5.5（切り欠き 1〜3 本）。スタビの十字の穴の幅 1.31 / 1.36（本番）/ 1.41（1〜3 本） | 静音の Choc V2 1〜2 個・V2 スタビ 1 組 | `STEM_CROSS_SLOT`・`STEM_TUBE_OD`・`STAB_CROSS_SLOT` |
| `coupon_stab_return.stl`（2 個） | **スタビの軸がキャップと一緒に戻るか**（監査 E 重要 1）: 基板の代わりの板（厚さ 1.6・本番の基板と同じ穴の位置・刷った穴は片側 0.15 広げてある）にスタビをねじで留め、スイッチを挿し、本番と同じ 2.25u のキャップを挿す。押し切って離し、両端の軸がキャップと一緒に上まで戻るか（10 回）。押し切りで台（φ5.1）が箱の上面の口に擦れ・引っ掛からないか | 台の高さ（掴む深さ）2.0・台の径 5.1 | 静音の Choc V2 1 個・V2 スタビ 1 組（付属のねじ） | `STAB_SOCKET_GRIP`・`STAB_SOCKET_BOSS_D`・`STAB_CROSS_SLOT`（**戻らなければまず十字の穴の幅を締める**〔`coupon_stem` の幅 1.31 の板〕、それでも戻らなければ深く。擦れれば細く） |
| `coupon_skin.stl`（3 個） | **キャップの膜が割れないか**（2026-09-28・決定記録 2026-09-28-keycap-skin・open-gaps P17）: 本番の 1u のキャップを膜の厚さだけ変えた物。静音の V2 に挿し、**天板の縁に爪をかけて 10 回抜き差し**、**縁の真ん中を指で強く押す（10 回）**。膜・つばの上の輪（膜の中に透けて見える φ6.5〜8.7 の輪）が割れない・白くならない・筒が取れない・押したたわみが気にならないか。**見積りでは 0.6 は縁の押しで割れる**（3 N で 118 MPa・0.8 は 43・1.0 は 22）。**2026-10-03 から本番の既定は 1.0** | 膜 0.6 / 0.8 / 1.0（本番）（スカートの手前の下端の切り欠き 1〜3 本。つばの上の輪は 0.2 / 0.4 / 0.6） | 静音の Choc V2 1 個 | `spec.KEYCAP_TOP_T`（いま 1.0。0.8 が割れなければ 0.8 に下げてよい。全体は 13.8 / 14.0 / 14.2） |
| （プレートを戻すときだけ）`plate_optional/coupon_nut.stl` | M2 ナットがプレートの六角の穴に落ちて入り、ドライバーで回しても回らないか | 二面幅 4.1 / 4.2 / 4.3 | M2 ナット | `spec.MOUNT_POCKET_AF`（境界。いま 4.2） |
| `coupon_insert.stl` | 左 3 本: インサートを熱圧入して割れず・回らないか。右 3 本: 下から M2 をねじ込み、膜を抜けて止まり、逆さにしても落ちないか | 下穴 2.9 / 3.0 / 3.1、膜の穴 1.4 / 1.6 / 1.8 | M2 インサート・M2×6 皿 | `INSERT_HOLE_D`・`CAPTIVE_HOLE_D` |

設定は下の §3 と同じ。**刷る小片は 4 つ**（`coupon_stem`・`coupon_stab_return`・`coupon_skin`・`coupon_insert`。約 1h28m・7.95 cm³・約 10g。
2026-10-03 の A1 mini のスライス: 40m17s・23m30s・12m21s・11m23s。`coupon_stem`・`coupon_stab_return` は本番と同じ天板の厚さ〔膜 1.0〕で作るので、膜 0.6 のときより長い）。
**キャップ一式（`keycaps_set_*`）は膜 1.0（既定・2026-10-03）**。`coupon_skin` で 0.8 が割れなければ 0.8 に下げて出し直してよい。プレートの小片 3 つは刷らない（戻すときだけ・約 29 分・2.85 cm³）。
見本（スイッチ・スタビ）は**基板を頼んだ後に買ってよい**（小片を合わせるためにしか要らない・open-gaps #6 を 2026-09-26 に取り下げた）。

スペースの 2 キーの「枠」`plate_frames_main.stl` は**プレートを戻すときだけ**（`plate_optional/`・決定記録 2026-09-25-choc-v2 §10-6）。

## 2. 本番の STL と刷る順

**順番**: 小片 → キーキャップ（`coupon_stem` で十字の穴を決めてから。膜は既定 1.0・`coupon_skin` で 0.8 に下げられるか見る）→ ふた → トレイ（インサートの小片で決めてから）。
トレイは 1 枚 3 時間半かかるので最後。プレートは刷らない（2026-09-26）。

**トレイを刷る前に、届いた基板の外形をノギスで測る**（幅 286.35・奥行き 95.85 が設計値。JLC の外形公差は
±0.2）。トレイの壁の内面は基板から片側 0.5 離してある（`spec.CASE_PCB_GAP`・2026-09-24 に 0.2 から広げた）ので、
+0.2 でも入る。それより大きければ `CASE_PCB_GAP` を上げて `case.py` で出し直す（open-gaps P12）。

| STL | 数 | 向き（回してある） | サポート | 時間（見積もり） | 材料 |
|---|---|---|---|---|---|
| `keycaps_set_1u.stl`（1u を 51 個並べた物） | 1 | 天板を下（筒とスカートが上。膜は 1〜5 層目・つばの上の輪は 1〜3 層目） | 無し | 3h42m | 21.59 cm³ |
| `keycaps_set_wide.stl`（1.5u ×5・1.75u ×2・2.25u ×4） | 1 | 同上 | 無し | 1h22m | 8.30 cm³ |
| `lid_L.stl`（左の角のふた・XIAO の上） | 1 | 天板を下 | 無し | 11m | 1.07 cm³ |
| `lid_R.stl`（右の角のふた・電池のふた。電源スイッチのレバーの穴と「ON ↑」の刻印は天板＝1 層目の側） | 1 | 天板を下 | 無し | 16m | 1.70 cm³ |
| `tray_L.stl` | 1 | 床を下 | 無し | 3h29m | 22.91 cm³ |
| `tray_R.stl` | 1 | 床を下 | 無し | 3h12m | 21.04 cm³ |
| （プレートを戻すときだけ）`plate_optional/plate_main_L.stl`・`plate_main_R.stl`・`plate_frames_main.stl` | 各 1 | 平ら（厚さ 1.2） | 無し | 1h15m・1h10m・3m | 7.84・7.20・0.29 cm³ |

**2026-10-03（キャップの膜 1.0）: 合計 約 12h13m・76.6 cm³（約 95g）**（小片を除く。表の値は 2026-10-03 の A1 mini のスライス。
キャップ 2 つで 5h04m・29.9 cm³・約 37g）。2026-09-28（膜 0.6）: 約 10h57m・68.5 cm³（約 85g。キャップ 3h48m・21.8 cm³）。その前（2026-09-26・プレート無し・天板 1.2）: 約 12h53m・81.6 cm³（約 101g）。
プレートを戻すと 15h21m・96.9 cm³（約 120g）。以下は前の記録（プレートあり）: 合計 **約 14h52m・約 98 cm³（約 122g）**（小片を除く。2026-09-24 に床を 1.2 にして、さらに電源スイッチを替えて出し直した。前は 16h09m・108 cm³・134g）。**トレイ 2 枚は 2026-09-26 に出し直した**（位置決めの穴を丸 φ2.1 にして床の止まり穴を丸 φ2.9 に・支えの柱 4 本と左奥の滑り止めを 0.1〜0.2 動かした）: 表の値。合計はトレイの分で +9 分・−0.9cm³。1 個ずつの STL（`keycap_1u.stl` など）は
刷り直し用。**ふた 2 枚は 2026-09-25 に出し直した**（垂れ壁の端がトレイの壁の内面に隙 0 で接していたのを
FIT/2 = 0.1 離した・4 回目の監査 E 重要 1。A1 mini の設定でスライスして lid_L 11m20s・1.07 cm³、lid_R 16m14s・1.70 cm³。
**それより前の STL のふたは刷らない**）。

## 3. 設定（スライサー）

OrcaSlicer（または Bambu Studio）で:

- プリンタ **Bambu Lab A1 mini 0.4 nozzle**・フィラメント **Generic PLA**・プロセス **0.20mm Standard**
  （検査が実際にスライスした組み合わせ。`tools/kb cckb slice --printer a1mini`）
- **サポートは無し**（どの部品も切り欠きが上に開いている／天板を下に置く向きにしてある）
- 自動配置のまま（全部 168.4mm 角以内。一番大きいのは `keycaps_set_1u` 158×138 と `tray_L` 154.4×99.5）
- トレイの床は 1.2。底の 4 か所に滑り止めのくぼみ（16×8・深さ 0.4）があり、その所だけ床の上面が 1.6 の島に
  なっている（くぼみの上は 8mm の橋渡し。スライサーはそのまま通した）。反りが気になるときだけブリムを付ける
- キーキャップの天板の手ざわりはベッドの面で決まる（テクスチャ PEI ならざらざら、平らな面ならつるつる）

## 4. 回した検査／回していない検査

**2026-10-03（キャップの膜の既定を 1.0 に・利用者の決定・決定記録 2026-09-28-keycap-skin §8）に回した**: `case.py` で出し直し、刷る 14 個を
A1 mini で**スライス 14/14 成功**（キャップは 20 層 = 4.0）。変わった STL はキャップ 6 個・`coupon_stem`・`coupon_stab_return`（`coupon_skin` は同じ）。
組み立ての干渉 0（押す前・押し切り）・経路 0（`assembly.py`。プレートありの形は `tests/test_cckb_case.py` が見る）。押し切りで天板の下面が
ハウジング・つばに 0.25、スタビの箱に 0.55（図の値で。逃げを消すとスイッチに当たる検査で落ちることを確かめた）。全体の厚さ 14.2（膜 1.2 = 14.4 で検査が落ちる）。
全検査 468 passed・飛ばし 0（`REQUIRE_KICAD=1`）。発注の門は閉 #1・#4（前と同じ）。基板は変わらない（sha256 abcd20ff…）。
**回していない**: 膜 1.0・輪 0.6 を刷って抜き差し・縁の押しに割れないか（見積りは 22 MPa・`coupon_skin` の切り欠き 3 本で見られる）、K1 Max のスライス、
輪が 3 層で刷られることの G-code での確かめ。
**刷るかの判断**: 小片 4 つは刷ってよい。キャップ一式は膜 1.0 のまま刷ってよい（薄くしたいなら先に `coupon_skin` で 0.8 を確かめる）。
トレイ・ふたは変わっていない（前の判断のまま）。

**2026-09-28（キャップの天板をステムの上だけ膜 0.6・決定記録 2026-09-28-keycap-skin。2026-10-03 に膜 1.0 に替えたので前の記録）に回した**: `case.py` で出し直し、刷る 14 個を
A1 mini と K1 Max の両方で**スライス 14/14 成功**（キャップは 18 層 = 3.6）。変わった STL はキャップ 6 個・`coupon_stem`・`coupon_stab_return`、
新しい `coupon_skin`。組み立ての干渉 0（押す前・押し切り。プレート無し・ありの両方）・経路 0。押し切りで天板の下面がハウジング・つば・
スタビの箱に 0.1 以上（図の値で。逃げを消すとスイッチに当たる検査で落ちることを確かめた）。肉の刺し検査（膜 0.6・輪 0.2・外 1.0）。
**回していない**: 膜 0.6・輪 0.2 が抜き差しと縁の押しに割れないか（**見積りでは割れる**・`coupon_skin`・open-gaps P17）。
**刷るかの判断**: 小片 4 つは刷ってよい。**キャップ一式は `coupon_skin` の結果（か、見積りを採って膜を 0.8 / 1.0 に）まで刷らない**。
トレイ・ふたは変わっていない（前の判断のまま）。

**2026-09-26 夜（プレートを使わない・決定記録 2026-09-26-plateless）に回した**: `case.py` で出し直し、刷る 13 個を A1 mini で
**スライス 13/13 成功**（本番 12h53m・81.6 cm³、小片 3 個 1h22m・7.6 cm³）。`plate_optional/` の 6 個（プレート 2・枠・プレートの小片 3）も
同じ設定で 6/6 成功（戻せることの確かめ）。組み立ては**プレート無し・プレートありの両方**で干渉 0・経路 0・留め方 OK（`assembly.py` と
`assembly.py --plate`、検査は `tests/test_cckb_case.py` が両方の形で）。形の変わった STL は無い（プレートを刷る物から外しただけ）。
**回していない**: プレート無しでスイッチが傾かないか・打鍵感（open-gaps P16）、ナットを上から押さえられるか（P15）。

**2026-09-26 夜（2 回目の V2 監査の直し: ねじの頭の止まり穴 φ4.5 → φ4.85・支えの柱 4 本を 0.15〜0.9 動かした・`coupon_stem` のスタビの板を幅 3 通りに）に回した**: 全 19 個の STL を `case.py` で出し直し、A1 mini と K1 Max の両方で**スライス 19/19 成功**（A1 mini: `coupon_stem` 45 分 15 秒・4.07cm³、`tray_L` 3 時間 29 分・22.91cm³、`tray_R` 3 時間 12 分・21.04cm³）。組み立ての干渉 0（丸めの削りかす 6 件 0.0049mm³）・滑り止めの島の上 0。変わった STL は `tray_L`・`tray_R`・`coupon_stem`。
**回していない**: `coupon_stem` のスタビの板 3 枚が実物の軸に挿さるか・どの幅で軸が戻るか、ねじの頭の実寸（φ3.7 / 3.85 の読み）。

**2026-09-26 夕（`cckb-v2`・スタビの穴を実測に・キャップの受け口を深く・ねじの頭の止まり穴）に回した**: 全 19 個の STL を `case.py` で出し直し、A1 mini と K1 Max の両方で**スライス 19/19 成功**（A1 mini: `coupon_stab_return` 24 分 54 秒・2.48cm³、`keycap_2u25` 11 分 52 秒、`tray_L` 3 時間 29 分、`plate_main_L` 1 時間 15 分）。組み立ての干渉 0・押し切りの干渉 0（台がスタビの箱の口に入る）・全検査 green。
**回していない**: 台 φ5.1 が実物の箱の口に入るか・軸がキャップと戻るか（`coupon_stab_return`）、ねじの頭の実寸。

**回した**（2026-09-24。床を 1.2 にして〔O10〕出し直した）:
- 全 17 個の STL を上の設定で**実際にスライス**して 17/17 成功（時間・材料は上の表）
- 平面の大きさ・1 つの水密な立体か・肉厚（名前つき 23 か所の断面＋縦の走査）
- 組み立てモデルで**干渉 0**（発注する配線済みの板・スイッチ 62・スタビ 8・XIAO・USB-C プラグ・電池と
  ホルダ・電源スイッチ・ネジ 11・ナット 9・インサート 2・キャップ 62）、押し切ったキャップも 0
- 入れられるか・外せるか（基板を上から落とす・ふた・電池・プラグ・ネジとドライバー）、留まるか、
  電源スイッチのレバーにふたの穴から爪がかかるか（2026-09-24 に SS-12D00G3・上レバーへ）、継ぎ目が柱を切らないか
- 各検査は、わざと壊した値で落ちることを確かめた（tests/test_cckb_case.py）

**回していない**（刷って確かめる）:
- 嵌め合い（スイッチ・スタビ・キャップの脚・ナット・インサート・膜）→ §1 の小片
- 電源スイッチのレバーに右のふたの穴から本当に爪がかかるか・「ON ↑」の刻印が読めるか（P4）→ `lid_R` を刷って、スイッチを付けた基板で
- 実物の USB-C ケーブルの樹脂の大きさ（P2）→ 使うケーブルを測る
- 電池がホルダの中でどの高さに座るか（`CELL_Z_IN_HOLDER` [暫定]）→ ホルダが届いたら
- 反り（長い 154mm の部品を刷った実績はこの機種では無い）

**刷るかどうかの判断**: 小片は今すぐ刷ってよい。本番は小片の結果で値を直してから。

---

## 5. 組み立ての順番 → [assembly-guide.md](assembly-guide.md) に移した

2026-09-24 に、組み立ての順番（この節の旧 §5）と使い方（旧 §6）を [assembly-guide.md](assembly-guide.md) へ移した
（同じことを 2 か所に書かないため）。古い記録が指す番号の行き先:

| 旧 | 新 |
|---|---|
| §5 の「買う物」 | [shopping-list.md](shopping-list.md) |
| §5-1（XIAO・パッド内ビア・奥の列にはんだを盛らない） | assembly-guide 手順 2 |
| §5-1b（電源スイッチ・入の向き・導通） | assembly-guide 手順 4 |
| §5-2〜§5-4（プレート・スタビ・スイッチ・足の先の玉） | assembly-guide 手順 5・6 |
| §5-5（電池ホルダ） | assembly-guide 手順 3（プレートより先に付ける順に変えた。ホルダの角はプレートの外） |
| §5-6〜§5-15（インサート・ナット・トレイ・ネジ・電池・ふた・キャップ・滑り止め） | assembly-guide 手順 8 |
| §6 使い方（USB を挿す前に電源スイッチを OFF など） | assembly-guide「使い方」 |

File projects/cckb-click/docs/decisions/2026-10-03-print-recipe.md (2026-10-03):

# 刷り方: 精度を最優先にした設定・ノズル・最初に刷る最小の一式

- **日付:** 2026-10-03
- **状態:** 決定（最初の 1 枚の刷り方）。数値は刷った結果（docs/coupon-test.md の測る表）で直す
- **決めた人:** 利用者（最小の一式から刷る・精度を最優先にする）／設定の中身と形の変更の案は Claude

## 1. なぜ決める必要が生じたか

販売者は「少しのバリで作動不良を起こす」「3D プリントだとバリとか造形カスが 10% くらいの確率で発生して動作不良」と書いている
（記事 acc-introduction）。「0.3 mm 程度でキーが反応するので、少しでも変形したりしていると使用できない」（記事 order-acc）。
これまでの試し刷りは「0.20mm Standard」を既定のまま使う前提で、速さ寄りだった。利用者の決定（2026-10-03）:
**精度を最優先にする。最初は最小の一式（穴 3 つの枠・キャップ 3 個・板）だけを刷る。**

## 2. 事実はどうか

**この Mac に入っている物（調べた）**

| 物 | 事実 |
|---|---|
| スライサー | Bambu Studio 2.8.2 と OrcaSlicer 2.4.2。利用者が最後に使ったのは Bambu Studio（A1 mini 0.4 nozzle・Bambu PLA Basic・0.12mm Fine） |
| プリンタの設定 | A1 mini は 0.2 / 0.4 / 0.6 / 0.8 ノズル。K1 Max は 0.4 / 0.6 / 0.8 だけ（0.2 が無い） |
| A1 mini・0.4 の細かい層 | 0.08 Extra Fine・0.08 / 0.12 / 0.16 High Quality・0.12 Fine。層の下限 0.08 |
| A1 mini・0.2 の層 | 0.06〜0.14。既定は 0.10 Standard。0.06 / 0.08 / 0.10 High Quality。線の幅 0.22・1 層目 0.1・PLA Basic の吐出の上限 2 mm³/s |
| 0.2 ノズルの形跡 | Bambu Studio に「0.2 ノズル・PLA Basic の流量キャリブレーション済み（比 0.98）」の記録と利用者の設定がある。**持っているかは未確認** |
| 象の足の補正 | A1 mini の Bambu の設定は 0（両方のスライサーで） |

**CLI は設定の継承をたどらない（今回見つけた）。**Bambu の設定ファイルはほとんどの値を親に持つ。そのまま CLI に渡すと、
OrcaSlicer の既定値（線幅 自動・外周 60 mm/s・ノズル 200℃・Arachne・ベッド 35℃）で切られる。これまでの時間の表（14 個で 8.6 時間）と、
構造の決定記録に書いた「上 4 層・外周 2 本・Arachne」はこの既定値だった。**親をたどって 1 枚にしてから渡し、G-code の設定の欄と突き合わせる**
ようにした（tools/slice_precise.py）。foundry.slice_check は直していない（open-gaps #22）。

**継ぎ目（外周の線の始まりと終わり。小さなこぶになる）がどこに出るか（スライスして数えた）**

| 形・設定 | キャップ（滑る面にある数／全部） | 枠の穴 |
|---|---|---|
| 溝なし・そろえる（Aligned） | 69 / 69（角の丸みの始まり = つばのある所） | 49 / 57 |
| 溝なし・奥（Back） | 69 / 69 | 52 / 57 |
| 溝 1.2 × 0.3・そろえる・0.4 ノズル | 64 / 69 | 0 / 57 |
| 溝 1.6 × 0.4・そろえる・0.4 ノズル | 1 / 69（面取りの層の 12 個は別） | 0 |
| **溝 2.0 × 0.5・そろえる**（0.4・0.2・両方のスライサー） | **0** | **0** |
| 溝あり・奥（Back） | 60 以上（奥の平らな辺の端へ行き、溝に入らない） | — |

スライサーの設定だけでは、継ぎ目を滑る面から外せなかった。**形の側に溝を掘る**と、そろえる設定が溝の入隅を選ぶ。

**外の資料**

- OrcaSlicer の wiki（quality_settings_wall_and_surfaces）: 内→外→内（Inner/Outer/Inner）は「best external surface finish and dimensional accuracy」。
  外→内（Outer/Inner）は同じ精度だが「z seams will appear less consistent」。内→外は外周が内周に押されて「slightly reduced surface quality」
- 0.2 ノズル（Bambu の販売ページの記載・検索結果から）: 細かい造形向け。ラメ・マーブル・木・石・金属入り・PA・TPU・カーボン入りは不可
- Bambu の wiki は取得できなかった（HTTP 402）。ノズルごとの層・線幅・吐出の上限は、**同梱の Bambu の設定ファイル**から読んだ

## 3. 効く条件（候補を並べる前に）

| # | 条件 | 実データ | 何で確かめたか |
|---|---|---|---|
| 1 | 機能する面（押す面・掛かる面・くぼみの底・柱の先）が層の境目にある | 0.4・1.0・2.0・2.4・5.0 は 0.1 でも 0.2 でも境目 | 外（G-code の層の高さ）＋検査 |
| 2 | 滑る面（キャップの胴・穴の壁）にこぶ・バリが無い | 継ぎ目 0 個（上の表） | 外（両方のスライサーの G-code）。**大きさは刷らないと分からない** |
| 3 | 1 層目の太りが滑る面に出ない | 1 層目の縁はキャップで 0.20〜0.25、穴で 0.26〜0.35 引っ込む | 外（G-code の 1 層目の線）。**太りの量は刷らないと分からない** |
| 4 | 外周の寸法が狙いどおり | 胴の外周の外寸 16.65 = 設計。内→外→内 | 外（G-code）＋ wiki。**実寸は測る表で** |
| 5 | くぼみの間の壁（0.8・穴 +0.2 で 0.6）に線が出る | Arachne で 0.4 ノズルでも線 2 本 | 外（slice_n04.png を見た） |
| 6 | 糸を引かない（島が 6 個ある） | 壁をまたがない移動・乾いたフィラメント | **まだ**（刷って見る） |
| 7 | 縁を汚さない | ブリム無し・サポート無し・スカート無し | 外（G-code の設定の欄） |
| 8 | 層の時間が短すぎない（小さい部品が熱で垂れる） | 6 個を層ごとに一緒に刷る。フィラメントの設定が 6 秒未満なら減速 | 設定だけ。**まだ**（刷って見る） |
| 9 | 時間（目標 30〜40 分） | 0.4: 造形 43 分（準備込み 50 分）。0.2: 1 時間 35 分 | 外（スライス）。**0.4 でも目標を少し超える** |
| 10 | 利用者の手元で同じ結果になる | Bambu Studio 2.8.2 の CLI でも継ぎ目 0・設定 25 個が一致 | 外（Bambu Studio の G-code）。**画面からは未確認** |
| 11 | 刷った物のずれを測って戻せる | 測る塊（外寸 10・高さ 3・段 0.4）と測る穴（内寸 10） | 検査（立体から測る） |

## 4. 影響範囲（線が出てから指に触れるまで）

フィラメント（湿り）→ ノズル（径・温度）→ 線（幅・層）→ 外周（順・継ぎ目）→ 1 層目（つぶれ・太り）→ 面（押す面・掛かる面・滑る面）→
組んだときの隙 → スイッチの戻す力 0.1 N で戻るか。

- 層 0.2 → 0.1: 斜めの面（下の縁の面取り 0.3・上の縁の面取り 0.8）の段が半分になる。1 層あたりの吐出が半分 → 継ぎ目のこぶも小さい。時間は約 2 倍
- 層を spec.PRINT_LAYER に持たせた。機能する面は「1 層目 ＋ 層の倍数」（P.on_layer）。いまの高さは 0.2 の倍数のままなので、どちらの層でも成り立つ
- 継ぎ目の溝 → キャップの奥の縁に幅 2.0 の切れ込みが**上から見える**。穴の奥のリブがそこだけ 0.5 薄くなる（2.0 → 1.5。穴 +0.2 で 1.3）。
  奥の列の穴では、溝の上に柱が 0.3 × 2.0 だけ張り出す（刷る向き。小さな橋）
- 0.2 ノズル: 線が半分 → 角の丸まり・こぶ・糸が小さい。吐出の上限 2 mm³/s → 時間 2.2 倍。フィラメントの制限
- プレートが Textured PEI: 押す面（キャップの下面）と枠の上面がざらざらになる。平らさは変わらない前提。**まだ**（刷って見る）

## 5. 決めたこと

**プリンタ: A1 mini。**0.2 ノズルの設定があるのは A1 mini だけ。利用者の Bambu Studio も A1 mini で使っている。

**設定（print/cckb-click_precise_n04.json・n02.json。土台は Bambu の High Quality）**

| 設定 | 0.4 ノズル | 0.2 ノズル | なぜ |
|---|---|---|---|
| 土台 | 0.12mm High Quality @BBL A1M | 0.10mm High Quality @BBL A1M 0.2 nozzle | Bambu が「速さと加速度を下げて品質を上げた」と書いている組。自分で速さの数字を作らない |
| 層の高さ | 0.1 | 0.1 | 形が 1 つで済む。0.4 ノズルの下限 0.08 の内・0.2 ノズルの既定 |
| 1 層目 | 0.2 | 0.1 | 土台のまま。機能する面は 1 層目より上の境目にある |
| 線の幅（外周／1 層目） | 0.42 / 0.5 | 0.22 / 0.25 | 土台のまま |
| 外周の数・順 | 3・内→外→内 | 4・内→外→内 | 外周を内周に押させない（wiki）。継ぎ目も揃う。3 本以上が要る |
| 壁の作り方 | Arachne | Arachne | 0.8 の壁に 0.4 ノズルで線を 2 本出す |
| 外周の速さ・加速度 | 60 mm/s・2000 | 60 mm/s・2000 | 土台のまま |
| 継ぎ目 | そろえる（Aligned）＋形の溝 | 同じ | 上の表。スカーフ継ぎ目は使わない（継ぎ目を斜めに長く伸ばして滑る面に広げる。結果を機械で確かめられない） |
| 象の足の補正 | 0 | 0 | 形の面取り（キャップ 0.3・穴 0.4）で逃がす。補正を入れると測る塊の実測が素の機械の値でなくなる |
| X-Y 補正（穴・外形） | 0 | 0 | **測ってから入れる**（測る表 → 戻す所） |
| 円弧 | 入 | 入 | 土台のまま（Bambu の機械向け） |
| 壁をまたがない移動 | 入 | 入 | 島の間の糸を滑る面に落とさない |
| ブリム・サポート・スカート | 無し | 無し | 縁にバリを残さない |
| アイロンがけ | 無し | 無し | 上面は機能しない面。最初の 1 枚は変える物を減らす。見た目が気になれば足す |
| 上・下の層 | 7・5 | 7・5 | 0.10 の Bambu の設定と同じ。中は 15% |
| 刷る順 | 層ごと（全部一緒） | 同じ | 1 個ずつだと層の時間が短くなり、熱で垂れる |
| プレート | Textured PEI（65℃） | 同じ | A1 mini の付属の板。記録にあった板の種類。違う板なら選び直す |
| 置き方 | 真ん中・回さない | 同じ | 長い辺と穴を広げる向きが X（頭）。測る塊の X / Y がそのまま機械の X / Y |

**形の変更**

- `PRINT_LAYER` 0.2 → 0.1、`PRINT_FIRST_LAYER` 0.2 を spec に。**押す面 3.6・つば 0.4 は変えない**（下の「捨てた案」）
- `SEAM_NOTCH` = 幅 2.0 × 深さ 0.5 の継ぎ目の溝を、キャップの胴の奥の面と、枠の穴の奥の壁の真ん中に（`[暫定]`。見た目は利用者が決める）
- 最小の一式 `min`（coupon_min_plate ほか）と、測る塊・測る穴

**刷る前にプリンタ側ですること**: 印刷を送る画面で「ベッドレベリング」と「流量ダイナミクスのキャリブレーション」を入れる（A1 mini が自動で測る）。
フィラメントを乾かす。0.4 ノズルで流量のキャリブレーションをしていなければ、測る表でずれが 0.1 を超えたときにする。

## 検討して捨てた案

| 案 | 捨てた理由 |
|---|---|
| 層 0.1 を使って押す面を 3.5・浮きを 0.1 にする（つば 0.5） | 公差の端のスイッチ（ステム 3.6）を 0.1 押しっぱなしにする。要求 R1 と構造の決定（押しっぱなしは誤入力・浮きは感触）に反する。検査が落とす。浮きを詰めたくなったら standin の小片で触ってから |
| 層 0.08 | くぼみ 1.0・柱 3.0 が境目に乗らない |
| K1 Max | 0.2 ノズルの設定が無い。利用者のスライサーは A1 mini |
| 継ぎ目を「奥（Back）」 | 奥の平らな辺の端（角の丸みの始まり）に出た。CLI の自動配置が物を 180° 回すと奥が逆になることも分かった |
| 継ぎ目をスライサーの画面で塗る | 手作業で再現できず、プリセットに入らない |
| スカーフ継ぎ目 | 上の表の「継ぎ目」。溝で足りなければ次に試す（両方のスライサーに設定はある） |
| 外→内 | 精度は同じだが継ぎ目がばらつく（wiki） |
| 象の足の補正 0.1〜0.15 を足す | 形の面取りと二重になり、1 層目が 0.3〜0.4 引っ込む。測る塊の値も変わる。刷って太りが面取りを超えたら入れる |
| 板だけ粗い設定で別に刷って時間を詰める | 2 枚に分かれ、準備が 2 回になる。板の台の高さ 3.4 も機能する面 |

## この決定が乗っている前提（**動いたら読み直す**）

- Bambu Studio 2.8.2・OrcaSlicer 2.4.2。**版が変わると継ぎ目の選び方が変わりうる**（tools/slice_precise.py を回し直す）
- A1 mini・PLA Basic・Textured PEI
- キャップの形（つば F・下面をベッドに）。形を変えたら継ぎ目の数え方（どこを滑る面と呼ぶか）も見直す

## 覆す前に読むこと

docs/coupon-test.md の測る表と記入表（刷った結果）。tools/slice_precise.py の出力と build/cckb-click/slice_n04.png。

## まだ決めていないこと

| 項目 | 決められない理由 |
|---|---|
| 0.2 ノズルを使うか（持っているか・買うか） | 利用者に確認。0.4 で刷った結果を見てから |
| 継ぎ目の溝の見た目 | 利用者が刷った物を見て決める |
| X-Y 補正の値 | 測ってから |
| アイロンがけ | 上面を見てから |

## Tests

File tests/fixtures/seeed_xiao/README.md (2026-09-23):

# tests/fixtures/seeed_xiao（出典とライセンス）

| ファイル | 出典 | 改変 |
|---|---|---|
| `XIAO-nRF52840-SMD.kicad_mod` | Seeed Studio「OPL_Kicad_Library」の `Seeed Studio XIAO Series Library/XIAO-nRF52840-SMD.kicad_mod`（<https://github.com/Seeed-Studio/OPL_Kicad_Library>・commit `3be8215d3db652e2f62269913cb1fddd5e737d38`） | **なし**（上の commit の中身と sha256 `bea5909c…d7c7e2` が一致することを 2026-09-24 に GitHub API で確かめた） |
| `pins.json` | 同じライブラリの記号 `XIAO-nRF52840-SMD`（`Seeed_Studio_XIAO_Series.kicad_sym`・commit `b0035c51eb0348bb3e165fdb2f2765fa3d1d17bd`）から、パッドの番号とピンの名前の対応だけを書き写したもの | 自分で書いた対応表（出典は `source` に書いてある） |

**ライセンス**: OPL_Kicad_Library は **CC-BY-SA-4.0**（リポジトリの `LICENSE`。GitHub API の
`repos/Seeed-Studio/OPL_Kicad_Library/license` が `CC-BY-SA-4.0` と返すことを 2026-09-24 に確かめた）。
上の `.kicad_mod` は同じ CC-BY-SA-4.0 のもとで、改変せずに再配布している。
© Seeed Studio。ライセンスの全文: <https://creativecommons.org/licenses/by-sa/4.0/>

使い道: tests/test_cckb_pcb.py が、CCKB の基板の XIAO のパッドを Seeed のフットプリントと突き合わせる
（自分のフットプリントを自分で書いた値と比べない。CLAUDE.md 検証の作法 3）。

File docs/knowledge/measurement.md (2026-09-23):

# 測り方・試作の進め方

HHKB の `task-c1〜c6`・`task-b3` と `decisions/2026-08-16-remove-bulk-cap.md` から。
手順書の書式は [docs/templates/task.md](../templates/task.md)。

## 試作の順番（手戻りが大きいものほど先に確かめる）

治具のシールドを段階に分け、**失敗したときの原因の候補を絞る**:

1. 疎通（XIAO 1 個・キー 2 個・直結。`CONFIG_ZMK_BLE=n` で変数を減らす）
2. 行列とゴースト（2×2・ダイオード）
3. シフトレジスタ（同じ行列を 595 で。**SPI 周波数は本番と同じ**）
4. BLE 分割だけを切り出した治具（電池の ADC ピンは空けておく）
5. 電源（乾電池・逆流・打ち止め・残量）
6. 実機との比較（部品不要のものは早く）

基板の発注前に方式を確定させる。治具に手を入れたら**既知の値が再現してから**次へ。

## 対照実験（無い合格は無意味）

- ゴースト試験（2×2・4 キー）: a・b・c 同時で d が出ないか、b・c・d で a、対角 a・d。
  **先に 4 キーを 1 つずつ押す**（死んだキーは自動で「合格」する）
- 逆流: USB を抜けば値が出ることを見せる。厳密なゼロは出ない（分圧の 1.5µA）
- 打ち止め停止: 3.00V で接続 → 2.50V で止まらない → 2.30V で 10 秒以内に切れる →
  3.00V に戻しても復帰しない → 入れ直すと起動。試験用の `REPORT_INTERVAL=5` は戻す
- 同時押し: 修飾キーは HID で別のバイトに載る。文字キー同士だけで左右を判定しない。
  離すと小文字に戻るかも見る。落ちたら**落ちた条件だけ**を 10 回測り直す（原因はスイッチの浮きだった）

## 電流

- **電流計の負担電圧は、電流が最大のとき（未接続・広告中）に最大になり、測りたい状態を壊す。**
  繋がることはジャンパで確かめ、接続してから電流計を入れる
- レンジを選ぶ（1mA を超える区間を含むなら 20mA。2000µA では 9 倍ずれた）
- ブレッドボードで小さいシャント（10Ω）の両端を電圧で読まない（接触抵抗が数Ω揺れる）。
  テスターを直列に入れる。1kΩ では起動できない → 起動用の短絡ジャンパで迂回してから抜く
- オシロのプローブ GND は筐体アース。GND 側のシャントはアース → Mac → USB シールドで
  迂回されて 0V に見え、ハイサイドに GND クリップを挟むと短絡する → A−B 演算・差動・浮いたテスター
- テスターの入力抵抗（AD-5526 は約 1MΩ）で分圧を 33% 低く読む → ADC 自身に読ませる
- 測るたびに守る: USB を抜く・電池を入れ直す・測らない側のホストの Bluetooth を切る・
  ログ入りのファームの値（+0.44mA）を混ぜない・**先にキーが打てることを確かめる**（広告中を測らない）
- **最悪の動作モードを組み合わせて測る**（分割セントラルの広告＋スキャン。単独だと 27% 低い）
- 2 点の当てはめは自由度 0。3 点目が来るまで信じない。桁を先に数える
- 電池の内部抵抗: 25Ω 負荷で開放と負荷時の差から（新品 1.34V/本で 2.68Ω、1.07V/本で 9.18Ω）

## 電池・電源装置

- 電池を替えたら 1 分待ってから読む（替えた直後は低く出る）
- 降圧モジュール（LM2596S）の出荷時は入力に近い電圧が出る。**入力だけ繋ぐ → テスター →
  トリマ最低 → 3.00V に合わせる → 入れ直して再確認 → 回路へ**
- 打ち止めは 0.1V 刻みで「動き続ける限界」と「起動の限界（毎段で入れ直す）」を分けて測る。
  直列抵抗（10Ω・25Ω）で内部抵抗を模擬する。冷やす（冷蔵庫 2h）

## 寸法・資料

- 採寸は測らせずに**照合**で: 1:1 テンプレートに 100mm の基準線を刷り、実物に重ねて撮る
- 写真計測はスケールを 3 系統で検算（ピッチ 19.05・キャップ基部・公称全高）
- **資料を採寸に使う前に被写体を同定する**（公式記事の写真 30 枚中、本物は 5 枚だった）。
  品番の違う資料から寸法を借りない。食い違う 2 値は丸めず、両立する解釈を探す
- 部品の物理的な事実は**データシートと製品画像**で（秋月は商品ページから
  `/goodsaffix/<品番>.pdf` と `/img/goods/{1,2,3,4,L}/<コード>.jpg`）
- 外部の調査報告もデータシートと突き合わせる（「金めっき」と断定されていたが銀だった）

## ロジアナ（Saleae）

Async Serial・1,000,000bps・8N1・24MS/s。**沈黙を解釈する前に、同じ手順で道具が
フレームを取れることを見せる。**

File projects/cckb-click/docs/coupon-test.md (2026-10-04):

# 試し刷り（cckb-click・基板なし）

**最初に刷るのは 1 枚だけ。**約 45 分。刷ったら、測って、組んで、3 つの穴のどれが合うかを見る。

絵を先に見る（build/cckb-click/）: `min_set.png`（置く向き・組んだ所・断面）、`slice_n04.png`（スライスした線）。

## 1. 何を刷るか

| | |
|---|---|
| ファイル | `build/cckb-click/coupon_min_plate.stl`（3 つの部品を 1 枚に並べた物） |
| 中身 | キャップ 3 個（同じ形）＋ 測る塊 1 個 ／ 枠 1 個（穴 3 つ ＋ 測る穴）／ 板 1 個 |
| 時間・材料 | 0.4 ノズル: 造形 43 分（準備込み 50 分）・7.3 cm³（約 9 g）。0.2 ノズル: 造形 1 時間 35 分（準備込み 1 時間 43 分）・6.7 cm³ |

部品を 1 個ずつ刷り直したいときは `coupon_min_caps.stl`・`coupon_min_frame.stl`・`coupon_min_base.stl`（中身は同じ）。

## 2. どう刷るか

| | |
|---|---|
| プリンタ | **A1 mini** |
| ノズル | **0.4**（いま付いている物でよい）。0.2 を持っていれば 0.2 の方が細かく出る（下の「ノズル」） |
| フィラメント | Bambu PLA Basic。色は何でもよい。**乾いた物**（湿っていると糸を引き、それがバリになる） |
| プレート | Textured PEI（ざらざらの金色の板）。別の板なら、スライサーで板の種類を選び直す |
| 設定 | `projects/cckb-click/print/cckb-click_precise_n04.json`（名前 `cckb-click precise 0.10 @A1M 0.4`）。0.2 ノズルは `cckb-click_precise_n02.json`（名前 `cckb-click precise 0.10 @A1M 0.2`） |
| 向き | **回さない。**読み込んだままの向きで刷る。キャップは押す面（下面）が下。枠は上面が下（柱が上を向く）。板は下面が下 |
| サポート・ブリム | **どちらも無し**（設定に入っている。ブリムは縁にバリを残す） |
| 印刷を送るとき | 「ベッドレベリング」と「流量ダイナミクスのキャリブレーション（Flow Dynamics Calibration）」に**チェックを入れる** |

**手順（Bambu Studio）**

1. プリンタを「Bambu Lab A1 mini 0.4 nozzle」、フィラメントを「Bambu PLA Basic」にする。
2. ファイル → インポート → 設定をインポート で `cckb-click_precise_n04.json` を読む。プロセスの一覧から `cckb-click precise 0.10 @A1M 0.4` を選ぶ。
3. `coupon_min_plate.stl` を読み込む。「複数の部品に分けますか」と聞かれたら「いいえ」。回さない。
4. スライスする。プレビューで**継ぎ目（白い点）が、キャップと穴の小さな溝の中に並んでいる**のを見る。角に並んでいたら刷らずに知らせる。
5. 印刷する。

**近道**: `build/cckb-click/coupon_min_plate_n04.gcode.3mf` は、この設定で Bambu Studio 2.8.2 が切った物（検査したのはこの G-code）。
Bambu Studio で開いてそのまま送れるはず。ただし**画面で開く所は確かめていない**。開けなければ上の手順で。

設定が読み込めなかったら、`0.12mm High Quality @BBL A1M` を選び、次の 9 つを手で変える:
層の高さ 0.1 ／ 外周の数 3 ／ 外周の順 内→外→内（Inner/Outer/Inner）／ 壁の作り方 Arachne ／ 上の層 7・下の層 5 ／ 継ぎ目 そろえる（Aligned）／
壁をまたがない移動（Avoid crossing walls）入 ／ ブリム 無し ／ 象の足の補正 0。

## 3. 刷ったあとにすること

1. 板が冷めてから外す（熱いうちに曲げると反る）。
2. **バリを取らない。**そのまま見る。キャップの下の縁・四隅のつば・奥の小さな溝。糸やこぶがあれば、どこにあるかを書く。
3. **測る**（ノギス）。下の「測る表」に書く。
4. **組む。**
   1. 枠を裏返して机に置く（柱が上）。
   2. キャップを**上面を下にして**穴に落とす。キャップの溝と、穴の溝を同じ側にする。3 個とも同じ形なので、どの穴に入れてもよい。
   3. 板を裏返してかぶせる。落とした角どうしを合わせる。
   4. 全体を押さえたまま表に返す。
5. **試す。**穴の番号は、枠の手前の縁の点の数（1・2・3）。右へ行くほど穴が 0.1 ずつ広い。
   - 組んだ物を**逆さにして、また戻す**。キャップが自分の重さで上下に動くか（カタッと音がする）。
   - キャップを指で横に揺する。がたの量。
   - 逆さにして振る。キャップが落ちてこないか。
   - 外して、枠の穴の壁とキャップの横の面をなでる。引っ掛かる所があるか。

## 4. 何を見るか・結果の意味

| 見るもの | こうなら | 意味 |
|---|---|---|
| 逆さにして戻すと、キャップが自分の重さで動く | 3 つとも動く | **この方式は刷れる。**いちばん狭い穴（1 番）でよい |
| | 2 番・3 番だけ動く | 隙を広げる（`CAP_CLEAR` を 0.25 か 0.30 に） |
| | どれも動かない | 測る表を見る。外寸が大きい・内寸が小さいなら、スライサーの補正を入れて刷り直す（下） |
| 指で軽く押すと動くが、自分の重さでは動かない | | 際どい。スイッチが戻す力は約 10 g、キャップは約 0.6 g。使えるかもしれないが、1 つ広い穴を選ぶ |
| 横のがた | 3 番が大きすぎる | 狭い方を選ぶ。1 番でも大きいなら隙を詰められる |
| 逆さにして振ると落ちる | | つばの掛かりが足りない（`TAB_REACH`）。知らせる |
| 継ぎ目のこぶ | 溝の中にある | 狙いどおり |
| | 角や平らな面にある | 設定が効いていない。スライサーの画面を見直す |
| キャップの上面 | 筋が気になる | アイロンがけを足す（今回は入れていない） |
| キャップの奥の縁の切れ込み（幅 2.0） | 見た目が許せない | 知らせる。溝を上まで通さない形に変える |

### 測る表

測る塊は、キャップの列の右にある四角（10 角・高さ 3）。右に薄い段がついている。**段のある向きが X。**

| 測る所 | 設計 | 測った値 |
|---|---|---|
| 塊の幅 X（段より上をはさむ） | 10.00 | |
| 塊の幅 Y | 10.00 | |
| 塊の高さ | 3.00 | |
| 塊の段の厚さ | 0.40 | |
| 枠の測る穴 X（内寸） | 10.00 | |
| 枠の測る穴 Y（内寸） | 10.00 | |
| キャップの厚さ（3 個） | 2.40 | |
| キャップのつばの厚さ（3 個。段と同じ厚さのはず） | 0.40 | |
| キャップの胴の幅 X（つばの無い真ん中をはさむ） | 16.65 | |
| 穴の幅 X（1 番・2 番・3 番） | 17.05・17.15・17.25 | |

**ずれたらどこへ戻すか**

| ずれ方 | 戻す所 |
|---|---|
| 外寸が大きく、内寸が同じだけ小さい（例: 10.10 と 9.90） | 線が太い。プリセットの「X-Y 外形補正」を −（ずれの半分）、「X-Y 穴補正」を +（ずれの半分）にする（例: −0.05 と +0.05）。0.1 を超えるなら先にフィラメントの流量のキャリブレーションをやり直す |
| X だけ、または Y だけがずれる | 機械の側（ベルト）。設定では直さない。知らせる |
| 高さ 3.00 は合うが、段とつばの 0.40 がずれる | 1 層目のつぶれ方。0.05 以内ならそのまま。超えたら知らせる（浮きがその分だけ変わる） |
| 高さ 3.00 もずれる | 層の厚さの問題。知らせる |
| 寸法は合うのに擦れる | 面の粗さかバリ。どこが当たっているかを書く |
| 寸法が合い、1 番で動く | `CAP_CLEAR` 0.20 のまま進む |

### 記入表（最小の一式）

**利用者の報告（2026-10-03）。**書いてあるのは報告にあったことだけ。報告に無い欄は「報告なし」。

| 項目 | 結果 |
|---|---|
| 刷った日・ノズル・フィラメント・プレート | 2026-10-03・A1 mini・0.4 ノズル・精度優先の設定（print/cckb-click_precise_n04.json）。フィラメントとプレートは報告なし |
| プレビューで継ぎ目が溝に並んでいたか | 報告なし |
| 自分の重さで動いた穴（1・2・3） | **1 番（穴 17.05・片側の隙 0.20）で自分の重さで自由に動く**（カタカタ鳴る）。1 番が動くので 2・3 番も動く |
| がたが許せる穴 | **1 番がいちばん、がたが少ない** |
| 逆さにして振って落ちたキャップ | **無い。上へは抜けない** |
| バリ・糸・こぶのあった所 | 報告なし（「仕上がりはきれい」） |
| キャップの上面と、奥の切れ込みの見た目 | 仕上がりはきれい |
| そのほか | 測る塊（10 mm）は約 10 mm |

**結果から決めたこと**（決定記録 2026-10-03-coupon-result）: 案 B・穴 17.05 角（隙 0.20）・つばのキャップ F・0.4 ノズルの刷り方。
測る表の細かい数（塊の X / Y / 高さ・段 0.40・穴の内寸）は報告が「約 10 mm」だけなので、**補正は入れない**（X-Y 補正 0 のまま）。

## ノズル（0.4 と 0.2）

| | 0.4 ノズル | 0.2 ノズル |
|---|---|---|
| 線の幅 | 0.42 | 0.22 |
| 1 層目の厚さ | 0.2 | 0.1 |
| 角の丸まり・継ぎ目のこぶ・糸 | ふつう | 小さい（線が半分の幅） |
| 最小の一式の時間 | 43 分 | 1 時間 35 分 |
| キャップ 62 個の時間（1u 9 個のスライスから比で出した見積もり） | 約 3 時間（9 個で 27 分） | 約 6.6 時間（9 個で 58 分） |
| 使えないフィラメント | — | ラメ・木・石・金属・カーボン入り・TPU（詰まる） |

**まず 0.4 で刷る。**3 つの穴のどれかで自分の重さで動けば、0.4 のままでよい。動かない・バリが出るなら 0.2 を試す。
この Mac の Bambu Studio には、0.2 ノズルで PLA Basic の流量を合わせた記録が残っている。**0.2 ノズルを持っているかは利用者に確認**（open-gaps #21）。

## 5. あとで刷る 14 個

最小の一式で「刷れる」と分かってから。設定は同じ。全部で**約 5.9 時間・54 cm³（PLA 約 68 g）**（0.4 ノズル・1 個ずつ刷ったときの造形時間）。

```
.venv/bin/python3 projects/cckb-click/click_coupons.py                       # STL と絵を build/cckb-click/ に出す
.venv/bin/python3 projects/cckb-click/tools/slice_precise.py                 # 最小の一式をスライスして検査（n04 と n02）
.venv/bin/python3 projects/cckb-click/tools/slice_precise.py n04 bambu --all # 全部の時間と材料
```

絵: `coupons_top.png`（各小片を上から）・`section_main.png`（断面）・`section_latch.png`（掛かり方 6 通り）・`wide_end_press.png`・`assembly/cckb-click_coupons.blend`。

- 枠（`*_frame`）は上面が下。キャップ（`*_caps`）は下面が下。`coupon_latch_caps` の 3〜6 番だけは上面が下。**STL は刷る向きで出してある**
- 組み方は最小の一式と同じ。見分け方: 左手前の角が落としてある。枠の縁の点の数 = 列（番号）。板の台の手前の点 = 台の番号。キャップの上面の点 = 掛かり方の番号

| ファイル | 中身 | 時間 | 材料 |
|---|---|---|---|
| `coupon_b_frame` | 案 B の枠 3×3（穴 17.05 / 17.15 / 17.25 角） | 30 分 | 3.7 cm³ |
| `coupon_ab_base` | a・b 共用の板（台 3.4 × 9） | 30 分 | 5.8 cm³ |
| `coupon_b_caps` | 案 B の 1u キャップ × 9（standin にも使う） | 27 分 | 4.5 cm³ |
| `coupon_latch_frame` | 掛かり方の枠 1×6 | 26 分 | 3.6 cm³ |
| `coupon_latch_base` | 同・板（台 3.4 × 6） | 25 分 | 4.7 cm³ |
| `coupon_latch_caps` | 掛かり方 6 通りのキャップ（上面の点 1〜6） | 24 分 | 3.3 cm³ |
| `coupon_a_frame` | 案 A の枠 3×3（穴 16.5×16.0 / 16.6×16.1 / 16.7×16.2） | 34 分 | 4.1 cm³ |
| `coupon_a_caps` | 案 A の 1u キャップ × 9 | 25 分 | 4.1 cm³ |
| `coupon_standin_frame` | 台の高さの枠 2×3（穴は案 B の基準） | 24 分 | 2.8 cm³ |
| `coupon_standin_base` | 同・板（台 3.2〜3.7。手前の点 1〜6） | 22 分 | 4.2 cm³ |
| `coupon_wide_frame` | 幅の広いキーの枠（1.5u・1.75u・2.25u） | 22 分 | 3.4 cm³ |
| `coupon_wide_base` | 同・板（中心に台 3.4 が 1 個ずつ） | 19 分 | 4.3 cm³ |
| `coupon_wide_caps` | 1.5u・1.75u・2.25u のキャップ | 15 分 | 2.9 cm³ |
| `coupon_strip_frame` | 枠の半分の長さの帯（7.5u = 146.9 mm・柱だけ） | 27 分 | 2.9 cm³ |

### 1. b（と a）: 大きさ・間隔と、穴の広げ方

`coupon_b_frame` ＋ `coupon_ab_base` ＋ `coupon_b_caps`。a は `coupon_a_frame` ＋ 同じ板 ＋ `coupon_a_caps`。

列（枠の手前と奥の縁の点 1・2・3）で穴が 0.1 ずつ広い（片側の隙 0.20 / 0.25 / 0.30）。台は全部 3.4（浮き 0.2）。

| すること | 見るもの | 決まること |
|---|---|---|
| キャップを入れる | 下から抵抗なく入るか。引っ掛かる列はどれか | 穴の広げ方（`CAP_CLEAR`） |
| 表に返して 1 個ずつ軽く押し、離す | **自分の重さで落ちて、指を離すと元の高さに戻るか**（スイッチは 0.1 N ≒ 10 g でしか戻さない。擦れる列は使えない） | 同上 |
| 裏返して振る | 落ちてこないか。つばが掛かっているか | つばの出（`TAB_REACH`） |
| 指で横・斜めに揺する | がたの量。隣と当たらないか | 穴の広げ方 |
| 9 個を並べて打つまねをする | キーの大きさと間隔（a は隙が広い・b は詰まっている） | **案 A か B か**（利用者の好み） |
| 上面を見る・なでる | 積層の跡が気になるか。面取りの大きさ | 上面の仕上げ（open-gaps #13） |

### 2. standin: 押す面の高さ（浮き・がた・押し込み）

`coupon_standin_frame` ＋ `coupon_standin_base` ＋ b のキャップ 6 個。

台（スイッチの代わり）の高さが 6 通り。キャップの押す面は 3.6。**番号は板の台の手前の点と、枠の縁の点**（手前の列が 1〜3、奥の列が 4〜6）。

| 番号 | 台の高さ | 実物でいうと | 浮き |
|---|---|---|---|
| 1 | 3.2 | ステムが公差でいちばん低い | 0.4 |
| 2 | 3.3 | | 0.3 |
| 3 | 3.4 | **名目** | 0.2 |
| 4 | 3.5 | SKRACAE010 の名目 | 0.1 |
| 5 | 3.6 | ステムがいちばん高い | 0 |
| 6 | 3.7 | 範囲の外（SKRACAE010 のいちばん高い）。**押し込み 0.1** | −0.1（枠が浮く） |

| すること | 見るもの | 決まること |
|---|---|---|
| 各キーを指で上下に動かす・振る | がたの量と音。1 番（0.4）が許せるか | 押す面 3.6 のままでよいか（`POCKET_DEPTH`・`TAB_T`） |
| 5 番を見る | 浮き 0 で、キャップが台とくぼみの両方に触れているか（刷った高さが設計どおりか） | 刷った物の高さの誤差 |
| 6 番を見る | 枠がそこだけ浮くか（柱が板から離れる）。浮かなければ、刷った物が設計より 0.1 以上低い | 同上 |
| ノギスがあれば | 板の台の高さ（板の上面から）・枠の柱の高さ 3.0・キャップの厚さ 2.4・つばの厚さ 0.4 を測る | 層の倍数どおりに出たか |

### 3. latch: 掛かり方

`coupon_latch_frame` ＋ `coupon_latch_base` ＋ `coupon_latch_caps`。キャップの上面の点と枠の縁の点が同じ番号の穴に入れる。

| 番号 | 形 | 刷る向き | 押す面 | 狙い |
|---|---|---|---|---|
| 1 | つば F・厚さ 0.4 | 下面が下 | 3.6 | **本番の案**。掛かる面は上向きの面 |
| 2 | つば F・厚さ 0.6 | 下面が下 | 3.4 | つばを厚く（押す面が 0.2 下がる） |
| 3 | 45° の足 C・首 0.4 | 上面が下 | 3.4 | 掛かる面を斜面に（垂れない） |
| 4 | 45° の足 C・首 0.6 | 上面が下 | 3.6 | 同上 |
| 5 | 平らな足 S・首 0.4 | 上面が下 | 3.4 | 販売者と同じ形（掛かる面が宙に張り出す） |
| 6 | 平らな足 S・首 0.6 | 上面が下 | 3.6 | 同上 |

| すること | 見るもの | 決まること |
|---|---|---|
| 刷り上がりを見る | 5・6 番の足の付け根（掛かる面）が垂れているか。1・2 番のつばの上面はきれいか | F でよいか |
| 組んで、軽く押して離す | 戻るか。3・4 番は斜面で片側に寄って引っ掛からないか | 掛かり方 |
| 浮きを比べる | 押す面が同じ組（1・4・6 は 3.6、2・3・5 は 3.4）で、がたが同じか。違えば、その形は高さが設計どおりに出ていない | 高さの出方 |
| 上面を比べる | 1・2 番（刷る向きの上）と 3〜6 番（ベッドの面）の見た目・指ざわり | 上面の仕上げ |
| 指の爪でこじる | 抜けないか。つばが折れないか（1 番は厚さ 0.4 = 2 層） | つばの厚さ |

### 4. wide: 幅の広いキー

`coupon_wide_frame` ＋ `coupon_wide_base` ＋ `coupon_wide_caps`。台は中心に 1 個だけ（スイッチ 1 個で支える想定）。

| すること | 見るもの | 決まること |
|---|---|---|
| 真ん中を押す | 普通のキーと同じか | — |
| 端を押す | シーソーのように傾く量。反対の端が浮いて枠に引っ掛からないか。押した側が板に着かないか（計算では 2.25u で 1.4° 傾き、押した側が 1.0 下がる） | スイッチ 1 個でよいか・2.25u に 2 個要るか（open-gaps #5・#17） |
| 端を押したまま離す | 引っ掛からずに戻るか | 同上 |
| キャップをねじる・曲げる | 2.25u の板が柔らかくないか | キャップの厚さ |

### 5. strip: 枠の反り

`coupon_strip_frame` だけ（板もキャップも無い）。本番の枠は幅 286 で、A1 mini では 2 枚（約 143 ずつ）に分ける。その 1 枚の長さ。

| すること | 見るもの | 決まること |
|---|---|---|
| 柱を下にして、平らな面（ガラス・定盤・机）に置く | 全部の柱（リブの 6 本＋手前 7 本＋奥 7 本）が着くか。端を押すと反対が浮くか | 枠の反り。柱の高さのばらつき |
| 浮いた所にすき間ゲージか紙（約 0.1）を差す | 浮きの量 | 0.1 を超えるなら、枠の留め方（ねじの数）・刷る向き・分け方を見直す |
| b のキャップを入れてみる | 長い枠でも穴の大きさが同じに出ているか（端と真ん中） | 穴の広げ方 |

### 記入表（あとで刷る 14 個）

| 項目 | 結果 |
|---|---|
| 刷った日・フィラメント・スライサーと「象の足の補正」の値 | |
| 案 A / B の好み | |
| 穴の列（1 = 0.20 / 2 = 0.25 / 3 = 0.30）: 落ちて戻る列 | a: 　　 b: |
| 穴の列: がたが許せる列 | a: 　　 b: |
| 裏返して振って落ちたキャップ | |
| standin: 許せる浮き（番号） | |
| standin 5 番（浮き 0）と 6 番（押し込み）の様子 | |
| 実測: 柱の高さ（3.0）・キャップの厚さ（2.4）・つば（0.4）・台 3 番（3.4） | |
| latch: 掛かる面のきれいさ（1〜6） | |
| latch: 戻り・引っ掛かり（1〜6） | |
| latch: 上面の見た目の好み（1・2 と 3〜6） | |
| wide: 端を押したときの傾き・引っ掛かり（1.5u / 1.75u / 2.25u） | |
| strip: 着かなかった柱と浮きの量 | |
| バリを取る必要があった所 | |
| そのほか気づいたこと | |

## 6. ねじの試し刷り（coupon_screw・**済み**: 2026-10-04 に刷った。φ1.8 は空回り → 8 章の v2 で φ1.6 に決めた）

**何のために**: 枠と基板は、基板の下から M2×4 のねじを**枠の樹脂に直にねじ込んで**留める。ねじ穴のまわりの樹脂は薄い（内側 0.7 mm）。
割れたり空回りしたりするなら、基板の穴の位置を変えるしかないが、**基板は頼んだ後では直せない**。だから先に、同じ形を小さく刷って締めてみる
（1 回目の監査 E 重要 2・open-gaps #33）。絵: `build/cckb-click/coupon_screw.png`。

### 何を刷るか

| | |
|---|---|
| ファイル | `build/cckb-click/coupon_screw_plate.stl`（4 つの部品を 1 枚に並べた物） |
| 中身 | **枠の切れ端 2 つ**（本番の枠から切り出した壁。長い方 = 奥の壁でねじ穴 3 つ・短い方 = 左の壁でねじ穴 1 つ）と、**当て板 2 枚**（基板の代わり。厚さ 1.6・穴 φ2.2） |
| 時間・材料 | 0.4 ノズル: 造形 約 22 分（準備込み 約 28 分）・2.5 cm³（約 3 g）。2026-10-04 に Bambu Studio と OrcaSlicer の両方でスライスした値 |
| ほかに要る物 | **スリムヘッド小ねじ M2×4 を 4 本**（本番と同じ物。docs/shopping-list.md）・精密ドライバー・ノギス |

### どう刷るか

最小の一式（上の 2 章）と**同じ**: A1 mini・0.4 ノズル・Bambu PLA Basic・設定 `cckb-click precise 0.10 @A1M 0.4`・回さない・サポートもブリムも無し。
枠の切れ端は上面が下（ねじ穴が上を向く）。当て板は平らに。**本番の枠を刷るのと同じフィラメントで刷る**（色や銘柄が違うと割れ方が変わる）。

### ねじ穴の番号

| 番号 | どこ | 壁の形 | 下穴の内側の肉 |
|---|---|---|---|
| 1 | 長い方の、角を落としていない側の端 | **本番と同じ** | 0.7 |
| 2 | 長い方の真ん中 | **本番と同じ**（1 と同じ。ばらつきを見る） | 0.7 |
| 3 | 長い方の、**端の角が斜めに落としてある側** | 比べるために、壁を 0.5 厚くした（本番の形ではない） | 1.2 |
| 4 | 短い方 | **本番と同じ**・壁を厚くする幅が狭い所（幅の広いキーの脇の 3 本がこの形） | 斜めに 0.49 |

### すること

1. 冷めてから外す。枠の切れ端を、ねじ穴を上にして机に置く。
2. **締める前に見る・測る**: ねじ穴のまわりに割れ・すき間が無いか。ノギスで、ねじ穴の所の壁の厚さ（外の面から内の面まで）を測って控える。
3. 当て板を載せる（穴を合わせる。長い方に長い板・短い方に短い板）。**押さえ付けない。**
4. ねじを 1 本ずつ、当て板の穴から入れて締める。**止まった所から 1/8 回転まで。**それ以上回さない。
   締めている間に、当て板が浮くか・最後に座るかを見る。
5. 4 本とも締めたら、壁を見る・測る（2 と同じ所）。
6. **全部ゆるめて抜き、また締める。これを 5 回**（本番で分解して組み直す回数の見込み）。毎回、止まる手応えがあるかを見る。
7. 5 回目に締めた状態で、当て板をつまんで枠から引きはがす向きに**軽く**こじる。

### 何を見るか・結果の意味

| 見る所 | こうなら | 意味・次にすること |
|---|---|---|
| 1・2・4 の壁（締めたあと） | 割れ・白い筋が**無い**・壁の厚さが 0.1 より膨らんでいない | いまの形でよい。**基板はこのまま頼める**（この項目について） |
| 1・2 の壁 | 内側（薄い方）に**割れ・白い筋**・0.1 を超える膨らみ | 内側の肉 0.7 では足りない。3（1.2）を見る ↓ |
| 3 の壁 | 1・2 が割れて、3 は割れない | **肉を厚くすれば持つ。**基板を頼む前に Claude に言う: ねじ穴をもっと外へ寄せるか（基板の縁の決まりを見直す）、枠の壁を厚くする（外形が変わる）かを決め直す |
| 3 の壁 | 3 も割れる | 肉の問題ではない。下穴が小さすぎる。`SCREW_PILOT_D` を 1.9 にして刷り直して試す（枠だけの直し。基板は変わらない） |
| 4 の壁 | 4 だけ割れる | 幅の広いキーの脇の 3 本（左の壁 2・右の壁 1）だけ弱い。Claude に言う（その 3 本の位置か、空きランドの位置を見直す。**基板の変更**） |
| 締める手応え | 止まらずに**空回り**する（1 回目から） | 下穴が大きい。`SCREW_PILOT_D` を 1.7 にして刷り直す（枠だけ） |
| 締める手応え | 2〜5 回目で空回りするようになる | ねじ山が持たない。何回目からかを控えて Claude に言う（分解できる回数が決まる。手順書の「分解する」に書く） |
| 締める手応え | **きつくて入らない**・ねじの頭がなめそう | 下穴が小さい。φ1.8 のドリルを手で通す。それで入るなら本番の枠も同じにする |
| 当て板 | 締めても**浮いたまま**・こじると簡単に離れる | ねじが効いていない（上の空回りと同じ扱い） |
| ねじの先 | 枠の上面（机に着けていた面）に**ふくらみ・白い点** | ねじが長すぎる側に出ている。Claude に言う（下穴の深さ 2.8・ねじの先 2.4 のはず） |

### 記入表（ねじの試し刷り）

| 見る所 | 1 | 2 | 3（厚い） | 4（左の壁） |
|---|---|---|---|---|
| 締める前の壁の厚さ [mm] | | | | |
| 1 回目に締めたあとの壁の厚さ [mm] | | | | |
| 割れ・白い筋（どこに） | | | | |
| 止まる手応え（1 回目） | | | | |
| 何回目まで手応えがあったか（5 回まで） | | | | |
| 当て板が浮いたか・座ったか | | | | |

### 結果（2026-10-04・利用者が刷って締めた）

A1 mini・0.4 ノズル・精度優先の設定・ふつうの M2×4 の小ねじ（なべ／低頭。タッピングではない）。

| 見た所 | 結果 |
|---|---|
| 締める手応え | **入るが、最後まで締めると空回りする**（ねじ山が持たない）。4 本とも下穴 φ1.8 |
| 壁 | 割れ・白い筋は無い。4 番（斜めの肉 0.49）も割れていないが、利用者の感触では頼りない |

**原因（数で）**: M2 並目のおねじは外径 2.0・相手のめねじの内径は 1.567（ISO 724）= 山の高さは半径で 0.2165。下穴 φ1.8 だと掛かりは半径 0.10（山の 46 %）。
スライスした G-code で、下穴の外周の線が空けている径は 1.76〜1.79 だった（設計どおり。穴の補正は 0）。**下穴が大きすぎる**（表の「空回り → 1.7 にして刷り直す」の行）。
1 段ずつでは足りないかもしれないので、v2（8 章）で 1.5・1.6・1.7 を一度に試す。

### 回した検査／回していない検査（ねじの試し刷り）

**回した**: 切れ端が本番の枠の立体と同じ（足したのは 3 番の厚い壁と印の点だけ）・下穴の深さと位置が本番と同じ・肉が 0.70／1.2／0.49・
当て板が基板と同じ厚さと穴（穴の縁から板の縁まで 1.0）・4 つの立体が平らに並ぶ（tests/test_cckb_click_case.py）。
Bambu Studio と OrcaSlicer で、本番と同じ設定でスライス（警告 0・設定 25 個が G-code と一致。`tools/slice_precise.py n04 coupon_screw_plate`）。
絵（coupon_screw.png）を自分で見た。

**回していない**: 実際に刷っていない・締めていない。割れるかどうかは、この試しでしか分からない。

## 7. 角の試し刷り（coupon_corner・**済み**: 2026-10-04 に刷った。つまみは奥すぎ・蓋は留まらない → 8 章の v2）

> **この章は、2026-10-04 に刷った物の記録。**いま `coupon_corner_plate.stl` を出すと、**ねじで留める新しい蓋と新しい口の形**で出る（9 章）。
> この章の蓋の話（差し込み式・山・腕・`COVER_BUMP`・`CELL_SLOT_CLEAR`・`FINGER_NOTCH`）は、もう無い形と値のこと。

**何のために**: 電源スイッチを基板の内側へ動かしたので、つまみは枠の外へ出ない。**枠の切り欠きから爪を入れて動かす。**
スイッチの位置は基板で決まり、**基板は頼んだ後では直せない**。爪が届かないなら、頼む前に位置か切り欠きを直す。
同じ角にある電池の口と、差し込み式の蓋も一緒に試す（open-gaps #34）。絵: `build/cckb-click/coupon_corner.png`・`main_corner.png`。

### 何を刷るか

| | |
|---|---|
| ファイル | `build/cckb-click/coupon_corner_plate.stl`（5 つの部品を 1 枚に並べた物） |
| 中身 | **枠の切れ端**（本番の枠の右手前の角を切り出した物。約 40 × 22 mm）・**当て板**（基板の代わり。厚さ 1.6。スイッチの本体の代わりの塊と、電池クリップの代わりの壁が生えている）・**つまみの代わり**（T 字の小片）・**電池の代わり**（φ16 × 3.2 の円板）・**蓋**（本番と同じ物） |
| 時間・材料 | 0.4 ノズル: 造形 約 27 分（準備込み 約 33 分）・3.9 cm³（約 5 g）。2026-10-04 に Bambu Studio と OrcaSlicer の両方でスライスした値 |
| ほかに要る物 | あれば M2×4 のねじ 1 本（ねじの試し刷りと同じ物。無くても試せる）・あれば本物の CR1632 |

（蓋だけの STL `cover_battery.stl` は、差し込み式の蓋が使えなかったので一度出すのをやめ、**ねじで留める蓋になってから、また出している**: 9 章）

### どう刷るか

最小の一式（上の 2 章）と**同じ**: A1 mini・0.4 ノズル・Bambu PLA Basic・設定 `cckb-click precise 0.10 @A1M 0.4`・**回さない**・サポートもブリムも無し。
STL の中で、もう刷る向きに置いてある: 枠の切れ端は上面が下・当て板は平ら・**蓋は手前の面が下**（L 字が立っている）・つまみと電池の代わりは平ら。

### 組み方

1. 冷めてから外す。当て板を、塊と壁を上にして机に置く。左と奥の縁に、低い当て（高さ 2 の縁）がある。
2. **つまみの代わり**（T 字）を、スイッチの塊の溝に落とす。T の足が、塊の外側の壁の窓から外へ出る向き。前後に 1.6 mm 滑る。
3. **枠の切れ端**を、上面を上にして当て板にかぶせる。左と奥の当てに突き当てる。右と手前は、枠が当て板より 0.3 外へ出る（本番と同じ）。
   ねじがあれば、裏から、右手前の穴（手前の縁の、いちばん右の穴）に 1 本締める。無ければ指で押さえる。
4. **電池の代わり**を、手前の口から、止まるまで押し込む。本物の CR1632 でもよい。
5. **蓋**を、上の板を切り欠きに合わせて、手前から奥へまっすぐ滑らせる。カチッと止まるまで。

### すること・何を見るか・結果の意味

**A. 電源スイッチのつまみ**（基板の位置に効く。**いちばん大事**）

| すること | こうなら | 意味・次にすること |
|---|---|---|
| 右の切り欠きに、**上から**爪を入れて、つまみを奥・手前へ動かす | 爪がつまみに届き、両方の端まで動かせる | いまの位置と切り欠きでよい。**基板はこのまま頼める**（この項目について） |
| 同じことを、**横（右）から**爪を入れて | 同上 | 同上 |
| | 爪がつまみに届かない・指の腹が切り欠きの角に当たって押せない | まず切り欠きを広げる（`PSW_NOTCH` の幅 10 → 12〜14。右の枠だけの直し・基板は変わらない）。刷り直して試す |
| | 広げても届かない・つまみが奥すぎる | **基板を頼む前に Claude に言う。**スイッチを外へ寄せ直すか（JLC の「縁から 2.5 mm」を割る）、上向きのつまみの部品に替えるかを決め直す |
| 机に置いた鍵盤を想像して、手のひらや袖が切り欠きに触れたとき | つまみは動かない | 鞄の中で勝手に切り替わらない、という狙いどおり |
| 切り欠きの内側の縁（つまみのすぐ上の、厚い所）を爪で強めに押す | 割れない・白くならない | 壁の強さは足りている |

**試し刷りのつまみは樹脂の小片で、滑る固さは本物と違う**（本物は 150 ± 100 gf = 軽くカチッと動く）。見るのは「爪が届いて、押す向きに力を掛けられるか」。

**B. 電池の出し入れ（蓋なし）**

| すること | こうなら | 意味・次にすること |
|---|---|---|
| 蓋を外した状態で、電池を口から押し込み、上の切り欠きから爪で手前へ引き出す | 出し入れできる | 電池の口と切り欠きはいまのままでよい（本物のクリップは電池を上から押さえるので、本番はもう少し固い） |
| | 口に引っ掛かる・爪が電池に届かない | `CELL_SLOT_CLEAR`・`FINGER_NOTCH` を広げる（右の枠と蓋の直し・基板は変わらない） |

**C. 蓋**

| すること | こうなら | 意味・次にすること |
|---|---|---|
| 蓋を差し込む | まっすぐ滑って、最後にカチッと止まる。枠の上面・手前の面と段が無い | よい |
| | 途中で固い・入らない | 蓋の縁のバリを取る。それでも固ければ `COVER_CLEAR` 0.15 → 0.2（蓋だけ刷り直す・約 3 分） |
| | 止まらずに抜ける・がたつく | Claude に言う。**山の掛かりは上げない**（0.25 → 0.30 で、ばねのひずみが 1.04 % になり許容 1.0 % を超える）。山の斜面を立てる（`COVER_BUMP` の滑る向きの長さ 0.8 → 0.6）側で直す。蓋だけ刷り直す |
| 蓋の上面の溝に爪を掛けて、手前へ引く | カチッと外れて抜ける | よい |
| | 固くて抜けない・爪が溝に掛からない | 山を低く（0.25 → 0.2）か、溝を深く（`COVER_GRIP`）。蓋だけ刷り直す |
| **20 回、抜き差しする**（手前へまっすぐ。上へこじらない） | 腕（手前の板の上の両端の細い所）と、真ん中の柱（幅 3.7）が折れない・白くならない・最後まで止まる | ばねは足りている（計算ではひずみ 0.87 %・許容 1.0 %。腕 6.3 × 0.7・山は腕の先の 0.8 だけ = ばねとして効く長さ 5.5。**許容は曲げの値から置いた物で、回数は計算では言えない** = この 20 回が答え） |
| | 腕が折れる・白くなる | 何回目かを控えて Claude に言う（腕を細く〔0.6〕・掛かりを下げる〔0.2〕。蓋だけの直し。腕はもう延ばせない: 真ん中の柱が細くなる） |
| 蓋を付けたまま、上の板を上へこじる・切れ端を振る | 外れない | ひさしが効いている |
| 蓋を付けた状態で、電池の代わりを揺する | 蓋に当たる音がしない・蓋が押し出されない | 蓋は電池に触れていない（隙 0.5） |

### 記入表（角の試し刷り）

| 見る所 | 結果 |
|---|---|
| 上から爪でつまみを動かせたか（奥へ・手前へ） | |
| 横から爪でつまみを動かせたか | |
| 切り欠きの幅は足りるか（狭い・ちょうど・広い） | |
| 電池の代わり（か本物）を出し入れできたか | |
| 蓋: 入る固さ（ゆるい・ちょうど・固い） | |
| 蓋: カチッと止まるか・引き抜く固さ | |
| 蓋: 20 回のあとの腕の様子 | |
| 蓋: 枠の上面・手前の面との段（mm） | |
| そのほか気づいたこと | |

### 結果（2026-10-04・利用者が刷って触った）

| 見た所 | 結果 |
|---|---|
| つまみ | 動かせる。ただし**奥に入りすぎている**（利用者）。つまみの先は基板の縁の 1.05 内・枠の外面の 1.35 内 |
| 電池の代わりの出し入れ | するっと出し入れできる。**ただし試し刷りには電池を押さえるばね（クリップ）が無い** = 本物のクリップの固さは分からない（利用者の指摘。P2 は基板が来てからもう一度） |
| 蓋 | **留まらない。**カチッと言わず、載っているだけ。傾けると落ちる |

**蓋が留まらなかった理由（スライスした G-code と立体から測った）**:

- 山の掛かりは設計で 0.25。**刷る線では、設計の高さ（口の上の壁の下面から 0.23 上）まで届くのは 1 層（厚さ 0.1 mm）だけ**。
  その前後の 2 層は 0.10、さらに外は 0。幅 0.36 の線 1 本の点のような山で、角が丸まれば 0.1〜0.15 しか残らない
- 蓋は上下に動ける: 下へ 0.1（基板まで）・上へ 0.15（ひさしまで）。**下がると掛かりは設計でも 0.15**（検査 `test_v1_cover_diagnosis…`）
- 蓋と枠の滑る隙は片側 0.15。掛かり 0.25 は、この隙と刷る誤差（0.1 前後）と同じ大きさ = 誤差に埋もれる
- ひさしは「上へ 0.15 より先へ行かせない」だけで、蓋を下へ押さえてはいない。蓋が山の位置まで入ること自体は、立体では入る（奥の壁に 0.15 で止まる）
- 腕の力は、設計の掛かりいっぱいで 1 本 0.43 N。掛かりが 0.1 なら 0.17 N

→ **掛かりを 2 倍以上にする。**いまの腕（まっすぐ・太さ 0.7・効く長さ 5.5）のまま掛かりを 0.6 にするとひずみは 2.1 %（許容 1.0 %）= 形を変えるしかない。v2（8 章）。

**つまみが奥すぎる件（立体を当てて測った）**: 指先を半径 7.5 の硬い球と見て（仮定）、机に置いたままの鍵盤の切り欠きへ入れると、
球はつまみの先より 0.22 手前で止まる（基板の縁と机が先に当たる。切り欠きの幅ではない）。爪なら届く。v2 で、位置を 0.75 外へ寄せた物と並べて比べる。

### 回した検査／回していない検査（角の試し刷り）

**回した**: 枠の切れ端が本番の枠の立体と同じ（足したのは左の端の壁だけ）・スイッチの塊の外形と背、つまみの幅と先の位置、行程の端が本物と同じ・
電池の代わりが φ16 × 3.2 で止めに当たる位置・当て板の厚さと穴（H15 と蓋のねじ穴 2 つ）が基板と同じ・5 つの立体が平らに並ぶ・部品どうしが当たらない
（tests/test_cckb_click_case.py）。蓋は、手前の面を下にして 45° より寝た下向きの面が無い。Bambu Studio と OrcaSlicer で、本番と同じ設定でスライス
（警告 0・設定 25 個が G-code と一致。`tools/slice_precise.py n04 coupon_corner_plate`）。絵（coupon_corner.png）を自分で見た。

蓋の腕は G-code で数えた: **幅 0.42 の線 2 本**（中心の間 0.34。11 層のうち 1 層目だけ幅 0.5 の線 1 本）・山は各層に長さ 0.35〜0.44 の線 1 本（Bambu Studio・OrcaSlicer で同じ）。

**回していない**: 実際に刷っていない・触っていない。つまみの小片と溝の隙 0.15・蓋の隙 0.15・腕の太さ 0.7（線 2 本で約 0.76 になる）が、刷った物でちょうどよいかは分からない。
G-code の線の絵は描いていない（数は数えた）。

## 8. 試し刷り v2（coupon_v2・2026-10-04・**利用者が刷って試した。結果は下の「結果」**）

**結論（結果）: 下穴は φ1.6 に決めた・電源スイッチは (ii) 0.75 外に決めた（基板を直した）・蓋は 3 つとも使えない → 蓋はねじで留める形に変えた（9 章）。**
**蓋 3 つ（C1〜C5）の形は、コードから消した**（2026-10-04: 枠の口の形が変わり、同じ物はもう出せない。この章の C の数と結果は、刷った物の記録として残す）。いま `click_coupon_v2.py` が出すのは A と B の 8 個。刷った板の G-code は `build/cckb-click/coupon_v2_plate_n04.gcode.3mf`（`tools/slice_v2.py` を回すと、A と B だけの板で上書きされる）。
この章の「いまの位置」「(i)」は、v2 を作った時の位置（本体が基板の縁から 2.5）のこと。**いまの本番は (ii)。**

**何のために**: 6 章・7 章の結果（ねじが空回り・蓋が留まらない・つまみが奥すぎる）を、1 枚で試し直す。
**ねじの留め方と電源スイッチの位置は基板に効く**（基板は頼んだ後では直せない）。蓋は枠と蓋だけの話（刷り直せる）。

**組み方と見る所の絵: `build/cckb-click/coupon_v2_howto.png`**（文より先にこれを見る）。決め方の記録は docs/decisions/2026-10-04-coupon-v2.md。

### 何を刷るか

| | |
|---|---|
| ファイル | **`build/cckb-click/coupon_v2_plate_n04.gcode.3mf`**（スライス済み。Bambu Studio で開いてそのまま送る）。STL は `coupon_v2_plate.stl` |
| 時間・材料 | 0.4 ノズル: 造形 54 分（準備込み 約 1 時間 1 分）・6.5 cm³（8.2 g）。Bambu Studio 2.8.2 の値（OrcaSlicer では 59 分・6.5 cm³） |
| どう刷るか | 6 章・7 章と同じ: A1 mini・0.4 ノズル・Bambu PLA Basic・設定 `cckb-click precise 0.10 @A1M 0.4`・回さない・サポートもブリムも無し |
| ほかに要る物 | M2×4 のねじ 6 本（前と同じ物）・精密ドライバー |

（蓋だけの STL `coupon_v2_cover_1.stl`〜`_3.stl` は、もう出さない。`click_coupon_v2.py` を回すと build/ から消える。）

| 記号 | 物 | 何を試すか | 違い（見分け方） |
|---|---|---|---|
| A1・A2 | 奥の壁の切れ端（本番の枠から切り出し）と当て板 | ねじの下穴。内側の壁がふつうの所（v1 は肉 0.70） | 下穴 φ1.5／1.6／1.7（外面の縦の溝 1／2／3 本） |
| A3・A4 | 左の壁の切れ端を 3 つ継いだ物と当て板 | 同じ。壁が薄い所（幅の広いキーの脇。v1 は斜めに 0.49） | 同じ |
| B1・B2・B3・B4 | 右の壁の切れ端（切り欠き 2 つ）・当て板（スイッチの本体の代わり 2 つ）・つまみの代わり 2 個 | 電源スイッチの位置 | (i) いまの位置（上面に点 1 個）・(ii) 0.75 外（点 2 個） |
| C1・C2 | 電池の口の枠の切れ端（本番の枠から切り出し・溝を深くした）と当て板 | 蓋の相手。**3 つの蓋が同じ枠に入る** | — |
| C3 | 蓋 1（上の板に点 1 個） | 折り返しばね・掛かり 0.60 | 手前から見ると腕が上下 2 段 |
| C4 | 蓋 2（点 2 個） | 細い腕 2 本・掛かり 0.45 | v1 と同じ並びで腕が細い |
| C5 | 蓋 3（点 3 個） | ばね無し。両端の筋が口の壁に食い込む（片側 0.10） | 腕が無い |

### A. ねじ: 数

| 下穴（設計） | ねじ山の掛かり（半径）・山の高さに対して | 内側の壁の残り: 奥の壁／左の壁 | G-code で線が空けている径: 奥の壁／左の壁 |
|---|---|---|---|
| φ1.8（v1・本番のいま） | 0.10・46 % | 0.71／0.49 | 1.76〜1.79／測っていない |
| φ1.7（溝 3 本） | 0.15・69 % | 0.77／0.55 | 1.64／1.60 |
| φ1.6（溝 2 本） | 0.20・92 % | 0.81／0.59 | 1.54／1.50 |
| φ1.5（溝 1 本） | 0.22・100 %（めねじの内径 1.567 より小さい = ねじが樹脂を押し広げる） | 0.87／0.65 | 1.44／1.40 |

- 掛かりの長さは前と同じ 2.4 mm（6 山）。深さ 2.8・位置・壁の形は本番の枠のまま（**枠の外形も基板も変えない**）
- **ねじの外径 2.0 の外に残る壁は、下穴の径に関係なく同じ**（内側 0.6・薄い所は斜めに 0.39）。下穴を小さくすると、ねじが押し広げる樹脂が増える = 割れやすい側
- 薄い壁では、線が設計より 0.10 内へ寄る（壁が線 1 本になるため。本番の枠も同じ切り方）= 左の壁の方が 0.1 きつい
- ナットを壁に埋める案は入れていない。M2 のナット（六角 ISO 4032・四角 DIN 562 とも二面幅 4.0）は、ねじの中心から内へ 2.0 要るが、キーの穴の縁までは 1.6
  = **0.4 はみ出す**（キャップの胴との隙 0.2 を越える）。入れるには穴の位置を 0.8 以上外へ（基板の縁まで 1.0 を割る）か、枠と基板を片側 0.8 以上広げる。
  熱圧入インサート（外径 3.2）も同じ理由で入らない（前の検討）。寸法の出どころ（2026-10-04 に検索で確かめた・規格書そのものは読んでいない）: Würth の ISO 4032 M2（二面幅 4・高さ 1.6）・DIN 562 M2（二面幅 4・厚さ 1.2）・ISO 724 の M2 のめねじの内径 1.567

**結果の読み方**

| こうなら | 意味・次にすること |
|---|---|
| ある径で、6 本とも止まる手応えがあり、5 回締め直しても空回りしない・壁に割れも白い筋も無い | その径を `SCREW_PILOT_D` にする（枠だけの直し・**基板は変えない**） |
| 奥の壁はよいが、左の壁（A3）だけ割れる・白くなる | 幅の広いキーの脇の 3 本（H16〜H18）が弱い。その径を教えてください（その 3 本だけ径を変えるか、位置を見直す = 基板） |
| φ1.5 でも空回りする | 樹脂に直に切るのをやめる。**基板の変更になる**（穴を外へ・板を広げてナットかインサート）。Claude に言う |
| φ1.7 でも固くて入らない・頭をなめる | 1.8 との間（1.75）で刷り直す |

### B. つまみ: 数

| | つまみの先 → 基板の縁／枠の外面 | 本体 → 基板の縁 | 外面での切り欠きの幅 | 指先（半径 7.5 の硬い球・机の上）が、つまみの先より奥へ入る量 |
|---|---|---|---|---|
| v1（いまの位置・前の切り欠き） | 1.05／1.35 内 | 2.50 | 12.0 | **−0.22**（届かない） |
| (i) いまの位置・新しい切り欠き | 1.05／1.35 内 | 2.50 | 14.8 | **−0.03**（ほぼ届かない） |
| (ii) 0.75 外・新しい切り欠き | 0.30／0.60 内 | **1.75** | 14.8 | **+0.16**（持ち上げていれば +0.38） |

- 新しい切り欠き: 内側の幅は 10 のまま・外面へ向かって片側 2.4 ずつ広げた（14.8）・内側の面の上の縁を 2.0 斜めに落とした（指の腹が上から斜めに入る）。枠の外へ出る物は無い
- **指先の球は仮定**（人差し指の幅 15 前後の半分）。実物の指はやわらかいので、数は「比べる物差し」。−0.22 → −0.03 → +0.16 の順は変わらない
- 届かないのは、**基板の縁と机が先に指に当たるから**（つまみは基板の上面から 0.2〜1.2 にある）。切り欠きを広げても (i) は届かない
- **(ii) は JLC の「部品の本体と基板の縁は 2.5 mm 以上」を割る**（1.75）。選ぶなら、頼み方（Standard か手はんだ）を決め直す（docs/order-steps.md §2-1）
- つまみの代わりは v1 と同じ作り（行程 1.6・隙 片側 0.15。上は枠の厚い屋根で抜けない）

**結果の読み方**

| こうなら | 意味・次にすること |
|---|---|
| (i) で、指の腹で楽に動かせる | 基板のスイッチの位置はそのまま。切り欠きだけ新しい形にする（右の枠だけ） |
| (i) は爪でないと動かせない・(ii) なら指で動かせる | **基板を頼む前に決める**: (ii) にして JLC の頼み方を変えるか、(i) のまま爪で使うか、つまみに被せる刷り物（下の「入れていない案」）を足すか |
| (ii) でも動かしにくい | 横向きのつまみをやめる（上向きのつまみの部品）か、被せる刷り物。Claude に言う |
| (ii) は、手のひらや袖で勝手に動きそう | (i) に戻す理由になる（内側へ動かしたのは、鞄の中で切り替わらないため） |
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

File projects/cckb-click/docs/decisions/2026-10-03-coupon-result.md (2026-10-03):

# 試し刷りの結果: 案 B・穴 17.05 角・つばのキャップ・0.4 ノズルの刷り方を採る

- **日付:** 2026-10-03
- **状態:** 決定
- **決めた人:** 利用者（刷って触った結果）

## 1. なぜ決める必要が生じたか

基板は発注すると直せない。基板を設計する前に、キャップと枠の形（穴の大きさ・隙・掛かり方）と刷り方を決める必要があった
（決定記録 2026-10-03-structure・2026-10-03-print-recipe の「まだ決めていないこと」）。

## 2. 事実はどうか

**利用者が刷って触った結果（2026-10-03。docs/coupon-test.md の記入表）。**刷ったのは最小の一式（穴 3 つの枠・キャップ 3 個・板・測る所）。
A1 mini・0.4 ノズル・精度優先の設定。

| 見た物 | 結果 |
|---|---|
| キャップが上へ抜けるか | 抜けない |
| 穴 1 番（17.05 角・片側の隙 0.20） | がたがいちばん少ない。それでもキャップは自分の重さで自由に動く（カタカタ鳴る） |
| 仕上がり | きれい |
| 測る塊（設計 10.00） | 約 10 mm |

**刷っていない物**（あとで刷る 14 個: a / b の 3×3・standin・latch・wide・strip）。だから次のことは**この結果からは分からない**:
案 A の大きさ・台の高さを変えたときのがた・ほかの掛かり方（S・C）との比較・幅の広いキーの端を押したとき・長い枠の反り。

## 3. 効く条件

| # | 条件 | 実データ | 何で確かめたか |
|---|---|---|---|
| 1 | キャップが擦れずに戻る（スイッチの戻す力は 0.1 N） | 隙 0.20 で自分の重さ（約 0.6 g ≒ 0.006 N）で動く | 外（刷った実物） |
| 2 | 上へ抜けない | 抜けない | 外（刷った実物） |
| 3 | がたが小さい | 3 つの穴のうち 1 番がいちばん小さい | 外（刷った実物） |
| 4 | 寸法が狙いどおりに出る | 10 → 約 10 | 外（ノギス。**小数は報告なし**） |
| 5 | 62 個・幅の広いキー・長い枠でも同じに出るか | — | **まだ**（1u を 3 個刷っただけ） |

## 4. 影響範囲

穴 17.05 角 → リブ 2.0 → 枠と基板の間の柱の幅（1.6）→ 基板の上の、部品を置けない所 → ダイオードの置き場。
隙 0.20 → キャップの胴 16.65 → 幅の広いキーの胴（1.5u 26.175・1.75u 30.9375・2.25u 40.4625）。
つば（F）→ 枠の下面のくぼみ → リブの中の壁 0.8 → 枠の強さ。

## 5. 決めたこと

- **案 B**（穴 17.05 角・リブ 2.0。`spec.HOLE_B`）。`[暫定]` を外した
- **隙 0.20**（`CAP_CLEAR`。穴は広げない）。`[暫定]` を外した
- **つばのキャップ F**（下面をベッドに刷る）。つばの出 `TAB_REACH` 0.3 の `[暫定]` を外した
- **0.4 ノズル・精度優先の設定**（print/cckb-click_precise_n04.json）。0.2 ノズルは使わない
- X-Y 補正は 0 のまま

## 検討して捨てた案

| 案 | 捨てた理由 |
|---|---|
| 案 A（穴 16.5 × 16.0） | 刷っていない。利用者が B で進めると決めた |
| 穴を広げる（隙 0.25 / 0.30） | 0.20 で動き、がたがいちばん少ない |
| 0.2 ノズル | 0.4 で足りた |

## この決定が乗っている前提（**動いたら読み直す**）

- 1u のキャップ 3 個・穴 3 つの結果。**62 個・幅の広いキー・長さ 143 の枠で同じに出るかは、本番の枠を刷るまで分からない**（open-gaps）
- A1 mini・0.4 ノズル・PLA・この設定。変えたら最小の一式を刷り直す
- 押す面 3.6（浮き 0.2）は**触っていない**（台の高さの試し standin を刷っていない）。基板が来て実物のステムの高さを測るまで `[暫定]`

## 覆す前に読むこと

docs/coupon-test.md の記入表。

## まだ決めていないこと

| 項目 | 決められない理由 |
|---|---|
| 押す面の高さ（`POCKET_DEPTH`・`TAB_T`） | 基板が来てからステムの高さを測る。キャップと枠は刷り直せる |
| 幅の広いキーのぐらつき | 基板が来てから（中心のスイッチ 1 個。足りなければ左右の空きランドにスイッチを足す） |

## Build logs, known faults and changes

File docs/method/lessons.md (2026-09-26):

# 失敗から出た規則

HHKB 分割機（2026-08-04〜09-23）で**実際に起きた**ことだけを、規則の形にしたもの。
出典の番号（#N・日付）は HHKB のリポジトリ（`../2608042258_HHKB_devided`）の
`docs/hardware/open-gaps.md` と各記録を指す。

CLAUDE.md の「検証の作法」はここの要約。**迷ったらここの具体例を読む**——規則だけだと
「自分の件は違う」と思えてしまうが、具体例を読むと同じ形だと分かる。

---

## A. 検査したつもりで、別のものを見ていた（この案件で最も高くついた型）

| 起きたこと | 規則 |
|---|---|
| 誤った並び順どうしを突き合わせて全テストが通った（61 キー全部の行列を取り違えた） | **自分の生成物どうしの一致は検証ではない。**外の事実と突き合わせる |
| `test_keytop_heights_match_the_real_machine` が参照モデルを検査していて、設計を検査していなかった | 検査の対象が本当に「設計」かを確かめる |
| 列の割り当てを「妥当」と報告したが、コードと dtsi の一致しか見ていなかった | 物理位置（外）と突き合わせる |
| 74LVC595 の 16 パッドと電源のダイオードにネットが 1 本も無いのに、DRC 0・未配線 0・378 件の検査が緑 | **ネットの無いパッドは「未配線」に数えられない。**宣言 → パッド → 塗られたネットを端から端まで突き合わせる。引けなければ落とす（握り潰さない） |
| 検査が戻り値（タプル）を辞書として扱い、全比較を黙って飛ばして「当たらない」と出た | **故意に壊して検出できることを確かめてから**検査を足す |
| 自己確認が、素の状態で残っていた別の指摘のおかげで通っていた | 指摘を 0 にしてから変異の効きを見る |
| 「置ける隙間があるか」の検査が、隙間を作るだけで緑になった | 結果の物を数える |
| 走査対象が空でも緑になる検査 | 下限の個数か、宣言から作った正解の集合と照合する |
| 門を説明する散文そのものが門を開けていた | 門は行頭の見出しだけで開く（`^...$`） |
| 自分で書いた文字列どうしの一致を門の検査にしていた | 実物を import して**挙動**で確かめる |

## B. 名前を付けた一部だけ調べて「全部」と言った

| 起きたこと | 規則 |
|---|---|
| 「許容値を全部 0 にした」→ 表の 14 組だけ直し、既定値が掛かる 239 組を放置 | **母数を数えてから「全部」と言う。**名前の数ではなく物の数 |
| 「部品 23 個の全組み合わせで重なり 0」→ 実際の立体は 175 個 | 同上 |
| シルクの線幅の検査が左右の板しか見ず、子基板が 0.12mm のまま | **検査対象に入っていない部品は、検査していないのと同じ** |
| パスコンの検査対象が 2 個だけで、70mm 離れた 1 個を見ていなかった | 同上 |
| 接頭辞 `D` / `SW` で走査して電源部（D_PWR・SW_PWR）を巻き込んだ（4 回） | `re.fullmatch` で絞る |
| 部品表から実機の LED が抜けていたのに「全項目閉じた」 | 一覧を作ったら、一覧に無いものが無いかを機械で数え直す |
| 「DRC 違反 0」と言いながら `--severity-error` で警告 72 件を隠していた | **警告を隠さない。**除外するなら除外した数を併記する |

## C. 設定しただけで、効いていなかった

| 起きたこと | 規則 |
|---|---|
| 電源のネットクラスを定義したが Recompute を呼ばず 1 本も太くならなかった | 実際に塗られたか・繋がったかまで見る |
| JLC の規則を直したが、DRC は隣の `.kicad_pro` を読んでいて古い規則のまま | 壊して判定が動くことを確かめる |
| ゾーンを「足した」と「塗られた」を取り違えた（2 回） | 同上 |
| autoroute の設定を parser のスコープに書いて黙って無視され、「効かない」と誤った結論 | 設定したら効いたかを数字で見る |
| overlay の `&uart0` を消し忘れ、+0.46mA の下駄を履いたまま 4 時間比べた | 一時的な設定は全ファイルを grep。ビルドの大きさで見分ける |
| 焼いたファームが古いコミット（SPI 200kHz）のまま「4MHz の試験」 | 焼いたものがどのコミットか確かめる |
| 機能がコンパイルされていない治具で「止まらなかった」を見た | それは何も測っていない |

## D. 置き換えたのに古い方が残った（「やり残しは？」に 5 回中 4 回「無い」と答えた）

| 起きたこと | 規則 |
|---|---|
| 底面の電池蓋を廃止したのに `build/battery_lid_*.stl` が残り、slice_check が「刷れます」と言い続けた | **置き換えたら、消した名前でコード・生成物・記録の 3 つを grep する** |
| 部品を替えたのに決定記録・試験手順が古い品番のまま | 同上 |
| 電源部を移した（#41）ので「不成立」の前提が消えたのに、#32 が 5 日間「✅ 不成立」で人を止めた | **決定は前提が動くと期限切れになる。**「構造上できない」なら構造を書く |
| 4 層の決定記録が、実測で 2 層に収まった後も根拠として残った | 同上 |
| 古い `.blend` を利用者が開いた（前日のもの・右は STL が 8 時間前） | 古い絵は嘘の検証。生成物の鮮度に門を置く |

## E. 出力を捨てたまま報告した

| 起きたこと | 規則 |
|---|---|
| `refresh_view.sh >/dev/null 2>&1` で「.blend を出し直した」と報告。実は 1 つも作られていなかった | 出力を読んでから報告する。**`>/dev/null` の成否は言えない** |
| Blender は `-P` のスクリプトが例外で落ちても 0 を返す | 戻り値を信用しない。出来た物を見る |
| `adafruit-nrfutil --singlebank` が「Device programmed.」と言って 8% しか書けていなかった | 成功報告を信用せず読み返す |
| 5 分の取り込みでフレーム 0 を「変化なし」の証拠にした | 道具の沈黙を対象の沈黙と読まない。道具が生きていることを先に見せる |

## F. 決める前に、効く条件を全部見なかった（「ちゃぶ台返し」）

| 起きたこと | 規則 |
|---|---|
| ショットキーを「Basic か」だけで選び、Vf を比べなかった | **効く条件を全部列挙してから候補を並べる** |
| 74HC595 を選び、動作電圧の下限（2.0V）を見なかった。打ち止めは 1.8V | 同上 |
| 74LVC595 に替えたとき影響範囲を「フットプリントと電圧」で止め、その先のマトリクスのダイオードで同じ問題が残った | **影響範囲を信号や力の流れに沿って端から端までたどる** |
| 実験用の部品を本番の品番を決める前に買わせた（2 回） | 買う前に本番の品番を決める |
| 数量 1 の価格を数量 15 に掛けて見積もりを 3 回外した | 数量別の価格を API で取る |
| 在庫 0 のソケットを指定しかけた | 発注直前に API で在庫を見る |
| 電池箱を「単3×2 の箱」とだけ書き、横並び型を買った | **型番で買う。**種類で買わない |
| 出典の無い推定電流 15mA からバルク 100µF を「無いと落ちる」と決めた（実測 10.22mA・不要だった） | 設計値の出典を書く。無ければ測る |
| 電池箱のリード線を「片端からしか出ない」と断定（実際は両端） | **部品の事実はデータシートと製品画像で。**自分のコメントから推論しない |

## G. 見えるものを見なかった

| 起きたこと | 規則 |
|---|---|
| 「視覚的に確認して」と 4 回言われ、毎回言われてから絵を出した | 判断の前に自分でレンダリングして見る（hook で裁量の外に置いた） |
| XIAO を「板の中心にある」と誤認、コートヤードと実体を取り違え | 同上。F.Fab が実体、コートヤードは余裕込み |
| 裏面の部品の極性を頭の中の鏡像変換で行き来した | ネット名をシルクに焼き込んで同じ絵の中で読む |
| .blend に見えた「壁」は厚さ 0.2 の膜で、刷れず、上シェルを無駄に刷らせた | 「ある」と言う前に部品を名指しし厚みを測る。**見える＝刷れるではない** |
| XIAO の 3D モデルを 180° 逆に置き、数値の検査（数・高さ）はすべて通った | 数値検査が見ない自由度は目で捕まえ、形で検査に固める |
| qlmanage の SVG サムネイルは縦横比が壊れ、注釈がずれた | `kicad-cli pcb export pdf` → `pdftoppm` を使う |

## H. 組み立てられない設計が通った

| 起きたこと | 規則 |
|---|---|
| 電池蓋の片持ちばねは「引くと引っ掛かる」検査は通るが、原理的に外れなかった | **留まるかと、入れられるか・外せるかを同じ検査で見る** |
| 電源スイッチを押し込み側のリブで止めたら、そのリブのせいで入らなかった | 挿入経路を宣言して実形状でたどる（最後はケースの外まで） |
| 窪みと座ぐりのように、どちらも外面の造作だと立体は当たらないのに機能が壊れる | **面の取り合いは体積では見えない。**矩形の重なりで別に数える |
| 利用者が操作する電源スイッチを基板の裏に封じ込めていた（DRC 0） | 利用者が触る部品は外から操作できるかを検査する |
| USB 穴の検査に、利用者が挿すケーブルが入っていなかった | 一番外から来る物も検査対象に入れる |
| 「水密」を「箱として閉じている」と取り違えた（コブに天井が無かった） | 覆っているかを直接見る |

## I. 作業の進め方

| 起きたこと | 規則 |
|---|---|
| 別セッションが全部を `git add -A` で拾い、作業途中のファイルが無関係なコミットに紛れた | **触ったファイルだけ名指しで stage。**`git diff --cached` を読む |
| 名指しでも、そのファイルに別セッションが書きかけた呼び出しが混ざり、定義側が入らず main が ImportError | 自分が書いていない行が混ざっていないか読む |
| push は成功して見えて、別セッションが切り替えた別ブランチに乗っていた（2 回） | commit/push の直前に `git status -sb` の 1 行目を**別の呼び出しで**読む |
| 検査の実行中に編集して偽の赤・偽の緑（2 回）。mutate が 6 時間後に並行の編集を上書き | 検査中は検査が読むファイルを編集しない |
| 長い検査の間、何もせず待っていた（1 日に 3 回指摘） | 読み取り専用の監査・外部の裏取り・次の編集の準備を並行する |
| 「自分より前から赤」を「環境の問題・範囲外」で止めた。実際は真の指摘と、直し方が既にある問題だった | 切り分けたあと必ず原因まで降りる。常駐した赤は新しい赤を隠す |
| 理解の確認（「合っている」）を着手の許可と取り違えた | 理解の確認と実行の許可は別 |
| 合意の外の条件を実装側が黙って足した | 合意の外に出るなら、実装せずに測定つきで提示する |
| 自分の探索スクリプトが 0 件を返したのを理由に、利用者の指示を捨てた（3 回） | 利用者の指示は固定し、成立させる方法を探す。疑うのは自分の道具 |
| 新しい経路に乗り換えたあと、赤を「たぶん既知」と流して先へ進んだ | **差分を分類して数える。**合格は「差が意図したものだけ」（差分ゼロではない） |
| 検査を回さず「刷ってよい」と言い、棚の無い上シェルを刷らせた | 印刷を渡すときは「回した検査／回していない検査」を明示し、判断を返す |
| 残作業を列挙して振り分けを利用者に頼んだ | スコープ内ならやる。外なら記録があることを確かめて任せる |

## J. 測り方

| 起きたこと | 規則 |
|---|---|
| 電流計の負担電圧で接続が壊れ、「電源の入れる順で繋がらない」と誤記録 | 測定器が状態を壊す。繋がるのを確かめる段と測る段を分ける |
| 2000µA レンジで 9 倍ずれた。テスターの入力抵抗 1MΩ で分圧を 33% 低く読んだ | レンジと入力抵抗を取説で確かめる |
| 分割を無効にして測り、最大電流を 27% 過小に見積もった | 最悪の動作モードを組み合わせて測る |
| 2 点で引いた線で予測して床を割った | 2 点の当てはめは自由度 0。3 点目まで信じない |
| 日を分けた RSSI の比較 | 同じ日に 1 変数ずつ足す。先に単体のふらつき幅を測って物差しにする |
| 「発注前に測る手段が無い」と書いた（アルミ箔で ¥0 で測れた） | 知りたいのが**差**なら、差を作る物で模擬できる |
| ゴースト試験・逆流・停止の試験で対照が無かった | 対照実験の無い合格は無意味 |

## K. 直せない側に倒した（寸法の非対称）

**規則:** 発注後に直せない寸法（基板）は、直せる側に倒す。きつい・小さい側は後から削る・広げる・撓めることで
直せるが、ゆるい・大きい側は直せない。ゆるい側を選ぶのは、ゆるくても害が無いと示せたときだけ。
後から広げる前提の穴の周りには信号を通さない。

| 起きたこと | 規則 |
|---|---|
| CCKB（2026-09-25〜26）: Choc V2 のねじ留めスタビの穴を、出典 2 つ（販売者が「参考程度」と書く仕入れ先の図・支点 24.0 と、販売者が実物を測った足跡・支点 23.8）の**和**で開けた。ねじの穴は長円 3.2 × 3.4、爪の穴は 4.2 × 4.4。「どちらの実物でも入る」を合格にしていた | 和は「入る」だけを見て、**ゆるさの害**を見ていない。ねじ留めのスタビは、締める前に穴の遊びの分だけ動く（監査 E 重要 3: x ±0.2）。キャップのスタビの受け口の隙は片側 0.05〜0.075 で、ずれは発注後に直せない。しかも長円は JLC の「長さ ≧ 幅 × 2」を満たさず作れなかった（C 重要 1） |
| 直し方: 実物を測った方（足跡）を正にして、**丸 φ3.0（ねじ）・φ4.0（爪）**を支点 ±11.9 に開け、穴の中心から半径 2.6 の中は GND のベタ以外の銅（線・ビア・ほかの網）を置かない。穴がきつければ手でリーマ・やすりで広げられ、広げても信号に当たらない | **きつい側を選んだら、直す手段（広げる余地）まで設計に入れる。**直せない側（ゆるい穴）を選ぶなら、ゆるくても害が無いことを数で示す（例: 床の止まり穴は刷り直せ、大きくても当たらないだけ） |

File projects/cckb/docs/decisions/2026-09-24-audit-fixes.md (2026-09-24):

# 独立監査（A〜F）の所見を発注前に基板・ケース・手順に入れる

- **日付:** 2026-09-24
- **状態:** 決定
- **決めた人:** Claude（利用者の不在中。裁定 R1〜R7 は統括 `.superpowers/sdd/cckb-autonomy/audit-rulings.md`）
- **出典:** 監査の報告 `.superpowers/sdd/cckb-autonomy/audit-A.md`〜`audit-F.md`。所見ごとの行き先は
  同じ場所の `fix-report.md`

## 結論（先に）

| # | 所見 | 決めたこと | 確かめ方 |
|---|---|---|---|
| R1 | C_U1（JLC がリフローで付ける 0805）の GND パッドの**中**に縫いのビア（BT1 にも 1 本） | 根本原因（`route_pcb.Space.free()` が同じネットのパッドを当たり判定から外していた）を直し、同じネットのパッドも縫いのビアの障害物（銅の縁から 0.1）にした。配線・塗りをやり直した | `test_no_via_inside_any_pad`（全部の銅のパッド。例外は XIAO の D0〜D6 の 7 個だけ・名指しで数を固定）。C_U1 のパッドにビアを戻すと落ちる |
| R2 | 電源スイッチのつまみが外形から 1.95 出たまま JLC が実装・CPL の原点が 0.448 ずれる | **(b) 手はんだに回す**（下の §R2）。BOM・CPL から外し、利用者の買い物に足した | Fabrication Toolkit を板の写しに通した CPL を、JLC の部品データ（EasyEDA）の原点とパッドで置き直して板のパッドと比べる `test_jlc_places_every_part_of_the_cpl_on_its_pads`（69 個・回転を 90°/180° 違える・原点を 0.45 ずらすと落ちる） |
| R3 | XIAO の裏の露出パッドは 6 個でなく 8 個。NFC2 の真下に D7 のパッド・GND ビア・GND ベタ | 8 個を公式 STEP と Seeed 公式フットプリントで確定（spec.XIAO_BOTTOM_PADS）。XIAO のパッドを縁から内 2.85 → **2.2**（Seeed 公式のランド 2.18 に揃える）、禁止域を 8 個 ＋ 0.3 まで広げた | `test_the_xiao_bottom_pads_are_the_official_ones`（STEP を毎回数える: 8）・`test_nothing_on_top_under_the_xiao`（8 個を名指し）。板の写しで D7 を前の長さに戻すと NFC2 で落ちる |
| R4 | USB 給電中にスイッチ ON だと、消耗した CR1632 へ B5819W の逆漏れが流れうる | ~~**部品は替えない**（下の §R4: 条件を両方満たす品が JLC に無い）~~ **→ 比べ方が誤っていた。下の §S2 で比べ直し、既定を BAT46W（C54110）に替えた（最後に決めるのは発注前の利用者）**。手順書・説明書に「**USB を挿す前に電源スイッチを OFF**」、台帳の受け入れた差に数字を残した | 候補 8 品番のデータシートの数字（下の表） |
| R5 | 基板とトレイの壁の隙が片側 0.2 | 片側 **0.5**。外面は動かさず壁を 1.6 → 1.3（下の §R5） | `test_cckb_case.py`・`test_cckb_interface.py` |
| R6 | H3 のインサートの縁が表の CS の線・GND ビアに 0.02 掛かる | H3 のまわりに表の銅・ビア・ベタの禁止域（インサートの外径 3.2 ＋ 0.3 → 半径 1.9） | `test_nothing_on_top_under_the_h3_insert`（**→ 2 回目の監査で `test_nothing_under_the_metal_on_the_board` に置き換えた。§S1**。線・ビアの形と、塗った後の銅の面積。対照の円では銅が数えられる）。線を足すと落ちる |
| R7 | 軽微 23 件 | 基板に効くもの（パッド内ビアの輪・サーマル・1 本ビアの島）は一緒に直した。文書は直した。残りは open-gaps に理由つき | fix-report.md の一覧 |

## §R2 電源スイッチ: JLC に実装させるか、手はんだか

### 事実（JLC の公式の資料・2026-09-24 に読んだ）

- **PCB Assembly FAQs (Part 2)** <https://jlcpcb.com/help/article/pcb-assembly-faqs-part-2>:
  "For economic assembly, as boards will be panelised … There will be a tolerance of about 0.2mm when
  routing the boards for depanelizing … We suggest that the edges of the traces and components must be
  more than 0.3mm away from the edge of the board."
- **PCB Assembly Fixtures** <https://jlcpcb.com/help/article/PCB-ASSEMBLY-FIXTURES>: "3. When SMT components
  exceed the PCB — In cases when the SMT components exceed the PCB board, or the component's center of
  gravity is not on the board or edge rail …, the carrier needs to be used."（治具は費用と日数がかかる）
- **Terms and Conditions of JLCPCB Assembly Service** <https://jlcpcb.com/help/article/Terms-and-Conditions-of-JLCPCB-Assembly-Service>
  §2-3: "The distance between the body of the components and the edge of the board must be equal or
  greater than 2.5mm."（Standard。Economic は上の 0.3）
- 部品が外形からはみ出すことを**許す**と書いた JLC の資料は見つからなかった
  （PCBA の能力の表 <https://jlcpcb.com/capabilities/pcb-assembly-capabilities> にも記述が無い）

板の値: つまみの先は外形から 1.95、コートヤードは 2.245 出る（監査 C・E）。

### 決めたこと: (b) 手はんだ

裁定の規則「公式の資料で (a) が確実に通ると言えないなら (b)」に当てはめた。(a)（Economic のまま
Fabrication Toolkit の位置補正で原点を合わせ、はみ出しはエッジレール等で逃がす）は、
上の 3 つがどれも「はみ出す SMT 部品はキャリアが要る／縁から 0.3 以上」と書いていて、確実に通るとは言えない。

- `spec.NOT_ASSEMBLED` に `power_switch` を足した → `foundry.fab_fields` が SW_PWR を BOM・CPL から外す
- 利用者の買い物に **MK-12C02-G025（LCSC C778186）** を足した（1 台 1 個。予備を含めて 3 個を勧める）。**同日に秋月の SS-12D00G3 へ置き換え**（[2026-09-24-power-switch.md](2026-09-24-power-switch.md)）
- 手はんだは裏面の端子 3（0.9×1.8・ピッチ 1.5/3.0）と耳 4。位置決めの突起 φ0.7 が穴 φ0.9 に入るので
  置くだけで位置が決まる。**付ける順: XIAO → スイッチ（プレートを付ける前・基板の裏が上を向いているうち）**
  （printing-and-assembly.md §5）
- 裏のペースト（B_Paste）には SW_PWR のパッドの開口が残る（フットプリントのまま）。JLC がステンシルで
  塗ってリフローすると、付ける前のパッドにはんだが盛られた状態で届く（予備はんだ。手はんだの邪魔にはならない）
- B-1（CPL の原点が EasyEDA と 0.448 ずれる）は、SW_PWR が CPL から外れたので効かなくなった。
  **ほかの 69 個は、監査 B の照合を検査にした**（上の表）

### 捨てた案

| 案 | 捨てた理由 |
|---|---|
| (a) JLC 実装のまま・FT Position Offset で原点を合わせる | 原点は合わせられるが、はみ出しが公式の資料で通ると言えない（キャリアの費用・EQ で止まる・切り離しでつまみを傷める） |
| スイッチを内へ寄せて外形の中に収める | つまみがケースの外面から 2.1 引っ込み、爪が届かない（D9・P4）。境界の凍結（interface §5）も崩す |
| Standard PCBA ＋ エッジレール | 本体と縁 2.5mm の規則にスイッチ本体（縁から 0.55）が反する |

## §R4 USB 給電中の逆漏れ: ダイオードを替えるか

> **⚠ 2026-09-24（2 回目の監査 A2-1・A2-2）: この節の比べ方は誤り。記録として残し、正しい比べ方と結論は下の §S2。**
> 誤り 1: 条件 1 で、B5819W には分圧が電池から吸う電流を差し引いたのに、替える候補には IR そのものに 1µA 未満を求めた。
> 誤り 2: 条件 2 で BAT46W の**最大値**（0.45V @10mA）と B5819W の**典型値**（0.30V @100mA）を比べた。
> 誤り 3: 表の BAT46W の行で CJ（C54110）と Diodes（C83152）の値を 1 行にまとめた。「Tj 60℃ で 5.0µA」は Diodes と Vishay の値で、
> 板に載る CJ のデータシートには高温の保証が無い。

### 効く条件

| # | 条件 | 値 | 何で確かめたか |
|---|---|---|---|
| 1 | 逆漏れ IR（USB 給電中・スイッチ ON・消耗した電池） | VR ≈ 3.3 − 1.9 = **1.4V** で、25℃・40℃ とも**最悪値が 1µA 未満**（Energizer のリチウムコインの逆充電の上限 1µA・設計書 §4） | データシートの**保証値**（典型の曲線は最悪ではない） |
| 2 | 順電圧 Vf（打ち止めを決める。parts.md） | 0.2〜10mA で B5819W と同等以下 | データシート |
| 3 | JLC に在庫・フットプリント | SOD-123 なら板を変えずに差し替え | JLC の API（2026-09-24） |

### 事実（データシート・LCSC で取った PDF）

| 品番（LCSC） | IR の保証値 | 40℃ | Vf の保証値（0.2〜10mA） | 判定 |
|---|---|---|---|---|
| **B5819W**（C8598・いま・CJ） | 1mA @40V だけ。典型の曲線で **25℃・VR 1V で約 5µA** | 無規定（曲線 75℃ で約 60µA） | 無規定。典型の曲線は 100mA で約 0.30V（それより低い電流は描かれていない。10mA ではこれより低い） | 条件 1 を満たさない（だから所見） |
| BAT46W（C54110・CJ／C83152・Diodes） | **0.3µA @1.5V**（25℃） | 5.0µA @1.5V・**Tj 60℃**。40℃ は無規定（25→60℃ の指数で補うと約 1.0µA） | 0.25V @0.1mA・**0.45V @10mA**。典型の曲線は 10mA で約 0.30V | 条件 1 は 40℃ で保証が無い。条件 2 は 10mA で B5819W（100mA で 0.30V）より高い |
| BAT46W（C14099・Vishay） | 0.5µA @1.5V（25℃） | 5µA @1.5V・Tj 60℃ | 0.25V @0.1mA・0.45V @10mA | 同上 |
| BAT42W（C134396・Diodes） | 0.5µA @25V（25℃） | 100µA @25V・Tj 100℃ だけ | **0.40V @10mA** | 条件 1 は 40℃ 無規定、条件 2 が高い |
| BAT43W（C19167・CJ） | 0.5µA @25V（25℃） | 無規定 | 0.26〜**0.33V @2mA**・0.45V @15mA | 条件 2 が高い |
| RB751V40（C553814・Nexperia・SOD-323） | 0.5µA @30V（25℃） | 無規定（曲線は 25/85/125℃） | **0.37V @1mA** | 条件 2 が高い（フットプリントも別） |
| 1N4148W（C81598・シリコン） | 25nA @20V（25℃） | 30µA @25V・Tj 150℃ | **0.715V @1mA**・0.855V @10mA | 条件 2 が大きく高い |
| SD103AW（C8606・CJ） | **5µA** @30V | — | 0.37V @20mA | 条件 1 を満たさない |
| B5817W（C8597・CJ） | 1mA @20V だけ | — | 0.45V @1A | 条件 1 の保証が無い |

PDF（LCSC）: B5819W <https://datasheet.lcsc.com/datasheet/pdf/4ac2c059be7c462694ab0715ce987a85.pdf>・
BAT46W CJ <https://www.lcsc.com/datasheet/lcsc_datasheet_1810251820_Jiangsu-Changjing-Electronics-Technology-Co---Ltd--BAT46W_C54110.pdf>・
BAT46W Vishay <https://datasheet.lcsc.com/datasheet/pdf/86b54bf47f592e7eb6de314e5e61af98.pdf>・
BAT46W Diodes <https://datasheet.lcsc.com/datasheet/pdf/18e08184e5865113cc055d7c9a1d2463.pdf>・
BAT42W Diodes <https://datasheet.lcsc.com/datasheet/pdf/d305a62001dc43cfab8d44301c23edf4.pdf>・
BAT43W CJ <https://datasheet.lcsc.com/datasheet/pdf/76a3e055d6ed4991b21fa0ca43348979.pdf>・
RB751V40 Nexperia <https://datasheet.lcsc.com/datasheet/pdf/bd6d964dba1c632c4e076399f160c3d8.pdf>・
1N4148W <https://datasheet.lcsc.com/datasheet/pdf/8abd7fc00ebe41ffb03ad1383c10753b.pdf>・
SD103AW <https://datasheet.lcsc.com/datasheet/pdf/76bb472f2a624330a45712fcd6688552.pdf>・
B5817W <https://datasheet.lcsc.com/datasheet/pdf/3b3f32cf2655436c8aa5147f96bd7261.pdf>。
HHKB の比較（foundry/parts.py の diode の欄: SOD-123 のショットキー 29 件と BAT/1SS/NSR/RB751/PMEG/MBR/SS/1N5711/BAS40 の系列）
でも「低い逆電圧の IR と低電流の Vf の両方を保証するのは BAT46W だけ」で、その BAT46W も上の通り
40℃ の IR と 10mA の Vf で条件を満たさない。

**なぜ両立しないか**: ショットキーの逆漏れと順電圧は障壁の高さと接合の面積で引き換えになる
（漏れが小さい品は、同じ電流で Vf が高い）。1A 級の B5819W は面積が大きく、mA 級では Vf が低いが漏れが大きい。

### 決めたこと: 部品は替えない。手順で避ける

裁定の規則「IR が最悪でも 1µA 未満で、Vf が B5819W と同等以下の品が無ければ、部品は替えず、
手順書・説明書に『USB を挿す前に電源スイッチを OFF』を太字で書き、台帳に受け入れた差として残す」。

- スイッチは電池と回路の間にある（VBAT_IN は BT1.＋ と SW_PWR.② の 2 パッドだけ・監査 A が板で確認）。
  **OFF なら電池は完全に切り離され、逆漏れの経路が無い**
- 書いた所: `docs/printing-and-assembly.md` §5・§6（使い方）、`docs/task-10a-coin-cell-startup.md`（USB の対照実験の前に OFF・
  「USB を挿してスイッチ ON で電池に流れる電流の向きと大きさ」を 1 項目足した）、open-gaps の受け入れた差 A1
- 数字（台帳に残す）: 逆電圧 1.4V・B5819W の典型 約 5µA（25℃）・分圧が電池から取る 1.2µA を引いて
  25℃ で約 +1〜4µA が電池へ。上限 1µA。温度が上がると 1 桁増える

## §R5 基板とトレイの壁の隙

- JLC の外形公差 ±0.2（<https://jlcpcb.com/capabilities/pcb-capabilities>）と PLA の縮み 0.2〜0.3% を足すと、
  片側 0.2 の隙は奥行き（96.25 の内側に 95.85＋0.2）で 0 以下になりうる（監査 E 重要 2）
- **境界の値は 1 か所**: `spec.CASE_PCB_GAP = 0.5` を `interface.wall_inner`（= 基板の外形 ＋ CASE_PCB_GAP）
  だけが読み、`case.r_in`（壁の内面の角の丸み = 基板の角 R ＋ 隙）は interface から導く
- **外面は動かさない**（外面 = 基板 ＋ 0.5 ＋ 壁 1.3 = キー領域 ＋ 2.1 で、前の キー領域 ＋ 0.5 ＋ 1.6 と同じ）: 外面が動くと USB の口の
  引っ込み（0.3 → 0.6・上限 0.6）とつまみの先（外面 ＋0.15 → −0.15）が変わる。壁を 1.6 → **1.3**（0.4 ノズル 3 周・
  肉厚の下限 1.2 の内側）にして内面だけを 0.3 外へ
- 指の窪み（当時の定数。2026-09-24 の電源スイッチの置き換えで窪みごと無くなった）を 1.0 → **0.9**: 壁 1.3 − 1.0 では窪みの奥の壁が 0.3（線 1 本に満たない）。0.9 なら 0.4、
  つまみの先は窪みの底から 1.05（`PSW_NAIL_REACH` 1.0 以上）
- 付いてくる改善: XIAO の USB 側の端と壁の内面の隙 0.23 → 0.53（監査 E 軽微 1）。上から見えるキャップと壁の隙は
  1.025 → 1.325（HHKB 実機の実測 1.0〜1.5 の中）

## 2 回目の監査の直し（S1〜S3・2026-09-24）

裁定は統括 `.superpowers/sdd/cckb-autonomy/audit2-rulings.md`。報告は同じ場所の `audit2-A.md`〜`audit2-E.md`、
所見ごとの行き先は `fix2-report.md`。

### §S1 基板に金属が当たる所の下に銅を置かない（全部の取付を数で）

- **何が起きたか**: 1 回目の R6 は H3 のインサートだけに禁止域を置いた。配線し直したら CS の表の線が H5・H6 の
  **鋼の六角ナットの真下**（中心から 1.603。ナットの角は 2.31）を通った（監査 E 2 回目 重要 1）。ほかの 9 か所を
  見る検査が無かった
- **母数**: 取付の穴は板に 11（H0〜H9・H_LID）。`interface.metal_on_pcb()` が穴ごとに金属（ナット・インサート・
  ネジの頭・上からのネジ）を並べ、**高さで**どの面に当たるかを決める（組み立てモデルと同じ積み上げ。
  `tests/test_cckb_case.py` がモデルの金属の立体と突き合わせる）:

  | 取付 | 金属 | 当たる面 | 当たる円（半径） |
  |---|---|---|---|
  | H0〜H2・H4〜H9（9） | M2 六角ナット（z 5.0〜6.6） | **上面** | 2.425 = max(ナットの外接 2.309 ＋ 穴の遊び 0.1, プレートの六角の穴の外接 2.425) |
  | H3 | 左のふたの熱圧入インサート（z 5.0〜8.0） | **上面** | 1.6（外径 3.2） |
  | H0〜H9 | 下からの皿ネジの頭（z 0.9〜2.1。床 1.2 の後は 0.5〜1.7・基板の下面 3.0） | 当たらない（基板の下面 3.4 との間はトレイの樹脂のボス） | — |
  | H_LID | 柱のインサート（z 5.8〜8.8）・上からのネジ（z 6.0〜12.0） | 当たらない（樹脂の柱が穴 φ6.0 を通り、金属は基板より上） | — |

  ネジの軸は非めっきの穴の中を通るだけ（穴と銅の間は DRC の規則）。**下面に当たる金属は 0**
- **直したこと**: 当たる円 ＋ `spec.METAL_COPPER_CLEAR`（0.3。前の `INSERT_COPPER_CLEAR` を改名）の禁止域
  `METAL_KEEPOUT`（当たる側の層・線/ビア/ベタ禁止）を 10 か所に（pcb_extra）。ナットは半径 2.725、H3 は 1.9（前と同じ）
- **配線は CS だけを直した**（`route_pcb.py --reroute CS`）: 前の板の線・ビアを GND 以外そのまま持ってきて、CS のうち
  禁止域に掛かる 1 本（F.Cu y −42.633・x −37.463〜54.064）だけを外し、欠けた所を Freerouting に繋がせた。
  **CS を丸ごと外して引かせると 1 本繋がらなかった**（余裕 30/35µm で未配線 1）。まっさらから全部を引き直すと
  余裕 30/35 で未配線 3/2 で、しかも Freerouting の網を全部動かす（監査の済んだ配線を捨てる）ので採らなかった。
  変わった網の数え方と結果は下の「S1 の結果」。**Freerouting は回していない**: 外した 1 本は `route_pcb.detours` が
  決まった形（円から離れる側へ平行にずらし、両端を元の端へ 45° で戻す）で置き直した。禁止域を 1〜2 個にした DSN では
  Freerouting 自身がこれと同じ 3 本（y −43.99）で繋いだ——禁止域 10 個の DSN では繋がらなかった
- **S1 の結果**（前の板 f95a7c9 と網ごとに線・ビアの集合を比べた）: 91 網のうち **89 網は線もビアも同じ**。
  **CS**: 線 1 本（F.Cu y −42.633・x −37.463〜54.064）→ 3 本（(−37.463, −42.633)→(−36.063, −44.033)→(52.664, −44.033)→
  (54.064, −42.633)）。ビアは同じ。H5・H6 の中心から線の縁まで 2.9（禁止域 2.725 の外）。**GND**: スタブ 9 本は同じ
  （1µm 未満の丸めの差）、縫いのビア 999 → 1003（34 消えて 38 増えた: ナットのまわり 11・CS の脇のフェンスが y −45 から
  −44.7/−46 へ 7→23 ほか）。DRC 違反 0・未配線 0・警告 5（silk_edge_clearance 3・npth_inside_courtyard 2。前と同じ）
- **検査**: `test_every_mount_hole_is_judged_and_the_metal_touches_only_the_top`（母数 11・当たる 10）、
  `test_nothing_under_the_metal_on_the_board`（10 か所それぞれの円の中の当たる側の線・ビア・塗った後の銅が 0。
  対照の円〔D7 のパッドの上〕では銅が数えられる）、`test_the_metal_check_notices_a_track_under_a_nut`（H5・H6・H0 に
  監査で見つかった形の CS を足すと落ちる）・`…_a_missing_hole_judgement`（判定の無い穴を足すと落ちる）。
  **直す前の板（HEAD f95a7c9）に同じ検査を当てると H5・H6 の CS を出す**（fix2-report.md に出力）

### §S2 USB 給電中の逆流: 正しい物差しで比べ直す

**物差し**: 電池に入る正味の電流 ＝ ショットキーの逆漏れ IR（VR・温度）− 分圧が電池から吸う電流。
スイッチ ON・USB あり: カソードは XIAO の 3V3（3.3V）、アノードは VBAT_SW ＝ 電池。逆電圧 VR ＝ 3.3 − Vbat ＝ 0.1〜1.4V
（Vbat 1.9〜3.2V）。IR は VR とともに増えるので（どのデータシートの曲線も単調）、**VR 1.5V の保証値は 1.4V 以下の上限になる**。
分圧は 1MΩ＋1MΩ（1%）で、吸う電流は少なくとも Vbat / 2.04MΩ ＝ **0.93µA（1.9V）〜1.57µA（3.2V）**。
逆漏れがこれより小さければ、電池は充電されず分圧へ放電する。上限は Energizer CR1632 の「Max Rev Charge: 1 microampere」
（<https://data.energizer.com/pdfs/cr1632.pdf>・2026-09-24 に取り直して読んだ）。

**Vf は同じ種類の値どうしで**（0.2〜10mA は XIAO の平均〜送信の山の電流）。順電圧は電流とともに増えるので、ある電流の
保証値はそれより低い電流の上限にもなる。

| | B5819W（C8598・CJ・いま） | BAT46W（**C54110・CJ**・キーと同じ品） | BAT46W（C83152・Diodes） |
|---|---|---|---|
| IR の保証値（VR ≦ 1.5V に効くもの） | **1mA @40V だけ**（25℃）→ 上限として意味が無い | **0.3µA @1.5V**（25℃）。高温は**無規定** | 0.3µA @1.5V（25℃）・**5.0µA @1.5V・Tj 60℃** |
| 電池に入る正味（保証値・25℃） | 保証から言えない（上限 約 +1000µA） | **0**（0.3 − 0.93 < 0） | **0** |
| 電池に入る正味（保証値・60℃） | 言えない | 言えない | ≦ +4.1µA（1.9V）・+3.4µA（3.2V）→ 上限 1µA を越えうる |
| 同（典型の曲線・25℃・VR 1V） | IR 約 5µA → **約 +3.4〜+4.1µA** | IR 約 0.2〜0.3µA → 0 | （曲線を読んでいない） |
| Vf の保証値（0.2〜10mA） | **≦ 0.6V**（1A の値だけ。低い電流の保証は無い） | **≦ 0.45V**（@10mA）・≦ 0.25V（@0.1mA） | 同左 |
| Vf の典型（25℃・0.2 / 1 / 10mA） | **描かれていない**（曲線は 100mA の 約 0.31V から） | 約 0.19 / 0.255 / 0.31V（CJ の曲線を 200dpi で描いて読んだ） | — |
| 打ち止め 2.4V（overlay の仮の値）でのレールの保証 | 2.4 − 0.6 = 1.8V | 2.4 − 0.45 = **1.95V** | 同左 |
| JLC（`foundry.jlcpcb_lookup`・2026-09-24） | Basic・在庫 471,222・$0.028 | Extended（キー 62 個で手数料は払い済み）・在庫 45,945・$0.0292 | Extended・在庫 108,765・$0.1037 |

出典（2026-09-24 に LCSC から取り直して pdftotext と描いた曲線で読んだ）: B5819W CJ
<https://datasheet.lcsc.com/datasheet/pdf/4ac2c059be7c462694ab0715ce987a85.pdf>・BAT46W CJ（C54110）
<https://datasheet.lcsc.com/datasheet/pdf/f97c8b3ccdb24c5ba21cb2c31ad9c922.pdf>・BAT46W Diodes（C83152）
<https://datasheet.lcsc.com/datasheet/pdf/18e08184e5865113cc055d7c9a1d2463.pdf>・BAT46W Vishay（参考・同じ保証値の 0.5µA 版）
<https://datasheet.lcsc.com/datasheet/pdf/86b54bf47f592e7eb6de314e5e61af98.pdf>。

**読み方**: 保証値で言えるのは「BAT46W なら 25℃ で電池に入らない」まで。B5819W は保証から何も言えず、典型でも
25℃ で上限の 3〜4 倍。40℃ 以上はどちらも保証が無い（Diodes の 60℃ の保証値では BAT46W も上限を越えうる）。
Vf は保証値どうしなら BAT46W の方が低い（≦0.45 と ≦0.6）。典型どうしは B5819W の低い電流の値が無いので比べられない
（1 回目の監査 A2 の見積もり「10mA で約 0.24V、差 60〜80mV」は曲線の外挿で、測った値ではない）。

**既定（利用者が決めるまで）: BAT46W C54110**（裁定の「安全側 ＝ 正味の逆流が保証値で 1µA 未満になる方」）。
板は変わらない（D_PWR は同じ D_SOD-123）。`spec.PARTS["schottky"]` の品番 1 行と、pcb_extra の D_PWR の値の名前だけ。
BOM はキーと同じ行にまとまり 5 → 4 行。

**利用者が発注前に決めること**（`.superpowers/sdd/cckb-autonomy/progress.md`「利用者に確認したいこと」・open-gaps O12）:
BAT46W（逆流を保証値で 0 にする・Vf の保証値も低い）か、B5819W（Basic・Vf の典型は低いかもしれないが保証が無い・
25℃ でも典型で電池へ数 µA）か。どちらでも「USB を挿す前に電源スイッチを OFF」の規則は残す（40℃ 以上では BAT46W でも保証が無い）。
~~**起動の余裕はダイオードで変わりうるので、task-10a を両方のダイオードで測る**（手順書に書いた）。~~
**← 2026-09-25 に置き換えた**: task-10a はダイオードを使わず、可変電源で XIAO の起動に要る電圧を測り、ダイオードは
Vf の保証値（BAT46W ≦0.45V@10mA）で紙の上に載せる。O12 は同日 BAT46W で決まった（open-gaps O12）。

### §S3 軽微 13 件

行き先は `fix2-report.md` の一覧。基板に効いたもの: SW_PWR などの手はんだの部品のパッドからペーストの層を外した（B2-1・C1。
B.Paste の開口 173 → 166）、XIAO のパッド内ビアの輪 φ0.7 → φ0.8（C2。アニュラ 0.25 ＝ JLC の推奨）。
XIAO の裏の USB のシールドのめっきの長穴 4 個を `spec.XIAO_BOTTOM_SLOTS` として数え、検査で名指し（D4）。**〔訂正・3 回目の監査 軽微 2〕「禁止域の形は変わらない」は誤り**: XIAO_UNDERSIDE は 3 → 5 個になり、USB の端の長穴 2 個＋0.3 の矩形（x 6.819〜9.198）が XIAO の端 6.855 から 0.036 はみ出す（面積 +0.107mm²）。はみ出しは基板の縁と EDGE_KEEPOUT の中で、表の銅は変わらない（3 回目の監査が塗った後のベタで確かめた）。

## この決定が乗っている前提（動いたら読み直す）

- R2: JLC の公式の資料が「はみ出す SMT 部品はキャリア」「Economic は縁から 0.3」と書いていること。
  JLC がはみ出しを許すと明記したら、(a) に戻して BOM/CPL に戻せる（CPL の原点は FT Position Offset で 0.448）。
  **→ 電源スイッチの置き換え（decisions/2026-09-24-power-switch.md）で読み直し済み**: いまの SS-12D00G3 はスルーホールで
  LCSC に無い（秋月で買う）ので、JLC の実装に戻す道はもう無い
- S1: 基板に当たる金属がナット 9・インサート 1 で、下面に当たる金属が無いこと（ネジの頭がトレイに沈み、基板の下がトレイの
  樹脂のボスであること）。**座金を足す・ネジを上からに変える・ナットを基板の下に回す、なら `interface.metal_on_pcb` と禁止域を読み直す**
- S2: 分圧が 1MΩ＋1MΩ でスイッチの後ろ・ダイオードの前にあること（分圧を大きくすると吸う電流が減り、正味が電池へ向く）
- R4: 電池が CR1632（リチウム一次）であること。CR2032 に替えても同じ（上限 1µA は同じ系列）。
  **電池を充電式にする・理想ダイオードの IC に替える、なら読み直す**
- R5: 基板の外形 ±143.175 × ±47.925（spec.PLATE_MARGIN・CORNER_R）が変わらないこと

## まだ決めていないこと

| 項目 | 決められない理由 |
|---|---|
| A-4（595 の末端 QH' を D9 に戻して数珠つなぎを自分で検査する） | 回路の足し算で、利用者との合意の外。**発注前にしか足せない**ので open-gaps O11 で利用者に聞く |

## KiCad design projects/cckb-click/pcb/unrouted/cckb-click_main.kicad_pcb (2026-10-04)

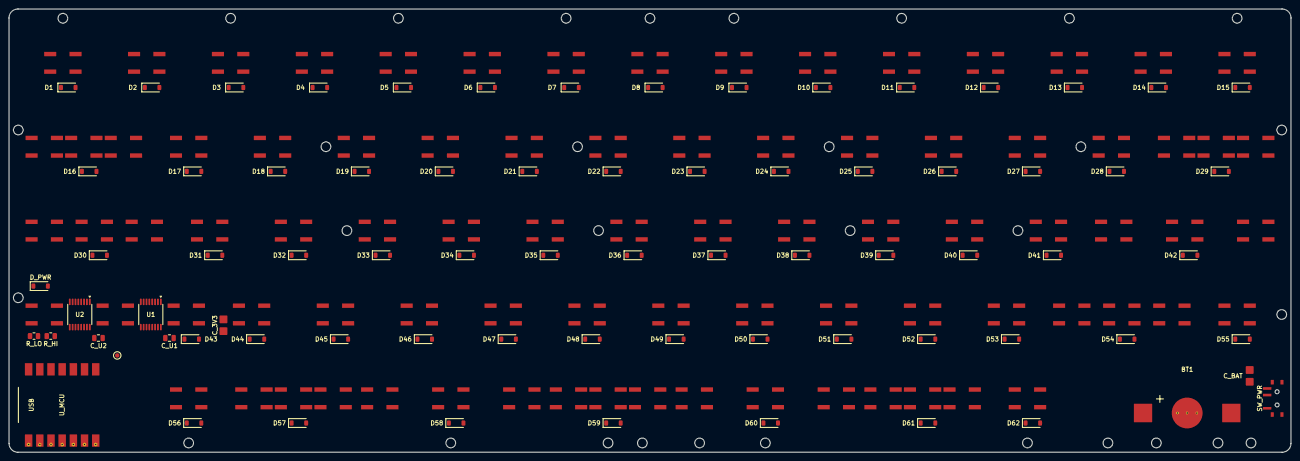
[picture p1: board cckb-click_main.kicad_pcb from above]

Board: 2 copper layers, 291.2 x 100.7 mm, 191 parts (0 on the bottom side), 91 nets, no tracks yet.

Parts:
BT1: MY-1632-03-R; BAT_MY-1632-03-R
C_3V3: cap_land_unpopulated; C_1206_0805_Land
C_BAT: cap_land_unpopulated; C_1206_0805_Land
C_U1, C_U2: 0.1uF; C_0805_2012Metric
D1, D2, D3, D4, D5, D6, D7, D8, D9, D10, D11, D12, D13, D14, D15, D16, D17, D18, D19, D20, D21, D22, D23, D24, D25, D26, D27, D28, D29, D30, D31, D32, D33, D34, D35, D36, D37, D38, D39, D40, D41, D42, D43, D44, D45, D46, D47, D48, D49, D50, D51, D52, D53, D54, D55, D56, D57, D58, D59, D60, D61, D62: BAT46W; D_SOD-123
D_PWR: BAT46W; D_SOD-123
H0, H1, H2, H3, H4, H5, H6, H7, H8, H9, H10, H11, H12, H13, H14, H15, H16, H17, H18, H19, H20, H21, H22, H23, H24, H25, H26, H27, H28, H29, H30, H31: Hole_M2_2.2
R_HI: 1M; R_0805_2012Metric
R_LO: 1M; R_0805_2012Metric
SW1, SW2, SW3, SW4, SW5, SW6, SW7, SW8, SW9, SW10, SW11, SW12, SW13, SW14, SW15, SW16, SW17, SW18, SW19, SW20, SW21, SW22, SW23, SW24, SW25, SW26, SW27, SW28, SW29, SW30, SW31, SW32, SW33, SW34, SW35, SW36, SW37, SW38, SW39, SW40, SW41, SW42, SW43, SW44, SW45, SW46, SW47, SW48, SW49, SW50, SW51, SW52, SW53, SW54, SW55, SW56, SW57, SW58, SW59, SW60, SW61, SW62: SKRAAWE010; SW_Alps_SKRA_6.2x6.2
SWA16, SWA29, SWA30, SWA42, SWA43, SWA54, SWA57, SWA58, SWA59, SWA60, SWA61: SKRA_side_land_unpopulated; SW_Alps_SKRA_6.2x6.2
SWB16, SWB29, SWB30, SWB42, SWB43, SWB54, SWB57, SWB58, SWB59, SWB60, SWB61: SKRA_side_land_unpopulated; SW_Alps_SKRA_6.2x6.2
SW_PWR: MSK12C02; SW_MSK12C02
TP_VSW: TP_VBAT_SW; TestPoint_Pad_D1.0mm
U1, U2: SN74LVC595APWR; TSSOP-16_4.4x5mm_P0.65mm
U_MCU: XIAO_nRF52840; XIAO_nRF52840_SMD

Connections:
COL0: SW1.1, SW16.1, SW30.1, SWA16.1, SWA30.1, SWB16.1, SWB30.1, U1.15
COL1: SW2.1, SW17.1, SW43.1, SW56.1, SWA43.1, SWB43.1, U1.1
COL2: SW3.1, SW31.1, SW44.1, U1.2
COL3: SW4.1, SW18.1, SW32.1, SW45.1, SW57.1, SWA57.1, SWB57.1, U1.3
COL4: SW5.1, SW19.1, SW33.1, SW46.1, U1.4
COL5: SW6.1, SW20.1, SW34.1, SW47.1, SW58.1, SWA58.1, SWB58.1, U1.5
COL6: SW7.1, SW21.1, SW35.1, SW48.1, SW59.1, SWA59.1, SWB59.1, U1.6
COL7: SW8.1, SW22.1, SW36.1, SW49.1, U1.7
COL8: SW9.1, SW23.1, SW37.1, SW50.1, SW60.1, SWA60.1, SWB60.1, U2.15
COL9: SW10.1, SW24.1, SW38.1, SW51.1, U2.1
COL10: SW11.1, SW25.1, SW39.1, SW52.1, SW61.1, SWA61.1, SWB61.1, U2.2
COL11: SW12.1, SW26.1, SW40.1, SW53.1, U2.3
COL12: SW13.1, SW27.1, SW41.1, SW62.1, U2.4
COL13: SW14.1, SW28.1, SW42.1, SW54.1, SWA42.1, SWA54.1, SWB42.1, SWB54.1, U2.5
COL14: SW15.1, SW29.1, SW55.1, SWA29.1, SWB29.1, U2.6
CS: U1.12, U2.12, U_MCU.D7
GND: BT1.2, C_3V3.2, C_BAT.2, C_U1.2, C_U2.2, R_LO.2, SW_PWR.4, U1.8, U1.13, U2.8, U2.13, U_MCU.GND
ROW0: D1.1, D2.1, D3.1, D4.1, D5.1, D6.1, D7.1, D8.1, D9.1, D10.1, D11.1, D12.1, D13.1, D14.1, D15.1, U_MCU.D2
ROW1: D16.1, D17.1, D18.1, D19.1, D20.1, D21.1, D22.1, D23.1, D24.1, D25.1, D26.1, D27.1, D28.1, D29.1, U_MCU.D3
ROW2: D30.1, D31.1, D32.1, D33.1, D34.1, D35.1, D36.1, D37.1, D38.1, D39.1, D40.1, D41.1, D42.1, U_MCU.D4
ROW3: D43.1, D44.1, D45.1, D46.1, D47.1, D48.1, D49.1, D50.1, D51.1, D52.1, D53.1, D54.1, D55.1, U_MCU.D5
ROW4: D56.1, D57.1, D58.1, D59.1, D60.1, D61.1, D62.1, U_MCU.D6
SPI_MOSI: U1.14, U_MCU.D10
SPI_SCK: U1.11, U2.11, U_MCU.D8
SW1_D: D1.2, SW1.2
SW2_D: D2.2, SW2.2
SW3_D: D3.2, SW3.2
SW4_D: D4.2, SW4.2
SW5_D: D5.2, SW5.2
SW6_D: D6.2, SW6.2
SW7_D: D7.2, SW7.2
SW8_D: D8.2, SW8.2
SW9_D: D9.2, SW9.2
SW10_D: D10.2, SW10.2
SW11_D: D11.2, SW11.2
SW12_D: D12.2, SW12.2
SW13_D: D13.2, SW13.2
SW14_D: D14.2, SW14.2
SW15_D: D15.2, SW15.2
SW16_D: D16.2, SW16.2, SWA16.2, SWB16.2
SW17_D: D17.2, SW17.2
SW18_D: D18.2, SW18.2
SW19_D: D19.2, SW19.2
SW20_D: D20.2, SW20.2
SW21_D: D21.2, SW21.2
SW22_D: D22.2, SW22.2
SW23_D: D23.2, SW23.2
SW24_D: D24.2, SW24.2
SW25_D: D25.2, SW25.2
SW26_D: D26.2, SW26.2
SW27_D: D27.2, SW27.2
SW28_D: D28.2, SW28.2
SW29_D: D29.2, SW29.2, SWA29.2, SWB29.2
SW30_D: D30.2, SW30.2, SWA30.2, SWB30.2
SW31_D: D31.2, SW31.2
SW32_D: D32.2, SW32.2
SW33_D: D33.2, SW33.2
SW34_D: D34.2, SW34.2
SW35_D: D35.2, SW35.2
SW36_D: D36.2, SW36.2
SW37_D: D37.2, SW37.2
SW38_D: D38.2, SW38.2
SW39_D: D39.2, SW39.2
SW40_D: D40.2, SW40.2
SW41_D: D41.2, SW41.2
SW42_D: D42.2, SW42.2, SWA42.2, SWB42.2
SW43_D: D43.2, SW43.2, SWA43.2, SWB43.2
SW44_D: D44.2, SW44.2
SW45_D: D45.2, SW45.2
SW46_D: D46.2, SW46.2
SW47_D: D47.2, SW47.2
SW48_D: D48.2, SW48.2
SW49_D: D49.2, SW49.2
SW50_D: D50.2, SW50.2
SW51_D: D51.2, SW51.2
SW52_D: D52.2, SW52.2
SW53_D: D53.2, SW53.2
SW54_D: D54.2, SW54.2, SWA54.2, SWB54.2
SW55_D: D55.2, SW55.2
SW56_D: D56.2, SW56.2
SW57_D: D57.2, SW57.2, SWA57.2, SWB57.2
SW58_D: D58.2, SW58.2, SWA58.2, SWB58.2
SW59_D: D59.2, SW59.2, SWA59.2, SWB59.2
SW60_D: D60.2, SW60.2, SWA60.2, SWB60.2
SW61_D: D61.2, SW61.2, SWA61.2, SWB61.2
SW62_D: D62.2, SW62.2
U1_U2: U1.9, U2.14
V3V3: C_3V3.1, C_U1.1, C_U2.1, D_PWR.1, U1.10, U1.16, U2.10, U2.16, U_MCU.3V3
VBAT_IN: BT1.1, SW_PWR.2
VBAT_SENSE: R_HI.2, R_LO.1, U_MCU.D0
VBAT_SW: C_BAT.1, D_PWR.2, R_HI.1, SW_PWR.3, TP_VSW.1

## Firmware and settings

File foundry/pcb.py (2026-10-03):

"""キーマトリクスの基板（未配線）を生成する。**KiCad 同梱の Python で動かす。**

    "$KICAD_PYTHON" -m foundry.pcb <機種>        # tools/kb <機種> pcb でも同じ

出すもの（projects/<機種>/pcb/unrouted/<機種>_<部品>.kicad_pcb）:
  外形（プレート外形 − PCB_INSET）・キーごとのホットスワップソケット／ダイオード
  （裏面）／スタビ・行列のネット・取付穴・JLCPCB の規則とネットクラス・
  裏面シルクのキー名と部品名

出さないもの（機種ごとに違う）: MCU・電源・コネクタ・GND ベタ・配線。
MCU などは projects/<機種>/pcb_extra.py の `place(board, ctx)` で足す。
配線と GND ビアの作法は docs/knowledge/pcb.md（HHKB の finalize_pcb / gnd_fanout が参照実装）。

**このファイルは寸法を持たない。**寸法は spec.py と mech.py、配列は layout、
行列は matrix が唯一の出どころ（HHKB でネジ位置を二重に持って食い違わせた）。
"""

import importlib.util
import math
import sys
from pathlib import Path

import pcbnew

sys.path.insert(0, str(Path(__file__).resolve().parent.parent))
from foundry import paths, pinmap                                  # noqa: E402
from foundry.layout import centered                                # noqa: E402
from foundry.mech import stab_flipped, switch_of                   # noqa: E402
from foundry.pcb_rules import (JLC, NPTH_EDGE_MIN, TRACK_W,        # noqa: E402
                               VIA_D, VIA_DRILL, sync_project_rules)
from foundry.project import load                                   # noqa: E402

# 基板の中心を置く KiCad 上の座標（mm）。0,0 だと座標が負になり GUI で扱いにくい
ORIGIN = (150.0, 100.0)
KEYSWITCH_LIB = paths.LIB / "keyswitch.pretty"
MOUNT_FP = ("MountingHole", "MountingHole_2.2mm_M2")    # M2 のバカ穴
DIODE_FP = ("Diode_SMD", "D_SOD-123")


def to_kicad(x, y):
    """CAD 座標（原点中心・Y 上向き・mm）→ KiCad（Y 下向き）。変換はここだけ。"""
    return pcbnew.VECTOR2I_MM(ORIGIN[0] + x, ORIGIN[1] - y)


def _load(lib_dir, name):
    fp = pcbnew.FootprintLoad(str(lib_dir), name)
    if fp is None:                    # 握り潰さない
        raise RuntimeError(f"フットプリントを読めない: {lib_dir} / {name}")
    return fp


def _outline(board, w, h, r):
    """角丸矩形を Edge.Cuts に引く（プレートと同じ角丸）。"""
    hw, hh = w / 2, h / 2
    for (x1, y1), (x2, y2) in (((-hw + r, -hh), (hw - r, -hh)), ((hw, -hh + r), (hw, hh - r)),
                               ((hw - r, hh), (-hw + r, hh)), ((-hw, hh - r), (-hw, -hh + r))):
        seg = pcbnew.PCB_SHAPE(board, pcbnew.SHAPE_T_SEGMENT)
        seg.SetStart(to_kicad(x1, y1))
        seg.SetEnd(to_kicad(x2, y2))
        seg.SetLayer(pcbnew.Edge_Cuts)
        seg.SetWidth(pcbnew.FromMM(0.1))
        board.Add(seg)
    corners = [(-hw + r, -hh + r), (hw - r, -hh + r), (hw - r, hh - r), (-hw + r, hh - r)]
    for i, (cx, cy) in enumerate(corners):
        a0 = [180, 270, 0, 90][i]
        pts = [(cx + r * math.cos(math.radians(t)), cy + r * math.sin(math.radians(t)))
               for t in (a0, a0 + 45, a0 + 90)]
        arc = pcbnew.PCB_SHAPE(board, pcbnew.SHAPE_T_ARC)
        arc.SetArcGeometry(*(to_kicad(*p) for p in pts))
        arc.SetLayer(pcbnew.Edge_Cuts)
        arc.SetWidth(pcbnew.FromMM(0.1))
        board.Add(arc)


def _apply_rules(board):
    d = board.GetDesignSettings()
    mm = pcbnew.FromMM
    d.m_TrackMinWidth = mm(JLC["track_min"])
    d.m_MinClearance = mm(JLC["clearance_min"])
    d.m_ViasMinSize = mm(JLC["via_dia_min"])
    d.m_ViasMinDrill = mm(JLC["via_drill_min"])
    d.m_MinThroughDrill = mm(JLC["hole_min"])
    d.m_HoleToHoleMin = mm(JLC["hole_to_hole"])
    d.m_CopperEdgeClearance = mm(JLC["edge_clearance"])
    d.m_SilkClearance = mm(JLC["silk_width"])
    d.m_ViasMinAnnularWidth = mm(JLC["annular_ring"])
    # 自動配線器はネットクラスしか見ない。最小値とは別に実際の寸法を明示する
    nc = d.m_NetSettings.GetDefaultNetclass()
    nc.SetTrackWidth(mm(TRACK_W))
    nc.SetClearance(mm(TRACK_W))
    nc.SetViaDiameter(mm(VIA_D))
    nc.SetViaDrill(mm(VIA_DRILL))


def npth_too_close_to_edge(board, w, h):
    """穴（NPTH）の縁から外形（矩形）までが NPTH_EDGE_MIN 未満のもの。

    DRC は銅しか見ず、配置の検査は部品の中心しか見なかったので、HHKB では
    スペースのスタビの大穴が基板前縁まで 0.381mm のまま発注直前まで残った（#53）。
    """
    bad = []
    for fp in board.GetFootprints():
        for pad in fp.Pads():
            if pad.GetAttribute() != pcbnew.PAD_ATTRIB_NPTH:
                continue
            q = pad.GetPosition()
            x, y = pcbnew.ToMM(q.x) - ORIGIN[0], pcbnew.ToMM(q.y) - ORIGIN[1]
            gap = min(w / 2 - abs(x), h / 2 - abs(y)) - pcbnew.ToMM(pad.GetDrillSize().x) / 2
            if gap < NPTH_EDGE_MIN - 1e-6:        # ちょうど下限の穴を、浮動小数の丸め（1e-13）で落とさない
                bad.append(f"{fp.GetReference()} の穴 φ{pcbnew.ToMM(pad.GetDrillSize().x):.3f}"
                           f" が外形まで {gap:.3f}mm")
    return bad


def _extra(project):
    """projects/<機種>/pcb_extra.py があれば読む（MCU などを置く）。"""
    f = project.root / "pcb_extra.py"
    if not f.exists():
        return None
    s = importlib.util.spec_from_file_location(f"pcb_extra_{project.root.name}", f)
    m = importlib.util.module_from_spec(s)
    s.loader.exec_module(m)
    return m


def build(project, piece):
    spec = project.spec
    keys, rc = project.matrix(piece)          # キーマップ順（行列とファームが同じ並び）
    positions, (kw, kh) = centered(keys)
    pcb_w = kw + 2 * (spec.PLATE_MARGIN_X - spec.PCB_INSET_X)
    pcb_h = kh + 2 * (spec.PLATE_MARGIN_Y - spec.PCB_INSET_Y)

    board = pcbnew.CreateEmptyBoard()
    board.SetCopperLayerCount(2)              # 2 層で足りた（HHKB。4 層の根拠は実測で消えた）
    _apply_rules(board)
    _outline(board, pcb_w, pcb_h, spec.CORNER_R)

    nets = {}

    def net(name):
        if name not in nets:
            nets[name] = pcbnew.NETINFO_ITEM(board, name)
            board.Add(nets[name])
        return nets[name]

    kind = switch_of(spec)
    diode_override = project.diode_override(piece)     # 無い部品・キー番号は落とす
    n_stab = 0
    for i, ((kx, ky), k, (r, c)) in enumerate(zip(positions, keys, rc), start=1):
        sw = _load(KEYSWITCH_LIB, kind.footprint(k.w_u))
        sw.SetPosition(to_kicad(kx, ky))
        sw.SetReference(f"SW{i}")
        # Value は JLC の部品照合に使われる。キー名を入れると BOM から静かに漏れる（HHKB）
        sw.SetValue(kind.value)
        board.Add(sw)
        s = kind.stab_offset_for(k.w_u)
        if s is not None and s in kind.stab_fp:
            st = _load(KEYSWITCH_LIB, kind.stab_fp[s])
            st.SetPosition(to_kicad(kx, ky))
            if kind.stab_turn_front_row and stab_flipped(k, keys):
                st.SetOrientationDegrees(180)
            st.SetReference(f"ST{i}")
            board.Add(st)
            n_stab += 1
        # 組み立てる人が見るのは裏面。通し番号だけでは 60 個を取り違える
        t = pcbnew.PCB_TEXT(board)
        t.SetText(k.label)
        # 既定はキーの中心の 8.2 奥。機種が spec.KEY_LABEL_DY で変えられる（縁のねじの穴に字が掛かる機種）
        t.SetPosition(to_kicad(kx, ky + getattr(spec, "KEY_LABEL_DY", 8.2)))
        t.SetLayer(pcbnew.B_SilkS)
        t.SetMirrored(True)
        t.SetTextSize(pcbnew.VECTOR2I_MM(1.1, 1.1))
        t.SetTextThickness(pcbnew.FromMM(0.18))
        board.Add(t)
        # col2row: 列 → スイッチ → ダイオード（A→K）→ 行
        d = _load(paths.KICAD_FOOTPRINTS / f"{DIODE_FP[0]}.pretty", DIODE_FP[1])
        # 機種がキーごとに置き場所を変えられる（spec.DIODE_OVERRIDE。値は
        # Switch.diode_offset と同じ KiCad の向き・キー中心から (dx, dy, 角度)）。
        # CCKB ではスタビの逃げ穴がいつもの場所に重なる 4 キーだけ（O7）
        dx, dy, ang = diode_override.get(
            i, (kind.diode_offset[0], kind.diode_offset[1], kind.diode_angle))
        d.SetPosition(pcbnew.VECTOR2I_MM(ORIGIN[0] + kx + dx, ORIGIN[1] - ky + dy))
        d.SetOrientationDegrees(ang)
        d.SetReference(f"D{i}")
        d.SetValue("BAT46W")
        board.Add(d)
        if not kind.diode_front:
            d.Flip(d.GetPosition(), False)    # **Add の後で。**前だと segfault する
        # パッドは pinmap から引く。引けなければ落ちる（握り潰すとネットの無い
        # パッドが DRC 0 のまま残る。HHKB で 74LVC595 が丸ごと消えていた）
        # 同じ番号のパッドが 2 つある足跡（表面実装のタクトスイッチは端子が 2 つずつ中でつながる）は全部に張る
        for pin, name in (("1", f"COL{c}"), ("2", f"SW{i}_D")):
            pads = [q for q in sw.Pads() if q.GetNumber() == pinmap.resolve("keyswitch", pin)]
            if not pads:
                raise RuntimeError(f"SW{i}: パッド {pin} が足跡に無い")
            for q in pads:
                q.SetNet(net(name))
        d.FindPadByNumber(pinmap.resolve("diode", "A")).SetNet(net(f"SW{i}_D"))
        d.FindPadByNumber(pinmap.resolve("diode", "K")).SetNet(net(f"ROW{r}"))

    for i, (mx, my) in enumerate(spec.MOUNTS[piece]):
        h = _load(paths.KICAD_FOOTPRINTS / f"{MOUNT_FP[0]}.pretty", MOUNT_FP[1])
        h.SetPosition(to_kicad(mx, my))
        h.SetReference(f"H{i}")
        board.Add(h)

    extra = _extra(project)
    if extra is not None:
        extra.place(board, dict(piece=piece, net=net, to_kicad=to_kicad, load=_load,
                                keys=keys, positions=positions, size=(pcb_w, pcb_h)))

    # 左右・機種の識別。届いた 2 枚が見分けられないと組み立ても修理も誤る。
    # **他社の商標を刷らない**（HHKB は "SSKB" にした）
    label = pcbnew.PCB_TEXT(board)
    label.SetText(f"{spec.NAME} {piece.upper()}")
    # 既定は手前の縁から 3.0 の真ん中。機種が spec.PCB_LABEL_AT（CAD）で変えられる
    lx, ly = getattr(spec, "PCB_LABEL_AT", (0.0, -(pcb_h / 2 - 3.0)))
    label.SetPosition(to_kicad(lx, ly))
    label.SetLayer(pcbnew.B_SilkS)
    label.SetMirrored(True)
    label.SetTextSize(pcbnew.VECTOR2I_MM(2.5, 2.5))
    label.SetTextThickness(pcbnew.FromMM(0.3))
    board.Add(label)

    # シルクを JLC の最小線幅まで太らせる。**全部品を置いてから**（HHKB では
    # ダイオードより前にあり、61 個だけ 0.12 のまま残った。子基板の生成器には
    # 処理自体が無かった）
    silk = (pcbnew.F_SilkS, pcbnew.B_SilkS)
    for fp in board.GetFootprints():
        for it in fp.GraphicalItems():
            if it.GetLayer() not in silk:
                continue
            if isinstance(it, pcbnew.PCB_TEXT):       # 文字は線幅ではなく太さ（CCKB の XIAO の "USB"）
                it.SetTextThickness(max(it.GetTextThickness(), pcbnew.FromMM(JLC["silk_width"])))
            elif it.GetWidth() < pcbnew.FromMM(JLC["silk_width"]):
                it.SetWidth(pcbnew.FromMM(JLC["silk_width"]))
        for fld in (fp.Reference(), fp.Value()):
            if fld.GetLayer() in silk:
                fld.SetTextThickness(max(fld.GetTextThickness(), pcbnew.FromMM(JLC["silk_width"])))

    bad = npth_too_close_to_edge(board, pcb_w, pcb_h)
    if bad:                               # 黙って出さない。外形公差 ±0.2 で橋が折れる
        raise RuntimeError(f"{piece}: 穴が外形に近すぎる（要 {NPTH_EDGE_MIN}mm）:\n  "
                           + "\n  ".join(bad))

    out = project.root / "pcb" / "unrouted"
    out.mkdir(parents=True, exist_ok=True)
    path = out / f"{project.root.name}_{piece}.kicad_pcb"
    board.Save(str(path))
    sync_project_rules(path, getattr(spec, "DRC_SEVERITY", None),
                       pth_hole_clearance=getattr(spec, "DRC_PTH_HOLE_CLEARANCE", False),
                       tighten=getattr(spec, "DRC_RULES", None))
    return path, (pcb_w, pcb_h), len(keys), n_stab, len(nets)


def main(argv):
    p = load(argv[0])
    for piece in p.spec.PIECES:
        path, (w, h), n_sw, n_stab, n_net = build(p, piece)
        print(f"{piece:6s} 基板 {w:7.2f} x {h:6.2f}mm  スイッチ {n_sw} / ダイオード {n_sw}"
              f" / スタビ {n_stab} / 取付穴 {len(p.spec.MOUNTS[piece])} / ネット {n_net}")
        print(f"       {path}")
    return 0


if __name__ == "__main__":
    sys.exit(main(sys.argv[1:]))

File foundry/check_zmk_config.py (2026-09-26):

"""ZMK の設定を、ビルドに出す前にローカルで検査する。

実際のビルドは GitHub Actions 上で走るので手元では確認できないが、
**よくある失敗はファイルを読むだけで分かる**。往復 1 回あたり数分かかるので、
出す前に潰す。

検査する内容:
  - YAML が壊れていないか
  - build.yaml が参照するシールドが実在するか
  - Kconfig.shield の shields_list_contains 引数がディレクトリ名と一致するか
    （一致していないとビルド時に無言で無視される）
  - シールドに必要なファイルが揃っているか
  - ファイル名がシールド名と一致するか
  - west.yml の self.path が config になっているか
  - 各シールドのキーマップの全レイヤーが transform の map と同じ個数か

    .venv/bin/python3 -m foundry.check_zmk_config
"""

import re
import sys
from pathlib import Path

import yaml

from .paths import ROOT
SHIELDS = ROOT / "config" / "boards" / "shields"
WORKFLOW = ROOT / ".github" / "workflows" / "build.yml"

# ZMK が受け付けるボード名。Zephyr 4.1 以降は zmk バリアントが必須。
ZMK_VARIANT = "//zmk"

REQUIRED = ["Kconfig.shield", "{name}.overlay", "{name}.keymap"]

# XIAO nRF52840 のボード定義（zmkfirmware/zephyr v4.1.0+zmk-fixes の boards/seeed/xiao_ble）で**有効なまま**の周辺と、
# その pinctrl が掴む D ピン（seeed_xiao_connector.dtsi の D ピン ↔ P ピン・xiao_ble-pinctrl.dtsi。2026-09-26 に読んだ）。
# シールドがそのピンを GPIO に使うなら、その周辺が**ボードの dts か overlay のどちらかで**切れていること
# （切らないと眠るときの sleep の pinctrl が行のピンに当たりうる。CCKB の監査 A 軽微 1・2026-09-26）
XIAO_BUSY_PINS = {
    "xiao_i2c": (4, 5),       # i2c1: SDA P0.04 = D4・SCL P0.05 = D5
    "xiao_serial": (6, 7),    # uart0: TX P1.11 = D6・RX P1.12 = D7（2 回目の V2 監査 A-1。前は「ZMK が切る」と書いて見ていなかった）
}
# ZMK のボード xiao_ble//zmk の dts の写し（出典と commit は写しの冒頭）。&xiao_serial を切っているのはここ。
# **config/west.yml は ZMK の main を追う**ので、ZMK が上げたら取り直す（写しが古いと、切れていないのに通る）
XIAO_BOARD_DTS = Path(__file__).resolve().parent / "upstream" / "xiao_ble_zmk.dts"

# ZMK 本体に入っているシールド。ローカルにファイルが無いのが正しい。
# settings_reset は BLE のボンドを消す救援イメージ（build.yaml 参照）。
UPSTREAM_SHIELDS = {"settings_reset"}


def load_yaml(path, problems):
    try:
        return yaml.safe_load(path.read_text(encoding="utf-8"))
    except Exception as e:
        problems.append(f"{path.relative_to(ROOT)}: YAML が読めない ({e})")
        return None


def find_shield_dir(name):
    """<name>.overlay を持つディレクトリを探す。"""
    for d in SHIELDS.iterdir():
        if d.is_dir() and (d / f"{name}.overlay").exists():
            return d
    return None


def count_map_entries(path):
    """matrix-transform の map に並んだ RC(...) の数。

    左右で 1 つの transform を共有する書き方（ZMK 分割の標準）では、
    map は .dtsi 側にある。overlay だけを見ると 0 件になり、検査が
    素通りしてしまうので、呼び出し側で .dtsi も渡すこと。

    ⚠️ **コメントを落としてから数える。**map の中に説明のコメントを
    書き、そこに `RC(` の字が入っていると、その分だけ多く数える
    （2026-08-17 に実際に起きた。最下段の割り当てを直したとき、
    経緯を書いたコメントに旧値を引用していて **+3 になり、
    「バインディングが 3 個足りない」と嘘の赤が出た**）。
    `implied_positions` は最初からコメントを落としている——**同じ
    ファイルを読む 2 つの関数で扱いが違っていた。**
    """
    text = path.read_text(encoding="utf-8")
    text = re.sub(r"/\*.*?\*/", " ", text, flags=re.S)
    m = re.search(r"map\s*=\s*<(.*?)>\s*;", text, re.S)
    return len(re.findall(r"RC\s*\(", m.group(1))) if m else 0


def _count_gpio_entries(text, prop):
    """<...> が何個並んでいるかを数える。row-gpios などのピン本数。"""
    m = re.search(rf"\b{prop}\s*=?\s*(.*?);", text, re.S)
    return len(re.findall(r"<[^>]*>", m.group(1))) if m else 0


def implied_positions(files):
    """transform を書いていないときに ZMK が既定で作るキー位置の数。

    matrix なら 行 × 列、direct なら input-gpios の本数。
    ここを検査しないと、治具シールドのバインディング数の取り違えを
    見逃す（実際に proto 系で起きうる）。
    """
    text = "\n".join(f.read_text(encoding="utf-8") for f in files)
    text = re.sub(r"/\*.*?\*/", " ", text, flags=re.S)
    rows = _count_gpio_entries(text, "row-gpios")
    cols = _count_gpio_entries(text, "col-gpios")
    if rows and cols:
        return rows * cols
    return _count_gpio_entries(text, "input-gpios")


def count_bindings(keymap):
    """キーマップの各レイヤーのバインディング数を [(名前, 個数), ...] で返す。"""
    text = keymap.read_text(encoding="utf-8")
    text = re.sub(r"/\*.*?\*/", " ", text, flags=re.S)      # コメントを除く
    text = re.sub(r"//[^\n]*", " ", text)                    # 行コメントも（刻印に & があり得る）
    out = []
    for m in re.finditer(r"(\w+)\s*\{[^{}]*?bindings\s*=\s*<(.*?)>\s*;", text, re.S):
        out.append((m.group(1), len(re.findall(r"&\w+", m.group(2)))))
    return out


def _strip_comments(text):
    text = re.sub(r"/\*.*?\*/", " ", text, flags=re.S)
    return re.sub(r"//[^\n]*", " ", text)


def _disabled(periph, text):
    return re.search(rf"&{periph}\s*\{{[^{{}}]*status\s*=\s*\"disabled\"", text) is not None


def xiao_pin_conflicts(text, board_text=None):
    """overlay の文面から、GPIO に使った D ピンが、**ボードの dts（board_text。既定は XIAO_BOARD_DTS の写し）でも
    overlay でも**切っていない XIAO の周辺のピンと重なるもの。[(周辺, ピン)]。"""
    text = _strip_comments(text)
    board = _strip_comments(XIAO_BOARD_DTS.read_text(encoding="utf-8") if board_text is None else board_text)
    used = {int(n) for n in re.findall(r"&xiao_d\s+(\d+)\b", text)}
    out = []
    for periph, pins in XIAO_BUSY_PINS.items():
        if not (_disabled(periph, text) or _disabled(periph, board)):
            out += [(periph, p) for p in pins if p in used]
    return out
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

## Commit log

2026-09-23 HHKB 分割機から、キーボード開発の核・検査・知識を抜き出して作業場を作る
    - foundry/: KLE → プレート・未配線基板（KiCad・JLC 規則）・ZMK シールド。
    DRC・基板の絵・メッシュ/スライス・発注の門・fab_fields・mutate・JLCPCB 検索
    - tests/: HHKB の発注済み基板（e7a35cd）と突き合わせる再現検査（140 部品・244 パッド一致）、
    依存・定数・暫定値・ファームの配線・新機種の雛形の検査。85 passed / 1 skipped
    - firmware/: ZMK モジュールを FOUNDRY_* に改名（改名後は未ビルド）
    - docs/: 失敗から出た規則・部品と回路と基板と筐体と ZMK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
    [battery_alkaline.c, board_dump.py, boardhash.py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]
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2026-09-23 Task 2 修正 1: Choc V1 の座標検査を図の生値からの鏡像＋回転で導出する
    レビューで指摘された誤り: 「パターン側視点は上面視に対して 90° 回転」は
    誤りで、実際は鏡像＋90° 回転。tests/test_choc.py に図の生の Pattern
    Side 座標を記録し、_to_kicad()（X 反転→+90°回転→Y反転）で KiCad 座標
    へ変換して端子・中心穴・ボスをまとめて照合する。鏡像のまま（回転だけ
    で直した）偽フットプリントでも検査が落ちることを確認する自己検査を
    追加。lib/README.md の説明とライセンス表記も修正。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
2026-09-23 Task 2 修正 2: 座標変換の説明を精密にする（コード・数値は変更なし）
    X反転とY反転はそれぞれ単独では鏡映だが2回かけると打ち消し合って
    回転に戻る、という正確な理由づけに直した。+90°の理由も「図面上の
    視点どうしの違い」ではなく「実物がキーボード内で座る向き」に基づく
    ものだと明記し、根拠（シート上面視のキャップ軸受けスロットは縦並び
    だがChocのキャップポストは横並び。kiswitch/Keebioもボスを横に置く）
    を添えた。tests/test_choc.py と lib/README.md の文章のみの変更。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
2026-09-23 修正1: 角の桟の検査を PLATE_OPENINGS から独立させる
    test_the_web_around_the_corner_keys_survives が判定に spec.PLATE_OPENINGS を
    使っていたため、角の開口を広げる壊し方が自分の判定点を自分で免除していた。
    レイアウトから角のキーを導き、そのキー自身のセル内でプローブする形に直す。
2026-09-23 修正2: 角の桟の検査に段3の角にかぶるキー（Shift・Fn）の底辺プローブを足す
    最下段の角のキー（Alt）だけでなく、角の真上にかぶる段3のキー（左 Shift・
    右 Shift・Fn）の底辺（角に向く側）もプローブする。角を上に 1mm 広げる壊し方
    （高さ+2mm・中心+1mm、左右それぞれ）が落ちることを確認した。
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2026-09-23 修正: Choc スタビの開口を STAB_KERF（片側 0.15）広げる
    Keebio の輪郭は幅 6.30 がハウジング 6.30（+0.02/−0.05）そのもので隙間 0。
    刷った PLA の穴は締まるので、Cherry と同じ多角形オフセットで広げる
    （stab_cutout_face に polygon を足した）。CHOC_STAB_OUTLINE は出典の値のまま。
    検査: 輪郭の横の辺から 0.1mm 外が穴・0.25mm 外が板（4 キー×4 辺）。
    kerf 0 と 0.3 に壊して落ちることを確認。桟の検査は広げたあとで 1.80mm。
    角の桟の検査の死んだ枝を、プローブがスタビ開口の外という前提の assert に替えた。
    嵌め合いは Choc では未実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
    [mech.py]
2026-09-23 修正: スタビのキーのダイオード位置は逃げ穴が入るまでの暫定と書く
    Task 6 の DRC 0 は逃げ穴の無い基板でのもの。スタビのキー 4 つでは
    パッドが x 8.2・コートヤードが 8.75 まで来て、逃げ穴の始まる x 8.85 まで
    約 0.65mm しかない。open-gaps O7 に計画 3 でやり直すことと、列 0・列 14 の
    配線が逃げ穴を避ける必要があること（座標つき）を足した。
    [mech.py]
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2026-09-23 修正: 起動試験の手順書（打ち止めの決め方・D0 の分圧・誤記）
    - empty-millivolts: 新品＋直列抵抗では無負荷電圧がどの条件も 3.0〜3.2V で
    決まらない。10/10 だった最大の直列抵抗（寒さの倍率で割る）を内部抵抗の
    図で容量に、放電曲線で閉路電圧に直す手順に替えた（控えめ・あとで詰める）
    - 本番と同じ位置に分圧 1MΩ×2 → D0 を入れる。浮いていると low_battery_off が
    約 125 秒で止める。1MΩ は手持ち不明として部品に挙げ、電池の対照で
    「起動後 3 分待っても切れない」を見る手順を足した
    - 誤記: 実物で試し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
2026-09-23 CCKB: 基板・プレート・ケースの境界を凍結する（角・取付・電源スイッチ・スタビの逃げ・分割・高さ）
    - spec.py: 外形（壁 1.6・隙 0.5 → 289.95×99.45）・高さ（床 1.6・下の空き 1.8・基板 1.6・縁 +7.0）・
    XIAO（公式 STEP の実寸・表に平ら・USB の口は外面から 0.3）・電池ホルダ BS-16-B4AK003・
    電源スイッチ MK-12C02-G025（裏・右端）・スタビの逃げ（輪郭＋0.5）・取付 10（下から M2×6 皿＋
    基板上のナット）・支え 38・プレートの分割（キーの境目）・トレイの継ぎ目（案 C）
    - interface.py: 上の値から形を作る（図・探索・検査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
    [cckb_main.kicad_pcb]
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2026-09-23 CCKB: 回路をデータに（circuit.py）・部品のフットプリントと配置（pcb_extra.py）・行列の配線の計画・O7 の解決
    - circuit.py: 全部品と全ネットを名前で宣言。pinmap を通してパッドを引く（XIAO の BAT には何も繋がない）
    - lib: XIAO の表面実装（公式 STEP を測った）・MK-12C02-G025（LCSC のフットプリントを図面と照合）・
    BS-16-B4AK003（図面 MY-CP-0085）・ふたの柱の穴
    - pcb_extra.py: スタビの逃げ穴 8・XIAO/ホルダ（表）・電源スイッチと電子部品（裏）・アンテナの禁止域・
    XIAO の下の表の銅の禁止・縁と逃げ穴の配線禁止の帯・ネッ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
    [cckb_main.kicad_pcb]
2026-09-23 CCKB: 基板を配線して GND を塗り、発注に使う板 pcb/cckb_main.kicad_pcb を置く。板そのものの検査
    - tools/route_pcb.py: 行列と XIAO からの行を決まった形で → GND の SMD パッドにスタブ→ビア →
    残り（列→595・SPI・電源）を Freerouting 2.3.0 → SES 後に自分の線が残っているか数えて置き直す →
    両面 GND ベタ → リング・フェンス・格子・離島のビア → 塗り直し。記録 pcb/route.json
    （Freerouting の余裕は 30/35/25/40µm を順に試し、ログの未配線 0 の最初を採る）
    - DRC: 違反 0・未配線 0・警告 5（silk_edge_clearance 3・npth_inside_courtyard 2＝理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
    [cckb_main.kicad_pcb]
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2026-09-23 CCKB 監査の直し（R1〜R6）: パッドの中のビアを根本から無くし、XIAO の裏の露出パッド 8 個と H3 のインサートの下の表の銅を 0 に、電源スイッチを手はんだに、トレイの隙を片側 0.5 に
    - R1: route_pcb.Space.free() が同じネットのパッドを当てていなかった（C_U1・BT1 の GND パッドの中に縫いのビア）。全パッドの「ビアが掛からない」検査（XIAO の D0〜D6 だけ名指しで例外）
    - R2: SW_PWR を NOT_ASSEMBLED に（BOM 5 行・CPL 69 行）。Fabrication Toolkit の CPL を EasyEDA の原点とパッドで置き直して板と比べる検査
    - R3: 露出パッド 8 個を STEP と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
    [cckb_main.kicad_pcb]
2026-09-23 CCKB 監査の直し（R4・R7 と文書）: ダイオードは替えず「USB を挿す前に電源スイッチを OFF」、決定記録・台帳・発注前の確認表・手順書・部品の監査を更新
    - 決定記録 decisions/2026-09-24-audit-fixes.md（R2 は JLC の公式の資料、R4 は 8 品番のデータシートの保証値）
    - open-gaps: 受け入れた差 A1〜A7・O11（595 の末端を D9 に戻すか・利用者の判断）・P11/P12・F1〜F4
    - 手順書: 電源スイッチの手はんだ・基板の外形を測る・パッド内ビアの付け方・足の玉・使い方（USB の前に OFF）
    - task-10a: USB 給電中の逆漏れを 1 回測る。low_battery_off.c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
2026-09-23 CCKB 2 回目の監査の直し（S1〜S3）: 金属が当たる 10 か所に禁止域、CS の 1 本だけ置き直し、D_PWR の既定を BAT46W に
    - S1: interface.metal_on_pcb が取付の穴 11 ごとに金属の当たる面を高さで判定（上面にナット 9・H3 のインサート、下面 0）。
    METAL_KEEPOUT を 10 か所に。route_pcb.py --reroute CS で前の板の配線を持ってきて、H5・H6 のナットの下の CS の 1 本だけを
    決まった形で置き直した（ほかの 89 網は線・ビアとも前の板と同じ）。検査は板から穴を数え、塗った後の銅まで見る
    - S2: 逆流を「逆漏れ − 分圧が吸う電流」・Vf を保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
    [cckb_main.kicad_pcb]
2026-09-23 CCKB 3 回目の監査の軽微を直す（1・2・4）: 替えた品番 B5819W の残り、禁止域の報告の訂正、インサートの外径に [暫定]
    - 軽微 1: spec.py のコメント「B5819W の後ろ」→「D_PWR の後ろ」、interface.md に §S2 を指す注記
    - 軽微 2: audit-fixes.md §S3 の「禁止域の形は変わらない」を訂正（3 → 5 個・0.036 はみ出す・銅は同じ）
    - 軽微 4: case_spec.INSERT_OD に [暫定]、provisional-values-case.md に行（H3 の禁止域がこの値に乗る）
    - 軽微 3 は次のコミットで open-gaps A10 に記録
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2026-09-23 CCKB 最終レビューの直し（I1〜I6・軽微 M1〜M11）: 板の銅は不変
    I1 規則の値を写さず pcb_rules から導く（matrix_routes・interface・pcb_extra・route_pcb の
    DETOUR_CLEAR）。導いた値は元の値とビット単位で同じ（計画 387 本・逃げ・取付の判定も一致）。
    写しを見つける検査（test_meta）と、pcb_rules を変えると機種の値がついてくる検査を足した
    I2 common_volume の形状演算の失敗を 0 と数えない（GeometryFailure。interference は failures に積む）
    I3 KiCad 側で読まれる機種のモジュール 8 つを 3.9 の文法・標準ライブラリだけの検査に入れ、
    r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
    [paths.py, pcb.py, pcb_rules.py]
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2026-09-24 CCKB 電源スイッチを秋月 SS-12D00G3（表・レバーが上）へ: 基板・ケース・組み立て・検査
    - 利用者の決定（2026-09-24）で MK-12C02-G025（LCSC・裏・横のつまみ）から置き換え
    - 基板: SW_PWR を表・スルーホールで (141.225, -38.6)、BT1 を左へ 3.8（124.7）。
    網 VBAT_IN・VBAT_SW の右の角だけ引き直し（ほかの 88 網は前の板と同じ）。
    枠の爪の下に表の銅の禁止域 PSW_TAB_KEEPOUT。位置決めの穴が無くなり DRC_SEVERITY を消した
    （DRC 違反 0・未配線 0・警告 3）。前のフットプリントと EasyEDA の C778186 を消した
    - route_pcb: --clear（動かした部品の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
    [cckb_main.kicad_pcb]
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2026-09-24 firmware 打ち止めの判定を毎回測ってから数える（CCKB 4 回目の監査 F 重要 1）
    ZMK はアイドル・スリープで電池の測定を止める（app/src/battery.c の battery_event_listener・
    main af96766）。low_battery_off.c はキャッシュを読むだけだったので、アイドル中は最後の
    1 回の測定を「2 回続けて」と数え、送信中の一時的な降下 1 回で soft off しえた。
    判定のたびに sensor_sample_fetch_chan で測る（ZMK の測定と同じ低優先の work queue）。
    検査: low_battery_off.c をホストの代役の Zephyr/ZMK（tests/fixtures/zmk_host）で cc で
    コンパイルして場面ごとに回す。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
    [battery_alkaline.c]
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2026-09-25 CCKB を Choc V2 に: 基板を作り直して配線（DRC 違反 0・未配線 0）・高さ・床の止まり穴の出力
    - spec: SWITCH=choc_v2・高さ 5.3/8.6・足の公差 0.2・中心の突起 3.30・床の止まり穴 0.4（UNDER_PCB 1.8 のまま）
    - 行のバスを 3.35 下に（中心穴と位置決めの長穴の間）。スタビ・取付の穴の所だけ下へ回り道（matrix_routes.buses）
    - 列が段の境目を渡る高さをずらせるように・XIAO から行 0〜2 は XIAO の下で左へ寄せてから上がる
    - VBAT_SW の長い 1 本を決まった形で（POWER_RUNS）・D_PWR を XIAO の奥の縁の上へ
    - 595 の OE を本体の下で GND の 8 番へ（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
    [cckb_main.kicad_pcb]
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2026-09-26 CCKB ファーム: 行 2・3（D4・D5）と重なる xiao_i2c を切る・check_zmk_config で見る
    XIAO nRF52840 のボード定義（zmkfirmware/zephyr v4.1.0+zmk-fixes）は i2c1（xiao_i2c）を
    有効なまま SDA P0.04 = D4・SCL P0.05 = D5 に割り当てている。CCKB は D4・D5 を行 2・3 に使う。
    眠るときに i2c1 の sleep の pinctrl が行のピンに当たると行のキーで起きられなくなりうる
    （2026-09-26 の V2 監査 A 軽微 1）。I2C は使わないので overlay で切る。
    check_zmk_config に「GPIO に使った D ピンが、ボードで有効なままの周辺のピンと重なる」を足し、
    tests/test_zmk.py で本物の overlay が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
    [check_zmk_config.py]
2026-09-26 CCKB V2 の位置決めの穴を丸 φ2.1 に（JLC の長円の比）・名札・床の穴: 板 6b886491（DRC 違反 0・未配線 0・警告 0）
    2026-09-26 の V2 監査 C 重要 1: 非めっきの長円 78 個が JLC の「長円の長さ ≧ 幅 × 2」を満たさない。
    - 位置決めの長円 62（1.6 × 2.0・比 1.25）を丸 φ2.1 に。足跡を SW_Kailh_Choc_V2_Slot → SW_Kailh_Choc_V2_Common。
    3 枚の図の推奨の穴（標準 φ1.60・静音 長円 2.0 × 1.5）の和を JLC の丸穴の公差 −0.08 でも含む。底面図の「5.50」は
    穴の中の突起と読み直した（静音 茶の図を 600dpi で）。突起は公差の最悪でも入る
    - スタビの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
    [cckb_main.kicad_pcb]
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2026-09-26 CCKB V2 スタビの穴を販売者の実測に（支点 ±11.9・丸 φ3.0 / φ4.0・半径 2.6 の禁止域）・プレート・キャップの受け口: 板 5f02d2b0（DRC 違反 0・未配線 0・警告 0）
    - 基板: ねじ φ3.0 を y −6.2・爪 φ4.0 を y +8.24（丸い非めっき）・箱の穴 支点 ±3.0 × ±4.0。穴の中心から 2.6 は GND のベタ以外の銅なし（STAB_HOLE_KEEPOUT）
    - 長円の例外 HELD_STAB_SLOTS を消した（板・ドリルのファイルとも長円 0）。発注する板を決めた数と比べる検査と壊す検査 7 通り
    - 配線: 行のバスは禁止域の下を回る（キー中心の 8.95 下）。左 Shift の左のねじの禁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
    [cckb_main.kicad_pcb]
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2026-09-26 CCKB V2 2 回目の監査の基板の直し: GND の縫いのビア 6・R_LO の名札・スタビの裏のコートヤード・穴と銅 0.28: 板 abcd20ff（DRC 違反 0・未配線 0・警告 0）
    - D-1: 裏の GND の帯（ROW4 と手前の縁の間）に 5 本。帯の先から最寄りの GND のビアまで銅の上の道のり 33.3 → 3.1
    - D-2: 表の島（左 Shift の左の箱の穴を VBAT_SW が U 字に囲む所）に 1 本。12.3 → 10.3。
    監査の勧めた左上は U の腕の幅 1.006 / 0.8 でビアが入らない（3 以下はビアでは届かない）
    - 宣言した GND のビア spec.GND_STITCH_AT を route_pcb が最後に打つ（置けなければ止まる）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
    [cckb_main.kicad_pcb]
2026-09-26 ZMK の検査: XIAO の xiao_serial（D6・D7）も見る。ボードの dts か overlay のどちらかで切れていること（2 回目の V2 監査 A-1）
    - XIAO_BUSY_PINS に xiao_serial（uart0 TX P1.11 = D6・RX P1.12 = D7。zmkfirmware/zephyr v4.1.0+zmk-fixes の
    seeed_xiao_connector.dtsi・xiao_ble-pinctrl.dtsi で確かめた）
    - ZMK の xiao_ble_zmk.dts を foundry/upstream/ に写した（main 9ebbeff0a8b6・出典を冒頭に）。ZMK を上げたら取り直す
    - 検査: 写しから切る行を消すと D6・D7 が見つかる。overlay で切れば通る
    [check_zmk_config.py]
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2026-10-03 cckb-click: 足跡と回路と配置（未配線の基板）
    基板 291.15 × 100.65・部品は全部表（JLC の片面実装）・裏はねじの頭だけ。
    - 足跡: スイッチ SW_Alps_SKRA_6.2x6.2（Alps の製品ページのランドの図 8.5 × 5.0・内内 3.0。販売者が JLC に実装させた基板の
    足跡と同じ。EVQQ2 と重ねたランドにはしない）・電池クリップ BAT_MY-1632-03-R（図面の ＋のランド。−は裸の銅 φ7・はんだを載せない）・
    電源スイッチ SW_MSK12C02（図面のランド・原点と向きは LCSC の足跡）・ねじの穴 Hole_M2_2.2
    - 核: mech.SKRA_TACT（ダイオードを表に置く diode_front）・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
    [cckb-click_main.kicad_pcb]
2026-10-03 cckb-click: 枠とキャップ・組み立ての立体・配線した基板（DRC 違反 0・未配線 0・警告 0）
    枠と基板は spec.py を共有するので 1 つのコミットにした。
    - 枠 2 枚（左 156.4・右 140.0）とキャップ 62 個（click_case.py）。基板の下から M2×4 を 20 本、枠の壁に直にねじ込む。
    電池は手前の壁の口から出し入れ・USB は左奥・電源スイッチは右の縁
    - 組み立ての立体で干渉（置く・押し切る・傾ける）・下から入れられるか・電池を出せるか・サポート無しで刷れるかを検査
    （tests/test_cckb_click_case.py。各検査に、故意に壊すと落ちる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
    [cckb-click_main.kicad_pcb]
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2026-10-03 foundry: 機種が DRC の下限を上げられる（下げられない）・ちょうど下限の穴を丸めで落とさない・載せないランドの種類
    - pcb_rules.sync_project_rules(tighten=…): spec.DRC_RULES で min_via_diameter などを上げる。JLC の下限より小さい値と、
    変えてよい鍵でない物は落とす（cckb-click の 1 回目の監査 C 軽微 5）
    - pcb.npth_too_close_to_edge: 穴の縁から外形までがちょうど 1.0 の穴を、浮動小数の丸め（1e-13）で落としていた
    - pinmap: cap_land（部品を載せないコンデンサのランド）
    HHKB の再現検査・CCKB の検査は緑（全検査 655 passed）。
    Co-Authored-B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
    [pcb.py, pcb_rules.py, pinmap.py]
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2026-10-05 cckb-click: 蓋の別案 B2 の記録（docs/coupon-cover-snap.md）: B から直した所の前 → 後・比べた手と捨てた理由（板・H15・片方ずつ・座り）・基板の変更の提案（クリップ BT1 を (122.0, −39.425) へ・H15 を (140.0, −48.225) へ・H30 と H31 を消す。動く物・外すビア 4 つ・変えた後に回し直すこと）・A／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
2026-10-05 cckb-click: 蓋の別案 B3 の記録（docs/coupon-cover-snap.md）: 見直しの 6 つを確かめた結果と直したこと・蓋 3 つ（案内の隙）ごとの「片方だけ」の正直な表（戻るのは隙 0.10 だけ）・爪で抜けない蓋は不合格・電池の出し方（見える量 0.94・本物のクリップの固さは試せない）・基板の提案に、ねじの頭の銅の逃げ・C_BAT との隙・電池の出し方を足した。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
2026-10-12 cckb-click: 蓋の別案 B4 の記録（docs/coupon-cover-snap.md）: 利用者が刷った結果・つまむだけで出てくるしくみと数（つまんで 0.8 → 離して 1.8〜2.0）・つまむ所の大きさ（幅 3 の面には届かない）・蓋 3 つ = かぎの掛かり・ベッドから剥がれた対策と、変えた設定 2 つ・弱くなった所（座りの力がほぼ無い・上面に見える物）・刷らないと分からない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
2026-10-12 cckb-click: 蓋の別案 B5 の記録（docs/coupon-cover-snap.md）: 利用者が B4 を刷った結果・B4 の計算の間違いと、直した計算での再現・斜めの面の引き直し・つまみの大きさ（5 × 3 には届かない）・ひずみの余裕・蓋 3 つ = きつさ（何が違って感じるはずか）・悪くなった所（つまみが重くなり、横向きの落下の余裕 0.90〜0.95 倍）・変えた設定 4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
